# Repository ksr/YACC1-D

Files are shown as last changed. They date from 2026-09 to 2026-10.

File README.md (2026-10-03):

# YACC1-D — the definitive YACC1 tree

**Status (2026-09-28):** the single source of truth for YACC1, on GitHub at `github.com/ksr/YACC1-D`, migrated from
the old `YACCS/` folders on 2026-09-19/20. What is in the machine today: `docs/system/MACHINE.md`; which board
revisions exist and were made: `hardware/FABRICATED.md`; what is open: `BACKLOG.md`.

**Who made it:** YACC1 is my project: I designed and built the hardware and wrote the original microcode, monitor,
Tiny BASIC and emulator. Claude, Anthropic's AI, has been directly involved in the design, coding and documentation
since 2026; the header at the top of every source file says who wrote it. — Ken Rother

**Working on it:** `CLAUDE.md` (the working notes for Claude sessions) has the standing rules, the machine facts that
bite, where things are and how to build and test. On a new Mac: clone, `python3 tools/setup_check.py` (which tools are
missing, and the command for each), `make` (the C tools), then `make check`.

## What YACC1 is

YACC1 ("Yet Another Custom CPU") is a hand-built 8-bit TTL computer: an 8-bit accumulator and TMP register, eight
16-bit registers R0-R7, microcoded, on a 96-pin bus. The cards: backplane, a two-board sequencer (logic + microcode
memory), ALU, two index-register cards, memory (RAM, the 8K ROM, TMP registers), I/O (16550 UART console, switches,
LEDs, TIL311s), a 6845 video card in bring-up, and a bus tester for driving the bus by hand.

Around the hardware, all in this tree:

- **Firmware in the machine:** the microcode (a C generator that writes the sequencer's EEPROM image), the monitor
  ROM with its Intel-hex loader, BIOS vectors and video driver, and a Tiny BASIC.
- **Y1/OS:** a disk operating system on CompactFlash (P8XFS), with a shell, redirection and pipes, and some thirty-five
  `/BIN` commands, most ported from P8X, among them `vi`, `sed`, `awk`, `pack` and `kermit`. It exists twice and is kept
  in step: `os/y1os.asm` (the real one) and `os/y1os.c` (its specification).
- **y1cc**, a C compiler for YACC1: a Python reference, a C twin, and nine passes that run under Y1/OS. Together with
  the on-target assembler `/BIN/ASM` they rebuild themselves byte for byte on the emulator (the self-host).
- **Host tools:** the RC/asm assembler, an instruction-level emulator, a microcode-level emulator that steps the real
  EEPROM image through models of the cards, loaders for the ROM monitor and the sequencer card, Kermit, the CF-card
  writer, and the KiCad board tooling.

Before this tree the work was spread over nine overlapping copies under `YACCS/` (Eagle variants, four git clones with
different histories, backups). YACC1-D keeps the *current* version of every board, program, tool, test and document in
one place, with everything superseded kept but frozen. `MIGRATION.md` and `migration/` record where every file came
from.

## The tree

```
YACC1-D/
├── README.md  CLAUDE.md  BACKLOG.md  MIGRATION.md
├── Makefile                  make (the C tools), make check (everything, ~11 min), os-test, cc-test, native-test, ...
├── docs/
│   ├── system/               MACHINE.md (what is built), architecture, memory map, microcode, OS plan
│   ├── isa/                  a timing diagram per instruction, the microcode review
│   ├── cards/                theory of operation, one per card
│   ├── programming/          assembler, monitor, OS, C compiler, emulators, memory map, I/O ports
│   ├── procedures/           bring-up, CF card, testing, Kermit
│   ├── bom/                  bills of material, one per card
│   ├── history/              dated design notes kept verbatim (2016-2021), presentations
│   ├── datasheets/           third-party PDFs the designs use
│   └── references/           external papers and books
├── hardware/
│   ├── bus/                  backplane, bus template, bus jumpers, blank card
│   ├── cards/<card>/         one folder per card (below)
│   ├── libraries/            eagle/: the Eagle .lbr/.dru files the designs use
│   ├── mechanical/           card divider clips, switch template, spacers
│   ├── FABRICATED.md         every revision of every board: built, in the machine, or design only
│   ├── SCHEMATICS.md BOARDS.md   generated indexes of the schematic and board PDFs
│   ├── KICAD.md              the Eagle -> KiCad conversion and its netlist proof
│   └── DESIGN-REVIEW*.md     the 2026-09-21 review of the datapath, control and I/O
├── firmware/                 code that runs INSIDE the machine
│   ├── microcode/            ucode-generator2 (C) -> test.hex, the sequencer EEPROM image
│   ├── monitor/  basic/      monitor.asm, basic.asm (+ candidates never burned)
│   ├── rom/                  shipped/ (the image to burn and what is burned), builds/, captured chips
│   └── abi/                  BIOS vectors, variable and port map (still to be written)
├── os/                       Y1/OS: y1os.asm + y1os.c, commands/ (C), commands-asm/ (asm.asm), lib_*.c,
│                             man/, docs/, Makefile -> os/disk.img
├── software/                 host-side toolchain (runs on the Mac)
│   ├── assembler/            RC/asm + yacc1.def
│   ├── emulator/             instruction-level emulator (the ISA reference)
│   ├── ucemu/                microcode-level emulator (test.hex through models of the cards, CF, video)
│   ├── compiler/             y1cc.py, c/ (y1cc.c and the passes cc1..cc9), lib/
│   ├── disassembler/         disasm2
│   └── ubasic-c/             the C uBASIC the assembly BASIC was ported from
├── embedded/                 Arduino sketches for the support cards, built against libraries/ only
│   ├── sequencer-card/       sequencer4 (the microcode loader in the machine), dumpram, deprecated/
│   ├── bus-tester/           bus-driver, bus-monitor, bus-test, led-switch-test
│   ├── clocker/              external single-step clock
│   ├── command-sender/       Processing host for bus-tester scripts (to be replaced by Python)
│   └── libraries/            vendored: YACC_Common_header.h (bus table), Adafruit_MCP23017 1.1.0
├── tools/                    host scripts: setup_check, verify_firmware/embedded, ucode_send, monload, cfcard,
│                             y1kermit, p8xfs, the KiCad/Eagle tooling, the tree audit
├── tests/                    os, compiler, native (self-host), asm, disasm, bench (the machine), monload, kermit,
│                             cfcard, video, sequencer, ucemu, memory, assembler, bus-tester-scripts
├── mk/                       shared make fragments
├── migration/                the 2026-09-19/20 migration's inventory, plan and logs
├── vm/                       manifests of VMs and legacy installers (the images live outside git)
├── media/                    photos of the boards
├── website/                  the project website: MkDocs over these docs (website/README.md), live at yacc1.cottageworker.com
└── archive/                  frozen, never edited: gen1-2015-2018 (the first YACC1), superseded-revisions,
                              eagle-projects, third-party, conflict-losers (older duplicates from the migration)
```

## Card folder layout (`hardware/cards/<card>/`)

```
<card>/
├── README.md        what the card is, current revision, what is built, open issues
├── kicad/<rev>/     KiCad 10 projects, GENERATED from the Eagle files by tools/eagle_to_kicad_all.py with a
│                    schematic-vs-board netlist proof (hardware/KICAD.md) - except where a MASTER marker says the
│                    KiCad project is hand-maintained and IS the design (memory v2.0, CF v1.0, video v1.1);
│                    those have a build.sh (route with Freerouting, DRC, gerbers, renders, BOM)
├── eagle/<rev>/     the Eagle originals, frozen; the active revision at the top, fab/ (what was sent to the board
│                    house), pdf/ (generated), bom/
│   └── deprecated/  every older revision, same shape
└── docs/            card-specific notes
```

| Card | In the machine | Designed, not built |
|---|---|---|
| backplane | V2.0 (8 slots) | |
| sequencer-logic | v2.1 | v2.2 "CPU off" switch (idea, BACKLOG) |
| sequencer-memory | V2.1 + EEPROM adaptor | |
| alu | V3.2 | |
| register (index registers) | 1.1, two cards (R0-R3, R4-R7) | |
| io | V1.1 | |
| memory | v1.3 | **v2.0**: v1.3 + the CompactFlash interface on P8/P9, finished for fabrication |
| video | V1.0, no 6845 fitted yet | **v1.1** (KiCad master), changes still to make before ordering |
| cf | | v1.0, a separate CF card, superseded by memory v2.0 |
| bus-tester | V1.1 (2016; a bench tool) | V3.1 (2020, never ordered) |
| mem-switch, mem-register | bring-up cards (switch ROM at $0000, 16-byte RAM at $0010), fitted when needed | |
| protocard, address-tmp | built (address-tmp retired) | |

Bus items live under `hardware/bus/`: backplane, bus-template V3.2, bus jumpers (built, obsolete, not fitted), blank
card V3.1 (built) and V3.2 (the template for new cards).

## Conventions

- One authoritative copy of anything. Duplicates were the whole problem.
- Lower-case, hyphenated directory names; no spaces (the Eagle tree's spaces broke scripts repeatedly).
- Binary images (ROM, microcode hex) are committed **with** their source and a script that rebuilds them and
  diffs against the committed file; `make check` does it for all of them.
- Every file is explained: `tools/audit_tree.py` must report 0 unexplained after every commit.
- Files that came from YACCS are edited only with a dated entry in `tools/patched_files.txt`.
- Third-party code and libraries are vendored under a folder that says so, with their licence.
- Anything under `archive/` or `deprecated/` is never edited.
- Every `.rtf` note has a generated Markdown twin beside it (`tools/rtf_to_md.py`).
- No git LFS. Very large binaries (the 142 MB presentation, installers, VM images) live outside git, listed in `vm/`.

## How the migration was settled

- Repo: `~/Developer/YACC1-D` on both Macs (out of iCloud Drive, which corrupts `.git`), on GitHub, no LFS.
- History: started fresh (the first commit is the migration); the old `ksr/YACC1-2020` repo is not grafted in.
- `archive/` is committed (about 186 MB), and so are the datasheets.
- Older board revisions that were built stay with their card under `eagle/deprecated/`;
  `archive/superseded-revisions/` holds designs never built and the old tree's snapshots.
- Monitor and BASIC: the 2026 builds in `firmware/rom/shipped` are current; the 2021 `8afde21` build (ON/OFF, break-in)
  is kept as a candidate, never burned.
- Build environment: every C tool has a plain Makefile (2026-09-20); the NetBeans `nbproject/` folders are kept but
  no longer needed.

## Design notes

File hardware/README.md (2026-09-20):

# hardware

Board designs. KiCad is current; Eagle is deprecated but kept per revision.

_Contents migrated 2026-09-19; MIGRATION.md at the repo root says which copy each item came from._

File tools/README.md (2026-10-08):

# tools

Host scripts: busdrv.py (bus-tester client), alias_min.py, ROM capture/compare, inventory.py, the migration and audit tools,
the PDF generators, and the KiCad conversion:

- `eagle_to_kicad_all.py` — converts EVERY Eagle design under hardware/ into `<item>/kicad/<rev>/` KiCad 10 projects and
  writes `hardware/KICAD.md`; per design it runs the three tools in `kicad/` (`eagle_sch_to_kicad.py` schematic converter,
  `finish_board.py` board finisher on KiCad's Eagle board import, `compare_netlists.py` schematic-vs-board proof), then ERC,
  DRC, a schematic PDF and board renders into `reports/`. `kicad/project-template.kicad_pro` carries the OSH Park rules.
- `kicad/sch_overlaps.py` — readability check for any `.kicad_sch` (or a folder of them): text over text, text over a
  symbol body, text crossed by a wire/pin/graphic line, and anything off the drawing frame or on the title block, with
  the worst offenders per sheet (`--summary`, `--detail N`, `--pairs N`, `--json`; `--calibrate SVG` checks its text
  boxes against a `kicad-cli sch export svg` render). `eagle_to_kicad_all.py` puts its counts in each README and in
  `hardware/KICAD.md`.
- `verify_fab_vs_brd.py` — proves an Eagle `.brd` is the design a fab house received: every hole against the Excellon
  drill file, every Top/Bottom track against the copper gerbers, inner-layer planes, part list and pick-and-place,
  optionally byte-compares two gerber sets. Takes a gerber zip or a whole order archive (nested zips are searched).
  First used 2026-09-24 on the memory card (`hardware/cards/memory/eagle/v1.3/README.md`).
- `verify_processing.py` — builds the Processing command sender with the Processing 4 CLI and re-compiles it with warnings on.
- `gen_y1_optab.py` — generates the instruction tables of the native assemblers from `software/assembler/yacc1.def`:
  `os/asm_optab.c` for `/BIN/ASMC` (asm.c, 2026-09-25) and `os/commands-asm/asmtab.inc` for `/BIN/ASM` (asm.asm,
  2026-09-26) (`os/Makefile` runs it, `--check` fails when either is stale: `tests/asm/run.py`). It compiles each `.def` construction line with a copy of RC/asm's `Translate()`.
- `y1term.py` — a terminal for the console that can also type a text file into BASIC (2026-10-08): the plain
  terminal (`python3 tools/y1term.py`, Ctrl-] for the menu: `s` send a file, `n` NEW first, `q` quit), or
  `--send PROG.BAS [--new] [--run] [--stay]` from the command line. Each line is typed at the machine's pace
  (`--delay`, 5 ms a character) and the next one waits for BASIC's `>>`; lines answered with SYNTAX ERROR or UNKNOWN
  COMMAND are reported with their line number in the file. Blank lines and `#` lines are skipped, tabs become spaces,
  lines over 200 characters are refused (BASIC's input line is unchecked). At the monitor's `>` it starts BASIC
  with `I` first. `--log FILE` keeps everything the machine sends. Finds the console FTDI as `monload.py` does.
  Tested by `tests/y1term/run.py` against the microcode emulator through a pty.
- `y1kermit.py` — a small standard Kermit for the Mac side of the console line (2026-09-26): `send FILE...` to
  `/BIN/KERMIT`'s `kermit -r` (or its `-x` server), `receive [DIR]` from `kermit -s`, `get NAME... [DIR]`, `finish` /
  `bye` for the server, `term` (a plain terminal, Ctrl-] quits). The same protocol subset as `/BIN/KERMIT`: short
  packets, window 1, block checks 1-3 (`--check`, 3 by default), control prefixing, repeat counts (`--norpt`),
  8th-bit prefixing only when asked (`--ebq` asks), attribute packets (`--noattr`), text mode (`--text`: LF as CR
  LF). `--port` (default: the one USB serial port that is not the sequencer's FTDI; the port is opened with
  `monload.py`'s `Link`, pyserial), `--baud 38400`, `--maxl` (94), `--time` (the timeout it asks the other side to use,
  10 s), `--timeout` (its own, 20 s), `-q`. Fault injection for the tests: `--corrupt N`, `--drop N`, `--nak N`,
  `--mute N` (the Nth packet of the run damaged, not sent, NAKed, not answered). It prints what it sent and received
  and a summary (packets, retries, NAKs, timeouts, repeats); exit 1 on failure. The fallback when C-Kermit is not at
  hand, and what `tests/kermit/run.py` drives both emulators with; `docs/procedures/KERMIT.md` is the how-to.
- `y1.ksc` — C-Kermit's settings for the same line (`kermit tools/y1.ksc` opens `/dev/cu.usbserial-AB0MVHSQ` at
  38400, no flow control, carrier-watch off, binary, prefixing all, autodownload, and connects;
  `docs/procedures/KERMIT.md` explains each).

_Contents migrated 2026-09-19; MIGRATION.md at the repo root says which copy each item came from._

## Already here (written during the 2026-09 bring-up session; they existed nowhere else)

- `author_headers.py` + `authors.tsv` — the authorship header at the top of every source file (2026-10-02):
  `authors.tsv` = each file's author category (Ken / Ken + Claude's logged changes / Claude / Claude's P8X ports / RC/asm
  with Ken's port / third-party and generated: no header) and why; `--check` (in `make check`) fails on a missing or
  stale header or a source file not in the table, `--apply` writes them, `--classify` adds new files to the table.
- `setup_check.py` — is this Mac set up for YACC1-D? Reports the tools each kind of work needs (core build/tests,
  board design, Arduino sketches, the machine's USB-serial ports, C-Kermit) and how to get what is missing; installs
  nothing (2026-09-27, for the second Mac; see ../CLAUDE.md "Two Macs")
- `busdrv.py` — Python client for the Bus Test Card (19200 baud, `CMD:OPERAND#`); readmem/writemem/dump helpers
- `alias_min.py` — minimal reproduction of the video card block-0/9 write-through fault
- `inventory.py` — hashes every file under YACCS and reports what is unique where (used to build MIGRATION.md)

`../firmware/rom/eprom-captured-2026-09-18.{bin,hex}` is the 8K image read out of the memory card's
28C64 through the bus tester; it is byte-identical to `Software-vs/Assembler/rom` (git ff7d85a).

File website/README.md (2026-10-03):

# website/ — the YACC1 project website

The project website is built from this repository's own documents with [MkDocs](https://www.mkdocs.org/) and the
[Material](https://squidfunk.github.io/mkdocs-material/) theme. The documents stay where they are; the site is
a readable view of them, with navigation and search.

| File | What |
|---|---|
| `home.md` | the visitor home page (the site's index) |
| `stage.py` | copies the documents the site uses into `stage/`, keeping their repository paths so the links between them work, and generates the extra pages |
| `hooks.py` | MkDocs hook: a link to a repository file that is not part of the site becomes a link to that file on GitHub (branch `main`) |
| `mkdocs.yml` | the site: navigation, theme, Markdown extensions |
| `mkdocs-publish.yml` | `mkdocs.yml` + the Google Analytics tag (G-X7P96DTCNE); only the published build carries it |
| `requirements.txt` | the Python packages, pinned |
| `build.sh` | stage + build (installs the packages into `venv/` on the first run, which needs the network) |

    website/build.sh            build into website/site/
    website/build.sh serve      ... and serve it at http://127.0.0.1:8765 (Ctrl-C stops it)
    website/build.sh publish    the build to publish (with Google Analytics)

`venv/`, `stage/` and `site/` are rebuilt each time and not committed. Previews leave the analytics tag out, so
looking at the site locally is not counted as a visit.

**Publishing.** `.github/workflows/website.yml` runs on every push to `main` (or by hand: Actions -> website -> Run
workflow): it builds `website/build.sh publish` on GitHub's machine, so every push proves the site builds. It deploys
to GitHub Pages only when the repository variable `PAGES_DEPLOY` is `true` (Settings -> Secrets and variables ->
Actions -> Variables) and Pages is on (Settings -> Pages -> Source: GitHub Actions); until then nothing is published.
The address will be `https://yacc1.cottageworker.com` (a CNAME record at the domain's DNS host, Gandi, and the custom domain in
Settings -> Pages); `site_url` in `mkdocs-publish.yml` already names it.

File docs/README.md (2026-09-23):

# docs

Start with `system/ARCHITECTURE.md`; `DOC-PLAN.md` says how the 2026-09-23 documents were written and what **To verify:** means in them.

| Folder | Contents |
|---|---|
| `isa/` | GENERATED timing diagram per opcode from the microcode (`make isa`, `tools/ucode_wavedrom.py`): control levels per step + bus behaviour from an assumed LS timing model; index in its README |
| `system/` | **`ARCHITECTURE.md`, `MICROCODE.md`, `BUS.md`** (2026-09-23: the machine, the control store, the backplane), `MACHINE.md` (what is fitted), `OS-PLAN.md`, the bus connector specs (`connector/`), the opcode table PDF (2023-11), index-register timing diagrams (`waveforms/`) |
| `cards/` | one theory-of-operation per card (2026-09-23): purpose, bus signals, IC-by-IC schematic walkthrough, timing and review findings, jumpers, bring-up, history; index in its README |
| `programming/` | the programmer's guides (2026-09-23): ISA reference, assembler, C compiler, monitor/BIOS, Y1/OS, memory map, I/O ports, emulators, tool chain |
| `bom/` | GENERATED bills of material per board and consolidated (`make bom`, `tools/gen_bom.py`) |
| `procedures/` | `BRING-UP.md` (the bench book, 2026-09-23), `TESTING.md` (every test and what it proves), bus tester command reference (PDF), system build notes |
| `history/` | the 2021 repo front page and status, the PCB folder readme, 2017–2020 design notes, verbatim |
| `datasheets/` | third-party datasheets used by the designs (28 files, ~19 MB; committed as decided) |
| `references/` | external papers |
| `../media/` | photos of the built cards and the system |

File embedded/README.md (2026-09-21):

# embedded — Arduino / Processing code for the support cards

| Folder | Runs on | Current | Superseded (`deprecated/`) |
|---|---|---|---|
| `bus-tester/` | Bus Test Card v1.1 (ATmega328 + 4 MCP23017) | `bus-driver` (drive the bus, FTDI 19200 – the sketch `tools/busdrv.py` talks to), `bus-monitor` (listen), `bus-test`, `led-switch-test`; `bus-driver-mcp23x17-wip` = 2026-09-18 start of a port to the Adafruit MCP23X17 2.x API (2 lines) | – |
| `command-sender/` | Mac (Processing) | `command_sender_8` (2020-08-16): GUI that sends test scripts to the bus tester; scripts in `tests/bus-tester-scripts/` | `command_sender_5..7`, `old/command_sender..4` (2016-12 → 2020-07), one 2016 ideas note |
| `sequencer-card/` | Sequencer-Memory card ATmega328 | `sequencer4` (2026-09-21: 400 kHz I2C, block EEPROM reads, verified copy) = the firmware in the card; `deprecated/sequencer3` (2021-08-25 + IO.ino 2024-07-10) = what it ran before; `microcode-loader/simple_microcode_sender_64` (Processing, 115200, reads `firmware/microcode/.../test.hexz`, keeps `cache`); `dumpram`; `test-eeprom` | `sequencer1` (2020-08), `sequencer2` (2020-12), senders 1 and 2 (19200, v1 generator), the Sept-2020 EEPROM test |
| `clocker/` | a spare Arduino | `clocker.ino` – external single-step / slow clock | – |
| `libraries/` | – | VENDORED: `Adafruit_MCP23017_Arduino_Library` 1.1.0 (the 1.x API every sketch here uses), `extEEPROM` 3.4.1 (the deprecated sequencer2 only) and `YACC/YACC_Common_header.h` (the bus signal table the tester sketches include; `-pre3-2.h` = its previous version). Install both in `~/Documents/Arduino/libraries/` | – |

Build check: `tools/verify_embedded.py` compiles every sketch here with arduino-cli (Uno / ATmega328) against ONLY the
vendored `libraries/`; 12 sketches, all compile with zero sketch warnings (`--warnings all`) as of 2026-09-20 except the MCP23X17 work-in-progress, which is expected
(it needs the 2.x Adafruit library). The Processing host in `command-sender/` is checked the same way by
`tools/verify_processing.py` (Processing 4 CLI build + Eclipse-compiler warnings). Manual build: copy `libraries/*` into `~/Documents/Arduino/libraries/` and use the IDE. The sequencer sketches carry their own copy of the signal subset
(`YACC_Common_headera.h`, per generation) beside the .ino.

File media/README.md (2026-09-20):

# media

Photos of the built cards (top / solder side) and of the assembled system, 2020–2021: ALU V3.2, bus V1.0/V1.1, Index
Registers 1.1, IO 1.1, Memory v1.2, Sequencer Logic 2.1, Sequencer Memory 2.1, test board (bus tester) v1.1, `system1`,
`double bus`. Videos of the machine running are on YouTube, not in the tree.

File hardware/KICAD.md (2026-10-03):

# KiCad conversions

Generated 2026-09-23 by `tools/eagle_to_kicad_all.py`: every Eagle design under `hardware/` (active and deprecated revisions) converted to a KiCad 10 project in the matching `kicad/<rev>/` folder. The Eagle files remain the record of what was built; these projects are derived and regenerated from scratch by the tool. **Proof** = the schematic netlist extracted by KiCad compared pad-for-pad with the netlist embedded in the imported Eagle board (`tools/kicad/compare_netlists.py`). Each project's README has the details and the residual ERC/DRC counts.

**Overlaps** = `tools/kicad/sch_overlaps.py` over all sheets: text/text + text/body + text/line collisions, and items off the drawing frame.

| Eagle design | KiCad project | Built | Proof | ERC | DRC | Overlaps | Off frame | Status |
|---|---|---|---|---|---|---|---|---|
| `bus/backplane/eagle/deprecated/v1.1/yacc2buss` | [`backplane-v1.1`](bus/backplane/kicad/deprecated/v1.1/) | yes | MATCH (87/87 nets) | - | 22 + 0 unconnected | 500 | 0 | ok |
| `bus/backplane/eagle/v2.0/yacc2buss` | [`backplane-v2.0`](bus/backplane/kicad/v2.0/) | yes | MATCH (87/87 nets) | - | 123 + 0 unconnected | 575 | 0 | ok |
| `bus/blank-card/eagle/v3.1/Blank V3.1` | [`blank-card-v3.1`](bus/blank-card/kicad/v3.1/) | yes | MATCH (3/3 nets) | 84 | 9 + 0 unconnected | 0 | 0 | ok |
| `bus/blank-card/eagle/v3.2/Blank V3.2` | [`blank-card-v3.2`](bus/blank-card/kicad/v3.2/) | no | MATCH (3/3 nets) | 84 | 9 + 0 unconnected | 0 | 0 | ok |
| `bus/bus-jumper-horizontal/eagle/deprecated/v3.0/Jumper Board V3.0` | [`bus-jumper-horizontal-v3.0`](bus/bus-jumper-horizontal/kicad/deprecated/v3.0/) | yes | MATCH (89/89 nets) | - | 28 + 0 unconnected | 0 | 0 | ok |
| `bus/bus-jumper-horizontal/eagle/v3.2/Jumper Board Horizontal V3.1` | [`bus-jumper-horizontal-v3.2`](bus/bus-jumper-horizontal/kicad/v3.2/) | yes | MATCH (89/89 nets) | - | 29 + 1 unconnected | 0 | 0 | ok |
| `bus/bus-jumper-vertical/eagle/v3.0/Jumper Board V3.0` | [`bus-jumper-vertical-v3.0`](bus/bus-jumper-vertical/kicad/v3.0/) | yes | MATCH (89/89 nets) | - | 10 + 0 unconnected | 0 | 0 | ok |
| `bus/bus-template/eagle/v3.2/Bus Template V3.2` | [`bus-template-v3.2`](bus/bus-template/kicad/v3.2/) | no | n/a (schematic only) | 182 | - | 0 | 0 | ok |
| `cards/address-tmp/eagle/deprecated/v1.0/Address and TMP V1.0` | [`address-tmp-v1.0`](cards/address-tmp/kicad/deprecated/v1.0/) | yes | MATCH (47/47 nets) | 74 | 208 + 0 unconnected | 36 | 0 | ok |
| `cards/alu/eagle/deprecated/v3.0-2layer/alu4` | [`alu-v3.0-2layer`](cards/alu/kicad/deprecated/v3.0-2layer/) | yes | MATCH (158/158 nets) | 203 | 407 + 0 unconnected | 87 | 0 | ok |
| `cards/alu/eagle/deprecated/v3.1/ALU V3.1` | [`alu-v3.1`](cards/alu/kicad/deprecated/v3.1/) | yes | MATCH (159/159 nets) | 203 | 697 + 0 unconnected | 90 | 0 | ok |
| `cards/alu/eagle/deprecated/v3.1-buried-vias/ALU V3.1` | [`alu-v3.1-buried-vias`](cards/alu/kicad/deprecated/v3.1-buried-vias/) | yes | MATCH (159/159 nets) | 203 | 697 + 0 unconnected | 90 | 0 | ok |
| `cards/alu/eagle/deprecated/v3.1-resubmit/ALU V3.1` | [`alu-v3.1-resubmit`](cards/alu/kicad/deprecated/v3.1-resubmit/) | yes | MATCH (159/159 nets) | 203 | 608 + 0 unconnected | 90 | 0 | ok |
| `cards/alu/eagle/v3.2/ALU V3.2` | [`alu-v3.2`](cards/alu/kicad/v3.2/) | yes | MATCH (162/162 nets) | 206 | 606 + 0 unconnected | 84 | 0 | ok |
| `cards/bus-tester/eagle/v1.1/tester` | [`bus-tester-v1.1`](cards/bus-tester/kicad/v1.1/) | yes | MATCH (149/149 nets) | 32 | 250 + 0 unconnected | 78 | 0 | ok |
| `cards/bus-tester/eagle/v3.1/tester` | [`bus-tester-v3.1`](cards/bus-tester/kicad/v3.1/) | no | MATCH (239/239 nets) | 123 | 494 + 0 unconnected | 96 | 0 | ok |
| `cards/io/eagle/deprecated/v1.0/IO V1.0` | [`io-v1.0`](cards/io/kicad/deprecated/v1.0/) | yes | MATCH (101/101 nets) | 130 | 359 + 0 unconnected | 94 | 0 | ok |
| `cards/io/eagle/v1.1/IO V1.1` | [`io-v1.1`](cards/io/kicad/v1.1/) | yes | MATCH (104/104 nets) | 130 | 292 + 0 unconnected | 92 | 0 | ok |
| `cards/mem-register/eagle/v1.0/Mem Register V1.0` | [`mem-register-v1.0`](cards/mem-register/kicad/v1.0/) | yes | MATCH (107/107 nets) | 179 | 299 + 0 unconnected | 171 | 0 | ok |
| `cards/mem-switch/eagle/deprecated/v1.0/Mem Switch V1.0` | [`mem-switch-v1.0`](cards/mem-switch/kicad/deprecated/v1.0/) | yes | MATCH (175/175 nets) | 98 | 209 + 0 unconnected | 20 | 0 | ok |
| `cards/mem-switch/eagle/v1.1/Mem Switch V1.1` | [`mem-switch-v1.1`](cards/mem-switch/kicad/v1.1/) | yes | MATCH (199/199 nets) | 99 | 279 + 0 unconnected | 72 | 0 | ok |
| `cards/memory/eagle/deprecated/v1.0/Memory V1.0` | [`memory-v1.0`](cards/memory/kicad/deprecated/v1.0/) | yes | MATCH (69/69 nets) | 102 | 208 + 0 unconnected | 38 | 0 | ok |
| `cards/memory/eagle/deprecated/v1.1/Memory V1.0` | [`memory-v1.1`](cards/memory/kicad/deprecated/v1.1/) | yes | MATCH (75/75 nets) | 102 | 208 + 0 unconnected | 38 | 0 | ok |
| `cards/memory/eagle/deprecated/v1.2/Memory V1.2` | [`memory-v1.2`](cards/memory/kicad/deprecated/v1.2/) | yes | MATCH (99/99 nets) | 111 | 208 + 0 unconnected | 93 | 0 | ok |
| `cards/memory/eagle/deprecated/v1.3-do-not-use/Memory V1.3` | [`memory-v1.3-do-not-use`](cards/memory/kicad/deprecated/v1.3-do-not-use/) | no | MATCH (115/115 nets) | 103 | 250 + 100 unconnected | 95 | 0 | ok |
| `cards/memory/eagle/v1.3/Memory V1.3` | [`memory-v1.3`](cards/memory/kicad/v1.3/) | yes | MATCH (116/116 nets) | 104 | 254 + 0 unconnected | 98 | 0 | ok |
| `cards/protocard/eagle/v1.0/ProtoCard-Prod-V1.0` | [`protocard-v1.0`](cards/protocard/kicad/v1.0/) | yes | MATCH (87/87 nets) | - | 268 + 0 unconnected | 21 | 0 | ok |
| `cards/register/eagle/deprecated/v1.0/Index Registers - 1.0` | [`register-v1.0`](cards/register/kicad/deprecated/v1.0/) | yes | MATCH (192/192 nets) | 163 | 212 + 0 unconnected | 110 | 0 | ok |
| `cards/register/eagle/deprecated/v1.0-no-address/Index Registers - 1.0` | [`register-v1.0-no-address`](cards/register/kicad/deprecated/v1.0-no-address/) | yes | MATCH (192/192 nets) | 163 | 212 + 0 unconnected | 110 | 0 | ok |
| `cards/register/eagle/v1.1/Index Registers - 1.1` | [`register-v1.1`](cards/register/kicad/v1.1/) | yes | MATCH (223/223 nets) | 169 | 440 + 0 unconnected | 46 | 0 | ok |
| `cards/sequencer-logic/eagle/deprecated/v2.0/Sequencer-Logic-Prod-V2.0` | [`sequencer-logic-v2.0`](cards/sequencer-logic/kicad/deprecated/v2.0/) | yes | MATCH (274/274 nets) | 128 | 720 + 0 unconnected | 78 | 0 | ok |
| `cards/sequencer-logic/eagle/v2.1/Sequencer-Logic-Prod-V2.1l` | [`sequencer-logic-v2.1`](cards/sequencer-logic/kicad/v2.1/) | yes | MATCH (282/282 nets) | 121 | 712 + 0 unconnected | 86 | 0 | ok |
| `cards/sequencer-logic/eagle/v2.1/orig size/Sequencer-Logic-Prod-V2.1` | [`sequencer-logic-v2.1-orig-size-sequencer-logic-prod-v2.1`](cards/sequencer-logic/kicad/v2.1/orig-size/sequencer-logic-prod-v2.1/) | no | MATCH (282/282 nets) | 121 | 772 + 4 unconnected | 86 | 0 | ok |
| `cards/sequencer-logic/eagle/v2.1/orig size/Sequencer-Logic-Prod-V2.1 copy` | [`sequencer-logic-v2.1-orig-size-sequencer-logic-prod-v2.1-copy`](cards/sequencer-logic/kicad/v2.1/orig-size/sequencer-logic-prod-v2.1-copy/) | no | n/a (schematic only) | 358 | - | 88 | 0 | ok |
| `cards/sequencer-memory/accessories/eeprom-adaptor/eeprom adaptor` | [`sequencer-memory-eeprom-adaptor`](cards/sequencer-memory/accessories/eeprom-adaptor/kicad/) | yes | MATCH (5/5 nets) | 3 | 16 + 0 unconnected | 0 | 0 | ok |
| `cards/sequencer-memory/eagle/deprecated/v2.0/Sequencer-Memory-V2.0` | [`sequencer-memory-v2.0`](cards/sequencer-memory/kicad/deprecated/v2.0/) | yes | MATCH (105/105 nets) | 13 | 497 + 0 unconnected | 30 | 0 | ok |
| `cards/sequencer-memory/eagle/v2.1/Sequencer-Memory-V2.1` | [`sequencer-memory-v2.1`](cards/sequencer-memory/kicad/v2.1/) | yes | MATCH (106/106 nets) | 11 | 461 + 0 unconnected | 28 | 0 | ok |
| `cards/video/eagle/v1.0-fusion-export-2026-09-18/Video_1.0` | [`video-v1.0-fusion-export-2026-09-18`](cards/video/kicad/v1.0-fusion-export-2026-09-18/) | yes | MISMATCH (115/117 nets) | 122 | 229 + 0 unconnected | 25 | 0 | ok |

**Label styles in the converted schematics** (reviewed 2026-09-23 and kept): a boxed global label marks a net the card also uses on another sheet (only global labels connect across KiCad sheets); plain text on a wire marks a net that appears on that sheet only, e.g. a bus signal the card does not use, drawn from the connector pin to the bus. Eagle drew both the same way, since its labels connect across sheets by name.

## Hand-maintained masters (not generated; `MASTER` marker file)

- [`cards/cf/kicad/v1.0`](cards/cf/kicad/v1.0/) — see its README (not ordered; its circuit is the CF section of `cards/memory/kicad/v2.0`)
- [`cards/memory/kicad/v2.0`](cards/memory/kicad/v2.0/) — see its README (the built memory v1.3 + the CF interface on P8/P9; schematic proven; whole card re-laid (2026-09-24); **the v2.0 board `memory-v2.0.kicad_pcb` = standoff option E (chosen 2026-09-25): the HX-2118P CF adapter on two 15 mm M3 standoffs (H1/H2, 3.2 mm NPTH) over the CF chips, J2 parallel to X1, a short ribbon; routed 0 unrouted / 69 through vias, DRC 0 copper violations / 0 unconnected, netlist proof MATCH, silkscreen tidied, fab files (gerbers + NPTH/PTH drill zip, renders, placement PDF, BOM with hardware, JLCPCB note, 1:1 print); NOT ORDERED**; records: the standoff options A-E, the top-edge board in `options-top-edge-J2/`, the keep-copper options; C20-C23 removed: 70 parts)
- [`cards/video/kicad/v1.1`](cards/video/kicad/v1.1/) — see its README

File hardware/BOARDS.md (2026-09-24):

# Board PDFs

Generated 2026-09-24 by `tools/brd_to_pdf.py` from every Eagle `.brd` under `hardware/` (active and deprecated), imported with KiCad's Eagle board reader and plotted one page per layer: F.Cu, inner layers (4-layer boards), B.Cu, F.SilkS, B.SilkS, each with the board outline. Bottom pages are NOT mirrored (viewed from the top, as in Eagle). Derived files: re-run after any `.brd` change.

| Board | PDF | Notes |
|---|---|---|
| `bus/backplane/eagle/deprecated/v1.1/yacc2buss.brd` | [`yacc2buss-board.pdf`](bus/backplane/eagle/deprecated/v1.1/pdf/yacc2buss-board.pdf) |  |
| `bus/backplane/eagle/v2.0/yacc2buss.brd` | [`yacc2buss-board.pdf`](bus/backplane/eagle/v2.0/pdf/yacc2buss-board.pdf) |  |
| `bus/blank-card/eagle/v3.1/Blank V3.1.brd` | [`Blank V3.1-board.pdf`](bus/blank-card/eagle/v3.1/pdf/Blank V3.1-board.pdf) |  |
| `bus/blank-card/eagle/v3.2/Blank V3.2.brd` | [`Blank V3.2-board.pdf`](bus/blank-card/eagle/v3.2/pdf/Blank V3.2-board.pdf) |  |
| `bus/bus-jumper-horizontal/eagle/deprecated/v3.0/Jumper Board V3.0.brd` | [`Jumper Board V3.0-board.pdf`](bus/bus-jumper-horizontal/eagle/deprecated/v3.0/pdf/Jumper Board V3.0-board.pdf) |  |
| `bus/bus-jumper-horizontal/eagle/v3.2/Jumper Board Horizontal V3.1.brd` | [`Jumper Board Horizontal V3.1-board.pdf`](bus/bus-jumper-horizontal/eagle/v3.2/pdf/Jumper Board Horizontal V3.1-board.pdf) |  |
| `bus/bus-jumper-vertical/eagle/v3.0/Jumper Board V3.0.brd` | [`Jumper Board V3.0-board.pdf`](bus/bus-jumper-vertical/eagle/v3.0/pdf/Jumper Board V3.0-board.pdf) |  |
| `cards/address-tmp/eagle/deprecated/v1.0/Address and TMP V1.0.brd` | [`Address and TMP V1.0-board.pdf`](cards/address-tmp/eagle/deprecated/v1.0/pdf/Address and TMP V1.0-board.pdf) |  |
| `cards/alu/eagle/deprecated/v3.0-2layer/alu4.brd` | [`alu4-board.pdf`](cards/alu/eagle/deprecated/v3.0-2layer/pdf/alu4-board.pdf) |  |
| `cards/alu/eagle/deprecated/v3.1-buried-vias/ALU V3.1.brd` | [`ALU V3.1-board.pdf`](cards/alu/eagle/deprecated/v3.1-buried-vias/pdf/ALU V3.1-board.pdf) |  |
| `cards/alu/eagle/deprecated/v3.1-resubmit/ALU V3.1.brd` | [`ALU V3.1-board.pdf`](cards/alu/eagle/deprecated/v3.1-resubmit/pdf/ALU V3.1-board.pdf) |  |
| `cards/alu/eagle/deprecated/v3.1/ALU V3.1.brd` | [`ALU V3.1-board.pdf`](cards/alu/eagle/deprecated/v3.1/pdf/ALU V3.1-board.pdf) |  |
| `cards/alu/eagle/v3.2/ALU V3.2.brd` | [`ALU V3.2-board.pdf`](cards/alu/eagle/v3.2/pdf/ALU V3.2-board.pdf) |  |
| `cards/bus-tester/eagle/v1.1/tester.brd` | [`tester-board.pdf`](cards/bus-tester/eagle/v1.1/pdf/tester-board.pdf) |  |
| `cards/bus-tester/eagle/v3.1/tester.brd` | [`tester-board.pdf`](cards/bus-tester/eagle/v3.1/pdf/tester-board.pdf) |  |
| `cards/io/eagle/deprecated/v1.0/IO V1.0.brd` | [`IO V1.0-board.pdf`](cards/io/eagle/deprecated/v1.0/pdf/IO V1.0-board.pdf) |  |
| `cards/io/eagle/v1.1/IO V1.1.brd` | [`IO V1.1-board.pdf`](cards/io/eagle/v1.1/pdf/IO V1.1-board.pdf) |  |
| `cards/mem-register/eagle/v1.0/Mem Register V1.0.brd` | [`Mem Register V1.0-board.pdf`](cards/mem-register/eagle/v1.0/pdf/Mem Register V1.0-board.pdf) |  |
| `cards/mem-switch/eagle/deprecated/v1.0/Mem Switch V1.0.brd` | [`Mem Switch V1.0-board.pdf`](cards/mem-switch/eagle/deprecated/v1.0/pdf/Mem Switch V1.0-board.pdf) |  |
| `cards/mem-switch/eagle/v1.1/Mem Switch V1.1.brd` | [`Mem Switch V1.1-board.pdf`](cards/mem-switch/eagle/v1.1/pdf/Mem Switch V1.1-board.pdf) |  |
| `cards/memory/eagle/deprecated/v1.0/Memory V1.0.brd` | [`Memory V1.0-board.pdf`](cards/memory/eagle/deprecated/v1.0/pdf/Memory V1.0-board.pdf) |  |
| `cards/memory/eagle/deprecated/v1.1/Memory V1.0.brd` | [`Memory V1.0-board.pdf`](cards/memory/eagle/deprecated/v1.1/pdf/Memory V1.0-board.pdf) |  |
| `cards/memory/eagle/deprecated/v1.2/Memory V1.2.brd` | [`Memory V1.2-board.pdf`](cards/memory/eagle/deprecated/v1.2/pdf/Memory V1.2-board.pdf) |  |
| `cards/memory/eagle/deprecated/v1.2/Memory V1.2.brd.old.brd` | [`Memory V1.2.brd.old-board.pdf`](cards/memory/eagle/deprecated/v1.2/pdf/Memory V1.2.brd.old-board.pdf) |  |
| `cards/memory/eagle/deprecated/v1.3-do-not-use/Memory V1.3.brd` | [`Memory V1.3-board.pdf`](cards/memory/eagle/deprecated/v1.3-do-not-use/pdf/Memory V1.3-board.pdf) |  |
| `cards/memory/eagle/v1.3/Memory V1.3.brd` | [`Memory V1.3-board.pdf`](cards/memory/eagle/v1.3/pdf/Memory V1.3-board.pdf) | 4 layers, 53 parts, 1377 track segments |
| `cards/protocard/eagle/v1.0/ProtoCard-Prod-V1.0.brd` | [`ProtoCard-Prod-V1.0-board.pdf`](cards/protocard/eagle/v1.0/pdf/ProtoCard-Prod-V1.0-board.pdf) |  |
| `cards/register/eagle/deprecated/v1.0-no-address/Index Registers - 1.0.brd` | [`Index Registers - 1.0-board.pdf`](cards/register/eagle/deprecated/v1.0-no-address/pdf/Index Registers - 1.0-board.pdf) |  |
| `cards/register/eagle/deprecated/v1.0/Index Registers - 1.0.brd` | [`Index Registers - 1.0-board.pdf`](cards/register/eagle/deprecated/v1.0/pdf/Index Registers - 1.0-board.pdf) |  |
| `cards/register/eagle/v1.1/Index Registers - 1.1.brd` | [`Index Registers - 1.1-board.pdf`](cards/register/eagle/v1.1/pdf/Index Registers - 1.1-board.pdf) |  |
| `cards/sequencer-logic/eagle/deprecated/v2.0/Sequencer-Logic-Prod-V2.0.brd` | [`Sequencer-Logic-Prod-V2.0-board.pdf`](cards/sequencer-logic/eagle/deprecated/v2.0/pdf/Sequencer-Logic-Prod-V2.0-board.pdf) |  |
| `cards/sequencer-logic/eagle/v2.1/Sequencer-Logic-Prod-V2.1l.brd` | [`Sequencer-Logic-Prod-V2.1l-board.pdf`](cards/sequencer-logic/eagle/v2.1/pdf/Sequencer-Logic-Prod-V2.1l-board.pdf) |  |
| `cards/sequencer-logic/eagle/v2.1/orig size/Sequencer-Logic-Prod-V2.1.brd` | [`Sequencer-Logic-Prod-V2.1-board.pdf`](cards/sequencer-logic/eagle/v2.1/orig size/pdf/Sequencer-Logic-Prod-V2.1-board.pdf) |  |
| `cards/sequencer-memory/accessories/eeprom-adaptor/eeprom adaptor.brd` | [`eeprom adaptor-board.pdf`](cards/sequencer-memory/accessories/eeprom-adaptor/pdf/eeprom adaptor-board.pdf) |  |
| `cards/sequencer-memory/eagle/deprecated/v2.0/Sequencer-Memory-V2.0.brd` | [`Sequencer-Memory-V2.0-board.pdf`](cards/sequencer-memory/eagle/deprecated/v2.0/pdf/Sequencer-Memory-V2.0-board.pdf) |  |
| `cards/sequencer-memory/eagle/v2.1/Sequencer-Memory-V2.1.brd` | [`Sequencer-Memory-V2.1-board.pdf`](cards/sequencer-memory/eagle/v2.1/pdf/Sequencer-Memory-V2.1-board.pdf) |  |
| `cards/video/eagle/v1.0-fusion-export-2026-09-18/Video_1.0.brd` | [`Video_1.0-board.pdf`](cards/video/eagle/v1.0-fusion-export-2026-09-18/pdf/Video_1.0-board.pdf) |  |

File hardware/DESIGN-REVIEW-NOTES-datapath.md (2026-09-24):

# Design review, datapath cards (control-path pass) — 2026-09-21

Second pass after `DESIGN-REVIEW.md` (mechanical). Cards: ALU v3.2, Index Register 1.1, Memory v1.3, Mem Switch 1.1,
Mem Register 1.0. Method: every select / enable / strobe / clock / reset net was traced pin-to-pin from
`kicad/<ver>/reports/netlist.net` (pin names and types from the Eagle symbols) with chip types from the Eagle `.brd`,
and checked against the way the sequencer microcode actually drives the bus (`firmware/microcode/ucode-generator2/`),
because several hardware choices only work under a microcode convention. Signal polarity: `-` prefix = active low.
Gate delays quoted are LS-TTL typicals from the datasheets in `docs/datasheets/`.

Severity: HIGH = would stop the card working or damage parts; MED = unreliable / depends on a convention that is not
enforced by hardware; LOW = housekeeping or documentation.

---

## Memory card v1.3 (traced on `hardware/cards/memory/kicad/deprecated/v1.3-do-not-use/`, then filed as `kicad/v1.3`)

> **Note 2026-09-24:** this review traced what was then `kicad/v1.3` (now `kicad/deprecated/v1.3-do-not-use/`), which is an
> **earlier save** of the design, not the card that was fabricated (`hardware/cards/memory/eagle/v1.3/`, KiCad `kicad/v1.3/`;
> filed first as `v1.3-fusion-export-2026-09-24`).
> The one circuit difference: on the built card IC5's enable (pin 19) is IC15 pin 12 = AND(-LO-RAM, -HI-RAM, -ROM-CS),
> not `-VMA`, so where the findings below say "IC5 enable" read "the chip selects, through IC15". The findings
> themselves (M1-M8) are unchanged by that: every pin they name is wired the same on the built card.

### M1 — HIGH (masked by a microcode hack): FORCE-ROM clears on any -VMA cycle that starts with the address bus floating

Trace of the FORCE-ROM flip-flop clock:

- IC12A (74LS74): PRE(4) = `-RESET` (X1.C30), CLR(1) = VCC, D(2) = GND, Q(5) = `FORCE-ROM`, CLK(3) = `N$19`.
- `N$19` = IC10.8 (74ALS00) = NOT(`N$20`); `N$20` = IC10.6 = NAND(`ADDR15` [X1.A18, raw bus line into IC10.4], `N$22`);
  `N$22` = IC10.11 = NOT(`N$25`); `N$25` = IC3.3 (74LS32) = `-VMA` OR `-BUS-EN`.
  So CLK = ADDR15 AND VMA AND BUS-EN, three gate delays (~35 ns) after `-VMA` falls.
- The address is only driven onto the bus while `-VMA` is low: on the register card IC40.3 (74LS32) = `-BUS-EN` OR `-VMA`
  enables IC38 (74LS139, second half, pin 15) -> J3 -> IC38 first half (pin 1) -> `-Rx-ADDRSEL` -> IC41/42 (74LS244)
  output enables. That is ~75 ns typical (LS32 + two LS139 stages + 244 enable) before ADDR15 is driven.
- Between memory cycles nothing drives ADDR0-15 (no pull-ups or pull-downs on the backplane: `bus/backplane` v2.0
  contains only connectors and capacitors) and the memory card's LS inputs on ADDR15 (IC10.4, IC9.17) float high.

Failure scenario: on the first `-VMA` after reset, ADDR15 reads 1 (floating) for the ~40 ns before the register card
drives it low, so `N$19` produces a ~40 ns positive pulse (LS74 needs 25 ns) and clocks D=0 into IC12A: FORCE-ROM is
cleared on the very first fetch regardless of the address, and the CPU fetches from uninitialised low RAM instead of
the ROM. The bus-tester check of 2026-09-18 passed because the tester drives the address statically before it lowers
`-VMA`.

The designer met this: `ucode-generator2/main.c:102` and `:115` (`setSignal("-VMA"); // Hack prevent ROM mapping from
triggering`) assert `-VMA` in **every** microcode line with ADDR-REG-ID defaulting to PC, so the address bus never
floats while the machine runs. The hack works, but it removes the `-VMA` qualification from every chip select on this
card (the whole point of the v1.2 changes: IC7 G2A, IC10 `-LO-RAM`, IC5 enable are now permanently active), keeps IC5
(74LS245) driving BDATA from the bus at all times, and the hazard returns the moment any microcode line drops `-VMA`
or the bus tester drives `-VMA` with the address lines tri-stated.

Bench: scope IC12 pin 3 against pin 5 on the first cycle after reset with the register card fitted and a microcode
image that does not hold `-VMA`; or with the bus tester leave ADDR0-15 as inputs, hold `-BUS-EN` low, pulse `-VMA`
low, and read FORCE-ROM (IC12.5): it drops.

### M2 — MED: the 28C64 EEPROM is write-enabled by every -MEM-WR, including during FORCE-ROM

- IC13 (28C64) `-WE`(27) = `N$4` = IC6.4 = NOT(IC6.8 = NOT(`-MEM-WR`)): `-MEM-WR` re-buffered, no gating, no
  write-protect jumper. `-CE`(20) = `-ROM-CS` = IC6.12 = NOT(IC18.8), IC18 (74ALS30) fed by the ROM row of the U$1
  block jumpers (pull-ups RN7).
- While FORCE-ROM = 1, IC11 (74LS157, select pin 1 = FORCE-ROM, B inputs = VCC) forces BADDR12-15 = 1111, so **every**
  address selects block $F (IC7 Y7 -> jumper -> IC18 -> `-ROM-CS`).

Failure scenario: a write to any address while FORCE-ROM is still set (e.g. boot code initialising a RAM variable
before its first jump above $8000), or any later stray write into $E000-$FFFF, writes the EEPROM. A 28C64 then spends
~10 ms in an internal write cycle during which reads return the toggle/poll bits, so code executing from the ROM
crashes and the image is corrupted. The shipped monitor is safe by construction (`firmware/monitor/monitor.asm:58-61`:
first instruction at $F000 is `BR eprom` to $F003, which clears FORCE-ROM before any store), but nothing in hardware
enforces that.

Bench: with the bus tester, reset, write a byte to $0010 with `-MEM-WR`, then read $F010 through the ROM: it changed
(use a scratch EEPROM). With a meter, `-WE` on IC13.27 follows bus pin B24 one-for-one.

### M3 — MED: TMP registers latch on the leading edge of -TMP-REG-LDn; correct only under a microcode ordering rule

- IC26/IC27 (74LS374) CLK(11) = `N$33` = IC14.2 = NOT(`-TMP-REG-LD0`); IC28/IC29 CLK = `N$47` = IC14.12 =
  NOT(`-TMP-REG-LD1`). A 374 clocks on the rising edge of CLK, i.e. ~10 ns after the **falling** (leading) edge of the
  bus strobe, so whatever is on DATA0-15 at the start of the strobe is captured.
- Every register-card source needs far longer than 10 ns to appear on the bus after its own strobe (LS32 -> two LS139
  -> LS32 -> 244 enable -> CD4077 (~100 ns, see R1) -> LS32 -> 245 enable); a memory read needs ~150 ns.

The microcode compensates by asserting the data source one line before the LD strobe (`memory.c:24-28`,
`accumulator.c:343-349`, `branch.c:624-631`) — the hardware silently depends on that. `branch.c:14-22`
(`moveRegtoTmp`) asserts `-REG-FUNC-RD/-REG-RD-LO/-REG-RD-HI` and `-TMP-REG-LD0` in the same line and would latch
stale data; it currently has no callers, so the fault is latent.

Bench: bus tester: put a value on DATA, assert `-TMP-REG-LD0` low, change DATA while it is still low, release, read
back with `-TMP-REG-RD0`: the first value is returned.

### M4 — MED (configuration): low RAM cannot be removed from the map; conflicts with the bring-up cards and with FORCE-ROM

- `-LO-RAM` = IC10.3 (74ALS00) = NAND(`N$13` = NOT BADDR15 [IC14.4], `N$12` = NOT `-VMA` [IC14.10]). No jumper, no
  block decode: $0000-$7FFF is always RAM when `-VMA` is low.
- The Mem Switch card decodes $0000-$000F and the Mem Register card $0010-$001F (comparators IC4 on each, see below),
  both driving DATA0-7 on `-MEM-RD`.

Failure scenario: if the memory card is on the bus together with either bring-up card (MACHINE.md says they were
re-fitted 2026-09-21), every read of $0000-$001F has two drivers on DATA0-7: the 62256 through IC5 (74LS245, DIR =
`-MEM-RD`, G = `-VMA`) and the bring-up card's 74LS244/374 outputs. After reset it is three, because FORCE-ROM maps
the EEPROM onto $0000 as well. Bench: meter on any DATA0-7 line during a read of $0000 shows an intermediate level
(~1-2 V) if two drivers disagree.

### M5 — LOW: control inputs rely on floating-high when -BUS-EN is high

`-MEM-WR`, `-MEM-RD`, `-VMA`, `-TMP-REG-RD0/1`, `-TMP-REG-LD0/1` come from 74LS374 outputs on the sequencer whose OC
pins are `-BUS-EN` (sequencer IC7/12/14/28 pin 1), so all of them are tri-state until the sequencer-memory card
reports READY (~54 s after power-up) and whenever the bus is handed over. No card and not the backplane has a pull-up
on any of them (checked on all five cards plus io and sequencer). LS inputs float high so nothing is selected, but the
levels are undefined and the 62256/28C64 `-WE` depends on it. Bench: meter on B24 with the sequencer un-READY reads
~1.5-1.9 V, not a logic high.

### M6 — LOW: unused 74LS04 inputs left open

IC14 pins 5 and 9 have no net at all in the PCB (pads unconnected), so the mechanical pass, which looks for single-node
nets, could not see them. IC3 and IC12B unused inputs are tied off correctly.

### M7 — LOW: IC7 (74LS138) G2B needs JP1 fitted

IC7.5 = `N$24` = JP1 pin 2 only; JP1 pin 1 = `-BUS-EN`, pin 3 = GND. With no jumper the pin floats high and the whole
high-32K decode (RAM blocks and ROM) is dead. Note MACHINE.md's "jumper wire from IC7 pin 4, unconnected": pin 4 is
G2A = `-VMA`; if that wire ever replaces the track, pin 4 floats and the same symptom appears.

### M8 — LOW: DATA0-15 pull-down networks RN5/RN6 have no value in the design files

RN5/RN6 (RNX8, pin 1 = GND) are pull-downs on the bus DATA0-15. Their value is empty in both `.sch` and `.brd`. Below
~4.7 k they would exceed the LS IOH budget of every driver on the bus; MACHINE.md's observation that an undecoded read
"returns the last value left on the bus" suggests they are either high-value or not fitted. Confirm with a meter
(resistance from A19 to GND with the card out).

### Checked, no issue (memory card)

- 62256 `-OE` = `N$3` = `-MEM-RD` via two inverters; `-WE` = `-MEM-WR`; never both low; IC5 DIR = `-MEM-RD` so the
  245 receives during writes and drives during reads. Only a ~20-30 ns BDATA overlap at the end of a read (245 turns
  round before the RAM's -OE has released) — normal for LS designs.
- Write strobe ordering: `main.c:236-249` asserts ADDR-ID + `-VMA` + source in one line and `-MEM-WR` in the next, so
  address decode (IC8/9 244s, IC11 157, IC7 138, IC4/IC18 NAND8s) has a full step to settle before `-WE` falls, and the
  source is held one line after `-MEM-WR` rises: no cross-block write from decode glitches.
- Block jumpers: IC7 Y0-Y7 -> U$1 middle row; top row -> IC4 (74ALS30, pull-ups RN8) -> IC6.10 `-HI-RAM`; bottom row ->
  IC18 (pull-ups RN7) -> IC6.12 `-ROM-CS`. Unjumpered blocks are pulled inactive. ROM A12 = BADDR12 so both halves of
  the 8K are reachable when $E and $F are jumpered down.
- FORCE-ROM uses the raw ADDR15 (IC10.4) and not BADDR15, so the 157 feedback loop cannot hold it set.
- Reset polarity: IC12A PRE = `-RESET` (active low) matches the bus.
- Power-on state of FORCE-ROM is defined only by `-RESET`: see S1.

---

## Index Register card 1.1 (`hardware/cards/register/kicad/v1.1/`)

### R1 — MED: CD4077 (4000-series CMOS) driven by LS-TTL outputs, and it sits in every bus turn-around path

- IC34 is a `4077` from the Eagle `40xx` library (CD4077B-class, board value 4077N), VDD = 5 V. Its inputs:
  pin 2 = `-RESET` (sequencer IC36.6, 74LS04), pin 6 and 13 = `-LDSEL` (IC32.12/J2, 74LS139), pin 12 = `-RDSEL`
  (IC32.4/J1, 74LS139), pin 9 = `-HL-SWAP` (sequencer IC28.12, 74LS374). Other inputs are GND. No pull-ups on any of
  them (RN1/RN2 10 k are on ADATA, not here).
- A CD4077B needs VIH >= 3.5 V at 5 V; an LS output guarantees only 2.7 V (typically 3.4 V unloaded). Outputs:
  pin 3 = `RESET` (CLR of all sixteen 74LS192s), pin 4 = `BUS-DIR` (IC35/36/37 74LS245 DIR), pin 11 = `N$42` (XNOR of
  `-RDSEL`,`-LDSEL`: the 245 enable term), pin 10 = `N$41` (swap select). CD4077B propagation is ~100 ns typical,
  150+ ns max at 5 V, so it is the slowest element between a bus strobe and this card's data drivers.

Failure scenario: a register read/load that works on one card or one chip lot and not another, or a card that clears
its registers (RESET output high) when `-RESET` is only pulled to ~2.5-3 V. Bench: meter on IC34 pins 2, 6, 9, 12, 13
when the corresponding line is inactive; anything under 3.5 V is out of spec for the part. Scope pin 11 against pin 12
for the delay.

### R2 — MED: count strobe is a plain OR with the read select, so a change of REG-RD-ID while -REG-UP/-REG-DN is low counts the *deselected* register

- Per register (R0 shown; R1 = IC15, R2 = IC25, R3 = IC47 identical): IC1.3 (74LS32) `N$17` = `-R0-RDSEL` OR `-REG-UP`
  -> IC3.5 (74LS192 UP); IC1.6 `N$18` = `-R0-RDSEL` OR `-REG-DN` -> IC3.4 (DN); carries cascade IC3->IC4->IC5->IC6.
  `-R0-RDSEL` = IC33.4 (74LS139) from REG-RD-ID0-1, gated by `-RDSEL` <- J1 <- IC32 (ID2-3) gated by `N$19` = IC31.3 =
  `-BUS-EN` OR `-REG-FUNC-RD`.
- A 74LS192 counts on the rising edge of UP (DN high). `N$17` rises when **either** input rises. If `-REG-UP` is low
  and the decoder deselects R0 (ID changes, or `-REG-FUNC-RD` released first), R0 counts.

The microcode's `incrementReg()` (`main.c:203-214`) sets ID + `-REG-FUNC-RD` + `-REG-UP` in one line and clears
`-REG-UP` and `-REG-FUNC-RD` together, which yields exactly one edge — but only if `-REG-FUNC-RD` was not already
active with a different ID in the preceding line; the author's own comment at `main.c:202` ("might be an issue if
current setRdId reg is different") is this hazard. Bench: bus tester: `-BUS-EN` low, `-REG-FUNC-RD` low with ID = R1,
`-REG-UP` low, change ID to R0, release: R1 has incremented.

### R3 — LOW: same-card register-to-register moves cannot use -HL-SWAP

With both `-RDSEL` and `-LDSEL` active on one card, `N$42` = 1 disables IC35/36 and (through IC31.11 = `N$42` OR
`-HL-SWAP`) IC37, so the move goes over the internal ADATA bus with no byte-swap path. Cross-card moves swap fine.
Microcode only uses `-HL-SWAP` with memory/TMP transfers today, so this is a constraint, not a fault.

### Checked, no issue (register card)

- Bus direction (the note's open question "should it be based on -RD-SEL"): `BUS-DIR` = XNOR(GND, `-LDSEL`) = 1
  (DATA->ADATA) only when this card is load-selected, 0 (ADATA->DATA) otherwise; the 245s are enabled (`N$1` =
  `N$41` OR `N$42` low) only when exactly one of RD/LD is on this card and no swap is requested. All four cases
  (read here / load elsewhere, load here / read elsewhere, both here, neither) resolve to a single driver. The design
  as drawn is correct.
- Swap path: IC37 (DATA0-7 <-> ADATA8-15) enabled only when `-HL-SWAP` low AND `N$42` low; IC35/36 disabled then
  (`N$41` = HL-SWAP). Mutually exclusive.
- Register load: IC3/IC4 LD = `N$16` = `-R0-LDSEL` OR `-REG-LD-LO`; IC5/IC6 LD = `N$22` = `-R0-LDSEL` OR
  `-REG-LD-HI`. Level-sensitive load; the microcode (`register.c:52-60`) sets `-REG-FUNC-LD` + ID one line before the
  `-REG-LD-LO` pulse and the source one line before that, and the 245 releases (via R1's slow path) after the LD input
  has already risen (LS32 from `-REG-LD-LO`), so data is held through the load window.
- Address drive: IC38 second half (ID2-3, G = `-BUS-EN` OR `-VMA`) -> J3 -> first half (ID0-1) -> one of
  `-R0..R3-ADDRSEL` -> IC41/42, IC17/18, IC27/28, IC49/50 (74LS244). One register per bus, one card per J3 setting.
- Read enables: `N$20` = `-R0-RDSEL` OR `-REG-RD-LO` -> IC7 (low byte -> ADATA0-7); `N$21` with `-REG-RD-HI` -> IC8.
  With only one half read, the other ADATA byte is the RN1/RN2 10 k pull-ups ($FF) and is driven onto DATA by the
  other 245 — a definition, not a conflict.
- 74LS192 cascade CO->UP, BO->DN, stage n to n+1, ripple over four chips; CLR = `RESET` active high matches the
  inverted bus `-RESET`. Unused CO/BO on IC6/12/22/44 are outputs, fine.
- Both card-select headers (J1 RD, J2 LD, J3 ADDR) must be set to the same ID2-3 code on a card; the microcode uses
  the same 4-bit number for all three IDs (`main.c:145-164`).

---

## ALU v3.2 (`hardware/cards/alu/kicad/v3.2/`)

### A1 — LOW/MED: BR-COND floats when JP1 selects -ALU-FUNC as the mux enable

IC26 (74LS251) G(7) = `N$4` = JP1 pin 2; JP1 pin 1 = `-ALU-FUNC`, pin 3 = GND. Y(5) = `N$56` -> IC27.10 (74LS86)
XOR `AC-LD-INV` -> IC27.8 = `BR-COND` (X1.C24). With JP1 on `-ALU-FUNC`, `N$56` is tri-state whenever `-ALU-FUNC`
is high and has no pull-up, so BR-COND is whatever the floating LS input of IC27 reads. Harmless only if the
sequencer's branch flip-flop is set solely while `-ALU-FUNC` is asserted (Sequencer notes: "SET with and of BRTest
and BRCond"). With JP1 on GND the mux always drives. Bench: meter on C24 with `-ALU-FUNC` high and JP1 on pin 1.

### A2 — LOW: `-AC-LD-INV` doubles as the branch-condition inverter

IC27.9 = `AC-LD-INV` (IC1.2 = NOT `-AC-LD-INV`). Any microcode line that asserts `-AC-LD-INV` for an inverted
accumulator load also inverts BR-COND for that line. Only matters if the sequencer samples BR-COND then.

### A3 — LOW: brief bus overlaps on internal buses at strobe edges

- ACI-DATA: IC2 (74LS240, G = `-AC-LD-INV`) and IC3 (74LS244, G = `AC-LD-INV` from IC1.2) are complementary through
  one inverter; both drive for ~10 ns at each transition.
- BDATA on `-AC-RD` release: IC10/11 (74LS245) DIR = `-AC-RD` flips to A->B ~8 ns after release while IC12 (74LS244,
  G = `-AC-RD`) is still turning off (~20 ns), and the 245 stays enabled because `-ALU-IO-EN` = IC7.11 = `-ALU-FUNC`
  OR `-BUS-EN` and `-ALU-FUNC` is not released in the same line (`accumulator.c:350`). Tens of ns, LS-tolerated.

### Checked, no issue (ALU)

- Accumulator IC5 (74LS374) CLK = `AC-LD` = NOT `-AC-LD` (IC1.12): latches on the leading edge; microcode sets the
  function one line earlier (`accumulator.c:14-22`). OC = GND: ACO-DATA always valid.
- Carry flip-flop IC9A: D = `N$7` = IC7.3 = `CO/BO` OR `SHIFT-OUT`; CLK = `N$5` = IC6.8 = AND(`N$3`, `N$9`);
  `N$3` = IC4.3 = NAND(`-ADD/SUB`, `-SHIFT`) (= "function is add, sub or shift"); `N$9` = JP2 pin 2 = `AC-LD` per the
  note "should be ac-ld". The clock is gated by decoder outputs that are stable during the `-AC-LD` pulse (ALU code
  is set a line earlier), so no glitch; logic ops preserve carry as intended. CLR = `-RESET`, polarity correct.
- `CO/BO` = IC1.10 = NOT(IC4.6 = NAND(`N$15` = ADD/SUB, `N$10` = IC27.6 = `N$1` (IC36 C4) XOR `SUB`)): carry for add,
  borrow for subtract, only during add/sub — matches the v3.2 note.
- Carry-in IC35 C0(7) = `N$2` = IC27.3 = (`ALU3` AND `C/SHIFT`) XOR `SUB`: plain SUB gets +1 (two's complement with
  IC33/34 XOR array on BDATA), ADC/SBC (ALU3=1) take the flag with the right sense.
- IC24/IC25 (74LS85) cascade: IC24 pin 2 = GND, pin 3 = VCC, pin 4 = GND — correct LSB-stage seeding; A = BDATA,
  B = ACO; outputs to mux D1-D3.
- IC8 (74LS138) is permanently enabled (G1 = VCC, G2A/B = GND); the eight function 244s (IC13/16/17/20/23/31/37) are
  mutually exclusive by construction and only feed the internal INV-IN bus.
- Shift register IC29/30 (74LS194): S0/S1 = ALU0/1, CLK = `SR-LD` (leading edge of `-SR-LD`); IC9B (`SHIFT-OUT`)
  D = IC32.7 (mux of SRD0/SRD7 by ALU0-1) is clocked on the same edge and samples the pre-shift bit. Fine.
- V1/V2 (M74HC4078): pin 13 is the NOR output (datasheet `744078.pdf`: "all inputs L -> X(13) = H"), so `N$6` / `N$52`
  = "byte is zero"; `N$55` = both zero. Matches ALUZ (4) and ALU16Z (6) in `CodeGen.h`.
- Bus transceivers enabled only with `-ALU-FUNC` low: the microcode pairs `-AC-RD` with `-ALU-FUNC` everywhere it
  drives the accumulator onto the bus (`accumulator.c:343`, `:377`, `:513`; `putBustoRegMem(reg,"-AC-RD")` callers
  are inside blocks that already hold `-ALU-FUNC`). During `-AC-RD`, DATA8-15 carry $FF from RN2 (10 k pull-ups on
  BDATA8-15) through IC11 — a definition, not a conflict.
- `-VMA`, `-HL-SWAP` are connector-only nets on this card (unused), as the note says.

---

## Mem Switch 1.1 (`hardware/cards/mem-switch/kicad/v1.1/`) and Mem Register 1.0 (`hardware/cards/mem-register/kicad/v1.0/`)

### B1 — MED (configuration): both cards, and low RAM, overlap — see M4

Mem Switch decodes $0000-$000F and Mem Register $0010-$001F (SW1 sets ADDR4-7 against IC4 74LS85 with RN1 pull-ups;
IC4 A=B_I(3) = V1 (M74HC4078) pin 13 = NOR(ADDR8-15), so only page 0). Neither can coexist with the memory card's
undisableable low RAM.

### B2 — LOW: Mem Switch design files fit 74LS244, the notes say 74240

`Notes.md` for 1.1 lists "Change to 74240 (inverted output)" and the README repeats it, but the v1.1 schematic/board
show IC5-IC20 = 74LS244N with the switches pulling to GND against RN2-RN17 pull-ups (switch closed = 0). If 74LS240s
were ever fitted, every switch bit reads inverted. Document whichever is true.

### Checked, no issue (bring-up cards)

- Read qualification: IC1 (74ALS27) `N$19` = NOR(`-VMA`, `-BUS-EN`, `-MEM-RD`), `N$82` = NOT `N$19` -> IC2/IC3
  (74LS138) G2A; IC2 G2B = ADDR3, IC3 G2B = NOT ADDR3 (IC1.6); G1 = comparator match. Exactly one of SW0-15 / RD0-15
  low per read; each enables one 74LS244 (switch card) or one 74LS374 OC (register card) onto DATA0-7. DATA8-15 are
  not driven.
- Write (Mem Register): IC7 (74ALS27) `N$2` = NOR(`-VMA`, `-BUS-EN`, `-MEM-WR`), `N$4` = NOT `N$2` -> IC5/IC6 138 G2A;
  WRn -> 374 CLK. The 374 loads on the **rising** edge of WRn, i.e. at the end of the strobe (trailing edge); the
  microcode holds the source one line after `-MEM-WR` rises (`main.c:243-247`) and the address is stable a line before,
  so the decoder cannot produce a second rising edge on another WRn during the write.
- No reset inputs on either card; nothing to mismatch.

---

## System-level items found while tracing (not on the five cards, recorded so they are not lost)

### S1 — MED: no power-on reset anywhere; `-RESET` is a manual RS latch

Sequencer-logic v2.1: `RESET` = IC32.4 (74ALS02) = NOR(`FP-RESET` [switch RESET0 via R7], `RUN`); `RUN` = IC32.1 =
NOR(`RESET`, `FP-EXECUTE`); `-RESET` = IC36.6 (74LS04) = NOT `RESET`. There is no RC or supervisor. At power-up the
latch settles arbitrarily, so until the button is pressed the memory card's FORCE-ROM (IC12A PRE), all sixteen
74LS192 register counters (CLR = RESET), and the ALU carry/shift flip-flops (IC9 CLR) are undefined. Bench: meter on
C30 after a cold power-up, before touching the front panel.

### S2 — LOW: reset polarity is consistent across cards

Bus `-RESET` (active low, totem-pole from IC36.6): memory IC12A PRE (active low), ALU IC9 CLR (active low), register
IC34 XNOR(GND, `-RESET`) -> active-high CLR of the 192s. No mismatch.

### S3 — LOW: control-line idle state is "floating" bus-wide

See M5. Every control line on rows B/C is a 374 output with OC = `-BUS-EN`; no card and not the backplane pulls them.
The memory card is the one that could lose data from it (M2, M5).

---

## Summary

| ID | Card | Sev | One line |
|---|---|---|---|
| M1 | Memory | HIGH (masked) | FORCE-ROM clock = ADDR15 AND VMA races the register card's address drivers; clears on the first cycle whenever the address bus floats. Hidden today by the microcode holding `-VMA` in every line, which also disables all `-VMA` gating of the chip selects. |
| M2 | Memory | MED | 28C64 `-WE` = `-MEM-WR`, unprotected; during FORCE-ROM every address selects the ROM block, so a boot-time store writes the EEPROM. Shipped monitor avoids it (`BR` first). |
| M3 | Memory | MED | TMP registers latch on the leading edge of `-TMP-REG-LDn`; depends on the microcode's source-one-line-early convention; `moveRegtoTmp` breaks it (unused). |
| M4/B1 | Memory + bring-up | MED (config) | Low RAM ($0000-$7FFF) cannot be jumpered out; with a bring-up card fitted (or FORCE-ROM after reset) two or three drivers on DATA0-7 at $0000. |
| R1 | Register | MED | CD4077 CMOS thresholds (VIH 3.5 V) on LS-driven `-RESET`, `-RDSEL`, `-LDSEL`, `-HL-SWAP`; ~100 ns in the 245 enable/direction path. |
| R2 | Register | MED | UP/DN = OR(select, `-REG-UP`): deselecting while `-REG-UP` is low counts the deselected register; safe only under the microcode ordering the author flagged. |
| S1 | Sequencer | MED | No power-on reset; FORCE-ROM, registers, carry undefined until the button. |
| A1 | ALU | LOW/MED | BR-COND floats when JP1 = `-ALU-FUNC` and `-ALU-FUNC` is high. |
| M5/S3 | Memory | LOW | All bus control inputs float (374 OC = `-BUS-EN`) before READY / on handover; no pull-ups anywhere. |
| M6, M7, M8, R3, A2, A3, B2 | various | LOW | Open LS04 inputs; JP1 must be fitted; RN5/RN6 value unknown; no same-card swap; `-AC-LD-INV` also flips BR-COND; ns-scale internal overlaps; 244 vs 240 documentation. |

Checked and clean: memory write-strobe ordering and 62256 -OE/-WE relation, block-jumper decode, FORCE-ROM uses raw
ADDR15; register-card bus direction (the 1.2 open question is answered: correct as drawn), swap path exclusivity, load
timing, address drive, 192 cascade; ALU accumulator/carry/borrow/carry-in logic, comparator cascade seeding, shift
register and shift-out, 4078 output polarity, transceiver enables; bring-up cards' read/write qualification and decode.

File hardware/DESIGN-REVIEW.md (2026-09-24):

# Design review (mechanical pass) — 2026-09-21

Generated by `tools/design_review.py` from each active card's KiCad netlist (pin types come from the Eagle symbols, so a
wrongly typed symbol pin can produce a false hit; every HIGH item was checked by hand before being acted on).
Severity: HIGH = would stop the card working or damage parts; MED = unreliable; LOW = housekeeping.

## bus/backplane/kicad/v2.0

20 parts, 87 nets, 1 ICs, 86 bus-connector nets, rails 5V, GND

- **LOW** decoupling: 0 100 nF-class caps for 1 ICs

## bus/blank-card/kicad/v3.1

3 parts, 87 nets, 0 ICs, 86 bus-connector nets, rails GND, VCC

- no findings

## bus/blank-card/kicad/v3.2

3 parts, 87 nets, 0 ICs, 86 bus-connector nets, rails GND, VCC

- no findings

## bus/bus-jumper-horizontal/kicad/v3.2

7 parts, 89 nets, 0 ICs, 0 bus-connector nets, rails GND

- no findings

## bus/bus-jumper-vertical/kicad/v3.0

7 parts, 89 nets, 0 ICs, 0 bus-connector nets, rails GND

- no findings

## bus/bus-template/kicad/v3.2

3 parts, 87 nets, 0 ICs, 86 bus-connector nets, rails GND, VCC

- no findings

## cards/alu/kicad/v3.2

86 parts, 228 nets, 37 ICs, 86 bus-connector nets, rails GND, VCC

- no findings

## cards/bus-tester/kicad/v1.1

86 parts, 175 nets, 10 ICs, 86 bus-connector nets, rails GND, VCC

- no findings

## cards/bus-tester/kicad/v3.1

110 parts, 265 nets, 21 ICs, 86 bus-connector nets, rails GND, VCC

- no findings

## cards/io/kicad/v1.1

71 parts, 195 nets, 19 ICs, 86 bus-connector nets, rails GND, VCC

- **MED** floating input pins (single-node nets): IC1: 17(XTAL2_17)

## cards/mem-register/kicad/v1.0

90 parts, 166 nets, 23 ICs, 86 bus-connector nets, rails GND, VCC

- no findings

## cards/mem-switch/kicad/v1.1

112 parts, 259 nets, 36 ICs, 86 bus-connector nets, rails GND, VCC

- no findings

## cards/memory/kicad/v1.3

53 parts, 169 nets, 21 ICs, 86 bus-connector nets, rails GND, VCC

- no findings

## cards/protocard/kicad/v1.0

9 parts, 87 nets, 0 ICs, 86 bus-connector nets, rails GND, VCC

- no findings

## cards/register/kicad/v1.1

102 parts, 262 nets, 47 ICs, 86 bus-connector nets, rails GND, VCC

- no findings

## cards/sequencer-logic/kicad/v2.1

104 parts, 325 nets, 38 ICs, 86 bus-connector nets, rails GND, VCC

- no findings

## cards/sequencer-memory/accessories/eeprom-adaptor/kicad

2 parts, 5 nets, 2 ICs, 0 bus-connector nets, rails GND, VCC

- **HIGH** rail VCC has no source on this card (no connector/header pin, no power output); 7 pins on it
- **HIGH** rail GND has no source on this card (no connector/header pin, no power output); 3 pins on it
- **LOW** decoupling: 0 100 nF-class caps for 2 ICs

## cards/sequencer-memory/kicad/v2.1

59 parts, 129 nets, 16 ICs, 0 bus-connector nets, rails GND, VCC

- no findings

## cards/video/kicad/v1.1

47 parts, 202 nets, 16 ICs, 86 bus-connector nets, rails GND, VCC

- **MED** open-collector net N$5 (IC27.8) has no pull-up and no other driver
- **MED** open-collector net N$16 (IC27.10) has no pull-up and no other driver

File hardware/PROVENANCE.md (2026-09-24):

# Provenance of every board version

Generated %s by `tools/gen_provenance.py`. **Source** = the YACCS folder the files were copied from. **Real date** = the oldest modification date of any byte-identical copy anywhere in YACCS: git checkouts (gitversion = 2025-03-06, newgit = 2026-05-21) stamp their own date on every file, so a version whose oldest copy is 2020 was made in 2020 whatever the checkout says. **Copies** = identical copies and the YACCS folders holding them (2020/2024 = the non-git working copies with real dates; YACC1-2020-ORIG = Aug-2020 snapshot, YACC1-2020-OLD = Jan-2021, July 2021 backup, YACC1A/A1/B/BACKUP = 2016-18 gen-1 backups).

| Version folder | Source in YACCS | Design file | Real date (oldest identical copy) | Copies |
|---|---|---|---|---|
| `bus/backplane/eagle/deprecated/v1.1` | `YACC gitversion/YACC1-2020/PCB/Production/BUS-PROD-V1.1` | `yacc2buss.brd` | 2016-06-16 | 13 in YACC1-2020 July 2021 backup, YACC1-2020-ORIG, YACC1-BACKUP, YACC1A, YACC1A1, gitversion, newgit |
|  |  | `yacc2buss.sch` | 2016-06-14 | 20 in 2020, 2024, YACC1-2020 July 2021 backup, YACC1-2020-ORIG, YACC1-2020-backup-pre-git-backup, YACC1-BACKUP, YACC1A, YACC1A1, gitversion, newgit |
| `bus/backplane/eagle/v2.0` | `YACC gitversion/YACC1-2020/PCB/Production/BUS-PROD-V2.0` | `yacc2buss.brd` | 2021-08-03 | 5 in 2020, gitversion, newgit |
|  |  | `yacc2buss.sch` | 2021-07-26 | 5 in 2020, gitversion, newgit |
| `bus/blank-card/eagle/v3.1` | `YACC gitversion/YACC1-2020/PCB/Working - Under Develolpment/Blank-V3.1` | `Blank V3.1.brd` | 2020-08-23 | 5 in 2020, 2024, YACC1-2020 July 2021 backup, gitversion, newgit |
|  |  | `Blank V3.1.sch` | 2020-08-23 | 5 in 2020, 2024, YACC1-2020 July 2021 backup, gitversion, newgit |
| `bus/bus-jumper-horizontal/eagle/deprecated/v3.0` | `YACCS-OLD/YACC1-2020-OLD/PCB/Production/Old & obsolete/Bus Jumper V3.0-horiz` | `Jumper Board V3.0.brd` | 2020-06-16 | 2 in YACC1-2020-OLD, YACC1-2020-ORIG |
|  |  | `Jumper Board V3.0.sch` | 2020-06-16 | 22 in 2020, 2024, YACC1-2020 July 2021 backup, YACC1-2020-OLD, YACC1-2020-ORIG, YACC1-2020-backup-pre-git-backup, gitversion, newgit |
| `bus/bus-jumper-horizontal/eagle/v3.2` | `YACC gitversion/YACC1-2020/PCB/Production/Bus Jumper Horizontal V3.2` | `Jumper Board Horizontal V3.1.brd` | 2020-07-20 | 11 in 2020, 2024, YACC1-2020 July 2021 backup, YACC1-2020-ORIG, YACC1-2020-backup-pre-git-backup, gitversion, newgit |
|  |  | `Jumper Board Horizontal V3.1.sch` | 2020-06-16 | 22 in 2020, 2024, YACC1-2020 July 2021 backup, YACC1-2020-OLD, YACC1-2020-ORIG, YACC1-2020-backup-pre-git-backup, gitversion, newgit |
| `bus/bus-jumper-vertical/eagle/v3.0` | `YACC gitversion/YACC1-2020/PCB/Production/Bus Jumper Vertical V3.0` | `Jumper Board V3.0.brd` | 2020-06-16 | 6 in 2020, 2024, YACC1-2020 July 2021 backup, YACC1-2020-ORIG, gitversion, newgit |
|  |  | `Jumper Board V3.0.sch` | 2020-06-16 | 22 in 2020, 2024, YACC1-2020 July 2021 backup, YACC1-2020-OLD, YACC1-2020-ORIG, YACC1-2020-backup-pre-git-backup, gitversion, newgit |
|  |  | `Jumper Board Vertical V3.1.brd` | 2020-06-18 | 7 in 2020, 2024, YACC1-2020 July 2021 backup, YACC1-2020-ORIG, YACC1-2020-backup-pre-git-backup, gitversion, newgit |
| `bus/bus-template/eagle/v3.2` | `YACC gitversion/YACC1-2020/PCB/Working - Under Develolpment/Bus Template V3.2` | `Bus Template V3.2.sch` | 2020-11-29 | 5 in 2020, 2024, YACC1-2020 July 2021 backup, gitversion, newgit |
| `cards/address-tmp/eagle/deprecated/v1.0` | `YACCS-OLD/YACC1-2020-OLD/PCB/Production/Old & obsolete/Address and TMP-V1.0` | `Address and TMP V1.0.brd` | 2020-06-20 | 9 in 2020, 2024, YACC1-2020 July 2021 backup, YACC1-2020-OLD, YACC1-2020-ORIG, YACC1-2020-backup-pre-git-backup, gitversion, newgit |
|  |  | `Address and TMP V1.0.sch` | 2020-06-20 | 4 in YACC1-2020-OLD, YACC1-2020-ORIG, YACC1-2020-backup-pre-git-backup |
| `cards/alu/eagle/deprecated/v3.0-2layer` | `YACCS-OLD/YACC1-2020-OLD/PCB/Production/Old & obsolete/ALU-V3.0-2 layer` | `alu4.brd` | 2020-06-13 | 3 in YACC1-2020-OLD, YACC1-2020-ORIG, YACC1B |
|  |  | `alu4.sch` | 2020-06-14 | 3 in YACC1-2020-OLD, YACC1-2020-ORIG, YACC1B |
| `cards/alu/eagle/deprecated/v3.1-buried-vias` | `YACCS-OLD/YACC1-2020-OLD/PCB/Production/Old & obsolete/ALU-V3.1-buried-vias` | `ALU V3.1.brd` | 2020-07-07 | 9 in YACC1-2020 July 2021 backup, YACC1-2020-OLD, YACC1-2020-ORIG, YACC1-2020-backup-pre-git-backup, gitversion, newgit |
|  |  | `ALU V3.1.sch` | 2020-07-07 | 11 in YACC1-2020 July 2021 backup, YACC1-2020-OLD, YACC1-2020-ORIG, YACC1-2020-backup-pre-git-backup, gitversion, newgit |
| `cards/alu/eagle/deprecated/v3.1-resubmit` | `YACCS-OLD/YACC1-2020-OLD/PCB/Production/Old & obsolete/ALU-V3.1 resubmit` | `ALU V3.1.brd` | 2020-07-08 | 2 in YACC1-2020-OLD, YACC1-2020-ORIG |
|  |  | `ALU V3.1.sch` | 2020-07-07 | 11 in YACC1-2020 July 2021 backup, YACC1-2020-OLD, YACC1-2020-ORIG, YACC1-2020-backup-pre-git-backup, gitversion, newgit |
| `cards/alu/eagle/deprecated/v3.1` | `YACC gitversion/YACC1-2020/PCB/Working - Under Develolpment/Old and obsolete/ALU-V3.1` | `ALU V3.1.brd` | 2020-07-07 | 9 in YACC1-2020 July 2021 backup, YACC1-2020-OLD, YACC1-2020-ORIG, YACC1-2020-backup-pre-git-backup, gitversion, newgit |
|  |  | `ALU V3.1.sch` | 2020-07-07 | 11 in YACC1-2020 July 2021 backup, YACC1-2020-OLD, YACC1-2020-ORIG, YACC1-2020-backup-pre-git-backup, gitversion, newgit |
| `cards/alu/eagle/v3.2` | `YACC gitversion/YACC1-2020/PCB/Production/ALU-V3.2` | `ALU V3.2.brd` | 2020-11-29 | 8 in 2020, 2024, YACC1-2020 July 2021 backup, gitversion, newgit |
|  |  | `ALU V3.2.sch` | 2020-11-29 | 5 in 2020, YACC1-2020 July 2021 backup, gitversion, newgit |
| `cards/bus-tester/eagle/v1.1` | `YACC gitversion/YACC1-2020/PCB/Production/Bus Tester orig` | `tester.brd` | 2018-03-15 | 6 in 2020, 2024, YACC1-2020 July 2021 backup, YACC1-2020-backup-pre-git-backup, gitversion, newgit |
|  |  | `tester.sch` | 2020-08-15 | 6 in 2020, 2024, YACC1-2020 July 2021 backup, YACC1-2020-backup-pre-git-backup, gitversion, newgit |
| `cards/bus-tester/eagle/v3.1` | `YACC gitversion/YACC1-2020/PCB/Production/Bus Tester V3.1` | `tester.brd` | 2020-07-15 | 11 in 2020, 2024, YACC1-2020 July 2021 backup, YACC1-2020-ORIG, YACC1-2020-backup-pre-git-backup, gitversion, newgit |
|  |  | `tester.sch` | 2020-07-15 | 16 in 2020, 2024, YACC1-2020 July 2021 backup, YACC1-2020-ORIG, YACC1-2020-backup-pre-git-backup, gitversion, newgit |
| `cards/io/eagle/deprecated/v1.0` | `YACCS-OLD/YACC1-2020-OLD/PCB/Production/Old & obsolete/IO-V-1.0` | `IO V1.0.brd` | 2020-07-13 | 2 in YACC1-2020-OLD, YACC1-2020-ORIG |
|  |  | `IO V1.0.sch` | 2020-07-13 | 2 in YACC1-2020-OLD, YACC1-2020-ORIG |
| `cards/io/eagle/v1.1` | `YACC gitversion/YACC1-2020/PCB/Production/IO-V-1.1` | `IO V1.1.brd` | 2020-11-29 | 5 in 2020, 2024, YACC1-2020 July 2021 backup, gitversion, newgit |
|  |  | `IO V1.1.sch` | 2020-11-29 | 5 in 2020, 2024, YACC1-2020 July 2021 backup, gitversion, newgit |
| `cards/mem-register/eagle/v1.0` | `YACC gitversion/YACC1-2020/PCB/Production/Mem Register V1.0` | `Mem Register V1.0.brd` | 2021-07-19 | 5 in 2020, gitversion, newgit |
|  |  | `Mem Register V1.0.sch` | 2021-07-19 | 5 in 2020, gitversion, newgit |
| `cards/mem-switch/eagle/deprecated/v1.0` | `YACC gitversion/YACC1-2020/PCB/Production/Mem Switch V1.0` | `Mem Switch V1.0.brd` | 2021-06-23 | 7 in 2020, 2024, YACC1-2020 July 2021 backup, gitversion, newgit |
|  |  | `Mem Switch V1.0.sch` | 2021-06-23 | 7 in 2020, 2024, YACC1-2020 July 2021 backup, gitversion, newgit |
| `cards/mem-switch/eagle/v1.1` | `YACC gitversion/YACC1-2020/PCB/Production/Mem Switch V1.1` | `Mem Switch V1.1.brd` | 2021-07-19 | 5 in 2020, gitversion, newgit |
|  |  | `Mem Switch V1.1.sch` | 2021-07-19 | 5 in 2020, gitversion, newgit |
| `cards/memory/eagle/deprecated/v1.0` | `YACCS-OLD/YACC1-2020-OLD/PCB/Production/Old & obsolete/Memory v1.0` | `Memory V1.0.brd` | 2020-06-18 | 2 in YACC1-2020-OLD, YACC1-2020-ORIG |
|  |  | `Memory V1.0.sch` | 2020-06-18 | 2 in YACC1-2020-OLD, YACC1-2020-ORIG |
| `cards/memory/eagle/deprecated/v1.1` | `YACCS-OLD/YACC1-2020-OLD/PCB/Production/Old & obsolete/Memory v1.1` | `Memory V1.0.brd` | 2020-06-19 | 9 in 2020, 2024, YACC1-2020 July 2021 backup, YACC1-2020-OLD, YACC1-2020-ORIG, YACC1-2020-backup-pre-git-backup, gitversion, newgit |
|  |  | `Memory V1.0.sch` | 2020-06-19 | 9 in 2020, 2024, YACC1-2020 July 2021 backup, YACC1-2020-OLD, YACC1-2020-ORIG, YACC1-2020-backup-pre-git-backup, gitversion, newgit |
| `cards/memory/eagle/deprecated/v1.2` | `YACC gitversion/YACC1-2020/PCB/Production/Memory v1.2` | `Memory V1.2.brd` | 2020-11-29 | 5 in 2020, 2024, YACC1-2020 July 2021 backup, gitversion, newgit |
|  |  | `Memory V1.2.brd.old.brd` | 2020-09-01 | 5 in 2020, 2024, YACC1-2020 July 2021 backup, gitversion, newgit |
|  |  | `Memory V1.2.sch` | 2020-11-29 | 6 in 2020, 2024, YACC1-2020 July 2021 backup, gitversion, newgit, test |
| `cards/memory/eagle/deprecated/v1.3-do-not-use` | `YACC gitversion/YACC1-2020/PCB/Working - Under Develolpment/Memory v1.3` | `Memory V1.3.brd` | 2021-03-17 | 5 in 2020, 2024, YACC1-2020 July 2021 backup, gitversion, newgit |
|  |  | `Memory V1.3.sch` | 2021-03-17 | 6 in 2020, 2024, YACC1-2020 July 2021 backup, gitversion, newgit, test |
| `cards/protocard/eagle/v1.0` | `YACC gitversion/YACC1-2020/PCB/Production/PROTOCARD-PROD-V1.0` | `ProtoCard-Prod-V1.0.brd` | 2016-07-14 | 11 in 2020, 2024, YACC1-2020 July 2021 backup, YACC1-BACKUP, YACC1A, YACC1A1, gitversion, newgit |
|  |  | `ProtoCard-Prod-V1.0.sch` | 2016-07-14 | 11 in 2020, 2024, YACC1-2020 July 2021 backup, YACC1-BACKUP, YACC1A, YACC1A1, gitversion, newgit |
| `cards/register/eagle/deprecated/v1.0-no-address` | `YACCS-OLD/YACC1-2020-OLD/PCB/Production/Old & obsolete/Index Registers - no address1.0` | `Index Registers - 1.0.brd` | 2020-06-18 | 2 in YACC1-2020-OLD, YACC1-2020-ORIG |
|  |  | `Index Registers - 1.0.sch` | 2020-06-18 | 2 in YACC1-2020-OLD, YACC1-2020-ORIG |
| `cards/register/eagle/deprecated/v1.0` | `YACCS-OLD/YACC1-2020-ORIG/PCB/Production/Index Registers 1.0` | `Index Registers - 1.0.brd` | 2020-06-18 | 2 in YACC1-2020-OLD, YACC1-2020-ORIG |
|  |  | `Index Registers - 1.0.sch` | 2020-06-18 | 2 in YACC1-2020-OLD, YACC1-2020-ORIG |
| `cards/register/eagle/v1.1` | `YACC gitversion/YACC1-2020/PCB/Production/Index Registers 1.1` | `Index Registers - 1.1.brd` | 2020-08-31 | 11 in 2020, 2024, YACC1-2020 July 2021 backup, gitversion, newgit |
|  |  | `Index Registers - 1.1.sch` | 2020-08-31 | 11 in 2020, 2024, YACC1-2020 July 2021 backup, gitversion, newgit |
| `cards/sequencer-logic/eagle/deprecated/v2.0` | `YACCS-OLD/YACC1-2020-OLD/PCB/Production/Old & obsolete/Sequencer-Logic-v2.0` | `Sequencer-Logic-Prod-V2.0.brd` | 2020-07-25 | 2 in YACC1-2020-OLD, YACC1-2020-ORIG |
|  |  | `Sequencer-Logic-Prod-V2.0.sch` | 2020-07-25 | 2 in YACC1-2020-OLD, YACC1-2020-ORIG |
| `cards/sequencer-logic/eagle/v2.1` | `YACC gitversion/YACC1-2020/PCB/Production/Sequencer-Logic-v2.1` | `Sequencer-Logic-Prod-V2.1l.brd` | 2020-12-01 | 8 in 2020, 2024, YACC1-2020 July 2021 backup, gitversion, newgit |
|  |  | `Sequencer-Logic-Prod-V2.1l.sch` | 2020-12-01 | 8 in 2020, 2024, YACC1-2020 July 2021 backup, gitversion, newgit |
| `cards/sequencer-memory/accessories/eeprom-adaptor` | `YACC1-2024/PCB/Working - Under Develolpment/eeprom adaptor` | `eeprom adaptor.brd` | 2020-12-21 | 5 in 2020, 2024, YACC1-2020 July 2021 backup, gitversion, newgit |
|  |  | `eeprom adaptor.sch` | 2020-12-19 | 5 in 2020, 2024, YACC1-2020 July 2021 backup, gitversion, newgit |
| `cards/sequencer-memory/eagle/deprecated/v2.0` | `YACCS-OLD/YACC1-2020-OLD/PCB/Production/Old & obsolete/Sequencer-Memory-V2.0` | `Sequencer-Memory-V2.0.brd` | 2020-07-25 | 4 in YACC1-2020-OLD, YACC1-2020-ORIG, YACC1-2020-backup-pre-git-backup |
|  |  | `Sequencer-Memory-V2.0.sch` | 2020-07-25 | 4 in YACC1-2020-OLD, YACC1-2020-ORIG, YACC1-2020-backup-pre-git-backup |
| `cards/sequencer-memory/eagle/v2.1` | `YACC gitversion/YACC1-2020/PCB/Production/Sequencer-Memory-V2.1` | `Sequencer-Memory-V2.1.brd` | 2020-12-01 | 8 in 2020, 2024, YACC1-2020 July 2021 backup, gitversion, newgit |
|  |  | `Sequencer-Memory-V2.1.sch` | 2020-12-01 | 8 in 2020, 2024, YACC1-2020 July 2021 backup, gitversion, newgit |
| `cards/video/eagle/v1.0-fusion-export-2026-09-18` | `video` | `Video_1.0.brd` | 2026-09-18 | 1 in video |
|  |  | `Video_1.0.sch` | 2026-09-18 | 1 in video |

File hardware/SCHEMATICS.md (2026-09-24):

# Schematic PDFs

Generated %s by `tools/sch_to_pdf.py` from every Eagle `.sch` under `hardware/` (active and deprecated revisions), rendered by KiCad after conversion with `tools/kicad/eagle_sch_to_kicad.py`. Page 1 of each PDF is KiCad's sheet index; the circuit starts on page 2. These are derived files: re-run the script after any change to a `.sch`.

| Schematic | PDF |
|---|---|
| `bus/backplane/eagle/deprecated/v1.1/yacc2buss.sch` | [`yacc2buss-schematic.pdf`](bus/backplane/eagle/deprecated/v1.1/pdf/yacc2buss-schematic.pdf) |
| `bus/backplane/eagle/v2.0/yacc2buss.sch` | [`yacc2buss-schematic.pdf`](bus/backplane/eagle/v2.0/pdf/yacc2buss-schematic.pdf) |
| `bus/blank-card/eagle/v3.1/Blank V3.1.sch` | [`Blank V3.1-schematic.pdf`](bus/blank-card/eagle/v3.1/pdf/Blank V3.1-schematic.pdf) |
| `bus/blank-card/eagle/v3.2/Blank V3.2.sch` | [`Blank V3.2-schematic.pdf`](bus/blank-card/eagle/v3.2/pdf/Blank V3.2-schematic.pdf) |
| `bus/bus-jumper-horizontal/eagle/deprecated/v3.0/Jumper Board V3.0.sch` | [`Jumper Board V3.0-schematic.pdf`](bus/bus-jumper-horizontal/eagle/deprecated/v3.0/pdf/Jumper Board V3.0-schematic.pdf) |
| `bus/bus-jumper-horizontal/eagle/v3.2/Jumper Board Horizontal V3.1.sch` | [`Jumper Board Horizontal V3.1-schematic.pdf`](bus/bus-jumper-horizontal/eagle/v3.2/pdf/Jumper Board Horizontal V3.1-schematic.pdf) |
| `bus/bus-jumper-vertical/eagle/v3.0/Jumper Board V3.0.sch` | [`Jumper Board V3.0-schematic.pdf`](bus/bus-jumper-vertical/eagle/v3.0/pdf/Jumper Board V3.0-schematic.pdf) |
| `bus/bus-template/eagle/v3.2/Bus Template V3.2.sch` | [`Bus Template V3.2-schematic.pdf`](bus/bus-template/eagle/v3.2/pdf/Bus Template V3.2-schematic.pdf) |
| `cards/address-tmp/eagle/deprecated/v1.0/Address and TMP V1.0.sch` | [`Address and TMP V1.0-schematic.pdf`](cards/address-tmp/eagle/deprecated/v1.0/pdf/Address and TMP V1.0-schematic.pdf) |
| `cards/alu/eagle/deprecated/v3.0-2layer/alu4.sch` | [`alu4-schematic.pdf`](cards/alu/eagle/deprecated/v3.0-2layer/pdf/alu4-schematic.pdf) |
| `cards/alu/eagle/deprecated/v3.1-buried-vias/ALU V3.1.sch` | [`ALU V3.1-schematic.pdf`](cards/alu/eagle/deprecated/v3.1-buried-vias/pdf/ALU V3.1-schematic.pdf) |
| `cards/alu/eagle/deprecated/v3.1-resubmit/ALU V3.1.sch` | [`ALU V3.1-schematic.pdf`](cards/alu/eagle/deprecated/v3.1-resubmit/pdf/ALU V3.1-schematic.pdf) |
| `cards/alu/eagle/deprecated/v3.1/ALU V3.1.sch` | [`ALU V3.1-schematic.pdf`](cards/alu/eagle/deprecated/v3.1/pdf/ALU V3.1-schematic.pdf) |
| `cards/alu/eagle/v3.2/ALU V3.2.sch` | [`ALU V3.2-schematic.pdf`](cards/alu/eagle/v3.2/pdf/ALU V3.2-schematic.pdf) |
| `cards/bus-tester/eagle/v1.1/tester.sch` | [`tester-schematic.pdf`](cards/bus-tester/eagle/v1.1/pdf/tester-schematic.pdf) |
| `cards/bus-tester/eagle/v3.1/tester.sch` | [`tester-schematic.pdf`](cards/bus-tester/eagle/v3.1/pdf/tester-schematic.pdf) |
| `cards/io/eagle/deprecated/v1.0/IO V1.0.sch` | [`IO V1.0-schematic.pdf`](cards/io/eagle/deprecated/v1.0/pdf/IO V1.0-schematic.pdf) |
| `cards/io/eagle/v1.1/IO V1.1.sch` | [`IO V1.1-schematic.pdf`](cards/io/eagle/v1.1/pdf/IO V1.1-schematic.pdf) |
| `cards/mem-register/eagle/v1.0/Mem Register V1.0.sch` | [`Mem Register V1.0-schematic.pdf`](cards/mem-register/eagle/v1.0/pdf/Mem Register V1.0-schematic.pdf) |
| `cards/mem-switch/eagle/deprecated/v1.0/Mem Switch V1.0.sch` | [`Mem Switch V1.0-schematic.pdf`](cards/mem-switch/eagle/deprecated/v1.0/pdf/Mem Switch V1.0-schematic.pdf) |
| `cards/mem-switch/eagle/v1.1/Mem Switch V1.1.sch` | [`Mem Switch V1.1-schematic.pdf`](cards/mem-switch/eagle/v1.1/pdf/Mem Switch V1.1-schematic.pdf) |
| `cards/memory/eagle/deprecated/v1.0/Memory V1.0.sch` | [`Memory V1.0-schematic.pdf`](cards/memory/eagle/deprecated/v1.0/pdf/Memory V1.0-schematic.pdf) |
| `cards/memory/eagle/deprecated/v1.1/Memory V1.0.sch` | [`Memory V1.0-schematic.pdf`](cards/memory/eagle/deprecated/v1.1/pdf/Memory V1.0-schematic.pdf) |
| `cards/memory/eagle/deprecated/v1.2/Memory V1.2.sch` | [`Memory V1.2-schematic.pdf`](cards/memory/eagle/deprecated/v1.2/pdf/Memory V1.2-schematic.pdf) |
| `cards/memory/eagle/deprecated/v1.3-do-not-use/Memory V1.3.sch` | [`Memory V1.3-schematic.pdf`](cards/memory/eagle/deprecated/v1.3-do-not-use/pdf/Memory V1.3-schematic.pdf) |
| `cards/memory/eagle/v1.3/Memory V1.3.sch` | [`Memory V1.3-schematic.pdf`](cards/memory/eagle/v1.3/pdf/Memory V1.3-schematic.pdf) |
| `cards/protocard/eagle/v1.0/ProtoCard-Prod-V1.0.sch` | [`ProtoCard-Prod-V1.0-schematic.pdf`](cards/protocard/eagle/v1.0/pdf/ProtoCard-Prod-V1.0-schematic.pdf) |
| `cards/register/eagle/deprecated/v1.0-no-address/Index Registers - 1.0.sch` | [`Index Registers - 1.0-schematic.pdf`](cards/register/eagle/deprecated/v1.0-no-address/pdf/Index Registers - 1.0-schematic.pdf) |
| `cards/register/eagle/deprecated/v1.0/Index Registers - 1.0.sch` | [`Index Registers - 1.0-schematic.pdf`](cards/register/eagle/deprecated/v1.0/pdf/Index Registers - 1.0-schematic.pdf) |
| `cards/register/eagle/v1.1/Index Registers - 1.1.sch` | [`Index Registers - 1.1-schematic.pdf`](cards/register/eagle/v1.1/pdf/Index Registers - 1.1-schematic.pdf) |
| `cards/sequencer-logic/eagle/deprecated/v2.0/Sequencer-Logic-Prod-V2.0.sch` | [`Sequencer-Logic-Prod-V2.0-schematic.pdf`](cards/sequencer-logic/eagle/deprecated/v2.0/pdf/Sequencer-Logic-Prod-V2.0-schematic.pdf) |
| `cards/sequencer-logic/eagle/v2.1/Sequencer-Logic-Prod-V2.1l.sch` | [`Sequencer-Logic-Prod-V2.1l-schematic.pdf`](cards/sequencer-logic/eagle/v2.1/pdf/Sequencer-Logic-Prod-V2.1l-schematic.pdf) |
| `cards/sequencer-logic/eagle/v2.1/orig size/Sequencer-Logic-Prod-V2.1 copy.sch` | [`Sequencer-Logic-Prod-V2.1 copy-schematic.pdf`](cards/sequencer-logic/eagle/v2.1/orig size/pdf/Sequencer-Logic-Prod-V2.1 copy-schematic.pdf) |
| `cards/sequencer-logic/eagle/v2.1/orig size/Sequencer-Logic-Prod-V2.1.sch` | [`Sequencer-Logic-Prod-V2.1-schematic.pdf`](cards/sequencer-logic/eagle/v2.1/orig size/pdf/Sequencer-Logic-Prod-V2.1-schematic.pdf) |
| `cards/sequencer-memory/accessories/eeprom-adaptor/eeprom adaptor.sch` | [`eeprom adaptor-schematic.pdf`](cards/sequencer-memory/accessories/eeprom-adaptor/pdf/eeprom adaptor-schematic.pdf) |
| `cards/sequencer-memory/eagle/deprecated/v2.0/Sequencer-Memory-V2.0.sch` | [`Sequencer-Memory-V2.0-schematic.pdf`](cards/sequencer-memory/eagle/deprecated/v2.0/pdf/Sequencer-Memory-V2.0-schematic.pdf) |
| `cards/sequencer-memory/eagle/v2.1/Sequencer-Memory-V2.1.sch` | [`Sequencer-Memory-V2.1-schematic.pdf`](cards/sequencer-memory/eagle/v2.1/pdf/Sequencer-Memory-V2.1-schematic.pdf) |
| `cards/video/eagle/v1.0-fusion-export-2026-09-18/Video_1.0.sch` | [`Video_1.0-schematic.pdf`](cards/video/eagle/v1.0-fusion-export-2026-09-18/pdf/Video_1.0-schematic.pdf) |

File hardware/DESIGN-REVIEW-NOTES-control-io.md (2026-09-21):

# Design review — control paths and I/O (sequencer logic/memory, IO, bus tester, backplane, video) — 2026-09-21

Second pass after the mechanical one in `DESIGN-REVIEW.md`. Read from the KiCad netlists (`reports/netlist.net`, pin
types from the Eagle symbols), chip values from the Eagle boards, the firmware that drives the ATmegas
(`embedded/bus-tester/bus-driver`, `embedded/sequencer-card/sequencer4`) and the microcode generator
(`firmware/microcode/ucode-generator2`). Gate pin-outs were checked against the symbol pin functions (I0/I1/O for
7400/08/32, O/I/I for 7402; 74175/74/192/244/374 pin functions as printed in the netlist).

Every finding: the trace (ref.pin -> net -> ref.pin, chip types), the failure scenario, severity
(HIGH = stops the card / damages parts, MED = unreliable or latent, LOW = housekeeping), and how to confirm it on
the bench. Already-known items (BACKLOG.md, video README) are not repeated except where a new detail changes them.
Report only; no redesign.

Scripts used (not committed): a netlist dumper (parts + nets with pin function/type), an SV1/SV2 pin-by-pin
comparator, a bus-driver-table-vs-tester-wiring check and a microcode-bit-vs-RAM-wiring check; the results of the
three checks are in the "checked, no issue" lists below.

---

## 1. Sequencer logic v2.1 (`hardware/cards/sequencer-logic/kicad/v2.1`)

### 1.1 HIGH — 17 bus lines are driven by the logic card no matter what -BUS-EN says (extends the BACKLOG item)

The BACKLOG's "CPU off switch" item assumes that de-asserting -BUS-EN silences the card. It silences the nine
pipeline 74LS374s (IC7, IC12, IC14, IC16, IC17, IC19, IC20, IC28) and the two microcode-address 74LS244s
(IC15, IC35), and nothing else. These stay on the bus:

| Bus pin(s) | Driver | Enable / control | Trace |
|---|---|---|---|
| B9–B12 REG-RD-ID0..3, B13–B16 REG-LD-ID0..3 | IC4 74LS244 (both halves) | -ONE-OPERAND-SEL = IC31 74LS04 p4 | IC16 74LS374 p16 (7Q, -2-BYTE-OPERAND-SEL) -> IC31 p3; IC31 p4 -> IC4 p1/p19 and IC18 p19 |
| same 8 lines | IC5 74LS244 | -2-BYTE-OPERAND-SEL directly | IC16 p16 -> IC5 p1/p19 |
| C3–C6 ADDR-REG-ID0..3 | IC18 74LS244 B half (p9/7/5/3) | -ONE-OPERAND-SEL (IC18 p19) | inputs = LADDR-REG-ID0..3 from IC19 74LS374 |
| C3–C6 | IC18 A half, IC11 74LS244 A half | SRC-ADDR (IC17 p5 -> IC18 p1), DEST-ADDR (IC16 p19 -> IC11 p1) | inputs = operand register IC6 74LS374 |
| B18 -REG-LD-LO | IC31 74LS04 p10 (totem pole) | none | IC27 74LS08 p11 -> IC31 p11 |
| B20 -REG-LD-HI | IC31 74LS04 p12 (totem pole) | none | IC24 74LS08 p6 -> IC31 p13 |
| C30 -RESET | IC36 74LS04 p6 (totem pole) | none | front-panel RESET latch (IC32 74ALS02 p4) -> IC36 p5 |
| C27 OUT | IC22 74ALS02 p13 (totem pole) | none | OUT-ON/OUT-OFF SR latch IC22 gates C/D |
| C28 -BUS-EN | IC36 74LS04 p8 | none | known (BACKLOG) |

IC4 and IC5 have complementary enables (IC31 inverts one into the other), so one of them is always on. With
-BUS-EN high, IC16 p16 floats, IC31 p3 reads high, IC31 p4 goes low and IC4 + IC18B drive whatever the floating
LREG-*/LADDR-* nets happen to read onto B9–B16 and C3–C6.

Failure: the bus tester (`bus-driver.ino` `setup()`) makes every signal in its table a push-pull MCP23017 output —
including -RESET, OUT, -REG-LD-LO/HI, REG-RD-ID, REG-LD-ID, ADDR-REG-ID — and puts the address and data buses in
WRITE mode; only BR-COND, -INT and IN are left as inputs. With the logic card fitted there are two totem-pole
drivers on each of these 17 lines. The tester reads back wrong levels and, worse, an LS244/LS374 output high
(short-circuit current 40–225 mA) into an MCP23017 output low (absolute maximum 25 mA per pin) can kill the
expander pin. This is why the tester "cannot load RAM with the logic card fitted" — but the v2.2 fix as written
(OEs of the 374/244s through a switch, OC driver for -BUS-EN) would still leave B9–B20, C3–C6, C27 and C30 driven.

Confirm: logic card fitted, sequencer READY high, tester plugged in. With the CPU held in reset, drive
REG-RD-ID0 (B9), -REG-LD-LO (B18), ADDR-REG-ID0 (C3), OUT (C27) and -RESET (C30) from the tester and read them back;
a meter on the line shows an intermediate level (~0.5–1.5 V) instead of the commanded one.

### 1.2 HIGH (documentation / rebuild) — IC33 and IC34 are drawn and BOM'd as 74LS192 (BCD decade); the microcode addressing needs binary counters

Trace: N$4 (IC38 74LS08 p6) -> IC33 UP p5; IC33 QA p3 -> IC35 74LS244 p2 -> p18 = CNT-CLK (the pipeline
clock, via IC25 74LS32 p13/p11 = BUS-LATCH-CLK); IC33 QB/QC/QD (p2/6/7) -> IC35 -> CADDR0/1/2 (SV1 p14/16/18);
IC33 CO p12 -> IC34 UP p5; IC34 QA/QB/QC -> CADDR3/4/5; IC34 QD p7 -> COUNT-FAULT -> IC26 74LS32 p12. Each
microstep is two counter clocks (QA is the phase bit, QB.. are the step address); 64 steps need a 7-bit binary
count. The generator (`controlLine.c writeCurrentLine`, `main.c loadNextInstruction`) writes lines 0,1,2,… per
opcode and the fetch alone is lines 0–5.

With decade parts the step address sequence would be 0,1,2,3,4, 8,9,10,11,12, 16,… (line 5 of the fetch — the one
that drops -REG-UP and -MEM-RD — never executes, then line 8 runs) and COUNT-FAULT fires after 40 steps, not 64.
The machine executes the switch-ROM program (MACHINE.md 2026-09-21), so binary parts are almost certainly what is
soldered in — but `Sequencer-Logic-Prod-V2.1l.brd` (value 74LS192N), the BOM CSV and both KiCad symbols (74*192)
say decade. The same symbol/BOM entry appears 16 times on the index-register card (`register/eagle/v1.1` BOM: 16 ×
74LS192N for the 16-bit registers, where decade counters would make the PC count in BCD) — outside this review's
scope but the same discrepancy. A rebuild from the BOM would order the wrong part.

Confirm: read the markings on IC33/IC34 (and on the register cards' counters). If they are 193s, correct the
value/BOM; if they really are 192s, the fetch sequence works only by accident of which lines are skipped and
`tests/sequencer` should dump the step address (JP4 p3 / SV1 CADDR pins) while single-stepping.

### 1.3 MED — The pipeline is not reloaded when reset is asserted, only when it is released; during reset (and from power-up until the first reset release) the 374s drive the last/random word onto the bus

Trace of the reset-release pulse: RESET (IC32 74ALS02 p4) -> IC37 74LS04 p1->p2 (N$44) -> IC37 p9->p8 (N$42) ->
IC36 74LS04 p11->p10 (N$46) -> IC32 p9; IC32 p8 = RESET; IC32 p10 = N$32 = NOR(RESET, RESET delayed 3 gates).
N$32 is a ~30–45 ns positive pulse only on the falling edge of RESET; it is ORed with CNT-CLK in IC25 (p12/p13 ->
p11 = BUS-LATCH-CLK). COUNT-RESET (IC26 p3 = RESET OR (UCODE-COUNT-RESET AND N$4)) clears IC33/IC34 during reset,
so CNT-CLK falls to 0 and never rises. Nothing clocks the pipeline while RESET is high; nothing clears it either
(-RESET goes only to IC8/IC9 74LS175 CLR p1). -BUS-EN stays asserted (IC36 p8 follows READY).

Consequence: while the front-panel switch sits in RESET the bus carries whatever the pipeline last held — the step
that was executing when reset was hit, or power-up garbage. BACKLOG.md's description ("in reset the pipeline still
drives ... word instruction 0 step 0") is what happens *after* the switch goes to EXECUTE (N$32 latches address
IR=0/step=0); during reset it is worse than that. Memory-card side: -RESET presets the boot flip-flop (memory IC12
74LS74 PRE p4) so the 28C64 answers every address (FORCE-ROM); memory IC6 74LS04 p9->p8->p3->p4 (N$4) feeds
-MEM-WR straight to the -WE (p27) of IC1, IC2 and the EEPROM IC13; -ROM-CS comes from the address decode with -VMA
(IC7 74LS138 G2A). A stale pipeline word with -MEM-WR and -VMA asserted therefore writes the EEPROM during reset.
The ROM was byte-identical to `rom/shipped` on 2026-09-18, so either it has not happened yet or the fitted 28C64
has data protection.

Confirm: scope B24 (-MEM-WR) and C12 (-VMA) at power-up and with RESET held, several times; run
`tools/verify_firmware.py` against the chip after a batch of power cycles. Related: the N$32 pulse (3 × LS04 tpd)
is right at the LS374's 15 ns minimum clock width — fine with LS parts, marginal if IC36/IC37 are ever replaced
by faster families.

### 1.4 MED — SPARE3 pipeline bit is wired to the sequencer-memory ATmega reset through JP2, and the microcode holds that bit at 0

Trace: RAM IC5 I/O5 (SV1-side name SPARE3) -> memory JP1 p1 -> logic JP1 p1 (USPARE3) -> IC16 74LS374 p7 (3D);
IC16 p6 (3Q, SPARE3) -> JP2 p2; JP2 p1 -> -MEM-CPU-RESET -> logic JP1 p2 -> memory JP1 p2 -> ATmega IC15 p1
/RESET and all five MCP23017 /RESET (p18), R4 10k pull-up. The generator's `initCurrentLine`
(`main.c:94`) calls `clearSignal` on every name; for a name without a '-' prefix that is `bitOff` = 0
(`main.c:76-86`). SPARE3 is never set anywhere, so every microcode line has SPARE3 = 0.

Failure: if JP2 is ever fitted the sequencer-memory card is held in reset (READY low, -BUS-EN high, RAM control
lines floating) and the CPU can never run. Harmless today only because JP2 is open. Confirm: JP2 open.

### 1.5 LOW — -REG-LD-LO / -REG-LD-HI are combinational with unequal paths (latent glitch)

-REG-LD-LO = NOT(LREG-LD-LO AND N$53) [IC27 74LS08 p13/p12 -> p11 -> IC31 p11 -> p10 -> B18];
N$53 = IC30 74LS32 p6 = (REG-LD-ID != 0) OR (branch latch N$71 AND REG-LD-ID == 0), where REG-LD-ID is taken from
the bus (B13–B16) through IC25/IC30 ORs, IC37 p13->p12, IC27 p9/p10; the branch latch N$71 is the gate SR latch
IC26 p8 / IC37 p3->4 / IC30 p3 / IC37 p5->6. Two gates on the LREG-LD-LO path versus seven on the ID path: if a
step raises LREG-LD-LO on the same edge that moves REG-LD-ID from non-zero to 0 with the branch not taken, B18
pulses low for ~40–60 ns before N$53 falls (a runt load strobe to R0 on the register cards' 74LS32 inputs
IC1/IC15/IC25/IC47 p10). The current generator does not do that: `branch.c` writes `setLdId(PC)` one line before
it raises REG-LD-LO/HI, and REG-LD-ID is 0 from `initCurrentLine` anyway. A future microcode that changes the ID
and the strobe together will hit it. Confirm (if the microcode is changed): scope IC31 p10 across the step edge.

### 1.6 LOW — Interrupt jumper JP3 needs two jumpers; edge mode triggers on the release of -INT

IC23A 74LS74: CLK p3 = INT-EDGE (JP3 p2), PRE p4 = IC36 p12 = NOT(INT-LEVEL, JP3 p4), CLR p1 = IC36 p4 =
NOT(INT-START OR RESET), D p2 = VCC. -INT (C13) is JP3 p3, GND on p1 and p5, pull-up selectable by the
-INT-PULLUP header (R5 10k). Mode select = -INT to p2 (edge) or p4 (level); the *other* input must be jumpered to
its GND neighbour, otherwise IC36 p13 floats high (PRE permanently asserted, DO-INT whenever enabled) or the
LS74 clock floats. In edge mode the LS74 clocks on the rising edge, i.e. an interrupt is registered when -INT is
released, not when it is asserted. Confirm: JP3 population; in edge mode pulse -INT low from the tester and watch
IC23 p5 set on the trailing edge.

### 1.7 LOW — Counter clock gated by asynchronous levels

N$4 = IC38 p6 = (UCODE-CLK AND RUN AND NOT(COUNT-FAULT OR DO-HALT)) with UCODE-CLK = (QG1 AND FREE-RUN) OR
(SINGLE-STEP/WAIT AND SINGLE-STEP-CLK) (IC38 p8/p11, IC26 p6). RUN (IC32 p1), the halt flip-flop (IC23B p9) and
the SS/WAIT latch (IC29) change asynchronously to QG1, so CONT, EXECUTE or flipping SS/WAIT while running can
produce a runt pulse on IC33 UP. Front-panel only; the switch latches (IC29/IC32 NOR pairs with R6–R11
pull-downs) are debounced, the HALT/CONT push buttons (R3/R4 pull-ups into IC31) are not, but they only feed a
set-only / clear-only flip-flop, so the bounce is harmless.

### 1.8 LOW — All pipeline outputs float when -BUS-EN is high (no pull-ups anywhere)

With READY low (54 s microcode copy) or the tester holding -BUS-EN high, IC16's -INT-JMP (p12) and -BRANCH-RD
(p2) — the output enables of IC10/IC3 and IC21/IC13 (74LS374 on DATA0–15) — float, as do OPERAND-CLK,
BRANCH-LD-*, INT-LD-*, OUT-ON/OFF, LD-INS-REG, UCODE-COUNT-RESET, CNT-CLK and COUNT-FAULT. LS inputs read a
floating pin as high, which is the inactive level for all of them (COUNT-FAULT high even stops the counter clock),
so it works by convention; noise on -BRANCH-RD/-INT-JMP could put the branch/interrupt registers on the data bus
while the tester drives it. Confirm: with READY low, scope IC16 p2/p12.

### Checked, no issue (sequencer logic)
- SV1/SV2: all 80 pins carry the same signal on both cards (U-prefix on the logic side); JP1 1:1 SPARE3 /
  -MEM-CPU-RESET / SRC-ADDR / DEST-ADDR on both cards.
- Instruction register IC8/IC9 74LS175: CLK = IC24 p3 = LD-INS-REG AND RUN, CLR = -RESET; opcode source is
  IC2 74LS244 (DATA0–7, enable DO-INT low) or IC1 74LS244 (all inputs VCC = $FF, enable -DO-INT) — complementary
  through IC36 p1->p2.
- Microcode address: CADDR6–13 = IC15 74LS244 from IC9/IC8 Q outputs; CADDR0–5 from the step counter (1.2).
- Operand paths: IC6 74LS374 (OPERAND-CLK, OC = GND) -> IC5/IC18A/IC11A; IC4 vs IC5 exactly one enabled.
- Branch latch and conditional PC load logic as the Notes.md V2.1 change list describes; BR-COND (C24) input only.
- OUT SR latch IC22 gates C/D; IN (C26) unconnected on this card; -RUN (C29) unconnected everywhere.
- Halt: IC23B set by (FP-HALT AND UCODE-COUNT-RESET) OR SOFT-HALT (IC24 p11, IC25 p6), cleared by RESET OR CONT
  (IC32 p13); SOFT-HALT and USOFT-HALT are one net (Notes.md item resolved).
- Spare gates: IC37 p11 grounded; IC11B inputs grounded and enabled (harmless).
- Step-clock source jumper SS-SEL (front-panel latch IC29 gates C/D or external JP4 p2); JP4 exposes
  UCODE-COUNT-RESET.

---

## 2. Sequencer memory v2.1 (`hardware/cards/sequencer-memory/kicad/v2.1`)

### 2.1 LOW — RAM control lines float whenever the ATmega is in reset or in its bootloader

-CMEMSEL (IC15 PB2 p16) -> all eight 62256 -CS p20; -CMEMRD (PB1 p15) -> -OE p22; -CMEMWR (PB0 p14) -> -WE p27;
no pull-ups on any of the three. Until `setup()` runs (Arduino bootloader delay after power-up, or any time
-MEM-CPU-RESET is pulled low by LOCAL-CPU-RESET / JP1) the pins are inputs and the RAMs see undefined
-CS/-OE/-WE while the expanders (also held in reset) are inputs. Any corruption is repaired by the copy + verify
that follows, so this is housekeeping; BUS-READY (PD7 p13 -> SV1 p12 -> logic IC36 p9) also floats high in that
window, so -BUS-EN is asserted and the logic card puts its stale pipeline word on the bus (see 1.3). Confirm:
scope IC15 p14 during power-up.

### 2.2 LOW — DTR auto-reset dead-ends; FTDI-VCC jumper

DTR-RESET0 solder jumper: p1 = FTDI DTR (JP3 P$1, N$33), p2 = N$8 which has no other node — nothing reaches
/RESET and there is no series 100 nF. Same on the bus tester (DTR-RESET0 p2 = N$9, single node). Flashing needs
the local reset button. FTDI-VCC0 (both cards) would parallel the FTDI's 5 V with the backplane rail if closed
while the card is on the bus.

### Checked, no issue (sequencer memory)
- Run-mode gating in `sequencer4`: after the verified copy `setAddressInput()`, `setDataInput()`,
  `uCodeRamRead(true)` (-OE low), `uCodeRamSelect(true)` (-CS low), -WE left high, then READYLINE high. In load
  mode -BUS-EN is high (READY low -> IC36 p8) so IC35/IC15 on the logic card are off the CADDR lines while IC10
  drives them. The firmware's own hint ("is -BUS-EN inactive?") covers the tester-asserts--BUS-EN case (BACKLOG).
- Microcode bit map: all 64 `yaccsignaldata2.h` (chip,port,bit) entries land on the RAM I/O pin whose SV1/SV2
  (or JP1) pin reaches the 74LS374 D input of the same-named signal on the logic card; generator byte index
  `(chip-1)*2+port` (`controlLine.c:103`) equals the loader's `writeGPIOAB` low/high byte order.
- I2C: IC10 0x20 (address), IC14 0x21, IC13 0x22, IC11 0x23, IC12 0x24 — matches `mcp[i].begin(i)`; on-board
  IC9 24AA01 at 0x57 (A0–A2 = VCC) is displaced by the adaptor (devices 6 and 7).
- CADDR14: R5 10k pull-up, header CADDR14 to GND; jumper off = upper 16K, on = lower; the ATmega has no pin on it,
  so load and run address the same half.
- EEPROM WP (IC9 p7) on JP2 (GND / VCC); STARTSWITCH R1 pull-up; UCODE mode switch to VCC/GND.
- MCP23017 100k pull-ups left on in run mode (`setDataInput`) — negligible load on the RAM outputs.

---

## 3. IO card v1.1 (`hardware/cards/io/kicad/v1.1`)

### 3.1 Correction to DESIGN-REVIEW.md — XTAL2 floating is correct

Y1 (ECS-2100AX oscillator) p5 OUTPUT -> N$31 -> IC1 XR16C550 XTAL1 p16; XTAL2 p17 (N$61) open, which is the
datasheet connection for an external clock. Not a fault. The Eagle value "ECS-2100AX-200" is the package name,
not a frequency; `firmware/monitor/monitor.asm:74` programs divisor 3 for 38400 baud, which implies a 1.8432 MHz
oscillator (20 MHz would give 416 kbaud). Confirm: read the can; put the frequency in the BOM.

### 3.2 LOW — Strobe polarity is fine, but every strobe passes through an open-collector inverter with a pull-up of unknown value

-IO-RD (B25) -> IC8 74LS06 p1->p2 = IO-RD; -IO-WR (B26) -> p3->p4 = IO-WR; -RESET (C30) -> p5->p6 = RESET ->
IC1 p35 (active-high reset, correct) and -> p9->p8 = -B-RESET -> CLR of IC4/IC9/IC10 74LS273; -IO-DATASEL ->
p11->p10 = IO-SELDATA -> IC1 CS0 p12. Pull-ups are RN2 (value blank in the Eagle board). The UART's IOR/IOW
(p22/p19, active high) are used with -IOR/-IOW (p21/p18) tied to VCC — correct. The latching edges (273 clocks
N$40/N$41/N$75 = NAND of IO-WR with the select bits; LCD E = N$30; 16550 IOW trailing edge) all come from the
fast falling edge of the OC outputs, so the design is sound; the leading edges rise through RN2 and, if RN2 is
10k, take a few hundred ns through the LS10/LS00 inputs (IC6, IC7, IC11), where a slow edge can produce a double
transition on the LCD E line (N$30) = a double write. Confirm: scope IC8 p4 rise time; watch for doubled LCD
characters.

### 3.3 LOW — The port decoder is address-only and the device-select bits have no hardware exclusivity

IC5 74LS138: A/B/C = IO-ADDR0..2, G1/G2A from the IO-ADDR-HL0 jumper (IO-ADDR3 or fixed), G2B = GND; -IO-SEL0..7
go only to the two select headers (DATA-ADDR0, IO-ADDR0) that pick the data port and the control port. Every
consumer ANDs the select with IO-RD/IO-WR (IC6/IC7/IC11), so the lack of -VMA/-BUS-EN qualification (the V1.2
idea in Notes.md) has no functional effect; with the pipeline floating, -IO-RD/-IO-WR read high at IC8 and the
strobes are inactive. The control latch IC10 74LS273 (Q1 SWITCH-LED, Q2 LCD-ENABLE, Q3 LCD-REGISTER, Q4–Q6
UART-A0..2, Q7 UART-CS, Q8 TIL311) lets software set SWITCH-LED and UART-CS together, in which case IC3 74LS244
(enable IC6 p6) and the UART both drive DATA0–7 on a data-port read. Software rule; note it in `firmware/abi/`.

### 3.4 LOW — LCD backlight straight across the rail

X2 HD44780 p15 (A) = VCC, p16 (K) = GND with no series resistor: relies on the module having its own. Confirm on
the module.

### Checked, no issue (IO)
- UART register select vs chip select: CS0 = IO-SELDATA (data port decode), CS1 = UART-CS (control latch bit),
  -CS2 = GND, -AS = GND; A0–A2 from the control latch; every register access is "write control byte, then
  read/write data port" — reachable, no aliasing. RCLK p9 = -BAUDOUT p15 (ICLK). CTS/DSR/CD/RI tied high.
- -INT (C13) = IC8 p12 open collector with RN2 pull-up, from the UART INT (p30) through the INT0 jumper — the
  only -INT source in the machine; the tester keeps -INT as input; the logic card adds an optional 10k.
- Data bus: no buffer at all (Notes.md V1.2 idea); the only drivers are the UART (CS·IOR), IC3 (read of
  switches) and nothing else — LCD R/W = GND so the LCD never drives; 273s and TIL311 latches are loads only.
- 74LS273 latches clock on the trailing edge of IO-WR while the data source is still asserted (generator asserts
  the source one line before the strobe).
- TIL311 HI0/LO0: latch strobe p5 = GND (transparent), blanking p8 = GND (not blanked), as Notes.md V1.1 says.
- OUT (C27) drives only an LED through R1; IN (C26) is driven only by the IN0 switch (hard VCC/GND) through the
  INPUT0 jumper — fine while nothing else drives IN (tester: input; logic/register/video: unconnected).
- Spare gates IC7C, IC11B, IC11C: inputs grounded.

---

## 4. Bus tester v1.1 (`hardware/cards/bus-tester/kicad/v1.1`)

### 4.1 HIGH (the other side of 1.1) — nothing on the card can make the expanders passive; the firmware drives every control line and both buses from setup()

IC1 (0x20) A3–A18 = ADDR0–15, IC2 (0x21) A19–B6 = DATA0–15, IC3 (0x22) B7–B22, IC4 (0x23) B23–C10, IC5 (0x24)
C11–C26, IC6 (0x25) C27–C30 + the on-card LED/switch lines — MCP23017 GPIO pins straight onto the DIN pins, no
buffer, no enable. `bus-driver.ino setup()`: all pins INPUT first, then every table entry `pinMode(OUTPUT)` with
its inactive level, `dataBusDir(BUS_WRITE)`, `addrBusDir(BUS_WRITE)`, then only BR-COND, -INT and IN back to
INPUT. So from power-up the tester drives 32 bus + 52 control lines including -RESET (C30), -BUS-EN (C28), -RUN
(C29), OUT (C27) and the register-card ID/strobe lines that the logic card also drives (1.1). The 2020 V3.1
redesign (latches with enables) was the fix and was never built. Confirm: as 1.1.

### 4.2 LOW — RN1–RN4 pull up all 32 address/data lines on the bus; value not recorded

RN1–RN4 (RN-9, pin 1 = VCC) on A3–A18 and A19–B6. The v3.1 notes say "removing pull-ups ... on Data and Address
lines", so they are known to be there; the Eagle value is blank. If they are 1k each driver on the bus sinks
5 mA per line (fine for LS244/245, tight for anything weaker). Confirm: measure RN1 pin 1–2.

### Checked, no issue (bus tester)
- Signal table vs wiring vs bus: all 52 bus entries in `YACC_Common_header.h` (chip, port, pin) reach the DIN pin
  that carries that signal in the V3.2 pinout (only the IOADDRn/IO-ADDRn spelling differs); the 12 on-card
  entries (OUT-LED, IN-SWITCH, LEDS-LD, SWITCHES-RD, BIT0–7) are local.
- Local reset: ATmega p1, all six expander /RESET p18, CPU-RESET button and R2–R8 10k are one net that does
  not reach C30 — the bus -RESET is just IC6 GPA3.
- Switch/LED port: IC9 74LS244 enable = SWITCHES-RD (IC6 GPA7), outputs BIT0–7 shared with IC6 GPB0–7 and IC8
  74LS374 D inputs; firmware sets SWITCHES-RD high at setup and GPB to input before pulling it low
  (`read_switches`), so the only bus fight would be a firmware bug.
- I2C addresses 0x20–0x25 all distinct; EEPROM IC7 at 0x57; SCL/SDA 2.2k pull-ups.

---

## 5. Backplane v2.0 (`hardware/bus/backplane/kicad/v2.0`)

### Checked, no issue
- 8 × FABC96S; every one of the 86 signal pins is a straight 8-member net (nothing else on any of them): no
  pull-ups, no termination, no series resistors.
- Power: 5V on A2/B2/C2/A31/B31/C31 and GND on A1/B1/C1/A32/B32/C32 of every slot (6 + 6 pins per slot), eight
  electrolytics C1–C8 (one per slot, value blank), R1/PWR0 LED, single wire-pad entry for 5V and GND.

### 5.1 LOW — no pull-ups anywhere on the bus
Consequence for the scenarios above: whenever the logic card's 374/244s are off (READY low for ~54 s at every
boot; tester holding -BUS-EN high) the control lines float. LS inputs read that as high, which is inactive for
all the active-low strobes (that is why the memory and IO cards sit quietly during the microcode load), but the
active-high lines (REG-*-ID, ADDR-REG-ID, IO-ADDR, ALU0–3, BR-COND, OUT, IN) are undefined and the 4077/CMOS
inputs on other cards see mid-rail. Not a fault of the backplane as drawn; a pull-up bank on a future revision is
the usual answer.

---

## 6. Video card v1.1 (`hardware/cards/video/kicad/v1.1`) — beyond the README / fix-6845-register-select.md items
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

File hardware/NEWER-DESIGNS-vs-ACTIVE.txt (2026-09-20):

### ALU: V3.2 (active) vs V3.3
====================================================================================================
A (older/active): /Users/ksr77/Developer/YACC1-D/hardware/cards/alu/eagle/v3.2/ALU V3.2.sch
B (newer):        /Users/ksr77/Developer/YACC1-D/hardware/cards/alu/eagle/v3.3/ALU V3.3.sch
SCHEMATIC parts: A=112 B=112 | added 0, removed 0, device changed 0, value-only changed 0
SCHEMATIC connectivity: nets A=217 B=217 | pin-sets only in A: 0, only in B: 0, renamed nets: 0
BOARD elements: A=86 B=86 | added 0, removed 0, package changed 0, moved 0
BOARD connectivity: pad-sets only in A: 0, only in B: 0 | copper hash A=f57c296b B=f57c296b | wires 2254->2254 vias 321->321
VERDICT: IDENTICAL NETLIST AND PARTS (board identical too)
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

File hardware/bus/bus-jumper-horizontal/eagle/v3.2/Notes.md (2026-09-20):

*Converted from `Notes.rtf` (saved 2025-03-06) by `tools/rtf_to_md.py`; the .rtf is the original.*

Changes since production Horizontal Bus Jumper 3.0

3.2
Increase trace width spacing and add layers

Next version V3.3

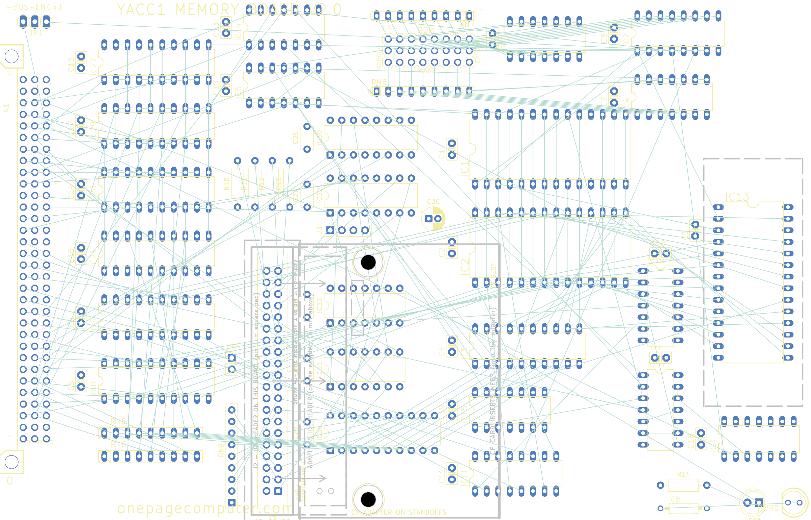
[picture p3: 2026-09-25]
hardware/cards/memory/kicad/v2.0/options-standoff/memory-v2.0-standoff-b-placement.png

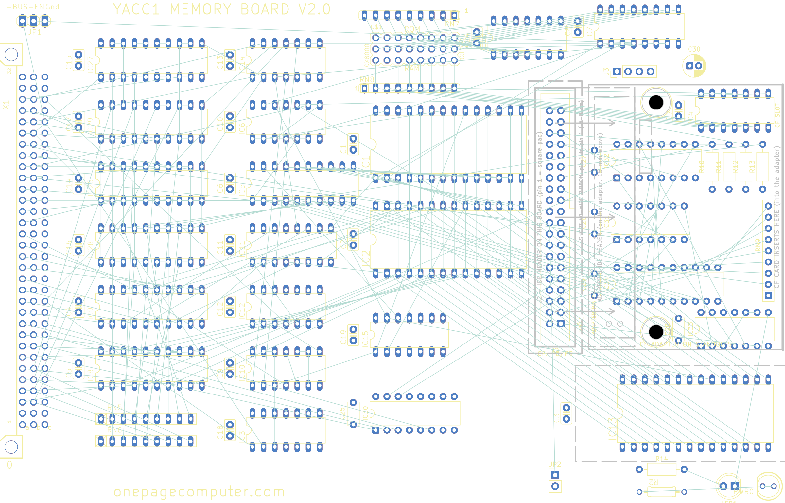
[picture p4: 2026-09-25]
hardware/cards/memory/kicad/v2.0/options-standoff/memory-v2.0-standoff-c-placement.png

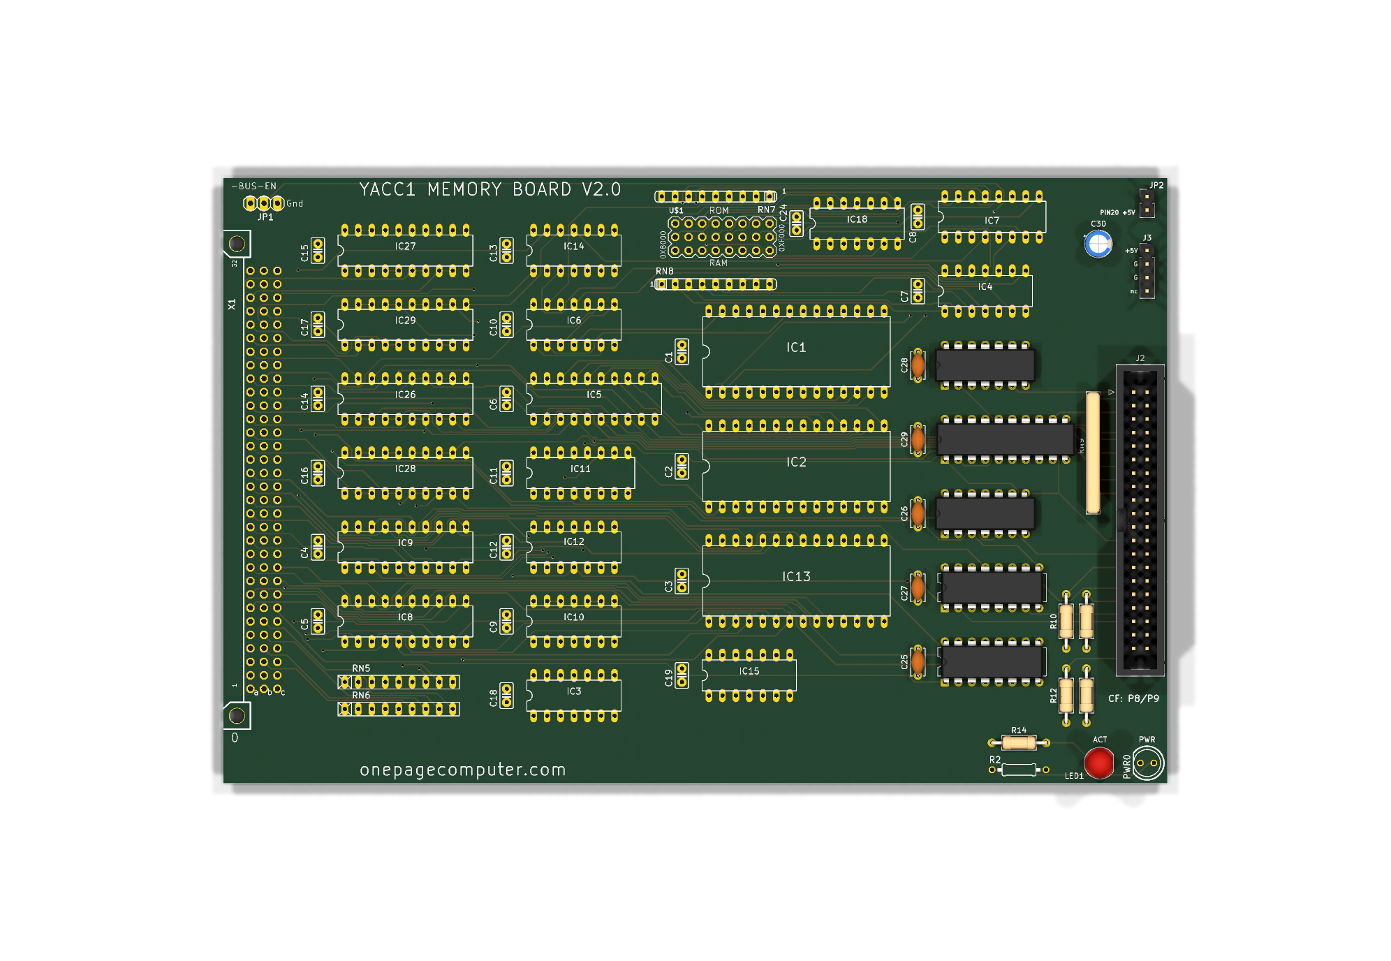
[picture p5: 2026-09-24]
hardware/cards/memory/kicad/v2.0/options-top-edge-J2/memory-v2.0-render-top.png

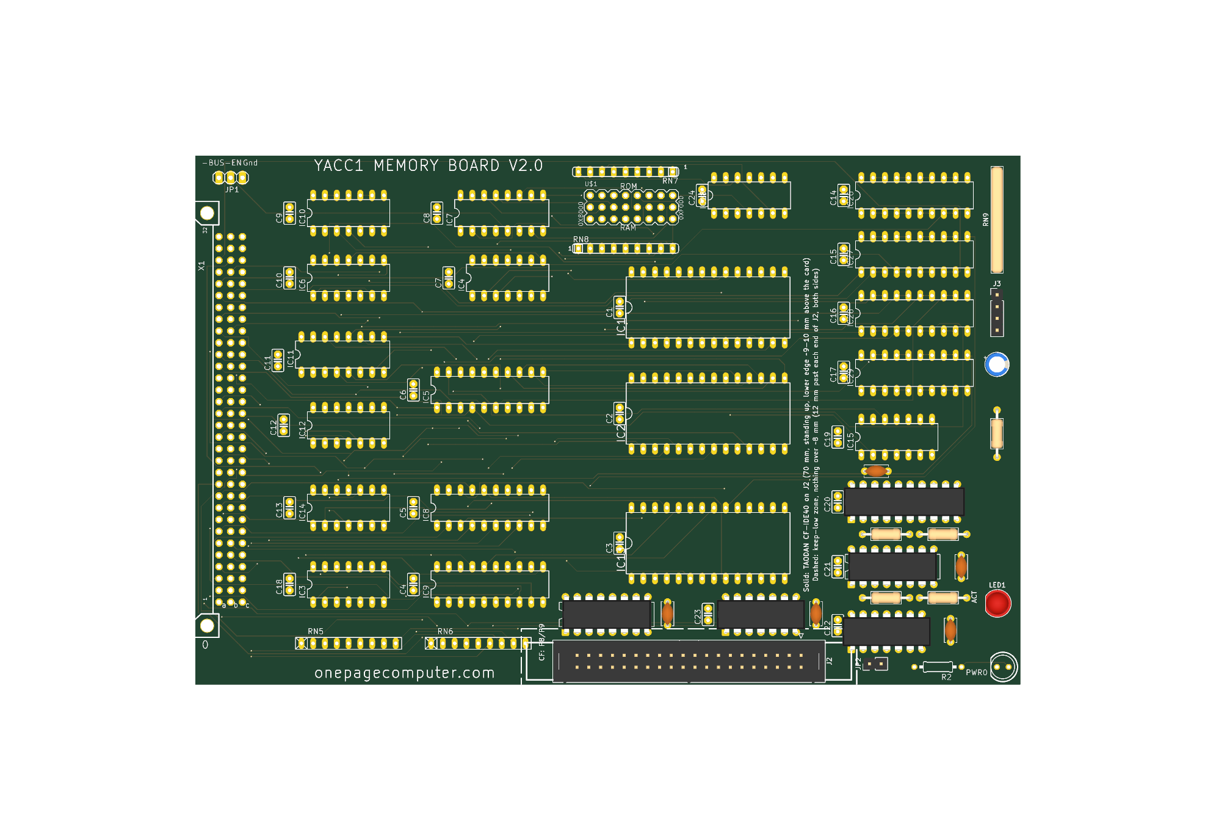
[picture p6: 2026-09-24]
hardware/cards/memory/kicad/v2.0/options-keep-copper/memory-v2.0-option-b-render-top.png

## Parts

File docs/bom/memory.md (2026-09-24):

# BOM: Memory v1.3 (built card, Fusion export)

GENERATED by `tools/gen_bom.py` on 2026-09-24 from `hardware/cards/memory/eagle/v1.3/Memory V1.3.sch` (Eagle 9.7.0) - do not edit; edit the schematic and re-run `make bom`.  
Role: machine. two 62256 + 28C64, FORCE-ROM remap, TMP registers, IC15 buffer enable; eagle/deprecated/v1.3-do-not-use is an earlier save.

53 parts (20 ICs, 29 passives, 3 connectors/headers/jumpers, 1 others); 17 supply/frame symbols skipped. Value = the schematic's value attribute, or the deviceset with the Eagle technology substituted for `*` (a `*` left in a value means the schematic names no technology: the part number was never filled in).

## Parts by designator

| Designator | Value | Device (deviceset/device) | Package | Library | Technology | Class |
|---|---|---|---|---|---|---|
| C1 | C-US | C-US/025-025X050 | C025-025X050 | adafruit |  | passive |
| C2 | C-US | C-US/025-025X050 | C025-025X050 | adafruit |  | passive |
| C3 | C-US | C-US/025-025X050 | C025-025X050 | adafruit |  | passive |
| C4 | C-US | C-US/025-025X050 | C025-025X050 | adafruit |  | passive |
| C5 | C-US | C-US/025-025X050 | C025-025X050 | adafruit |  | passive |
| C6 | C-US | C-US/025-025X050 | C025-025X050 | adafruit |  | passive |
| C7 | C-US | C-US/025-025X050 | C025-025X050 | adafruit |  | passive |
| C8 | C-US | C-US/025-025X050 | C025-025X050 | adafruit |  | passive |
| C9 | C-US | C-US/025-025X050 | C025-025X050 | adafruit |  | passive |
| C10 | C-US | C-US/025-025X050 | C025-025X050 | adafruit |  | passive |
| C11 | C-US | C-US/025-025X050 | C025-025X050 | adafruit |  | passive |
| C12 | C-US | C-US/025-025X050 | C025-025X050 | adafruit |  | passive |
| C13 | C-US | C-US/025-025X050 | C025-025X050 | adafruit |  | passive |
| C14 | C-US | C-US/025-025X050 | C025-025X050 | adafruit |  | passive |
| C15 | C-US | C-US/025-025X050 | C025-025X050 | adafruit |  | passive |
| C16 | C-US | C-US/025-025X050 | C025-025X050 | adafruit |  | passive |
| C17 | C-US | C-US/025-025X050 | C025-025X050 | adafruit |  | passive |
| C18 | C-US | C-US/025-025X050 | C025-025X050 | adafruit |  | passive |
| C19 | C-US | C-US/025-025X050 | C025-025X050 | adafruit |  | passive |
| C20 | C-US | C-US/025-025X050 | C025-025X050 | adafruit |  | passive |
| C21 | C-US | C-US/025-025X050 | C025-025X050 | adafruit |  | passive |
| C22 | C-US | C-US/025-025X050 | C025-025X050 | adafruit |  | passive |
| C23 | C-US | C-US/025-025X050 | C025-025X050 | adafruit |  | passive |
| C24 | C-US | C-US/025-025X050 | C025-025X050 | adafruit |  | passive |
| IC1 | 62256P | 62256P | DIL28-6 | memory-hitachi |  | IC |
| IC2 | 62256P | 62256P | DIL28-6 | memory-hitachi |  | IC |
| IC3 | 74LS32 | 74*32/N | DIL14 | 74xx-us | LS | IC |
| IC4 | 74ALS30 | 74*30/N | DIL14 | 74xx-us | ALS | IC |
| IC5 | 74LS245 | 74*245/N | DIL20 | adafruit | LS | IC |
| IC6 | 74LS04 | 74*04/N | DIL14 | 74xx-us | LS | IC |
| IC7 | 74LS138 | 74*138/N | DIL16 | 74xx-us | LS | IC |
| IC8 | 74LS244 | 74*244/N | DIL20 | 74xx-us | LS | IC |
| IC9 | 74LS244 | 74*244/N | DIL20 | 74xx-us | LS | IC |
| IC10 | 74ALS00 | 74*00/N | DIL14 | 74xx-us | ALS | IC |
| IC11 | 74LS157 | 74*157/N | DIL16 | 74xx-us | LS | IC |
| IC12 | 74LS74 | 74*74/N | DIL14 | 74xx-us | LS | IC |
| IC13 | 28C64C | 28C64C | DIL28-6 | memory-nec |  | IC |
| IC14 | 74LS04 | 74*04/N | DIL14 | 74xx-us | LS | IC |
| IC15 | 74ALS11 | 74*11/N | DIL14 | 74xx-us | ALS | IC |
| IC18 | 74ALS30 | 74*30/N | DIL14 | 74xx-us | ALS | IC |
| IC26 | 74LS374 | 74*374/N | DIL20 | 74xx-us | LS | IC |
| IC27 | 74LS374 | 74*374/N | DIL20 | 74xx-us | LS | IC |
| IC28 | 74LS374 | 74*374/N | DIL20 | 74xx-us | LS | IC |
| IC29 | 74LS374 | 74*374/N | DIL20 | 74xx-us | LS | IC |
| JP1 | PINHD-1X3 | PINHD-1X3 | 1X03 | pinhead |  | connector |
| PWR | LED | LED/5MM | LED5MM | led |  | other |
| R2 | 330 | R/0207/10 | 0207/10 | eagle-ltspice |  | passive |
| RN5 | RNX8 | RNX8 | RN-9 | resistor-net |  | passive |
| RN6 | RNX8 | RNX8 | RN-9 | resistor-net |  | passive |
| RN7 | G08R | G08R | SIL9 | resistor-sil |  | passive |
| RN8 | G08R | G08R | SIL9 | resistor-sil |  | passive |
| U$1 | PIN_3X8 | PIN_3X8 | PIN_3X8 | pinhead_3row |  | connector |
| X1 | FABC96R | FABC96R | FABC96R | con-vg |  | connector |

## Order list (value + package)

| Qty | Value | Package | Designators |
|---|---|---|---|
| 24 | C-US | C025-025X050 | C1, C2, C3, C4, C5, C6, C7, C8, C9, C10, C11, C12, C13, C14, C15, C16, C17, C18, C19, C20, C21, C22, C23, C24 |
| 4 | 74LS374 | DIL20 | IC26, IC27, IC28, IC29 |
| 2 | 62256P | DIL28-6 | IC1, IC2 |
| 2 | 74ALS30 | DIL14 | IC4, IC18 |
| 2 | 74LS04 | DIL14 | IC6, IC14 |
| 2 | 74LS244 | DIL20 | IC8, IC9 |
| 2 | G08R | SIL9 | RN7, RN8 |
| 2 | RNX8 | RN-9 | RN5, RN6 |
| 1 | 28C64C | DIL28-6 | IC13 |
| 1 | 330 | 0207/10 | R2 |
| 1 | 74ALS00 | DIL14 | IC10 |
| 1 | 74ALS11 | DIL14 | IC15 |
| 1 | 74LS138 | DIL16 | IC7 |
| 1 | 74LS157 | DIL16 | IC11 |
| 1 | 74LS245 | DIL20 | IC5 |
| 1 | 74LS32 | DIL14 | IC3 |
| 1 | 74LS74 | DIL14 | IC12 |
| 1 | FABC96R | FABC96R | X1 |
| 1 | LED | LED5MM | PWR |
| 1 | PIN_3X8 | PIN_3X8 | U$1 |
| 1 | PINHD-1X3 | 1X03 | JP1 |

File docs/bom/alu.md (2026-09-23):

# BOM: ALU V3.2

GENERATED by `tools/gen_bom.py` on 2026-09-23 from `hardware/cards/alu/eagle/v3.2/ALU V3.2.sch` (Eagle 9.6.2) - do not edit; edit the schematic and re-run `make bom`.  
Role: machine.

86 parts (39 ICs, 42 passives, 4 connectors/headers/jumpers, 1 others); 26 supply/frame symbols skipped. Value = the schematic's value attribute, or the deviceset with the Eagle technology substituted for `*` (a `*` left in a value means the schematic names no technology: the part number was never filled in).

## Parts by designator

| Designator | Value | Device (deviceset/device) | Package | Library | Technology | Class |
|---|---|---|---|---|---|---|
| C1 | .1uf | C-US/025-024X044 | C025-024X044 | rcl |  | passive |
| C2 | .1uf | C-US/025-024X044 | C025-024X044 | rcl |  | passive |
| C3 | .1uf | C-US/025-024X044 | C025-024X044 | rcl |  | passive |
| C4 | .1uf | C-US/025-024X044 | C025-024X044 | rcl |  | passive |
| C5 | .1uf | C-US/025-024X044 | C025-024X044 | rcl |  | passive |
| C6 | .1uf | C-US/025-024X044 | C025-024X044 | rcl |  | passive |
| C7 | .1uf | C-US/025-024X044 | C025-024X044 | rcl |  | passive |
| C8 | .1uf | C-US/025-024X044 | C025-024X044 | rcl |  | passive |
| C9 | .1uf | C-US/025-024X044 | C025-024X044 | rcl |  | passive |
| C10 | .1uf | C-US/025-024X044 | C025-024X044 | rcl |  | passive |
| C11 | .1uf | C-US/025-024X044 | C025-024X044 | rcl |  | passive |
| C12 | .1uf | C-US/025-024X044 | C025-024X044 | rcl |  | passive |
| C13 | .1uf | C-US/025-024X044 | C025-024X044 | rcl |  | passive |
| C14 | .1uf | C-US/025-024X044 | C025-024X044 | rcl |  | passive |
| C15 | .1uf | C-US/025-024X044 | C025-024X044 | rcl |  | passive |
| C16 | .1uf | C-US/025-024X044 | C025-024X044 | rcl |  | passive |
| C17 | .1uf | C-US/025-024X044 | C025-024X044 | rcl |  | passive |
| C18 | .1uf | C-US/025-024X044 | C025-024X044 | rcl |  | passive |
| C19 | .1uf | C-US/025-024X044 | C025-024X044 | rcl |  | passive |
| C20 | .1uf | C-US/025-024X044 | C025-024X044 | rcl |  | passive |
| C21 | ,1uf | C-US/025-024X044 | C025-024X044 | rcl |  | passive |
| C22 | .1uf | C-US/025-024X044 | C025-024X044 | rcl |  | passive |
| C23 | .1uf | C-US/025-024X044 | C025-024X044 | rcl |  | passive |
| C24 | .1uf | C-US/025-024X044 | C025-024X044 | rcl |  | passive |
| C25 | .1uf | C-US/025-024X044 | C025-024X044 | rcl |  | passive |
| C26 | .1uf | C-US/025-024X044 | C025-024X044 | rcl |  | passive |
| C27 | .1uf | C-US/025-024X044 | C025-024X044 | rcl |  | passive |
| C28 | .1uf | C-US/025-024X044 | C025-024X044 | rcl |  | passive |
| C29 | .1uf | C-US/025-024X044 | C025-024X044 | rcl |  | passive |
| C30 | .1uf | C-US/025-024X044 | C025-024X044 | rcl |  | passive |
| C31 | .1uf | C-US/025-024X044 | C025-024X044 | rcl |  | passive |
| C32 | .1uf | C-US/025-024X044 | C025-024X044 | rcl |  | passive |
| C33 | .1uf | C-US/025-024X044 | C025-024X044 | rcl |  | passive |
| C34 | .1uf | C-US/025-024X044 | C025-024X044 | rcl |  | passive |
| C35 | .1uf | C-US/025-024X044 | C025-024X044 | rcl |  | passive |
| C36 | .1uf | C-US/025-024X044 | C025-024X044 | rcl |  | passive |
| C37 | .1uf | C-US/025-024X044 | C025-024X044 | rcl |  | passive |
| C38 | .1uf | C-US/025-024X044 | C025-024X044 | rcl |  | passive |
| C39 | .1uf | C-US/025-024X044 | C025-024X044 | rcl |  | passive |
| IC1 | 74ALS04 | 74*04/N | DIL14 | 74xx-us | ALS | IC |
| IC2 | 74LS240 | 74*240/N | DIL20 | 74xx-us | LS | IC |
| IC3 | 74LS244 | 74*244/N | DIL20 | 74xx-us | LS | IC |
| IC4 | 74LS00 | 74*00/N | DIL14 | 74xx-us | LS | IC |
| IC5 | 74LS374 | 74*374/N | DIL20 | 74xx-us | LS | IC |
| IC6 | 74ALS08 | 74*08/N | DIL14 | 74xx-us | ALS | IC |
| IC7 | 74LS32 | 74*32/N | DIL14 | 74xx-us | LS | IC |
| IC8 | 74LS138 | 74*138/N | DIL16 | 74xx-us | LS | IC |
| IC9 | 74LS74 | 74*74/N | DIL14 | 74xx-us | LS | IC |
| IC10 | 74LS245 | 74*245/N | DIL20 | 74xx-us | LS | IC |
| IC11 | 74LS245 | 74*245/N | DIL20 | 74xx-us | LS | IC |
| IC12 | 74LS244 | 74*244/N | DIL20 | 74xx-us | LS | IC |
| IC13 | 74LS244 | 74*244/N | DIL20 | 74xx-us | LS | IC |
| IC14 | 74LS86 | 74*86/N | DIL14 | 74xx-us | LS | IC |
| IC15 | 74LS86 | 74*86/N | DIL14 | 74xx-us | LS | IC |
| IC16 | 74LS244 | 74*244/N | DIL20 | 74xx-us | LS | IC |
| IC17 | 74LS244 | 74*244/N | DIL20 | 74xx-us | LS | IC |
| IC18 | 74LS08 | 74*08/N | DIL14 | 74xx-us | LS | IC |
| IC19 | 74LS08 | 74*08/N | DIL14 | 74xx-us | LS | IC |
| IC20 | 74LS244 | 74*244/N | DIL20 | 74xx-us | LS | IC |
| IC21 | 74LS32 | 74*32/N | DIL14 | 74xx-us | LS | IC |
| IC22 | 74LS32 | 74*32/N | DIL14 | 74xx-us | LS | IC |
| IC23 | 74LS244 | 74*244/N | DIL20 | 74xx-us | LS | IC |
| IC24 | 74LS85 | 74*85/N | DIL16 | 74xx-us | LS | IC |
| IC25 | 74LS85 | 74*85/N | DIL16 | 74xx-us | LS | IC |
| IC26 | 74LS251 | 74*251/N | DIL16 | 74xx-us | LS | IC |
| IC27 | 74LS86 | 74*86/N | DIL14 | 74xx-us | LS | IC |
| IC28 | 74LS153 | 74*153/N | DIL16 | 74xx-us | LS | IC |
| IC29 | 74LS194 | 74*194/N | DIL16 | 74xx-us | LS | IC |
| IC30 | 74LS194 | 74*194/N | DIL16 | 74xx-us | LS | IC |
| IC31 | 74LS244 | 74*244/N | DIL20 | 74xx-us | LS | IC |
| IC32 | 74LS153 | 74*153/N | DIL16 | 74xx-us | LS | IC |
| IC33 | 74LS86 | 74*86/N | DIL14 | 74xx-us | LS | IC |
| IC34 | 74LS86 | 74*86/N | DIL14 | 74xx-us | LS | IC |
| IC35 | 74LS283 | 74*283/N | DIL16 | 74xx-us | LS | IC |
| IC36 | 74LS283 | 74*283/N | DIL16 | 74xx-us | LS | IC |
| IC37 | 74LS244 | 74*244/N | DIL20 | 74xx-us | LS | IC |
| JP1 | PINHD-1X3 | PINHD-1X3 | 1X03 | pinhead |  | connector |
| JP2 | PINHD-1X3 | PINHD-1X3 | 1X03 | pinhead |  | connector |
| PWR | LED | LED/5MM | LED5MM | led |  | other |
| R1 | 330 | R/0207/10 | 0207/10 | eagle-ltspice |  | passive |
| RN1 | 10k | RNX8 | RN-9 | resistor-net |  | passive |
| RN2 | 10k | RNX8 | RN-9 | resistor-net |  | passive |
| SV1 | MA05-2 | MA05-2 | MA05-2 | con-lstb |  | connector |
| V1 | 74*4078 | 74*4078/N | DIL14 | 74ttl-din |  | IC |
| V2 | 74*4078 | 74*4078/N | DIL14 | 74ttl-din |  | IC |
| X1 | FABC96R | FABC96R | FABC96R | con-vg |  | connector |

## Order list (value + package)

| Qty | Value | Package | Designators |
|---|---|---|---|
| 38 | .1uf | C025-024X044 | C1, C2, C3, C4, C5, C6, C7, C8, C9, C10, C11, C12, C13, C14, C15, C16, C17, C18, C19, C20, C22, C23, C24, C25, C26, C27, C28, C29, C30, C31, C32, C33, C34, C35, C36, C37, C38, C39 |
| 9 | 74LS244 | DIL20 | IC3, IC12, IC13, IC16, IC17, IC20, IC23, IC31, IC37 |
| 5 | 74LS86 | DIL14 | IC14, IC15, IC27, IC33, IC34 |
| 3 | 74LS32 | DIL14 | IC7, IC21, IC22 |
| 2 | 10k | RN-9 | RN1, RN2 |
| 2 | 74*4078 | DIL14 | V1, V2 |
| 2 | 74LS08 | DIL14 | IC18, IC19 |
| 2 | 74LS153 | DIL16 | IC28, IC32 |
| 2 | 74LS194 | DIL16 | IC29, IC30 |
| 2 | 74LS245 | DIL20 | IC10, IC11 |
| 2 | 74LS283 | DIL16 | IC35, IC36 |
| 2 | 74LS85 | DIL16 | IC24, IC25 |
| 2 | PINHD-1X3 | 1X03 | JP1, JP2 |
| 1 | ,1uf | C025-024X044 | C21 |
| 1 | 330 | 0207/10 | R1 |
| 1 | 74ALS04 | DIL14 | IC1 |
| 1 | 74ALS08 | DIL14 | IC6 |
| 1 | 74LS00 | DIL14 | IC4 |
| 1 | 74LS138 | DIL16 | IC8 |
| 1 | 74LS240 | DIL20 | IC2 |
| 1 | 74LS251 | DIL16 | IC26 |
| 1 | 74LS374 | DIL20 | IC5 |
| 1 | 74LS74 | DIL14 | IC9 |
| 1 | FABC96R | FABC96R | X1 |
| 1 | LED | LED5MM | PWR |
| 1 | MA05-2 | MA05-2 | SV1 |

Values in this schematic that differ only in case, spacing or comma-vs-dot (probably the same part, check the schematic): `,1uf` / `.1uf`.

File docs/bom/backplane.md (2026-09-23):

# BOM: Backplane V2.0

GENERATED by `tools/gen_bom.py` on 2026-09-23 from `hardware/bus/backplane/eagle/v2.0/yacc2buss.sch` (Eagle 9.6.2) - do not edit; edit the schematic and re-run `make bom`.  
Role: machine. 8 slots, Bus Template V3.2 signal names.

20 parts (0 ICs, 9 passives, 10 connectors/headers/jumpers, 1 others); 36 supply/frame symbols skipped. Value = the schematic's value attribute, or the deviceset with the Eagle technology substituted for `*` (a `*` left in a value means the schematic names no technology: the part number was never filled in).

## Parts by designator

| Designator | Value | Device (deviceset/device) | Package | Library | Technology | Class |
|---|---|---|---|---|---|---|
| 5V | WIREPAD | WIREPAD/4,16O1,6 | 4,16O1,6 | wirepad |  | connector |
| C1 | CPOL-US | CPOL-US/E5-6 | E5-6 | rcl |  | passive |
| C2 | CPOL-US | CPOL-US/E5-6 | E5-6 | rcl |  | passive |
| C3 | CPOL-US | CPOL-US/E5-6 | E5-6 | rcl |  | passive |
| C4 | CPOL-US | CPOL-US/E5-6 | E5-6 | rcl |  | passive |
| C5 | CPOL-US | CPOL-US/E5-6 | E5-6 | rcl |  | passive |
| C6 | CPOL-US | CPOL-US/E5-6 | E5-6 | rcl |  | passive |
| C7 | CPOL-US | CPOL-US/E5-6 | E5-6 | rcl |  | passive |
| C8 | CPOL-US | CPOL-US/E5-6 | E5-6 | rcl |  | passive |
| GND | WIREPAD | WIREPAD/4,16O1,6 | 4,16O1,6 | wirepad |  | connector |
| PWR | LED | LED/5MM | LED5MM | led |  | other |
| R1 | 330 | R/0207/10 | 0207/10 | eagle-ltspice |  | passive |
| X1 | FABC96S | FABC96S | FABC96S | con-vg |  | connector |
| X2 | FABC96S | FABC96S | FABC96S | con-vg |  | connector |
| X3 | FABC96S | FABC96S | FABC96S | con-vg |  | connector |
| X4 | FABC96S | FABC96S | FABC96S | con-vg |  | connector |
| X5 | FABC96S | FABC96S | FABC96S | con-vg |  | connector |
| X6 | FABC96S | FABC96S | FABC96S | con-vg |  | connector |
| X7 | FABC96S | FABC96S | FABC96S | con-vg |  | connector |
| X8 | FABC96S | FABC96S | FABC96S | con-vg |  | connector |

## Order list (value + package)

| Qty | Value | Package | Designators |
|---|---|---|---|
| 8 | CPOL-US | E5-6 | C1, C2, C3, C4, C5, C6, C7, C8 |
| 8 | FABC96S | FABC96S | X1, X2, X3, X4, X5, X6, X7, X8 |
| 2 | WIREPAD | 4,16O1,6 | 5V, GND |
| 1 | 330 | 0207/10 | R1 |
| 1 | LED | LED5MM | PWR |

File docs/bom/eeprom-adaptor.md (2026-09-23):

# BOM: Sequencer EEPROM adaptor

GENERATED by `tools/gen_bom.py` on 2026-09-23 from `hardware/cards/sequencer-memory/accessories/eeprom-adaptor/eeprom adaptor.sch` (Eagle 9.6.2) - do not edit; edit the schematic and re-run `make bom`.  
Role: machine. plugs into IC9 of the sequencer-memory card, two 24Cxx.

2 parts (2 ICs, 0 passives, 0 connectors/headers/jumpers, 0 others); 0 supply/frame symbols skipped. Value = the schematic's value attribute, or the deviceset with the Eagle technology substituted for `*` (a `*` left in a value means the schematic names no technology: the part number was never filled in).

## Parts by designator

| Designator | Value | Device (deviceset/device) | Package | Library | Technology | Class |
|---|---|---|---|---|---|---|
| IC1 | AT24C* | AT24C*/P | DIL08 | atmel |  | IC |
| IC2 | AT24C* | AT24C*/P | DIL08 | atmel |  | IC |

## Order list (value + package)

| Qty | Value | Package | Designators |
|---|---|---|---|
| 2 | AT24C* | DIL08 | IC1, IC2 |

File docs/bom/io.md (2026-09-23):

# BOM: I/O V1.1

GENERATED by `tools/gen_bom.py` on 2026-09-23 from `hardware/cards/io/eagle/v1.1/IO V1.1.sch` (Eagle 9.6.2) - do not edit; edit the schematic and re-run `make bom`.  
Role: machine. UART, switch/LED port, TIL311s, LCD.

71 parts (11 ICs, 28 passives, 8 connectors/headers/jumpers, 24 others); 27 supply/frame symbols skipped. Value = the schematic's value attribute, or the deviceset with the Eagle technology substituted for `*` (a `*` left in a value means the schematic names no technology: the part number was never filled in).

## Parts by designator

| Designator | Value | Device (deviceset/device) | Package | Library | Technology | Class |
|---|---|---|---|---|---|---|
| 0 | LED | LED/5MM | LED5MM | adafruit |  | other |
| 1 | LED | LED/5MM | LED5MM | adafruit |  | other |
| 2 | LED | LED/5MM | LED5MM | adafruit |  | other |
| 3 | LED | LED/5MM | LED5MM | adafruit |  | other |
| 4 | LED | LED/5MM | LED5MM | adafruit |  | other |
| 5 | LED | LED/5MM | LED5MM | adafruit |  | other |
| 6 | LED | LED/5MM | LED5MM | adafruit |  | other |
| 7 | LED | LED/5MM | LED5MM | adafruit |  | other |
| C1 | CPOL-US | CPOL-US/E2,5-6E | E2,5-6E | rcl |  | passive |
| C2 | CPOL-US | CPOL-US/E2,5-6E | E2,5-6E | rcl |  | passive |
| C3 | CPOL-US | CPOL-US/E2,5-6E | E2,5-6E | rcl |  | passive |
| C4 | CPOL-US | CPOL-US/E2,5-6E | E2,5-6E | rcl |  | passive |
| C5 | C-US | C-US/025-024X044 | C025-024X044 | adafruit |  | passive |
| C6 | C-US | C-US/025-024X044 | C025-024X044 | adafruit |  | passive |
| C7 | C-US | C-US/025-024X044 | C025-024X044 | adafruit |  | passive |
| C8 | C-US | C-US/025-024X044 | C025-024X044 | adafruit |  | passive |
| C9 | C-US | C-US/025-024X044 | C025-024X044 | adafruit |  | passive |
| C10 | C-US | C-US/025-024X044 | C025-024X044 | adafruit |  | passive |
| C11 | C-US | C-US/025-024X044 | C025-024X044 | adafruit |  | passive |
| C12 | C-US | C-US/025-024X044 | C025-024X044 | adafruit |  | passive |
| C13 | C-US | C-US/025-024X044 | C025-024X044 | adafruit |  | passive |
| C14 | C-US | C-US/025-024X044 | C025-024X044 | adafruit |  | passive |
| C15 | C-US | C-US/025-024X044 | C025-024X044 | adafruit |  | passive |
| C16 | C-US | C-US/025-024X044 | C025-024X044 | adafruit |  | passive |
| C17 | C-US | C-US/025-024X044 | C025-024X044 | adafruit |  | passive |
| DATA-ADDR | PINHD-2X8 | PINHD-2X8 | 2X08 | pinhead |  | connector |
| HI | HTIL311A | HTIL311A | HTIL311A | display-hp |  | other |
| IC1 | XR-16C550P | XR-16C550P | DIL40 | exar |  | IC |
| IC2 | MAX232 | MAX232 | DIL16 | maxim |  | IC |
| IC3 | 74LS244 | 74*244/N | DIL20 | 74xx-us | LS | IC |
| IC4 | 74*273 | 74*273/N | DIL20 | 74xx-us |  | IC |
| IC5 | 74LS138 | 74*138/N | DIL16 | 74xx-us | LS | IC |
| IC6 | 74LS10 | 74*10/N | DIL14 | 74xx-us | LS | IC |
| IC7 | 74LS00 | 74*00/N | DIL14 | 74xx-us | LS | IC |
| IC8 | 74LS06 | 74*06/N | DIL14 | 74xx-us | LS | IC |
| IC9 | 74*273 | 74*273/N | DIL20 | 74xx-us |  | IC |
| IC10 | 74*273 | 74*273/N | DIL20 | 74xx-us |  | IC |
| IC11 | 74LS10 | 74*10/N | DIL14 | 74xx-us | LS | IC |
| IN | M9040P | M9040P | M9040P | switch |  | other |
| INPUT | PINHD-1X2 | PINHD-1X2 | 1X02 | pinhead |  | connector |
| INT | PINHD-1X2 | PINHD-1X2 | 1X02 | pinhead |  | connector |
| IO-ADDR | PINHD-2X8 | PINHD-2X8 | 2X08 | pinhead |  | connector |
| IO-ADDR-HL | PINHD-2X3 | PINHD-2X3 | 2X03 | pinhead |  | connector |
| J1 | DB9 | DB9/FEMALE | DB9 | SparkFun-Connectors |  | connector |
| JP1 | PINHD-2X3 | PINHD-2X3 | 2X03 | Connector |  | connector |
| LO | HTIL311A | HTIL311A | HTIL311A | display-hp |  | other |
| OUT | LED | LED/5MM | LED5MM | adafruit |  | other |
| PWR | LED | LED/5MM | LED5MM | led |  | other |
| R1 | R-US_ | R-US_/0207/10 | 0207/10 | rcl |  | passive |
| R2 | 330 | R/0207/10 | 0207/10 | eagle-ltspice |  | passive |
| R3 | R-US_ | R-US_/0207/10 | 0207/10 | rcl |  | passive |
| R4 | R-US_ | R-US_/0207/10 | 0207/10 | rcl |  | passive |
| R5 | R-US_ | R-US_/0207/10 | 0207/10 | rcl |  | passive |
| R6 | R-US_ | R-US_/0207/10 | 0207/10 | rcl |  | passive |
| R7 | R-US_ | R-US_/0207/10 | 0207/10 | rcl |  | passive |
| R8 | R-US_ | R-US_/0207/10 | 0207/10 | rcl |  | passive |
| R9 | R-US_ | R-US_/0207/10 | 0207/10 | rcl |  | passive |
| R10 | R-US_ | R-US_/0207/10 | 0207/10 | rcl |  | passive |
| RN2 | RNX6 | RNX6 | RN-7 | resistor-net |  | passive |
| S0 | M9040P | M9040P | M9040P | switch |  | other |
| S1 | M9040P | M9040P | M9040P | switch |  | other |
| S2 | M9040P | M9040P | M9040P | switch |  | other |
| S3 | M9040P | M9040P | M9040P | switch |  | other |
| S4 | M9040P | M9040P | M9040P | switch |  | other |
| S5 | M9040P | M9040P | M9040P | switch |  | other |
| S6 | M9040P | M9040P | M9040P | switch |  | other |
| S7 | M9040P | M9040P | M9040P | switch |  | other |
| TM1 | 10k | TRIMPOT/3386 | TRIM-3386 | adafruit |  | other |
| X1 | FABC96R | FABC96R | FABC96R | con-vg |  | connector |
| X2 | HD44780LCD | HD44780LCD/-1602 | LCD1602 | adafruit |  | other |
| Y1 | ECS-2100AX-200 | ECS-2100AX-200 | ECS-2100AX-200 | Crystals_Oscillators |  | other |

## Order list (value + package)

| Qty | Value | Package | Designators |
|---|---|---|---|
| 13 | C-US | C025-024X044 | C5, C6, C7, C8, C9, C10, C11, C12, C13, C14, C15, C16, C17 |
| 10 | LED | LED5MM | 0, 1, 2, 3, 4, 5, 6, 7, OUT, PWR |
| 9 | M9040P | M9040P | IN, S0, S1, S2, S3, S4, S5, S6, S7 |
| 9 | R-US_ | 0207/10 | R1, R3, R4, R5, R6, R7, R8, R9, R10 |
| 4 | CPOL-US | E2,5-6E | C1, C2, C3, C4 |
| 3 | 74*273 | DIL20 | IC4, IC9, IC10 |
| 2 | 74LS10 | DIL14 | IC6, IC11 |
| 2 | HTIL311A | HTIL311A | HI, LO |
| 2 | PINHD-1X2 | 1X02 | INPUT, INT |
| 2 | PINHD-2X3 | 2X03 | IO-ADDR-HL, JP1 |
| 2 | PINHD-2X8 | 2X08 | DATA-ADDR, IO-ADDR |
| 1 | 10k | TRIM-3386 | TM1 |
| 1 | 330 | 0207/10 | R2 |
| 1 | 74LS00 | DIL14 | IC7 |
| 1 | 74LS06 | DIL14 | IC8 |
| 1 | 74LS138 | DIL16 | IC5 |
| 1 | 74LS244 | DIL20 | IC3 |
| 1 | DB9 | DB9 | J1 |
| 1 | ECS-2100AX-200 | ECS-2100AX-200 | Y1 |
| 1 | FABC96R | FABC96R | X1 |
| 1 | HD44780LCD | LCD1602 | X2 |
| 1 | MAX232 | DIL16 | IC2 |
| 1 | RNX6 | RN-7 | RN2 |
| 1 | XR-16C550P | DIL40 | IC1 |

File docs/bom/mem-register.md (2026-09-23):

# BOM: Mem Register V1.0 (bring-up)

GENERATED by `tools/gen_bom.py` on 2026-09-23 from `hardware/cards/mem-register/eagle/v1.0/Mem Register V1.0.sch` (Eagle 9.6.2) - do not edit; edit the schematic and re-run `make bom`.  
Role: bench. 16-byte RAM at $0010.

90 parts (24 ICs, 30 passives, 2 connectors/headers/jumpers, 34 others); 12 supply/frame symbols skipped. Value = the schematic's value attribute, or the deviceset with the Eagle technology substituted for `*` (a `*` left in a value means the schematic names no technology: the part number was never filled in).

## Parts by designator

| Designator | Value | Device (deviceset/device) | Package | Library | Technology | Class |
|---|---|---|---|---|---|---|
| BRD-SEL | PINHD-1X1 | PINHD-1X1 | 1X01 | Connector |  | connector |
| C1 | C-US | C-US/025-025X050 | C025-025X050 | rcl |  | passive |
| C2 | C-US | C-US/025-025X050 | C025-025X050 | rcl |  | passive |
| C3 | C-US | C-US/025-025X050 | C025-025X050 | rcl |  | passive |
| C4 | C-US | C-US/025-025X050 | C025-025X050 | rcl |  | passive |
| C5 | C-US | C-US/025-025X050 | C025-025X050 | rcl |  | passive |
| C6 | C-US | C-US/025-025X050 | C025-025X050 | rcl |  | passive |
| C7 | C-US | C-US/025-025X050 | C025-025X050 | rcl |  | passive |
| C8 | C-US | C-US/025-025X050 | C025-025X050 | rcl |  | passive |
| C9 | C-US | C-US/025-025X050 | C025-025X050 | rcl |  | passive |
| C10 | C-US | C-US/025-025X050 | C025-025X050 | rcl |  | passive |
| C11 | C-US | C-US/025-025X050 | C025-025X050 | rcl |  | passive |
| C12 | C-US | C-US/025-025X050 | C025-025X050 | rcl |  | passive |
| C13 | C-US | C-US/025-025X050 | C025-025X050 | rcl |  | passive |
| C14 | C-US | C-US/025-025X050 | C025-025X050 | rcl |  | passive |
| C15 | C-US | C-US/025-025X050 | C025-025X050 | rcl |  | passive |
| C16 | C-US | C-US/025-025X050 | C025-025X050 | rcl |  | passive |
| C17 | C-US | C-US/025-025X050 | C025-025X050 | rcl |  | passive |
| C18 | C-US | C-US/025-025X050 | C025-025X050 | rcl |  | passive |
| C19 | C-US | C-US/025-025X050 | C025-025X050 | rcl |  | passive |
| C20 | C-US | C-US/025-025X050 | C025-025X050 | rcl |  | passive |
| C21 | C-US | C-US/025-025X050 | C025-025X050 | rcl |  | passive |
| C22 | C-US | C-US/025-025X050 | C025-025X050 | rcl |  | passive |
| C23 | C-US | C-US/025-025X050 | C025-025X050 | rcl |  | passive |
| C24 | C-US | C-US/025-025X050 | C025-025X050 | rcl |  | passive |
| IC1 | 74ALS27 | 74*27/N | DIL14 | 74xx-us | ALS | IC |
| IC2 | 74LS138 | 74*138/N | DIL16 | 74xx-us | LS | IC |
| IC3 | 74LS138 | 74*138/N | DIL16 | 74xx-us | LS | IC |
| IC4 | 74LS85 | 74*85/N | DIL16 | 74xx-us | LS | IC |
| IC5 | 74LS138 | 74*138/N | DIL16 | 74xx-us | LS | IC |
| IC6 | 74LS138 | 74*138/N | DIL16 | 74xx-us | LS | IC |
| IC7 | 74ALS27 | 74*27/N | DIL14 | 74xx-us | ALS | IC |
| IC8 | 74LS374 | 74*374/N | DIL20 | 74xx-us | LS | IC |
| IC9 | 74LS374 | 74*374/N | DIL20 | 74xx-us | LS | IC |
| IC10 | 74LS374 | 74*374/N | DIL20 | 74xx-us | LS | IC |
| IC11 | 74LS374 | 74*374/N | DIL20 | 74xx-us | LS | IC |
| IC12 | 74LS374 | 74*374/N | DIL20 | 74xx-us | LS | IC |
| IC13 | 74LS374 | 74*374/N | DIL20 | 74xx-us | LS | IC |
| IC14 | 74LS374 | 74*374/N | DIL20 | 74xx-us | LS | IC |
| IC15 | 74LS374 | 74*374/N | DIL20 | 74xx-us | LS | IC |
| IC16 | 74LS374 | 74*374/N | DIL20 | 74xx-us | LS | IC |
| IC17 | 74LS374 | 74*374/N | DIL20 | 74xx-us | LS | IC |
| IC18 | 74LS374 | 74*374/N | DIL20 | 74xx-us | LS | IC |
| IC19 | 74LS374 | 74*374/N | DIL20 | 74xx-us | LS | IC |
| IC20 | 74LS374 | 74*374/N | DIL20 | 74xx-us | LS | IC |
| IC21 | 74LS374 | 74*374/N | DIL20 | 74xx-us | LS | IC |
| IC22 | 74LS374 | 74*374/N | DIL20 | 74xx-us | LS | IC |
| IC23 | 74LS374 | 74*374/N | DIL20 | 74xx-us | LS | IC |
| PWR | LED | LED/5MM | LED5MM | led |  | other |
| R1 | 330 | R/0207/10 | 0207/10 | eagle-ltspice |  | passive |
| RD1 | LED | LED/3MM | LED3MM | adafruit |  | other |
| RD2 | LED | LED/3MM | LED3MM | adafruit |  | other |
| RD3 | LED | LED/3MM | LED3MM | adafruit |  | other |
| RD4 | LED | LED/3MM | LED3MM | adafruit |  | other |
| RD5 | LED | LED/3MM | LED3MM | adafruit |  | other |
| RD6 | LED | LED/3MM | LED3MM | adafruit |  | other |
| RD7 | LED | LED/3MM | LED3MM | adafruit |  | other |
| RD8 | LED | LED/3MM | LED3MM | adafruit |  | other |
| RD9 | LED | LED/3MM | LED3MM | adafruit |  | other |
| RD10 | LED | LED/3MM | LED3MM | adafruit |  | other |
| RD11 | LED | LED/3MM | LED3MM | adafruit |  | other |
| RD12 | LED | LED/3MM | LED3MM | adafruit |  | other |
| RD13 | LED | LED/3MM | LED3MM | adafruit |  | other |
| RD14 | LED | LED/3MM | LED3MM | adafruit |  | other |
| RD15 | LED | LED/3MM | LED3MM | adafruit |  | other |
| RD16 | LED | LED/3MM | LED3MM | adafruit |  | other |
| RN1 | G04R | G04R | SIL5 | resistor-sil |  | passive |
| RN2 | G08R | G08R | SIL9 | resistor-sil |  | passive |
| RN3 | G08R | G08R | SIL9 | resistor-sil |  | passive |
| RN4 | G08R | G08R | SIL9 | resistor-sil |  | passive |
| RN5 | G08R | G08R | SIL9 | resistor-sil |  | passive |
| SW1 | SW_DIP-4 | SW_DIP-4 | EDG-04 | special |  | other |
| V1 | 74*4078 | 74*4078/N | DIL14 | 74ttl-din |  | IC |
| WR1 | LED | LED/3MM | LED3MM | adafruit |  | other |
| WR2 | LED | LED/3MM | LED3MM | adafruit |  | other |
| WR3 | LED | LED/3MM | LED3MM | adafruit |  | other |
| WR4 | LED | LED/3MM | LED3MM | adafruit |  | other |
| WR5 | LED | LED/3MM | LED3MM | adafruit |  | other |
| WR6 | LED | LED/3MM | LED3MM | adafruit |  | other |
| WR7 | LED | LED/3MM | LED3MM | adafruit |  | other |
| WR8 | LED | LED/3MM | LED3MM | adafruit |  | other |
| WR9 | LED | LED/3MM | LED3MM | adafruit |  | other |
| WR10 | LED | LED/3MM | LED3MM | adafruit |  | other |
| WR11 | LED | LED/3MM | LED3MM | adafruit |  | other |
| WR12 | LED | LED/3MM | LED3MM | adafruit |  | other |
| WR13 | LED | LED/3MM | LED3MM | adafruit |  | other |
| WR14 | LED | LED/3MM | LED3MM | adafruit |  | other |
| WR15 | LED | LED/3MM | LED3MM | adafruit |  | other |
| WR16 | LED | LED/3MM | LED3MM | adafruit |  | other |
| X1 | FABC96R | FABC96R | FABC96R | con-vg |  | connector |

## Order list (value + package)

| Qty | Value | Package | Designators |
|---|---|---|---|
| 32 | LED | LED3MM | RD1, RD2, RD3, RD4, RD5, RD6, RD7, RD8, RD9, RD10, RD11, RD12, RD13, RD14, RD15, RD16, WR1, WR2, WR3, WR4, WR5, WR6, WR7, WR8, WR9, WR10, WR11, WR12, WR13, WR14, WR15, WR16 |
| 24 | C-US | C025-025X050 | C1, C2, C3, C4, C5, C6, C7, C8, C9, C10, C11, C12, C13, C14, C15, C16, C17, C18, C19, C20, C21, C22, C23, C24 |
| 16 | 74LS374 | DIL20 | IC8, IC9, IC10, IC11, IC12, IC13, IC14, IC15, IC16, IC17, IC18, IC19, IC20, IC21, IC22, IC23 |
| 4 | 74LS138 | DIL16 | IC2, IC3, IC5, IC6 |
| 4 | G08R | SIL9 | RN2, RN3, RN4, RN5 |
| 2 | 74ALS27 | DIL14 | IC1, IC7 |
| 1 | 330 | 0207/10 | R1 |
| 1 | 74*4078 | DIL14 | V1 |
| 1 | 74LS85 | DIL16 | IC4 |
| 1 | FABC96R | FABC96R | X1 |
| 1 | G04R | SIL5 | RN1 |
| 1 | LED | LED5MM | PWR |
| 1 | PINHD-1X1 | 1X01 | BRD-SEL |
| 1 | SW_DIP-4 | EDG-04 | SW1 |

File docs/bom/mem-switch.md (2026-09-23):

# BOM: Mem Switch V1.1 (bring-up)

GENERATED by `tools/gen_bom.py` on 2026-09-23 from `hardware/cards/mem-switch/eagle/v1.1/Mem Switch V1.1.sch` (Eagle 9.6.2) - do not edit; edit the schematic and re-run `make bom`.  
Role: bench. 16-byte switch ROM at $0000.

112 parts (21 ICs, 55 passives, 2 connectors/headers/jumpers, 34 others); 56 supply/frame symbols skipped. Value = the schematic's value attribute, or the deviceset with the Eagle technology substituted for `*` (a `*` left in a value means the schematic names no technology: the part number was never filled in).

## Parts by designator

| Designator | Value | Device (deviceset/device) | Package | Library | Technology | Class |
|---|---|---|---|---|---|---|
| 0000 | SW_DIP-8 | SW_DIP-8 | EDG-08 | special |  | other |
| 0001 | SW_DIP-8 | SW_DIP-8 | EDG-08 | special |  | other |
| 0010 | SW_DIP-8 | SW_DIP-8 | EDG-08 | special |  | other |
| 0011 | SW_DIP-8 | SW_DIP-8 | EDG-08 | special |  | other |
| 0100 | SW_DIP-8 | SW_DIP-8 | EDG-08 | special |  | other |
| 0101 | SW_DIP-8 | SW_DIP-8 | EDG-08 | special |  | other |
| 0110 | SW_DIP-8 | SW_DIP-8 | EDG-08 | special |  | other |
| 0111 | SW_DIP-8 | SW_DIP-8 | EDG-08 | special |  | other |
| 1000 | SW_DIP-8 | SW_DIP-8 | EDG-08 | special |  | other |
| 1001 | SW_DIP-8 | SW_DIP-8 | EDG-08 | special |  | other |
| 1010 | SW_DIP-8 | SW_DIP-8 | EDG-08 | special |  | other |
| 1011 | SW_DIP-8 | SW_DIP-8 | EDG-08 | special |  | other |
| 1100 | SW_DIP-8 | SW_DIP-8 | EDG-08 | special |  | other |
| 1101 | SW_DIP-8 | SW_DIP-8 | EDG-08 | special |  | other |
| 1110 | SW_DIP-8 | SW_DIP-8 | EDG-08 | special |  | other |
| 1111 | SW_DIP-8 | SW_DIP-8 | EDG-08 | special |  | other |
| BRD-SEL | PINHD-1X1 | PINHD-1X1 | 1X01 | Connector |  | connector |
| C1 | C-US | C-US/025-025X050 | C025-025X050 | rcl |  | passive |
| C2 | C-US | C-US/025-025X050 | C025-025X050 | rcl |  | passive |
| C3 | C-US | C-US/025-025X050 | C025-025X050 | rcl |  | passive |
| C4 | C-US | C-US/025-025X050 | C025-025X050 | rcl |  | passive |
| C5 | C-US | C-US/025-025X050 | C025-025X050 | rcl |  | passive |
| C6 | C-US | C-US/025-025X050 | C025-025X050 | rcl |  | passive |
| C7 | C-US | C-US/025-025X050 | C025-025X050 | rcl |  | passive |
| C8 | C-US | C-US/025-025X050 | C025-025X050 | rcl |  | passive |
| C9 | C-US | C-US/025-025X050 | C025-025X050 | rcl |  | passive |
| C10 | C-US | C-US/025-025X050 | C025-025X050 | rcl |  | passive |
| C11 | C-US | C-US/025-025X050 | C025-025X050 | rcl |  | passive |
| C12 | C-US | C-US/025-025X050 | C025-025X050 | rcl |  | passive |
| C13 | C-US | C-US/025-025X050 | C025-025X050 | rcl |  | passive |
| C14 | C-US | C-US/025-025X050 | C025-025X050 | rcl |  | passive |
| C15 | C-US | C-US/025-025X050 | C025-025X050 | rcl |  | passive |
| C16 | C-US | C-US/025-025X050 | C025-025X050 | rcl |  | passive |
| C17 | C-US | C-US/025-025X050 | C025-025X050 | rcl |  | passive |
| C18 | C-US | C-US/025-025X050 | C025-025X050 | rcl |  | passive |
| C19 | C-US | C-US/025-025X050 | C025-025X050 | rcl |  | passive |
| C20 | C-US | C-US/025-025X050 | C025-025X050 | rcl |  | passive |
| C21 | C-US | C-US/025-025X050 | C025-025X050 | rcl |  | passive |
| IC1 | 74ALS27 | 74*27/N | DIL14 | 74xx-us | ALS | IC |
| IC2 | 74LS138 | 74*138/N | DIL16 | 74xx-us | LS | IC |
| IC3 | 74LS138 | 74*138/N | DIL16 | 74xx-us | LS | IC |
| IC4 | 74LS85 | 74*85/N | DIL16 | 74xx-us | LS | IC |
| IC5 | 74LS244 | 74*244/N | DIL20 | 74xx-us | LS | IC |
| IC6 | 74LS244 | 74*244/N | DIL20 | 74xx-us | LS | IC |
| IC7 | 74LS244 | 74*244/N | DIL20 | 74xx-us | LS | IC |
| IC8 | 74LS244 | 74*244/N | DIL20 | 74xx-us | LS | IC |
| IC9 | 74LS244 | 74*244/N | DIL20 | 74xx-us | LS | IC |
| IC10 | 74LS244 | 74*244/N | DIL20 | 74xx-us | LS | IC |
| IC11 | 74LS244 | 74*244/N | DIL20 | 74xx-us | LS | IC |
| IC12 | 74LS244 | 74*244/N | DIL20 | 74xx-us | LS | IC |
| IC13 | 74LS244 | 74*244/N | DIL20 | 74xx-us | LS | IC |
| IC14 | 74LS244 | 74*244/N | DIL20 | 74xx-us | LS | IC |
| IC15 | 74LS244 | 74*244/N | DIL20 | 74xx-us | LS | IC |
| IC16 | 74LS244 | 74*244/N | DIL20 | 74xx-us | LS | IC |
| IC17 | 74LS244 | 74*244/N | DIL20 | 74xx-us | LS | IC |
| IC18 | 74LS244 | 74*244/N | DIL20 | 74xx-us | LS | IC |
| IC19 | 74LS244 | 74*244/N | DIL20 | 74xx-us | LS | IC |
| IC20 | 74LS244 | 74*244/N | DIL20 | 74xx-us | LS | IC |
| PWR | LED | LED/5MM | LED5MM | led |  | other |
| R1 | R-US_ | R-US_/0207/10 | 0207/10 | adafruit |  | passive |
| R2 | R-US_ | R-US_/0207/10 | 0207/10 | adafruit |  | passive |
| R3 | R-US_ | R-US_/0207/10 | 0207/10 | adafruit |  | passive |
| R4 | R-US_ | R-US_/0207/10 | 0207/10 | adafruit |  | passive |
| R5 | R-US_ | R-US_/0207/10 | 0207/10 | adafruit |  | passive |
| R6 | R-US_ | R-US_/0207/10 | 0207/10 | adafruit |  | passive |
| R7 | R-US_ | R-US_/0207/10 | 0207/10 | adafruit |  | passive |
| R8 | R-US_ | R-US_/0207/10 | 0207/10 | adafruit |  | passive |
| R9 | R-US_ | R-US_/0207/10 | 0207/10 | adafruit |  | passive |
| R10 | R-US_ | R-US_/0207/10 | 0207/10 | adafruit |  | passive |
| R11 | R-US_ | R-US_/0207/10 | 0207/10 | adafruit |  | passive |
| R12 | R-US_ | R-US_/0207/10 | 0207/10 | adafruit |  | passive |
| R13 | R-US_ | R-US_/0207/10 | 0207/10 | adafruit |  | passive |
| R14 | R-US_ | R-US_/0207/10 | 0207/10 | adafruit |  | passive |
| R15 | R-US_ | R-US_/0207/10 | 0207/10 | adafruit |  | passive |
| R16 | R-US_ | R-US_/0207/10 | 0207/10 | adafruit |  | passive |
| R17 | 330 | R/0207/10 | 0207/10 | eagle-ltspice |  | passive |
| RD0 | LED | LED/3MM | LED3MM | adafruit |  | other |
| RD1 | LED | LED/3MM | LED3MM | adafruit |  | other |
| RD2 | LED | LED/3MM | LED3MM | adafruit |  | other |
| RD3 | LED | LED/3MM | LED3MM | adafruit |  | other |
| RD4 | LED | LED/3MM | LED3MM | adafruit |  | other |
| RD5 | LED | LED/3MM | LED3MM | adafruit |  | other |
| RD6 | LED | LED/3MM | LED3MM | adafruit |  | other |
| RD7 | LED | LED/3MM | LED3MM | adafruit |  | other |
| RD8 | LED | LED/3MM | LED3MM | adafruit |  | other |
| RD9 | LED | LED/3MM | LED3MM | adafruit |  | other |
| RD10 | LED | LED/3MM | LED3MM | adafruit |  | other |
| RD11 | LED | LED/3MM | LED3MM | adafruit |  | other |
| RD12 | LED | LED/3MM | LED3MM | adafruit |  | other |
| RD13 | LED | LED/3MM | LED3MM | adafruit |  | other |
| RD14 | LED | LED/3MM | LED3MM | adafruit |  | other |
| RD15 | LED | LED/3MM | LED3MM | adafruit |  | other |
| RN1 | G04R | G04R | SIL5 | resistor-sil |  | passive |
| RN2 | G08R | G08R | SIL9 | resistor-sil |  | passive |
| RN3 | G08R | G08R | SIL9 | resistor-sil |  | passive |
| RN4 | G08R | G08R | SIL9 | resistor-sil |  | passive |
| RN5 | G08R | G08R | SIL9 | resistor-sil |  | passive |
| RN6 | G08R | G08R | SIL9 | resistor-sil |  | passive |
| RN7 | G08R | G08R | SIL9 | resistor-sil |  | passive |
| RN8 | G08R | G08R | SIL9 | resistor-sil |  | passive |
| RN9 | G08R | G08R | SIL9 | resistor-sil |  | passive |
| RN10 | G08R | G08R | SIL9 | resistor-sil |  | passive |
| RN11 | G08R | G08R | SIL9 | resistor-sil |  | passive |
| RN12 | G08R | G08R | SIL9 | resistor-sil |  | passive |
| RN13 | G08R | G08R | SIL9 | resistor-sil |  | passive |
| RN14 | G08R | G08R | SIL9 | resistor-sil |  | passive |
| RN15 | G08R | G08R | SIL9 | resistor-sil |  | passive |
| RN16 | G08R | G08R | SIL9 | resistor-sil |  | passive |
| RN17 | G08R | G08R | SIL9 | resistor-sil |  | passive |
| SW1 | SW_DIP-4 | SW_DIP-4 | EDG-04 | special |  | other |
| V1 | 74*4078 | 74*4078/N | DIL14 | 74ttl-din |  | IC |
| X1 | FABC96R | FABC96R | FABC96R | con-vg |  | connector |

## Order list (value + package)

| Qty | Value | Package | Designators |
|---|---|---|---|
| 21 | C-US | C025-025X050 | C1, C2, C3, C4, C5, C6, C7, C8, C9, C10, C11, C12, C13, C14, C15, C16, C17, C18, C19, C20, C21 |
| 16 | 74LS244 | DIL20 | IC5, IC6, IC7, IC8, IC9, IC10, IC11, IC12, IC13, IC14, IC15, IC16, IC17, IC18, IC19, IC20 |
| 16 | G08R | SIL9 | RN2, RN3, RN4, RN5, RN6, RN7, RN8, RN9, RN10, RN11, RN12, RN13, RN14, RN15, RN16, RN17 |
| 16 | LED | LED3MM | RD0, RD1, RD2, RD3, RD4, RD5, RD6, RD7, RD8, RD9, RD10, RD11, RD12, RD13, RD14, RD15 |
| 16 | R-US_ | 0207/10 | R1, R2, R3, R4, R5, R6, R7, R8, R9, R10, R11, R12, R13, R14, R15, R16 |
| 16 | SW_DIP-8 | EDG-08 | 0000, 0001, 0010, 0011, 0100, 0101, 0110, 0111, 1000, 1001, 1010, 1011, 1100, 1101, 1110, 1111 |
| 2 | 74LS138 | DIL16 | IC2, IC3 |
| 1 | 330 | 0207/10 | R17 |
| 1 | 74*4078 | DIL14 | V1 |
| 1 | 74ALS27 | DIL14 | IC1 |
| 1 | 74LS85 | DIL16 | IC4 |
| 1 | FABC96R | FABC96R | X1 |
| 1 | G04R | SIL5 | RN1 |
| 1 | LED | LED5MM | PWR |
| 1 | PINHD-1X1 | 1X01 | BRD-SEL |
| 1 | SW_DIP-4 | EDG-04 | SW1 |

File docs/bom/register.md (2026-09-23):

# BOM: Index Registers 1.1

GENERATED by `tools/gen_bom.py` on 2026-09-23 from `hardware/cards/register/eagle/v1.1/Index Registers - 1.1.sch` (Eagle 9.6.2) - do not edit; edit the schematic and re-run `make bom`.  
Role: machine x2 in the machine. two cards: R0-R3 and R4-R7 (J3 selects the card).

102 parts (47 ICs, 50 passives, 4 connectors/headers/jumpers, 1 others); 16 supply/frame symbols skipped. Value = the schematic's value attribute, or the deviceset with the Eagle technology substituted for `*` (a `*` left in a value means the schematic names no technology: the part number was never filled in).

## Parts by designator

| Designator | Value | Device (deviceset/device) | Package | Library | Technology | Class |
|---|---|---|---|---|---|---|
| C1 | 0.1 | C-US/025-040X050 | C025-040X050 | resistor |  | passive |
| C2 | 0.1 | C-US/025-040X050 | C025-040X050 | resistor |  | passive |
| C3 | 0.1 | C-US/025-040X050 | C025-040X050 | resistor |  | passive |
| C4 | 0.1 | C-US/025-040X050 | C025-040X050 | resistor |  | passive |
| C5 | 0.1 | C-US/025-040X050 | C025-040X050 | resistor |  | passive |
| C6 | 0.1 | C-US/025-040X050 | C025-040X050 | resistor |  | passive |
| C7 | 0.1 | C-US/025-040X050 | C025-040X050 | resistor |  | passive |
| C8 | 0.1 | C-US/025-040X050 | C025-040X050 | resistor |  | passive |
| C9 | 0.1 | C-US/025-040X050 | C025-040X050 | resistor |  | passive |
| C10 | 0.1 | C-US/025-040X050 | C025-040X050 | resistor |  | passive |
| C11 | 0.1 | C-US/025-040X050 | C025-040X050 | resistor |  | passive |
| C12 | 0.1 | C-US/025-040X050 | C025-040X050 | resistor |  | passive |
| C13 | 0.1 | C-US/025-040X050 | C025-040X050 | resistor |  | passive |
| C14 | 0.1 | C-US/025-040X050 | C025-040X050 | resistor |  | passive |
| C15 | 0.1 | C-US/025-040X050 | C025-040X050 | resistor |  | passive |
| C16 | 0.1 | C-US/025-040X050 | C025-040X050 | resistor |  | passive |
| C17 | 0.1 | C-US/025-040X050 | C025-040X050 | resistor |  | passive |
| C18 | 0.1 | C-US/025-040X050 | C025-040X050 | resistor |  | passive |
| C19 | 0.1 | C-US/025-040X050 | C025-040X050 | resistor |  | passive |
| C20 | 0.1 | C-US/025-040X050 | C025-040X050 | resistor |  | passive |
| C21 | 0.1 | C-US/025-040X050 | C025-040X050 | resistor |  | passive |
| C22 | 0.1 | C-US/025-040X050 | C025-040X050 | resistor |  | passive |
| C23 | 0.1 | C-US/025-040X050 | C025-040X050 | resistor |  | passive |
| C24 | 0.1 | C-US/025-040X050 | C025-040X050 | resistor |  | passive |
| C25 | 0.1 | C-US/025-040X050 | C025-040X050 | resistor |  | passive |
| C26 | 0.1 | C-US/025-040X050 | C025-040X050 | resistor |  | passive |
| C27 | 0.1 | C-US/025-040X050 | C025-040X050 | resistor |  | passive |
| C28 | 0.1 | C-US/025-040X050 | C025-040X050 | resistor |  | passive |
| C29 | 0.1 | C-US/025-040X050 | C025-040X050 | resistor |  | passive |
| C30 | 0.1 | C-US/025-040X050 | C025-040X050 | resistor |  | passive |
| C31 | 0.1 | C-US/025-040X050 | C025-040X050 | resistor |  | passive |
| C32 | 0.1 | C-US/025-040X050 | C025-040X050 | resistor |  | passive |
| C33 | 0.1 | C-US/025-040X050 | C025-040X050 | resistor |  | passive |
| C34 | 0.1 | C-US/025-040X050 | C025-040X050 | resistor |  | passive |
| C35 | 0.1 | C-US/025-040X050 | C025-040X050 | resistor |  | passive |
| C36 | 0.1 | C-US/025-040X050 | C025-040X050 | resistor |  | passive |
| C37 | 0.1 | C-US/025-040X050 | C025-040X050 | resistor |  | passive |
| C38 | 0.1 | C-US/025-040X050 | C025-040X050 | resistor |  | passive |
| C39 | 0.1 | C-US/025-040X050 | C025-040X050 | resistor |  | passive |
| C40 | 0.1 | C-US/025-040X050 | C025-040X050 | resistor |  | passive |
| C41 | 0.1 | C-US/025-040X050 | C025-040X050 | resistor |  | passive |
| C42 | 0.1 | C-US/025-040X050 | C025-040X050 | resistor |  | passive |
| C43 | 0.1 | C-US/025-040X050 | C025-040X050 | resistor |  | passive |
| C44 | 0.1 | C-US/025-040X050 | C025-040X050 | resistor |  | passive |
| C45 | 0.1 | C-US/025-040X050 | C025-040X050 | resistor |  | passive |
| C46 | 0.1 | C-US/025-040X050 | C025-040X050 | resistor |  | passive |
| C47 | 0.1 | C-US/025-040X050 | C025-040X050 | resistor |  | passive |
| IC1 | 74LS32 | 74*32/N | DIL14 | 74xx-us | LS | IC |
| IC2 | 74LS32 | 74*32/N | DIL14 | 74xx-us | LS | IC |
| IC3 | 74LS192 | 74*192/N | DIL16 | 74xx-us | LS | IC |
| IC4 | 74LS192 | 74*192/N | DIL16 | 74xx-us | LS | IC |
| IC5 | 74LS192 | 74*192/N | DIL16 | 74xx-us | LS | IC |
| IC6 | 74LS192 | 74*192/N | DIL16 | 74xx-us | LS | IC |
| IC7 | 74LS244 | 74*244/N | DIL20 | 74xx-us | LS | IC |
| IC8 | 74LS244 | 74*244/N | DIL20 | 74xx-us | LS | IC |
| IC9 | 74LS192 | 74*192/N | DIL16 | 74xx-us | LS | IC |
| IC10 | 74LS192 | 74*192/N | DIL16 | 74xx-us | LS | IC |
| IC11 | 74LS192 | 74*192/N | DIL16 | 74xx-us | LS | IC |
| IC12 | 74LS192 | 74*192/N | DIL16 | 74xx-us | LS | IC |
| IC13 | 74LS244 | 74*244/N | DIL20 | 74xx-us | LS | IC |
| IC14 | 74LS244 | 74*244/N | DIL20 | 74xx-us | LS | IC |
| IC15 | 74LS32 | 74*32/N | DIL14 | 74xx-us | LS | IC |
| IC17 | 74LS244 | 74*244/N | DIL20 | 74xx-us | LS | IC |
| IC18 | 74LS244 | 74*244/N | DIL20 | 74xx-us | LS | IC |
| IC19 | 74LS192 | 74*192/N | DIL16 | 74xx-us | LS | IC |
| IC20 | 74LS192 | 74*192/N | DIL16 | 74xx-us | LS | IC |
| IC21 | 74LS192 | 74*192/N | DIL16 | 74xx-us | LS | IC |
| IC22 | 74LS192 | 74*192/N | DIL16 | 74xx-us | LS | IC |
| IC23 | 74LS244 | 74*244/N | DIL20 | 74xx-us | LS | IC |
| IC24 | 74LS244 | 74*244/N | DIL20 | 74xx-us | LS | IC |
| IC25 | 74LS32 | 74*32/N | DIL14 | 74xx-us | LS | IC |
| IC26 | 74LS32 | 74*32/N | DIL14 | 74xx-us | LS | IC |
| IC27 | 74LS244 | 74*244/N | DIL20 | 74xx-us | LS | IC |
| IC28 | 74LS244 | 74*244/N | DIL20 | 74xx-us | LS | IC |
| IC29 | 74LS192 | 74*192/N | DIL16 | 74xx-us | LS | IC |
| IC30 | 74LS192 | 74*192/N | DIL16 | 74xx-us | LS | IC |
| IC31 | 74LS32 | 74*32/N | DIL14 | 74xx-us | LS | IC |
| IC32 | 74LS139 | 74*139/N | DIL16 | 74xx-us | LS | IC |
| IC33 | 74LS139 | 74*139/N | DIL16 | 74xx-us | LS | IC |
| IC34 | 4077 | 4077/N | DIL14 | 40xx |  | IC |
| IC35 | 74LS245 | 74*245/N | DIL20 | 74xx-us | LS | IC |
| IC36 | 74LS245 | 74*245/N | DIL20 | 74xx-us | LS | IC |
| IC37 | 74LS245 | 74*245/N | DIL20 | 74xx-us | LS | IC |
| IC38 | 74LS139 | 74*139/N | DIL16 | 74xx-us | LS | IC |
| IC40 | 74LS32 | 74*32/N | DIL14 | 74xx-us | LS | IC |
| IC41 | 74LS244 | 74*244/N | DIL20 | 74xx-us | LS | IC |
| IC42 | 74LS244 | 74*244/N | DIL20 | 74xx-us | LS | IC |
| IC43 | 74LS192 | 74*192/N | DIL16 | 74xx-us | LS | IC |
| IC44 | 74LS192 | 74*192/N | DIL16 | 74xx-us | LS | IC |
| IC45 | 74LS244 | 74*244/N | DIL20 | 74xx-us | LS | IC |
| IC46 | 74LS244 | 74*244/N | DIL20 | 74xx-us | LS | IC |
| IC47 | 74LS32 | 74*32/N | DIL14 | 74xx-us | LS | IC |
| IC49 | 74LS244 | 74*244/N | DIL20 | 74xx-us | LS | IC |
| IC50 | 74LS244 | 74*244/N | DIL20 | 74xx-us | LS | IC |
| J1 | M04X2 | M04X2 | 2X4 | SparkFun-Connectors |  | connector |
| J2 | M04X2 | M04X2 | 2X4 | SparkFun-Connectors |  | connector |
| J3 | M04X2 | M04X2 | 2X4 | SparkFun-Connectors |  | connector |
| PWR | LED | LED/5MM | LED5MM | led |  | other |
| R1 | 330 | R/0207/10 | 0207/10 | eagle-ltspice |  | passive |
| RN1 | 10k | RNX8 | RN-9 | resistor-net |  | passive |
| RN2 | 10k | RNX8 | RN-9 | resistor-net |  | passive |
| X1 | FABC96R | FABC96R | FABC96R | con-vg |  | connector |

## Order list (value + package)

| Qty | Value | Package | Designators |
|---|---|---|---|
| 47 | 0.1 | C025-040X050 | C1, C2, C3, C4, C5, C6, C7, C8, C9, C10, C11, C12, C13, C14, C15, C16, C17, C18, C19, C20, C21, C22, C23, C24, C25, C26, C27, C28, C29, C30, C31, C32, C33, C34, C35, C36, C37, C38, C39, C40, C41, C42, C43, C44, C45, C46, C47 |
| 16 | 74LS192 | DIL16 | IC3, IC4, IC5, IC6, IC9, IC10, IC11, IC12, IC19, IC20, IC21, IC22, IC29, IC30, IC43, IC44 |
| 16 | 74LS244 | DIL20 | IC7, IC8, IC13, IC14, IC17, IC18, IC23, IC24, IC27, IC28, IC41, IC42, IC45, IC46, IC49, IC50 |
| 8 | 74LS32 | DIL14 | IC1, IC2, IC15, IC25, IC26, IC31, IC40, IC47 |
| 3 | 74LS139 | DIL16 | IC32, IC33, IC38 |
| 3 | 74LS245 | DIL20 | IC35, IC36, IC37 |
| 3 | M04X2 | 2X4 | J1, J2, J3 |
| 2 | 10k | RN-9 | RN1, RN2 |
| 1 | 330 | 0207/10 | R1 |
| 1 | 4077 | DIL14 | IC34 |
| 1 | FABC96R | FABC96R | X1 |
| 1 | LED | LED5MM | PWR |

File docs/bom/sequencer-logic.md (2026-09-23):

# BOM: Sequencer logic v2.1

GENERATED by `tools/gen_bom.py` on 2026-09-23 from `hardware/cards/sequencer-logic/eagle/v2.1/Sequencer-Logic-Prod-V2.1l.sch` (Eagle 9.6.2) - do not edit; edit the schematic and re-run `make bom`.  
Role: machine. the 218 mm 'V2.1l' board.

104 parts (39 ICs, 49 passives, 9 connectors/headers/jumpers, 7 others); 28 supply/frame symbols skipped. Value = the schematic's value attribute, or the deviceset with the Eagle technology substituted for `*` (a `*` left in a value means the schematic names no technology: the part number was never filled in).

## Parts by designator

| Designator | Value | Device (deviceset/device) | Package | Library | Technology | Class |
|---|---|---|---|---|---|---|
| -INT-PULLUP | PINHD-1X2 | PINHD-1X2 | 1X02 | pinhead |  | connector |
| . | OUT | LED/5MM | LED5MM | led |  | other |
| C1 | .1 | CAP/EZ | CAP-PTH-SMALLEZ | SparkFun-Capacitors |  | passive |
| C2 | .1 | CAP/EZ | CAP-PTH-SMALLEZ | SparkFun-Capacitors |  | passive |
| C3 | .1 | CAP/EZ | CAP-PTH-SMALLEZ | SparkFun-Capacitors |  | passive |
| C4 | .1 | CAP/EZ | CAP-PTH-SMALLEZ | SparkFun-Capacitors |  | passive |
| C5 | .1 | CAP/EZ | CAP-PTH-SMALLEZ | SparkFun-Capacitors |  | passive |
| C6 | .1 | CAP/EZ | CAP-PTH-SMALLEZ | SparkFun-Capacitors |  | passive |
| C7 | .1 | CAP/EZ | CAP-PTH-SMALLEZ | SparkFun-Capacitors |  | passive |
| C8 | .1 | CAP/EZ | CAP-PTH-SMALLEZ | SparkFun-Capacitors |  | passive |
| C9 | .1 | CAP/EZ | CAP-PTH-SMALLEZ | SparkFun-Capacitors |  | passive |
| C10 | .1 | CAP/EZ | CAP-PTH-SMALLEZ | SparkFun-Capacitors |  | passive |
| C11 | .1 | CAP/EZ | CAP-PTH-SMALLEZ | SparkFun-Capacitors |  | passive |
| C12 | .1 | CAP/EZ | CAP-PTH-SMALLEZ | SparkFun-Capacitors |  | passive |
| C13 | .1 | CAP/EZ | CAP-PTH-SMALLEZ | SparkFun-Capacitors |  | passive |
| C14 | .1 | CAP/EZ | CAP-PTH-SMALLEZ | SparkFun-Capacitors |  | passive |
| C15 | .1 | CAP/EZ | CAP-PTH-SMALLEZ | SparkFun-Capacitors |  | passive |
| C16 | .1 | CAP/EZ | CAP-PTH-SMALLEZ | SparkFun-Capacitors |  | passive |
| C17 | .1 | CAP/EZ | CAP-PTH-SMALLEZ | SparkFun-Capacitors |  | passive |
| C18 | .1 | CAP/EZ | CAP-PTH-SMALLEZ | SparkFun-Capacitors |  | passive |
| C19 | .1 | CAP/EZ | CAP-PTH-SMALLEZ | SparkFun-Capacitors |  | passive |
| C20 | .1 | CAP/EZ | CAP-PTH-SMALLEZ | SparkFun-Capacitors |  | passive |
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

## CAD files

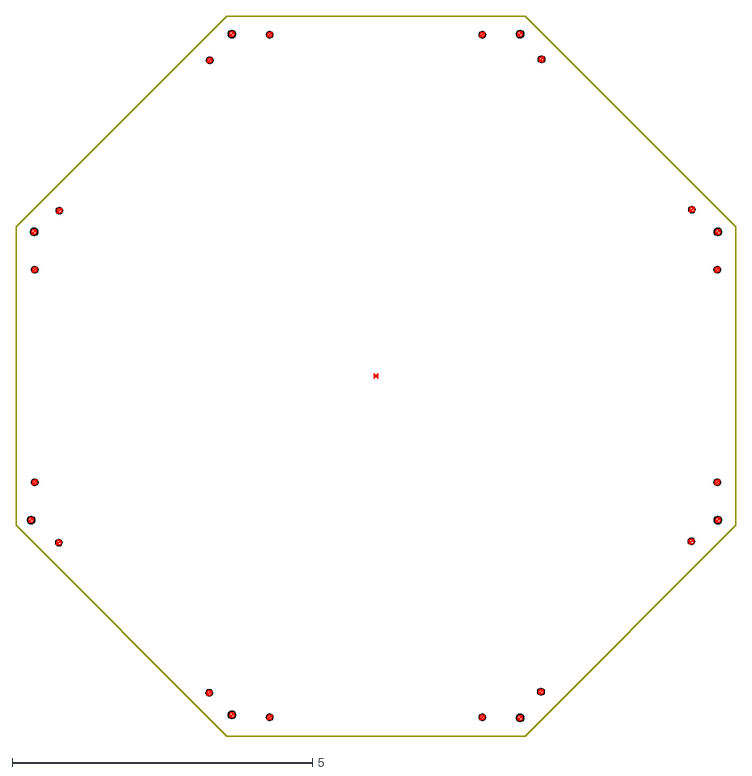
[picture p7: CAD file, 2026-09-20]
hardware/bus/backplane/eagle/v2.0/yacc2buss.dxf
12.0 x 12.0

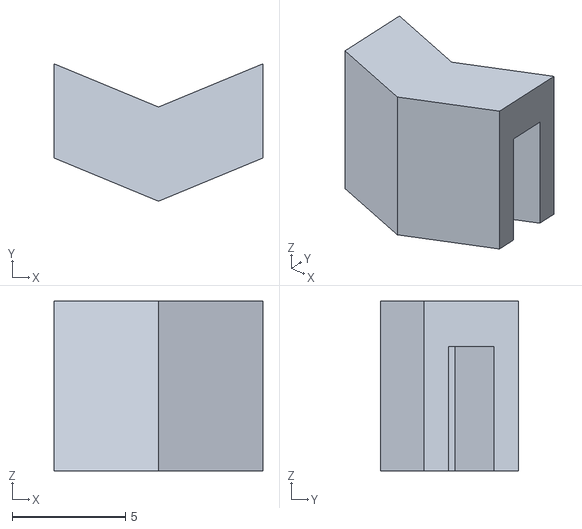
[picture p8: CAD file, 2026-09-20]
hardware/mechanical/clip12.stl
9.24 x 6.08 x 7.50

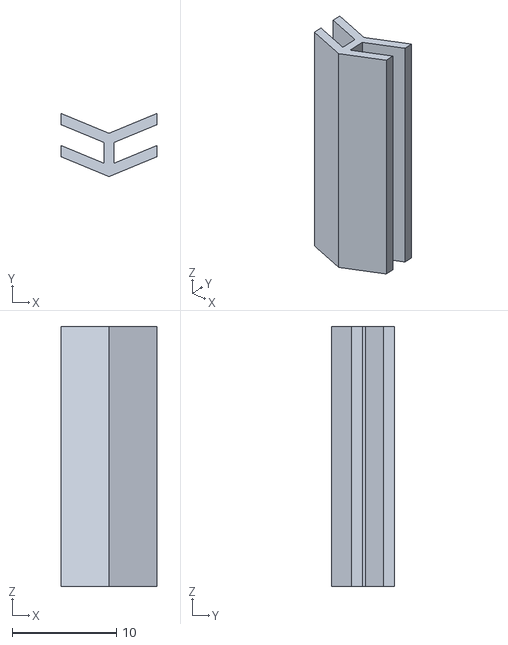
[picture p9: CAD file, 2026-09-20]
hardware/mechanical/divider.stl
9.24 x 6.08 x 25.0

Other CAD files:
hardware/cards/bus-tester/eagle/v1.1/switchtemplate.skp
hardware/cards/bus-tester/eagle/v3.1/switchtemplate.skp
hardware/mechanical/clip.skp
hardware/mechanical/clip12.skp
hardware/mechanical/clip12~.skp

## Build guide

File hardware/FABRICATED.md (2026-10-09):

# Fabricated boards

Generated 2026-10-09 by `tools/gen_fabricated.py` from `tools/fabricated.py` (edit the table, then re-run).
Every revision folder under `hardware/` is listed; the ones with status **in-machine** or **fabricated** also carry a `FABRICATED` marker file.
"presumed" means the only evidence is that the folder sat in `PCB/Production` in the old tree.
Fabrication output (gerber zips, CAM jobs, drill/photoplotter logs, order invoices) lives in `hardware/fab/<card>/<rev>/`; the Eagle folder keeps only the design. Where the tree holds no fab output the board was most likely ordered by uploading the `.brd` straight to OSH Park, so the `.brd` in the design folder IS what was sent.

## In the machine

| Card | Revision | Design | Files sent to fab | Confirmed | Note |
|---|---|---|---|---|---|
| backplane | V2.0 | `bus/backplane/eagle/v2.0` | `bus/backplane/eagle/v2.0/fab/` CAMOutputs/ | 2026-09-20 | PCB/Production, 2021-07-26 (sch) / 2021-08-03 (brd): adds an 8th slot X8 and bulk electrolytics C7/C8 to V1.1. Folder also holds the DXF/SVG/PDF exports. CAMOutputs in fab/ |
| alu | V3.2 | `cards/alu/eagle/v3.2` | `cards/alu/eagle/v3.2/fab/` CAMOutputs/ | 2026-09-20 | PCB/Production, 2020-11-29, the ALU in the machine; CAMOutputs in v3.2/fab. The Working 'ALU-V3.3' folder was this design with the bus label reverted - nothing new, folded 2026-09-20. Notes end with NEXT VERSION 3.3 but no 3.3 design was ever started. The Sept-2021 16-bit ALU (V3.3-16) was deleted from this tree 2026-09-20 (still in YACCS) |
| bus-tester | V1.1 | `cards/bus-tester/eagle/v1.1` | `cards/bus-tester/eagle/v1.1/fab/` gerbers.zip | 2026-09-20 | the 2016 TESTER-PROD-V1.1 board (gerbers identical); Eagle folder was called 'Bus Tester orig' |
| sequencer-memory | adaptor | `cards/sequencer-memory/accessories/eeprom-adaptor` | `cards/sequencer-memory/accessories/eeprom-adaptor/fab/` oshpark-order-invoice-rmD8XYsD.pdf | 2026-09-20 | EEPROM adaptor: plugs into IC9 (24Cxx I2C EEPROM socket) and carries two 24Cxx at I2C addresses 7 and 6 - doubles the microcode storage. Design 2020-12-19/21; OSH Park order rmD8XYsD 2024-06-19, 3 boards (invoice in fab/; the .brd was the upload) |
| io | V1.1 | `cards/io/eagle/v1.1` | `cards/io/eagle/v1.1/fab/` CAMOutputs/ | 2026-09-19 | PCB/Production, 2020-11-29 (the Working copy of 2020-07-31 was the same board with the old Bus V3.1 net names; folded in 2026-09-20, only its Notes.rtf kept: it adds the never-done V1.2 ideas - directional data-bus buffer driven by -IO-RD, IC5 pin 5 to -BUS-EN). CAMOutputs in v1.1/fab |
| memory | v1.3 | `cards/memory/eagle/v1.3` | `cards/memory/eagle/v1.3/fab/` jlcpcb-order-2000765A-Y42.zip | 2026-09-24 | THE BUILT CARD: Fusion 360 export (2026-09-24) of the design JLCPCB made on 2025-06-27 (order 2000765A, 4 layers; order archive in fab/). tools/verify_fab_vs_brd.py: all 695 holes and all 1,263 top/bottom tracks are in the order's gerbers, part list and pick-and-place match. Differs from the earlier save (eagle/deprecated/v1.3-do-not-use) by IC15 74ALS11 (74245 enable = AND of the card's chip selects instead of -VMA) and the routed TMP registers IC26-IC29 + RN5/RN6. Filed as eagle/v1.3-fusion-export-2026-09-24 and renamed to eagle/v1.3 the same day. KiCad conversion in cards/memory/kicad/v1.3 |
| register | 1.1 | `cards/register/eagle/v1.1` | `cards/register/eagle/v1.1/fab/` CAMOutputs/ | 2026-09-20 | PCB/Production, 2020-08-31; CAMOutputs in v1.1/fab. The Working 'Index Registers 1.2' folder held byte-identical copies of the 1.1 files renamed 1.2 plus a notes file asking whether bus direction should follow -RD-SEL; folded in here 2026-09-20 (only the notes were new). No 1.2 design exists |
| sequencer-logic | v2.1 | `cards/sequencer-logic/eagle/v2.1` | `cards/sequencer-logic/eagle/v2.1/fab/` CAMOutputs/ | 2026-09-20 | PCB/Production, 2020-12-01, 218x114 mm ('V2.1l' = the lengthened board); CAMOutputs in fab/. 'orig size/' = the V2.1 circuit on the original 178 mm outline (silk still says V2.0) plus an unrouted 'copy' - intermediates, never ordered. The old-YACC1/ gen-1 files were dropped 2026-09-20 (identical to archive/gen1-2015-2018) |
| sequencer-memory | V2.1 | `cards/sequencer-memory/eagle/v2.1` | `cards/sequencer-memory/eagle/v2.1/fab/` CAMOutputs/ | 2026-09-20 | PCB/Production, 2020-12-01; CAMOutputs in fab/. Carries the microcode EEPROM (IC9; see accessories/eeprom-adaptor) and the ATmega328 loader. old-YACC1/ gen-1 files dropped 2026-09-20 (identical to archive/gen1-2015-2018) |
| video | V1.0 | `cards/video/eagle/v1.0-fusion-export-2026-09-18` | **none in tree** | 2026-09-18 | built from the Fusion 360 design (Fusion is the master; this folder is the 2026-09-18 Eagle export). Installed for bring-up, no CRTC fitted yet. The board file was exported as Blank V3.1.brd (the template it was started from) and is stored here as Video_1.0.brd. Inherits Blank V3.1's stale C3-C6 names (unused) |

## Every revision, by card

### backplane

| Revision | Status | Design | Files sent to fab | Note |
|---|---|---|---|---|
| V2.0 | in-machine (2026-09-20) | `bus/backplane/eagle/v2.0` | `bus/backplane/eagle/v2.0/fab/` CAMOutputs/ | PCB/Production, 2021-07-26 (sch) / 2021-08-03 (brd): adds an 8th slot X8 and bulk electrolytics C7/C8 to V1.1. Folder also holds the DXF/SVG/PDF exports. CAMOutputs in fab/ |
| V1.1 | fabricated | `bus/backplane/eagle/deprecated/v1.1` | `bus/backplane/eagle/deprecated/v1.1/fab/` gerbers.zip | 2016-06-16, the gen-1 backplane (also in archive/gen1-2015-2018); still in PCB/Production in 2021, gerbers in fab/. A 2020 Eagle-9 re-save of it was dropped 2026-09-20 (identical) |

### blank-card

| Revision | Status | Design | Files sent to fab | Note |
|---|---|---|---|---|
| V3.1 | fabricated | `bus/blank-card/eagle/v3.1` | `bus/blank-card/eagle/v3.1/fab/` Blank V3_2025-06-27.zip | 2020-08-23 design = Bus Template V3.1 schematic + card outline/connectors; ordered 2025-06-27 (zip + Fusion CAM in fab/). Base of the video card. CAUTION: carries Bus V3.1 names on C3-C6 (-ADDR-REG-RD0/LD0/RD1/LD1); the machine is Bus V3.2 (ADDR-REG-ID0..3) - make a Blank V3.2 before drawing the next card |
| V3.2 | design-only | `bus/blank-card/eagle/v3.2` | - | DERIVED 2026-09-20 from V3.1 by tools/make_blank_v32.py: the four C3-C6 nets renamed to Bus V3.2 (ADDR-REG-ID0..3), bus label and silk title updated, nothing else. Not fabricated. Use THIS as the template for new cards |

### bus-template

| Revision | Status | Design | Files sent to fab | Note |
|---|---|---|---|---|
| V3.2 | design-only | `bus/bus-template/eagle/v3.2` | - | Eagle template, not a board |

### bus-jumper-horizontal

| Revision | Status | Design | Files sent to fab | Note |
|---|---|---|---|---|
| V3.2 | fabricated (2026-09-20) | `bus/bus-jumper-horizontal/eagle/v3.2` | `bus/bus-jumper-horizontal/eagle/v3.2/fab/` CAMOutputs/ | PCB/Production, 2020-07-20: 231x115 mm, 4-layer, 10 mil traces. NOT FITTED - the jumper boards belong to an older bus arrangement and are obsolete (2026-09-20). Shares its schematic byte-for-byte with the vertical jumper; the .brd.orig here is the unrouted V3.1 intermediate |
| V3.0 | fabricated | `bus/bus-jumper-horizontal/eagle/deprecated/v3.0` | `bus/bus-jumper-horizontal/eagle/deprecated/v3.0/fab/` CAMOutputs/ | PCB/Production until 2021-01 (Old & obsolete), 2020-06-16: 231x70 mm, 2-layer, 6 mil traces - the first horizontal jumper, replaced by the taller 4-layer V3.2 a month later |

### bus-jumper-vertical

| Revision | Status | Design | Files sent to fab | Note |
|---|---|---|---|---|
| V3.0 | fabricated (2026-09-20) | `bus/bus-jumper-vertical/eagle/v3.0` | `bus/bus-jumper-vertical/eagle/v3.0/fab/` CAMOutputs/ | PCB/Production, 2020-06-16: 76x114 mm, 2-layer. NOT FITTED - obsolete with the older bus arrangement (2026-09-20). Jumper Board Vertical V3.1.brd = identical copper, silk text corrected |

### address-tmp

| Revision | Status | Design | Files sent to fab | Note |
|---|---|---|---|---|
| V1.0 | fabricated | `cards/address-tmp/eagle/deprecated/v1.0` | `cards/address-tmp/eagle/deprecated/v1.0/fab/` CAMOutputs/ | 2020-06-20, fabricated (PCB/Production until 2021-01, then retired: 'Old designs do not use'). Two 16-bit address registers + TMP built from eight 74373 latches, driven by the Bus V3.0/V3.1 strobes -ADDR-REG-RD0/LD0/RD1/LD1 on C3-C6; replaced by the Index Registers card + ADDR-REG-ID0..3 (Bus V3.2). CAMOutputs in fab/. A Working copy differing only by a stray 'test text' element was dropped 2026-09-20 |

### alu

| Revision | Status | Design | Files sent to fab | Note |
|---|---|---|---|---|
| V3.2 | in-machine (2026-09-20) | `cards/alu/eagle/v3.2` | `cards/alu/eagle/v3.2/fab/` CAMOutputs/ | PCB/Production, 2020-11-29, the ALU in the machine; CAMOutputs in v3.2/fab. The Working 'ALU-V3.3' folder was this design with the bus label reverted - nothing new, folded 2026-09-20. Notes end with NEXT VERSION 3.3 but no 3.3 design was ever started. The Sept-2021 16-bit ALU (V3.3-16) was deleted from this tree 2026-09-20 (still in YACCS) |
| V3.1 | fabricated | `cards/alu/eagle/deprecated/v3.1` | `cards/alu/eagle/deprecated/v3.1/fab/` gerbers/ | Working/Old and obsolete; Production 2021-01 held resubmit + buried-vias variants |
| V3.1 | fabricated | `cards/alu/eagle/deprecated/v3.1-resubmit` | `cards/alu/eagle/deprecated/v3.1-resubmit/fab/` gerbers/ | PCB/Production until 2021-01 |
| V3.1 | fabricated | `cards/alu/eagle/deprecated/v3.1-buried-vias` | `cards/alu/eagle/deprecated/v3.1-buried-vias/fab/` gerbers/ | PCB/Production until 2021-01 |
| V3.0 | fabricated | `cards/alu/eagle/deprecated/v3.0-2layer` | `cards/alu/eagle/deprecated/v3.0-2layer/fab/` alu4_2020-06-14.zip | PCB/Production until 2021-01 (20 files incl. CAM outputs) |

### bus-tester

| Revision | Status | Design | Files sent to fab | Note |
|---|---|---|---|---|
| V1.1 | in-machine (2026-09-20) | `cards/bus-tester/eagle/v1.1` | `cards/bus-tester/eagle/v1.1/fab/` gerbers.zip | the 2016 TESTER-PROD-V1.1 board (gerbers identical); Eagle folder was called 'Bus Tester orig' |
| V3.1 | design-only | `cards/bus-tester/eagle/v3.1` | - | 2020-07-15 redesign of the 2016 tester (latches IC11-IC15 drive the bus instead of the MCP23017 directly, -BUF-EN / -SOFT-BUS-EN / -SOFT-RESET, bypass caps, no reset switch); 114x178 mm 4-layer, routed, CAM run, NEVER ORDERED (2026-09-20: the board in use is v1.1). Folder v3.11-horizontal-unrouted/ = the next-day reshape to 243x114 mm, routing removed; Notes.rtf is the V3.11 superset |

### sequencer-memory

| Revision | Status | Design | Files sent to fab | Note |
|---|---|---|---|---|
| adaptor | in-machine (2026-09-20) | `cards/sequencer-memory/accessories/eeprom-adaptor` | `cards/sequencer-memory/accessories/eeprom-adaptor/fab/` oshpark-order-invoice-rmD8XYsD.pdf | EEPROM adaptor: plugs into IC9 (24Cxx I2C EEPROM socket) and carries two 24Cxx at I2C addresses 7 and 6 - doubles the microcode storage. Design 2020-12-19/21; OSH Park order rmD8XYsD 2024-06-19, 3 boards (invoice in fab/; the .brd was the upload) |
| V2.1 | in-machine (2026-09-20) | `cards/sequencer-memory/eagle/v2.1` | `cards/sequencer-memory/eagle/v2.1/fab/` CAMOutputs/ | PCB/Production, 2020-12-01; CAMOutputs in fab/. Carries the microcode EEPROM (IC9; see accessories/eeprom-adaptor) and the ATmega328 loader. old-YACC1/ gen-1 files dropped 2026-09-20 (identical to archive/gen1-2015-2018) |
| V2.0 | fabricated | `cards/sequencer-memory/eagle/deprecated/v2.0` | `cards/sequencer-memory/eagle/deprecated/v2.0/fab/` CAMOutputs/ | PCB/Production until 2021-01 |

### io

| Revision | Status | Design | Files sent to fab | Note |
|---|---|---|---|---|
| V1.1 | in-machine (2026-09-19) | `cards/io/eagle/v1.1` | `cards/io/eagle/v1.1/fab/` CAMOutputs/ | PCB/Production, 2020-11-29 (the Working copy of 2020-07-31 was the same board with the old Bus V3.1 net names; folded in 2026-09-20, only its Notes.rtf kept: it adds the never-done V1.2 ideas - directional data-bus buffer driven by -IO-RD, IC5 pin 5 to -BUS-EN). CAMOutputs in v1.1/fab |
| V1.0 | fabricated | `cards/io/eagle/deprecated/v1.0` | `cards/io/eagle/deprecated/v1.0/fab/` CAMOutputs/ | PCB/Production until 2021-01 |

### mem-register

| Revision | Status | Design | Files sent to fab | Note |
|---|---|---|---|---|
| V1.0 | fabricated (2026-09-20) | `cards/mem-register/eagle/v1.0` | `cards/mem-register/eagle/v1.0/fab/` CAMOutputs/ | PCB/Production 2021-07-19, the 16-byte RAM card used for bring-up (at $0010), removed from the bus once the memory card worked (2026-09-20); CAMOutputs in fab/. Drawn on Blank V3.1 (old RD/LD names on C3-C6, unused) |

### mem-switch

| Revision | Status | Design | Files sent to fab | Note |
|---|---|---|---|---|
| V1.1 | fabricated (2026-09-20) | `cards/mem-switch/eagle/v1.1` | `cards/mem-switch/eagle/v1.1/fab/` CAMOutputs/ | PCB/Production 2021-07-19, the switch-programmed ROM card used for bring-up (at $0000), removed from the bus once the memory card worked (2026-09-20); CAMOutputs in fab/. Notes.rtf = what changed from 1.0 (bypass caps, 74240, switch orientation, LEDs, 16-byte block select). Drawn on Blank V3.1 so C3-C6 carry the old RD/LD names (unused) |
| V1.0 | fabricated | `cards/mem-switch/eagle/deprecated/v1.0` | `cards/mem-switch/eagle/deprecated/v1.0/fab/` CAMOutputs/ | PCB/Production 2021-06-23, built ('Version 1.0 works' per the 1.1 notes); superseded a month later by 1.1 (+60 parts: 74244 buffers, BRD-SEL, caps). Its Notes.rtf was the blank template's and was dropped 2026-09-20 |

### memory

| Revision | Status | Design | Files sent to fab | Note |
|---|---|---|---|---|
| v1.3 | in-machine (2026-09-24) | `cards/memory/eagle/v1.3` | `cards/memory/eagle/v1.3/fab/` jlcpcb-order-2000765A-Y42.zip | THE BUILT CARD: Fusion 360 export (2026-09-24) of the design JLCPCB made on 2025-06-27 (order 2000765A, 4 layers; order archive in fab/). tools/verify_fab_vs_brd.py: all 695 holes and all 1,263 top/bottom tracks are in the order's gerbers, part list and pick-and-place match. Differs from the earlier save (eagle/deprecated/v1.3-do-not-use) by IC15 74ALS11 (74245 enable = AND of the card's chip selects instead of -VMA) and the routed TMP registers IC26-IC29 + RN5/RN6. Filed as eagle/v1.3-fusion-export-2026-09-24 and renamed to eagle/v1.3 the same day. KiCad conversion in cards/memory/kicad/v1.3 |
| v2.0 | fabricated (2026-10-09) | `cards/memory/kicad/v2.0` | `cards/memory/kicad/v2.0/` memory-v2.0-gerbers.zip | ORDERED from JLCPCB 2026-10-09, order 2000765A-Y52 (Ken; JLCPCB shows it as Y52-2000765A): memory-v2.0-gerbers.zip, 4 layers, settings as memory-v2.0-jlcpcb-order.txt; not yet received or built. The zip was re-verified against memory-v2.0.kicad_pcb the same day (every layer and both drill files). Known open items carried into the build: the BASIC RUN fault on the machine (BACKLOG; v2.0 shares v1.3's ROM -CE/-OE path), the unexplained jumper wire on the built card's IC7 pin 4, the ribbon plug's pin 20 |
| v1.2 | fabricated | `cards/memory/eagle/deprecated/v1.2` | `cards/memory/eagle/deprecated/v1.2/fab/` CAMOutputs/ | PCB/Production, 2020-11-29 (also built). Memory V1.2.brd.old.brd = an earlier 31-part layout of V1.2 (2020-09-01) |
| v1.1 | fabricated | `cards/memory/eagle/deprecated/v1.1` | `cards/memory/eagle/deprecated/v1.1/fab/` CAMOutputs/ | PCB/Production until 2021-01; files still NAMED V1.0 (2020-06-19) but this is revision 1.1: adds the boot ROM remap (IC11 74157 + IC12 7474 FORCE-ROM) to 1.0 |
| v1.0 | fabricated | `cards/memory/eagle/deprecated/v1.0` | `cards/memory/eagle/deprecated/v1.0/fab/` CAMOutputs/ | PCB/Production until 2021-01 |
| v1.3 | design-only | `cards/memory/eagle/deprecated/v1.3-do-not-use` | - | DO NOT USE - EARLIER SAVE (Notes 2025-03-06, board 2021-03-17) of the v1.3 design, NOT the built card (found 2026-09-24; was eagle/v1.3 until it was renamed and deprecated 2026-09-24): no IC15, IC5 pin 19 on -VMA, TMP registers IC26-IC29 and RN5/RN6 placed off the board, unrouted. Kept for its history (Notes.md/.rtf, ROM ZSelect.circ). fab/Memory V1_2025-06-27.zip is the built card's gerber set (= the order's; its design is eagle/v1.3); fab/CAMOutputs/ are older 2020 CAM runs. The Working folder also held V1.0 files (= revision 1.1) and an earlier save of V1.2 - removed 2026-09-20 |

### protocard

| Revision | Status | Design | Files sent to fab | Note |
|---|---|---|---|---|
| V1.0 | fabricated | `cards/protocard/eagle/v1.0` | `cards/protocard/eagle/v1.0/fab/` gerbers.zip | PCB/Production, gerbers |

### register

| Revision | Status | Design | Files sent to fab | Note |
|---|---|---|---|---|
| 1.1 | in-machine (2026-09-20) | `cards/register/eagle/v1.1` | `cards/register/eagle/v1.1/fab/` CAMOutputs/ | PCB/Production, 2020-08-31; CAMOutputs in v1.1/fab. The Working 'Index Registers 1.2' folder held byte-identical copies of the 1.1 files renamed 1.2 plus a notes file asking whether bus direction should follow -RD-SEL; folded in here 2026-09-20 (only the notes were new). No 1.2 design exists |
| 1.0 | fabricated | `cards/register/eagle/deprecated/v1.0` | `cards/register/eagle/deprecated/v1.0/fab/` CAMOutputs/ | PCB/Production until 2020-08. JLCPCB order 2000765A-Y6 (2020-06-17, 2 layers; Ken's archive filed 2026-09-27 as fab/jlcpcb-order-2000765A-Y6.rar): its 11 gerber/drill files are byte-identical to fab/CAMOutputs/GerberFiles (and to the v1.0-no-address variant's, whose board file is identical) |
| 1.0 | fabricated | `cards/register/eagle/deprecated/v1.0-no-address` | `cards/register/eagle/deprecated/v1.0-no-address/fab/` CAMOutputs/ | PCB/Production until 2021-01 ("no address" variant) |

### sequencer-logic

| Revision | Status | Design | Files sent to fab | Note |
|---|---|---|---|---|
| v2.1 | in-machine (2026-09-20) | `cards/sequencer-logic/eagle/v2.1` | `cards/sequencer-logic/eagle/v2.1/fab/` CAMOutputs/ | PCB/Production, 2020-12-01, 218x114 mm ('V2.1l' = the lengthened board); CAMOutputs in fab/. 'orig size/' = the V2.1 circuit on the original 178 mm outline (silk still says V2.0) plus an unrouted 'copy' - intermediates, never ordered. The old-YACC1/ gen-1 files were dropped 2026-09-20 (identical to archive/gen1-2015-2018) |
| v2.0 | fabricated | `cards/sequencer-logic/eagle/deprecated/v2.0` | `cards/sequencer-logic/eagle/deprecated/v2.0/fab/` CAMOutputs/ | PCB/Production until 2021-01 |

### video

| Revision | Status | Design | Files sent to fab | Note |
|---|---|---|---|---|
| V1.0 | in-machine (2026-09-18) | `cards/video/eagle/v1.0-fusion-export-2026-09-18` | **none in tree** | built from the Fusion 360 design (Fusion is the master; this folder is the 2026-09-18 Eagle export). Installed for bring-up, no CRTC fitted yet. The board file was exported as Blank V3.1.brd (the template it was started from) and is stored here as Video_1.0.brd. Inherits Blank V3.1's stale C3-C6 names (unused) |

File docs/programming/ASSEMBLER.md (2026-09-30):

# The YACC1 cross assembler (RC/asm, YACC1 port)

How to assemble YACC1 programs on the Mac with `software/assembler`, what it accepts, what it produces, and its
traps. Written 2026-09-23 from the YACC1-D tree. Since 2026-09-25 the same dialect assembles on the machine too:
`/BIN/ASM` under Y1/OS, section 10.

Sources: `software/assembler/README.md`, `asm.txt` (Michael H. Riley's RC/asm 2.2 manual, the `.def` format and the
output formats), `asm.c` / `asmcmds.c` (option handling, the `.prg`/`.img` switch, the 2026-09-22 `DS` fix),
`yacc1.def` (the YACC1 instruction table), `Makefile`, `rcasm.rc`, `software/compiler/README.md` and
`software/compiler/y1cc.py` (the quirks the compiler had to work around), `tests/assembler/{ledcount,brur,romcount,
romdiag}/`, `tests/compiler/run.py`, `firmware/monitor/monitor.asm` (the largest source). Encodings quoted below
were checked with a scratch assembly on 2026-09-23.

## 1. What it is

RC/asm is a table-driven assembler: the program `asm` knows nothing about the YACC1; `yacc1.def` tells it, one
pattern per instruction, how a source line maps to bytes. The YACC1 port (2020-08 → 2021-07) changed the C sources
and added the table; `upstream/rcasm-2.2/` is the untouched original. Build it with `make` in `software/assembler`
(also built by the top-level `make`). `make check` there re-assembles the monitor and BASIC and diffs the images
against the committed ones (the burned ROM); this is the tree's proof that the assembler and the table still
reproduce what is in the machine.

## 2. Invocation

```
cd <a folder holding NAME.asm, yacc1.def and rcasm.rc>
../software/assembler/asm NAME -d=yacc1 > NAME.lst
```

- **The source name comes first, without `.asm`, and `-d=yacc1` after it.** The `-d` handler in `readOptions()`
  (`asm.c`) skips the argument that follows it, so `asm -d=yacc1 NAME` loses the file name (`firmware/README.md`,
  `Makefile`). `-d=yacc1` means "read `yacc1.def`"; it is looked for in the current directory and then in the
  compiled-in `DEF_DIR` (`asm.c` `Read_Def_File`).
- **`rcasm.rc`** in the current directory is read before the command line, one option per line (`asm.txt`). The
  tree's copy in `software/assembler/` holds `-l -x -h` (listing, cross-reference, Intel hex). Every test runner
  creates one with just `-h` (`tests/compiler/run.py`, `tests/assembler/romcount/run.py`, `os/Makefile`:
  `echo -h > rcasm.rc`).
- The listing (and the summary `N Lines assembled / N Errors / N Labels / Object Code:N bytes`) goes to **stdout**,
  so redirect it to `NAME.lst`. `tests/compiler/run.py` greps `Object Code:(\d+) bytes` and `^0 Errors` from it.
- Options (`asm.txt`, `asm.c`): `-h` Intel hex output; `-l` listing; `-s` symbols; `-x` cross-reference; `-t` no
  trailer; `-Sl`/`-Sa` sort the label reference by line/alphabetically; `-r` show the matching rule (debugging a
  `.def`); `-v` version; `-Dsym=val` define a preprocessor symbol; `-d name` the definition file.
- The assembler wants all three files in the working directory; the runners copy `yacc1.def` and the source into a
  scratch folder first (`tests/compiler/run.py` `run_one`, `tests/assembler/brur/README.md`).

## 3. Output files

With `-h` the object file is **`NAME.img`, Intel hex** (`asm.c`: `emucode='H'` → `.img`), the format both emulators
load (`emulator -f NAME.img`, `y1ucemu -f NAME.img`), that `tools/img2bin.py` flattens for the ROM programmer and
for `tools/p8xfs.py`, and that the compiler tests use. Example (`tests/assembler/romcount/romcount.img`):

```
:10f00000a0f003190eff0270019161708061a4f0fd
:10f0100007010b0c7001617080611b20005b2ba24b
:09f02000f01d0cb0010ba0f0136f
:00000001ff
```

Each record is `:` + byte count + address + type (`00` data, `01` end) + bytes + checksum; records hold up to 16
bytes and start a new line at every `ORG` and (since 2026-09-22) every `DS`.

Without `-h` the object file is **`NAME.prg`** in RC/asm's own text format (`asm.c`: `emucode='I'` → `.prg`):
`:AAAA b b b ...` lines and a `*AAAA` start-address line (`asm.txt` "Output file"; example
`tests/assembler/ledcount/ledcount.prg`: `:0000 0e 00 70 01 61 b0 01 a0 00 02` / `*0000`). `BACKLOG.md`'s planned
monitor loader reads that format. Nothing in the tree consumes `.obj`.

The **listing** (`-l`) is one line per source line: line number, address, the bytes, the source; then the label
table with `-x`. `firmware/monitor/monitor.lst` is the reference example (`f05b: cmdloop:` etc.).

## 4. Source syntax

- A line is `[label:] mnemonic [operands] [; comment]`. Labels end with `:`; the whole line is upper-cased before
  matching (see quirks), so `cmdloop`, `CMDLOOP` and `CmdLoop` are one label.
- Numbers: decimal (`512`), hex with a trailing `H` (`0EFFH`, `0F000H` — a leading digit is required, so `$F000`-style
  is not accepted and `0F000H` is the form), characters in single quotes (`'A'`). `0x` hex is not in the manual.
- Operands are matched literally against the `.def` patterns: `MVIW R1,0EFFH`, `OUTI P0,SWITCHLED`,
  `MOVRR R0,R7`, `LDIVR R3,5`. Register names are `R0`..`R7` (the class also lists `R8`/`R9`, which silently produce
  wrong opcodes — see the ISA reference), ports `P0`..`P9`,`PA`..`PF`.
- Expressions (`asm.txt`, precedence high to low): `.0`/`.1` (low/high byte), `* /`, `+ -`, `<< >>`, `&`, `| ^`.
  Parentheses group: `(label+4).0`. `HIGH expr` is a `DB` form (`DB HIGH \W` → the high byte). Checked 2026-09-23:
  `LDAI lab+4` → `0E 14` with `lab = 10H`; `LDAI lab*2` → `0E 20`; `DB (1234H).0` → `34`; `DB (1234H).1` → `12`;
  `DB HIGH 1234H` → `12`. `label+4.0` does not work (`software/assembler/README.md`); write `(label+4).0`.
  The monitor writes OR as `!`: `OUTI P0,(UARTA3!UARTCS)` assembles to `70 58` = $18 | $40 (`monitor.lst` line 77).
  `!` is a YACC1-port addition to the tokenizer (`support.c` line 188, comment `ken add | &`), not in `asm.txt`.
- Preprocessor: `#DEFINE symbol value`, `#UNDEF`, `#IFDEF`, `#IFNDEF`, `#ELSE`, `#ENDIF` (`asm.txt`); none of the
  tree's sources use them.

## 5. Directives (all defined in `yacc1.def`, not in the assembler)

| Directive | Effect | `.def` line |
|---|---|---|
| `ORG addr` | set the assembly address; flushes the hex record | `ORG \W` → `\O1` |
| `END addr` | set the start address (the `*AAAA` line of a `.prg`; ignored by the hex loaders) | `END \W` → `\S1` |
| `EQU value` / `.EQU` / `equ` | define the label on this line as a constant (a register name or a word) | `EQU \{regs}`, `EQU \W` → `\E1` |
| `DB byte[,byte...]` / `DB "text"` | emit bytes | `DB \L` → `\1` |
| `DB HIGH word` | emit the high byte of a word | `DB HIGH \W` → `hi(1)` |
| `DW word[,word...]` | emit words, **high byte first** | `DW \W` → `hi(1) lo(1)`; `DW \M` |
| `DS n` | reserve n bytes (nothing emitted; the next record starts after them); n may use backward labels (quirk 11) | `DS \W` → `\B1` |
| `PUBLIC`, `EXTERN`, `LIB PROC`, `LIB ENDP` | RC/asm library markers; unused in the tree | `\P \X \R \Q` |

`ORG` takes the address in the assembler's expression syntax; the compiler emits it as decimal (`ORG 12288`).
`END` is optional in practice (`ledcount.asm` has none).

## 6. Quirks (verified, with the evidence)

1. **Every source line is upper-cased before matching**, so labels are case-insensitive and
   `DB "text"` emits upper-case text (`DB "Ab"` → `41 42`, checked). Emit strings as numeric bytes when case matters:
   the compiler writes `DB 115,117,109,...` (`y1cc.py`). The monitor's banner is written `"YACC 2020: hello world  "`
   in `monitor.asm` but the listing shows the bytes `4f 52 4c 44` (`ORLD`, `monitor.lst` around line 1160): the
   machine prints `YACC 2020: HELLO WORLD`.
2. **Labels are at most 29 characters** (`header.h`: `char labels[MAX_LABELS][30]`, "KEN CHANGED FROM 16 TO 30";
   `y1cc.py` `LABEL_MAX = 29`; the compiler mangles long C names). A longer label used to overwrite memory; since
   2026-09-24 it stops the assembly with `ERR - Label longer than 29 characters`. The label table holds **8,191**
   labels (`MAX_LABELS` 8192, was 1,000 with no check: 3,817 crashed it); a full table is the error `Too many labels`.
   Also fixed 2026-09-24: a space or tab inside an operand (`DW A, B`) made the assembler loop forever.
3. **A leading `-` on a number is silently dropped**: `LDAI -1` assembles to `0E 01` (checked). There are no negative
   numbers; write two's complement by hand (`0FFH`).
4. **A `\B` operand over 255 is an error** ("out of range"); `\W` operands over 65535 likewise. The compiler rejects
   integer literals over 65535 at its own level.
5. **`DS` used to corrupt the following bytes' addresses**: bytes after a `DS` were appended to the Intel-hex record
   that began before it and so loaded at the wrong address. Fixed 2026-09-22 in `asmcmds.c` (`write_line()` after
   `\B`, "flush the pending hex record so bytes after a DS start a new record"); `tools/patched_files.txt` records it.
   The firmware never uses `DS`, so the burned images are unchanged (`make check` proves it).
6. (Fixed 2026-09-23 in `yacc1.def`, commit 69db58d.) `IADDR` with an odd operand assembled to opcode $FF because its
   pattern was `FE|1 hi(1) lo(1)` (`|1` ORs the operand into the opcode byte): `IADDR 1235H` gave `FF 12 35`. The line
   is `FE  hi(1) lo(1)` now: `IADDR 1235H` → `FE 12 35` (checked 2026-09-25).
7. Two labels differing only in case collide (quirk 1); the compiler uniquifies its labels for that reason.
8. The `-d` option consumes the following argument (section 2).
9. Missing `yacc1.def` or a missing source name used to crash; since 2026-09-20 they print a message (`asm.c`).
10. There is no `.0`/`.1` on a bare `label+4` (write `(label+4).0`); the compiler always parenthesises.
11. **Pass 1 used to read every label as 1** (`support.c` `find_label`), so an `ORG`, `DS` or `EQU` whose operand
    named a label placed what followed at the wrong address (`DS 256-(y).0` reserved 255 bytes). Since 2026-09-24 a
    label already defined earlier in the source (a backward reference) has its value in pass 1 too, and `EQU` sets
    its value in pass 1 (`asmcmds.c`); a forward reference is still 1 in pass 1, so keep label expressions in
    `ORG`/`DS`/`EQU` backward. y1cc `--xisa` aligns its variable page with `zpad: DS (256-(zpad).0)&255` (the label
    on the same line counts as defined). Every firmware image, bench image and test program assembles to the same
    bytes as before (`tools/verify_firmware.py`, `tests/bench`, `tests/os`, `tests/compiler/passes.py`).
12. **A line of 100 characters or more aborts the assembler** (found 2026-09-25): `trim()` and `parse()` copy the text
    after the leading blanks / after the label, up to the comment, into `char tmp[100]`, and macOS's fortified
    `strcpy` stops the program (exit status 133, no output). y1cc's instructions are far shorter (its longest lines,
    109 characters, are comments, cut before the copy); the native assembler (section 10) takes 254.
    BACKLOG has the fix.

## 7. The four worked examples in `tests/assembler/`

Each folder has a README with the byte listing and what a failure means; here is what each program teaches.

**`ledcount/`** — the 16-byte switch-ROM program (10 bytes at $0000) for the Mem Switch bring-up card:

```
SWITCHLED:  EQU 001H
        ORG 0000H
        LDAI 0                  ; count = 0
loop:   OUTI P0,SWITCHLED       ; select the LED board
        OUTA P1                 ; LEDs = count
        ADDI 1                  ; count += 1
        BR loop                 ; forever
```

Bytes `0E 00 70 01 61 B0 01 A0 00 02`. It shows the I/O card's two-step port idiom (`OUTI P0,select / OUTA P1`),
an immediate ALU op and an absolute branch, and it uses only PC-relative fetches (no stack, no R2), which is why it
ran on 2026-09-21 before any of the register/stack findings mattered (`docs/system/MACHINE.md`). Its output is the
`.prg` text format (no `-h`).

**`brur/`** — the test of `BRUR Rn` ($AD, added 2026-09-22): a direct `BRUR R5`, a jump through an address fetched
from a `DW` table (`LDAVR R6 / MVARH R5 / INCR R6 / LDAVR R6 / MVARL R5 / BRUR R5`: the two bytes of a big-endian word
into a register by hand), and a four-way dispatch indexed by a counter (`MVRLA R7 / MVAT / MVRLA R6 / ADDT / MVARL R6`,
the table kept inside one page so only the low byte is added). Expected console output `ABC0123`, then `HALT`. The
program starts at $3000 and carries the same boot stub the compiler's `--boot` emits at $F000 (`BR 0F003H / MVIW
R1,0EFFH / JSR main / HALT`): the first branch presents an A15-high address to end FORCE-ROM. Run:
`emulator -x -f brur.img`; `tests/ucemu/run.py` runs it on the microcode emulator too.

**`romcount/`** — a 41-byte program burned in place of the monitor to prove the EPROM tool chain: mirror the
switches to the LED board and the TIL311 displays while the input line is low, then count up from the switch value
with a `DECR R3 / MVRHA R3 / BRNZ` delay loop and `MVAT`/`MVTA` keeping the count in TMP. It uses only R1, R3 and TMP
after the first build (R6/R7) exposed the missing second register card on the bench. Build chain: `asm romcount
-d=yacc1` → `romcount.img` → `python3 tools/img2bin.py romcount.img romcount.bin --base 0xE000 --end 0x10000 --fill
0xFF --size 8192` (offset $1000 in the 8K image = $F000). `run.py` re-assembles, compares both files with the
committed ones and runs the image on `y1ucemu -s 0x25 -i 0/1 -L`. It ran overnight on the machine 2026-09-22/23.

**`romdiag/`** — the instruction check paced by the input switch: twelve stages, each waiting for the line to
change (`BRINH wlo1` / `BRINL whi2`), each showing a byte on the LEDs through a `show` subroutine (`JSR`/`RET`, so
stage 1 also proves the stack): `LDAI`, `MVRHA`, `MVRLA`, `DECR`, `BRNZ` both ways, `ADDI`, `MVAT`/`MVTA`, a probe of
R7 (stage 9: `FF` means register card 1 is absent), the delay loop, then a free-running count. Expected LED sequence
`25 ON AA 20 11 03 01 02 FF 33 20 55 00 01 02`. `run.py` runs it on ucemu with `-I 100000` flipping the line and
`-R 2`/`-R 1` for both card configurations.

## 8. The `.def` file, so a new instruction can be added

`yacc1.def` (format from `asm.txt`, "Definition files"):

1. Line 1 is a comment (`yacc1 -> Native`).
2. `CLASS regs` / `CLASS ports` define operand classes: `text=value` pairs. `\{regs}` in a pattern matches one of them
   and yields its value.
3. `*` starts the translations. Each instruction is **two lines**: the pattern (`MNEMONIC<tab>operand pattern`) and the
   construction line.
4. Pattern wildcards: `\B` a byte (0–255), `\W` a word, `\N` a nibble, `\{class}` a class member, `\L` the rest of the
   line as a byte list (for `DB`), `\M` as a word list (`DW`), `\D` a displacement (unused here). The k-th wildcard
   becomes replacement variable k.
5. Construction: hex digits build a byte in an accumulator; a blank outputs it and starts the next byte. `\n` inserts
   variable n; `hi(n)`/`lo(n)` its high/low byte; `|n` ORs variable n into the current byte without shifting, `|n<v`
   after shifting it left v bits, `|n>v` right; `&nn` ANDs the byte with hex nn; `%` swaps nibbles. Directive
   builders: `\On` ORG, `\En` EQU, `\Sn` END, `\Bn` DS, `\P \Q \R \X` library marks.

Reading the tree's entries with that key:

| Entry | Meaning |
|---|---|
| `LDAI \B` / `0E \1` | opcode $0E, then the byte |
| `BR \W` / `A0 hi(1) lo(1)` | $A0, high byte, low byte — every address operand is big-endian |
| `MVIB \{regs},\B` / `10\|1 \2` | $10 OR the register number in the opcode, then the byte |
| `MVIW \{regs},\W` / `18\|1  hi(2) lo(2)` | $18 OR reg, then the word |
| `MOVRR \{regs},\{regs}` / `0F \|2<4\|1` | $0F, then (second reg << 4) OR first reg: **source first, destination second** |
| `POPR \{regs}` / `08 \1<4&f0` | $08, then reg << 4 |
| `PUSHR`/`JSRUR`/`BRUR \{regs}` / `07 \1`, `06 \1`, `AD \1` | opcode, then the register number in the low nibble |
| `BRVR \{regs}` / `D8\|1` | one byte, register in the opcode |
| `OUTI \{ports},\B` / `70\|1 \2` | $70 OR port, then the byte |
| `IADDR \W` / `FE  hi(1) lo(1)` | $FE, then the word (it was `FE\|1`, quirk 6) |

To add an instruction: give it a number in `software/opcodes.h` (the generator, both emulators and the disassembler
include it), microcode in the generator (`firmware/microcode/README.md`: `make regen`, then load the EEPROM), a case
in `software/emulator/main.c`, and two lines here. `make -C os` then regenerates the native assemblers' tables and
the disassembler's (`/BIN/DISASM`, `os/dis_optab.c` by `tools/gen_y1_distab.py`, 2026-09-29), which also checks the
new opcode against `software/opcodes.h`; `disasm` prints it in this dialect, so `disasm -s` output assembles back. `BRUR` on 2026-09-22 is the worked example of exactly that
(`tools/patched_files.txt`: `opcodes.h`, `branch.c`, `yacc1.def`, `main.c`, `test.hex`); `tests/assembler/brur`
is its test. Keep the mnemonic order in the file irrelevant (patterns are matched, not searched in order) but avoid
a pattern that is a prefix of another with the same operand shape.

## 9. Putting the output to use

- Run on the interpreter: `software/emulator/emulator -x -f NAME.img` (with a `--boot`-style stub at $F000 and a
  `HALT`), or `emulator -m -f NAME.img` and `G3000` at the monitor prompt for a program assembled at $3000 that ends
  with `RET`.
- Run on the microcode emulator: `software/ucemu/y1ucemu -x -m -f NAME.img` (the ROM is needed for the console path).
- Burn: `tools/img2bin.py` with `--base 0xE000 --end 0x10000 --fill 0xFF --size 8192` for a whole 28C64 image
  (`tests/assembler/romcount/README.md`); see [TOOLCHAIN.md](TOOLCHAIN.md).
- Put on a CF image for Y1/OS: `img2bin.py NAME.img NAME.bin --base 0x5000`, then `p8xfs.py put disk.img NAME.bin
  --name /BIN/NAME --load 0x5000 --exec 0x5000` (`os/Makefile`).
- Loading RAM on the real machine has no path yet: the monitor has no hex loader (`BACKLOG.md`: `tools/monload.py`
  through the `E` command is planned), so today a program reaches the machine only in the ROM socket or, once the
  card exists, from the CF card.

## 10. The native assembler, /BIN/ASM (2026-09-25; in YACC1 assembly since 2026-09-26)

The same dialect on the machine, in two versions that behave identically (`man asm`, `man asmc`, `os/README.md`
"asm"), written after RC/asm's own code (not the P8X assembler, whose syntax is another) so that they make the same
bytes of the same source, quirks and all:

| | `/BIN/ASM` | `/BIN/ASMC` |
|---|---|---|
| source | `os/commands-asm/asm.asm`, hand-written YACC1 assembly (2026-09-26) | `os/commands/asm.c`, compiled by y1cc (2026-09-25) |
| role | the assembler everything uses (`cc`'s users, `tests/native`, the self-host) | **the specification**: asm.asm was written from it routine by routine; any change of behaviour goes into both |
| instruction table | `os/commands-asm/asmtab.inc` (INCLUDEd) | `os/asm_optab.c` (#included) |
| size | 9,239 bytes of program file | 13,186 bytes + 19,569 of data |
| symbol table | **20,292 bytes** (about 1,660 of y1cc's labels) | 17,088 bytes (about 1,400) |
| speed (instructions, cat's 1,504 lines) | 2.75M: 1 min 29 s at 1 MHz | 12.8M: 6 min 55 s |
| needs | the 2026-09-24 microcode (ADDIW, SHL16; so does the native compiler) | any microcode (compiled without `--xisa`, as every /BIN command) |

```
asm HELLO.ASM              HELLO: a program file (first to last address, gaps zero; load, exec = END or load)
asm -h HELLO.ASM           HELLO.IMG: Intel hex, the text of `asm HELLO -d=yacc1` with -h on the Mac
asm -h MONITOR.ASM M.IMG   an output name; a source name without '.' gets .ASM
```

- **The table** is `os/asm_optab.c` (asm.c) and `os/commands-asm/asmtab.inc` (asm.asm), both generated from
  `yacc1.def` by one run of `tools/gen_y1_optab.py` (the `os/Makefile` rules regenerate them; `tests/asm/run.py`
  fails if either is stale). The assembly table is laid out for its reader: 64 mnemonic chains under the hash
  `h = rotl8(h) + c` from a seed the generator picks (at most 3 records a chain), each name followed by a 127, and
  a register or port class as a direct table by the name's second character. The generator reads the file as `Read_Def_File` does
  and compiles each construction line with a copy of `Translate()` into a few operations (a run of hex digits is one
  constant), checked against a model of `Translate()` on random arguments; the patterns keep their order, grouped by
  mnemonic in 64 hash chains. A construction it cannot express (`\N`, `\D`, `%`, `|n>s`, `OPTION 16BIT`) stops the
  generator rather than producing a different assembler. To add an instruction, section 8 is all there is to do,
  then `make -C os`.
- **What is copied**: the line read 254 bytes at a time (`fgets(buffer, 255)`); `makeupper` (upper case outside
  single quotes); `parse` (the comment at the first `;` outside quotes, the label before the first `:` outside
  quotes, with RC/asm's rule that a second kind of quote inside a quote takes over); `WildMatch`/`Class_Match`
  (first word literal, whitespace, `\B`/`\W` up to a `,` or space outside quotes with the `abs((int)v)` range test,
  a class name as a prefix, `\L`/`\M` the rest); `get_num` with `buildTokens`/`process_tokens` in 32 bits, token
  records shifted exactly as RC/asm shifts them - including the tokens that slide in from beyond a parenthesis'
  range and the stale ones past the count, the dropped leading minus, `.1` as C's `/ 256`, `12H3` as hex 123;
  pass 1 reading a forward reference as 1 and EQU setting its value in pass 1; the Intel-hex records (16 bytes, a
  new record at ORG and DS); INCLUDE's file name taken from the raw line (two levels here).
- **Not supported** (an error in /BIN/ASM, accepted by RC/asm; nothing in the tree uses them): MACRO/ENDM, PUBLIC,
  EXTERN, LIB PROC/ENDP; `/` on values beyond 16 bits; an EQU value outside -65535..65535 (labels are 16 bits + a
  sign); code or a label past $FFFF (RC/asm counts on into 17 bits); INCLUDE more than two deep (four OS handles:
  the source, two includes, the output). RC/asm's `.prg` output and its listing, cross-reference and symbol options
  are not there: the summary line gives the size, the label count and the addresses.
- **Other differences**: errors are counted once per line (RC/asm can print the same undefined label for every
  pattern it tries) and name the line in its own file; after an error the output file is deleted (RC/asm writes
  it anyway); a missing INCLUDE file is an error (RC/asm prints a message and goes on); lines of 100-254 characters
  work (quirk 12).
- **Limits**: the symbol table is 20,292 bytes in `/BIN/ASM` (17,088 in `/BIN/ASMC`: 16,640 until 2026-09-25,
  when cc8's buffered I/O outgrew it), 5 + the name's length a label (y1cc's labels average 7 characters: about
  1,660 labels, 1,400 in ASMC; the biggest compiler pass, cc8, has 1,383 in 16,925 bytes, 83% of ASM's table);
  29 characters a label, 254 a line, 45 tokens an expression, 32 characters a token; source files up to 16M
  (Y1/OS's positions are 24 bits since 2026-09-25); the program file needs the code to go up in address (else
  `-h`). A source that fills ASMC's table can fill ASM's too a little later, with its own error on its own line:
  y1cc.c itself compiled (4,186 labels) is refused by both (`tests/asm`). The output takes Y1/OS's one write
  handle, so neither works inside a `>` or a pipe ("cannot create").
- **asm.asm** (`os/commands-asm/asm.asm`, 2026-09-26; its header has the conventions): every routine names the asm.c
  function it implements. What makes it fast: the source is read a sector at a time with READ straight into its
  buffer and each line scanned where it lies, 8 instructions a byte, with a translation table that upper-cases and
  maps the characters `parse()` must see to 0, and two 0 sentinels (the end of the data read, the line's 254th
  byte), so the loop tests nothing else; a line that runs past the data is moved into the page before the buffer,
  so the raw line (for the error messages and INCLUDE's name) is always the bytes in the buffer; a comment is
  scanned only for its line feed; leading blanks are skipped (put into `ln` only when the line has a label).
  Tokens are cut in place in `ln` (a token with a blank inside - RC/asm skips blanks inside a token - sends the
  expression to asm.c's copying tokenizer, which writes the same records from the start); the records are
  asm.c's, 8 bytes apart, shifted exactly as there, stale ones included; `(label).0` and `(label).1`, y1cc's
  `--xisa` page offsets, are computed at once when the five records are the usual ones, with the same records left
  behind (the general algorithm runs when the stale record after them is an operator: `tests/asm/src/err_stale.asm`).
  Labels: 256 chains of `len|flags next value name` records, the name stored backwards so the compare starts where
  y1cc's labels differ. An INCLUDE keeps the outer file's position and SEEKs back to it. It uses ADDIW and SHL16
  (the 2026-09-24 microcode), never R2, and the shell's stack (~20 bytes deep); the page-aligned tables and
  buffers are at $C400-$CFFF, its variables after the code, the symbol table between.
- **Speed** (instructions on the instruction-level emulator, program file; the monitor to hex; each figure includes
  the OS's and the ROM's work for the file I/O, 15-25%; at 1 MHz with 32.4 clocks an instruction):

  | source | lines | bytes | `/BIN/ASMC` | `/BIN/ASM` | faster | an instruction a byte | at 1 MHz |
  |---|---|---|---|---|---|---|---|
  | hello (y1cc) | 82 | 1,652 | 0.88M | 0.20M | 4.3x | 124 | 28 s -> 6 s |
  | cat (y1cc) | 1,504 | 27,706 | 12.8M | 2.75M | 4.7x | 99 | 6 min 55 s -> 1 min 29 s |
  | the ROM monitor (-h) | 1,972 | 46,179 | 17.3M | 3.96M | 4.4x | 86 | 9 min 20 s -> 2 min 08 s |
  | cc4 (y1cc `--xisa`) | 3,404 | 65,973 | 37.8M | 7.18M | 5.3x | 109 | 20 min 25 s -> 3 min 52 s |
  | cc8 (y1cc `--xisa`, the biggest pass) | 11,897 | 235,482 | 129.7M | 26.4M | 4.9x | 112 | 1 h 10 min -> 14 min 15 s |

  The microcode emulator (cat, each in a session of its own less an empty one): ASM 2.85M instructions and 83.9M
  clocks (29.4 an instruction: hand-written code has fewer of the long instructions), ASMC 12.9M and 435.5M
  (33.7): 5.2x in real time, no bus fights. A native compile (`tests/native/run.py`'s 27 programs): assembling
  217M -> 46.5M instructions, compile and assemble 687M -> 517M (6 h 11 min -> 4 h 39 min at 1 MHz). The self-host
  (`tests/native/selfhost.py`, one stage): assembling 764M -> 153M, the eleven C programs 21 h 17 min -> 15 h 47 min,
  15 h 52 min with asm.asm's own assembly (software/compiler/README.md). Where ASM's time goes now
  (`tests/native/profile.py`): reading lines 20%, the ROM's sector reads 12%, the mnemonic 12%, tokens 15%,
  matching 10%, labels 9%, the operations 8%, output 5%.
- **Tests**: `tests/asm/run.py` (in `make check`, `make asm-test`) builds `asm.c` for the Mac with the YACC1's
  integer types against an emulation of the Y1/OS syscalls (`tests/asm/host_asm.c`, `host_sys.c`) and compares it
  with RC/asm on every source in the tree; then it runs `/BIN/ASM` (asm.asm) under Y1/OS on the instruction-level
  emulator on the same 336 sources, with -h and to a program file (disks of 72 sources, the sessions in parallel,
  20 seconds), and its messages, summary and files must be what asm.c gives for the same command line: 334
  identical, 2 refused by both where ASMC's table is full (`--uc`: 27 of them on the microcode emulator too, 2
  minutes) - each y1cc compile of `tests/compiler/corpus.py` plain and `--xisa` (262,
  the nine compiler passes and `asm.c` itself among them), the monitor and BASIC with their candidates, monnew,
  `tests/assembler`, `isa.asm`, `y1os.asm` with its INCLUDE, and `tests/asm/src` (`quirks.asm`: the corners above;
  six sources both must refuse): 283 identical in hex and as program files, 1 identical in hex (`yacc1test.asm`
  goes back in address: its program file is refused, as it must be), 13 refused by both. `--target`
  (`tests/asm/target.py`) runs `asm` under Y1/OS on both emulators: y1cc programs assembled and run, the monitor
  assembled to `firmware/monitor/monitor.img`, `isa.asm`, the quirks with INCLUDE, compiler pass cc4, an error;
  every file written compared with RC/asm's output.

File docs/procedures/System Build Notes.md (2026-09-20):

*Converted from `System Build Notes.rtf` (saved 2025-03-06) by `tools/rtf_to_md.py`; the .rtf is the original.*

Build Order for boards

All board are in the Production directory, except the Bus-Test Card which is in the Unsure directory

1) Bus Test Card
2) Bus Card
3) Memory Card
4) Optional Prototype card
5) Index Register Card 1 of 2
6) ALU Card
7) Index Register Card 2 of 2
8) Sequencer Memory Card
9) Sequencer Logic Card 

Add build instructions for all boards

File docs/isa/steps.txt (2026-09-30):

START        step  0: -MEM-RD, -VMA, OUT-OFF, ADDR-REG-ID=0, REG-RD-ID=0, REG-LD-ID=0, ALU=0
START        step  1: -MEM-RD, -VMA, OUT-OFF, LD-INS-REG, ADDR-REG-ID=0, REG-RD-ID=0, REG-LD-ID=0, ALU=0
START        step  2: -REG-FUNC-RD, -REG-UP, -VMA, OUT-OFF, ADDR-REG-ID=0, REG-RD-ID=0, REG-LD-ID=0, ALU=0
START        step  3: -VMA, OUT-OFF, UCODE-COUNT-RESET, ADDR-REG-ID=0, REG-RD-ID=0, REG-LD-ID=0, ALU=0
ON           step  0: -MEM-RD, -VMA, ADDR-REG-ID=0, REG-RD-ID=0, REG-LD-ID=0, ALU=0
ON           step  1: -MEM-RD, -VMA, LD-INS-REG, ADDR-REG-ID=0, REG-RD-ID=0, REG-LD-ID=0, ALU=0
ON           step  2: -REG-FUNC-RD, -REG-UP, -VMA, ADDR-REG-ID=0, REG-RD-ID=0, REG-LD-ID=0, ALU=0
ON           step  3: -VMA, OUT-ON, ADDR-REG-ID=0, REG-RD-ID=0, REG-LD-ID=0, ALU=0
ON           step  4: -VMA, OUT-ON, UCODE-COUNT-RESET, ADDR-REG-ID=0, REG-RD-ID=0, REG-LD-ID=0, ALU=0
OFF          step  0: -MEM-RD, -VMA, ADDR-REG-ID=0, REG-RD-ID=0, REG-LD-ID=0, ALU=0
OFF          step  1: -MEM-RD, -VMA, LD-INS-REG, ADDR-REG-ID=0, REG-RD-ID=0, REG-LD-ID=0, ALU=0
OFF          step  2: -REG-FUNC-RD, -REG-UP, -VMA, ADDR-REG-ID=0, REG-RD-ID=0, REG-LD-ID=0, ALU=0
OFF          step  3: -VMA, OUT-OFF, ADDR-REG-ID=0, REG-RD-ID=0, REG-LD-ID=0, ALU=0
OFF          step  4: -VMA, OUT-OFF, UCODE-COUNT-RESET, ADDR-REG-ID=0, REG-RD-ID=0, REG-LD-ID=0, ALU=0
HALT         step  0: -MEM-RD, -VMA, ADDR-REG-ID=0, REG-RD-ID=0, REG-LD-ID=0, ALU=0
HALT         step  1: -MEM-RD, -VMA, LD-INS-REG, ADDR-REG-ID=0, REG-RD-ID=0, REG-LD-ID=0, ALU=0
HALT         step  2: -REG-FUNC-RD, -REG-UP, -VMA, ADDR-REG-ID=0, REG-RD-ID=0, REG-LD-ID=0, ALU=0
HALT         step  3: -VMA, SOFT-HALT, ADDR-REG-ID=0, REG-RD-ID=0, REG-LD-ID=0, ALU=0
HALT         step  4: -VMA, SOFT-HALT, UCODE-COUNT-RESET, ADDR-REG-ID=0, REG-RD-ID=0, REG-LD-ID=0, ALU=0
JSR          step  0: -MEM-RD, -VMA, ADDR-REG-ID=0, REG-RD-ID=0, REG-LD-ID=0, ALU=0
JSR          step  1: -MEM-RD, -VMA, LD-INS-REG, ADDR-REG-ID=0, REG-RD-ID=0, REG-LD-ID=0, ALU=0
JSR          step  2: -REG-FUNC-RD, -REG-UP, -VMA, ADDR-REG-ID=0, REG-RD-ID=0, REG-LD-ID=0, ALU=0
JSR          step  3: -MEM-RD, -VMA, ADDR-REG-ID=0, REG-RD-ID=0, REG-LD-ID=0, ALU=0
JSR          step  4: -MEM-RD, -VMA, BRANCH-LD-HI, ADDR-REG-ID=0, REG-RD-ID=0, REG-LD-ID=0, ALU=0
JSR          step  5: -REG-FUNC-RD, -REG-UP, -VMA, ADDR-REG-ID=0, REG-RD-ID=0, REG-LD-ID=0, ALU=0
JSR          step  6: -MEM-RD, -VMA, ADDR-REG-ID=0, REG-RD-ID=0, REG-LD-ID=0, ALU=0
JSR          step  7: -MEM-RD, -VMA, BRANCH-LD-LO, ADDR-REG-ID=0, REG-RD-ID=0, REG-LD-ID=0, ALU=0
JSR          step  8: -REG-FUNC-RD, -REG-UP, -VMA, ADDR-REG-ID=0, REG-RD-ID=0, REG-LD-ID=0, ALU=0
JSR          step  9: -REG-FUNC-RD, -REG-RD-HI, -VMA, -HL-SWAP, ADDR-REG-ID=1, REG-RD-ID=0, REG-LD-ID=0, ALU=0
JSR          step 10: -REG-FUNC-RD, -REG-RD-HI, -MEM-WR, -VMA, -HL-SWAP, ADDR-REG-ID=1, REG-RD-ID=0, REG-LD-ID=0, ALU=0
JSR          step 11: -REG-FUNC-RD, -REG-RD-HI, -VMA, -HL-SWAP, ADDR-REG-ID=1, REG-RD-ID=0, REG-LD-ID=0, ALU=0
JSR          step 12: -REG-FUNC-RD, -VMA, -HL-SWAP, ADDR-REG-ID=1, REG-RD-ID=0, REG-LD-ID=0, ALU=0
JSR          step 13: -REG-FUNC-RD, -VMA, -HL-SWAP, ADDR-REG-ID=1, REG-RD-ID=1, REG-LD-ID=0, ALU=0
JSR          step 14: -REG-FUNC-RD, -REG-DN, -VMA, -HL-SWAP, ADDR-REG-ID=1, REG-RD-ID=1, REG-LD-ID=0, ALU=0
JSR          step 15: -VMA, -HL-SWAP, ADDR-REG-ID=1, REG-RD-ID=1, REG-LD-ID=0, ALU=0
JSR          step 16: -REG-FUNC-RD, -REG-RD-LO, -VMA, ADDR-REG-ID=1, REG-RD-ID=0, REG-LD-ID=0, ALU=0
JSR          step 17: -REG-FUNC-RD, -REG-RD-LO, -MEM-WR, -VMA, ADDR-REG-ID=1, REG-RD-ID=0, REG-LD-ID=0, ALU=0
JSR          step 18: -REG-FUNC-RD, -REG-RD-LO, -VMA, ADDR-REG-ID=1, REG-RD-ID=0, REG-LD-ID=0, ALU=0
JSR          step 19: -REG-FUNC-RD, -VMA, ADDR-REG-ID=1, REG-RD-ID=0, REG-LD-ID=0, ALU=0
JSR          step 20: -REG-FUNC-RD, -VMA, ADDR-REG-ID=1, REG-RD-ID=1, REG-LD-ID=0, ALU=0
JSR          step 21: -REG-FUNC-RD, -REG-DN, -VMA, ADDR-REG-ID=1, REG-RD-ID=1, REG-LD-ID=0, ALU=0
JSR          step 22: -VMA, ADDR-REG-ID=1, REG-RD-ID=1, REG-LD-ID=0, ALU=0
JSR          step 23: -REG-FUNC-LD, -VMA, -ALU-FUNC, BR-TEST, -BRANCH-RD, ADDR-REG-ID=1, REG-RD-ID=1, REG-LD-ID=0, ALU=0
JSR          step 24: -REG-FUNC-LD, -VMA, -ALU-FUNC, -BRANCH-RD, ADDR-REG-ID=1, REG-RD-ID=1, REG-LD-ID=0, ALU=0
JSR          step 25: -REG-FUNC-LD, REG-LD-LO, REG-LD-HI, -VMA, -ALU-FUNC, -BRANCH-RD, ADDR-REG-ID=1, REG-RD-ID=1, REG-LD-ID=0, ALU=0
JSR          step 26: -REG-FUNC-LD, -VMA, -ALU-FUNC, -BRANCH-RD, ADDR-REG-ID=1, REG-RD-ID=1, REG-LD-ID=0, ALU=0
JSR          step 27: -REG-FUNC-LD, -VMA, -ALU-FUNC, UCODE-COUNT-RESET, -BRANCH-RD, ADDR-REG-ID=1, REG-RD-ID=1, REG-LD-ID=0, ALU=0
RET          step  0: -MEM-RD, -VMA, ADDR-REG-ID=0, REG-RD-ID=0, REG-LD-ID=0, ALU=0
RET          step  1: -MEM-RD, -VMA, LD-INS-REG, ADDR-REG-ID=0, REG-RD-ID=0, REG-LD-ID=0, ALU=0
RET          step  2: -REG-FUNC-RD, -REG-UP, -VMA, ADDR-REG-ID=0, REG-RD-ID=0, REG-LD-ID=0, ALU=0
RET          step  3: -VMA, ADDR-REG-ID=0, REG-RD-ID=0, REG-LD-ID=0, ALU=0
RET          step  4: -REG-FUNC-RD, -REG-UP, -VMA, ADDR-REG-ID=0, REG-RD-ID=1, REG-LD-ID=0, ALU=0
RET          step  5: -MEM-RD, -VMA, ADDR-REG-ID=1, REG-RD-ID=1, REG-LD-ID=0, ALU=0
RET          step  6: -MEM-RD, -VMA, BRANCH-LD-LO, ADDR-REG-ID=1, REG-RD-ID=1, REG-LD-ID=0, ALU=0
RET          step  7: -MEM-RD, -VMA, ADDR-REG-ID=1, REG-RD-ID=1, REG-LD-ID=0, ALU=0
RET          step  8: -REG-FUNC-RD, -REG-UP, -VMA, ADDR-REG-ID=1, REG-RD-ID=1, REG-LD-ID=0, ALU=0
RET          step  9: -MEM-RD, -VMA, ADDR-REG-ID=1, REG-RD-ID=1, REG-LD-ID=0, ALU=0
RET          step 10: -MEM-RD, -VMA, BRANCH-LD-HI, ADDR-REG-ID=1, REG-RD-ID=1, REG-LD-ID=0, ALU=0
RET          step 11: -MEM-RD, -VMA, ADDR-REG-ID=1, REG-RD-ID=1, REG-LD-ID=0, ALU=0
RET          step 12: -VMA, ADDR-REG-ID=1, REG-RD-ID=1, REG-LD-ID=0, ALU=0
RET          step 13: -REG-FUNC-LD, -VMA, -ALU-FUNC, BR-TEST, -BRANCH-RD, ADDR-REG-ID=1, REG-RD-ID=1, REG-LD-ID=0, ALU=0
RET          step 14: -REG-FUNC-LD, REG-LD-LO, REG-LD-HI, -VMA, -ALU-FUNC, BR-TEST, -BRANCH-RD, ADDR-REG-ID=1, REG-RD-ID=1, REG-LD-ID=0, ALU=0
RET          step 15: -REG-FUNC-LD, -VMA, -ALU-FUNC, -BRANCH-RD, ADDR-REG-ID=1, REG-RD-ID=1, REG-LD-ID=0, ALU=0
RET          step 16: -REG-FUNC-LD, -VMA, -ALU-FUNC, UCODE-COUNT-RESET, -BRANCH-RD, ADDR-REG-ID=1, REG-RD-ID=1, REG-LD-ID=0, ALU=0
JSRUR        step  0: -MEM-RD, -VMA, ADDR-REG-ID=0, REG-RD-ID=0, REG-LD-ID=0, ALU=0
JSRUR        step  1: -MEM-RD, -VMA, LD-INS-REG, ADDR-REG-ID=0, REG-RD-ID=0, REG-LD-ID=0, ALU=0
JSRUR        step  2: -REG-FUNC-RD, -REG-UP, -VMA, ADDR-REG-ID=0, REG-RD-ID=0, REG-LD-ID=0, ALU=0
JSRUR        step  3: -MEM-RD, -VMA, ADDR-REG-ID=0, REG-RD-ID=0, REG-LD-ID=0, ALU=0
JSRUR        step  4: -MEM-RD, -VMA, OPERAND-CLK, ADDR-REG-ID=0, REG-RD-ID=0, REG-LD-ID=0, ALU=0
JSRUR        step  5: -REG-FUNC-RD, -MEM-RD, -VMA, ADDR-REG-ID=0, REG-RD-ID=0, REG-LD-ID=0, ALU=0
JSRUR        step  6: -REG-FUNC-RD, -REG-UP, -VMA, ADDR-REG-ID=0, REG-RD-ID=0, REG-LD-ID=0, ALU=0
JSRUR        step  7: -REG-FUNC-RD, -REG-RD-HI, -VMA, -HL-SWAP, -2-BYTE-OPERAND-SEL, ADDR-REG-ID=0, REG-RD-ID=0, REG-LD-ID=0, ALU=0
JSRUR        step  8: -REG-FUNC-RD, -REG-RD-HI, -VMA, -HL-SWAP, BRANCH-LD-HI, -2-BYTE-OPERAND-SEL, ADDR-REG-ID=0, REG-RD-ID=0, REG-LD-ID=0, ALU=0
JSRUR        step  9: -REG-FUNC-RD, -REG-RD-HI, -VMA, -HL-SWAP, -2-BYTE-OPERAND-SEL, ADDR-REG-ID=0, REG-RD-ID=0, REG-LD-ID=0, ALU=0
JSRUR        step 10: -REG-FUNC-RD, -REG-RD-LO, -VMA, -2-BYTE-OPERAND-SEL, ADDR-REG-ID=0, REG-RD-ID=0, REG-LD-ID=0, ALU=0
JSRUR        step 11: -REG-FUNC-RD, -REG-RD-LO, -VMA, BRANCH-LD-LO, -2-BYTE-OPERAND-SEL, ADDR-REG-ID=0, REG-RD-ID=0, REG-LD-ID=0, ALU=0
JSRUR        step 12: -REG-FUNC-RD, -REG-RD-LO, -VMA, -2-BYTE-OPERAND-SEL, ADDR-REG-ID=0, REG-RD-ID=0, REG-LD-ID=0, ALU=0
JSRUR        step 13: -REG-FUNC-RD, -VMA, ADDR-REG-ID=0, REG-RD-ID=0, REG-LD-ID=0, ALU=0
JSRUR        step 14: -REG-FUNC-RD, -REG-RD-HI, -VMA, -HL-SWAP, ADDR-REG-ID=1, REG-RD-ID=0, REG-LD-ID=0, ALU=0
JSRUR        step 15: -REG-FUNC-RD, -REG-RD-HI, -MEM-WR, -VMA, -HL-SWAP, ADDR-REG-ID=1, REG-RD-ID=0, REG-LD-ID=0, ALU=0
JSRUR        step 16: -REG-FUNC-RD, -REG-RD-HI, -VMA, -HL-SWAP, ADDR-REG-ID=1, REG-RD-ID=0, REG-LD-ID=0, ALU=0
JSRUR        step 17: -REG-FUNC-RD, -VMA, -HL-SWAP, ADDR-REG-ID=1, REG-RD-ID=1, REG-LD-ID=0, ALU=0
JSRUR        step 18: -REG-FUNC-RD, -REG-DN, -VMA, -HL-SWAP, ADDR-REG-ID=1, REG-RD-ID=1, REG-LD-ID=0, ALU=0
JSRUR        step 19: -REG-FUNC-RD, -VMA, -HL-SWAP, ADDR-REG-ID=1, REG-RD-ID=1, REG-LD-ID=0, ALU=0
JSRUR        step 20: -REG-FUNC-RD, -REG-RD-LO, -VMA, ADDR-REG-ID=1, REG-RD-ID=0, REG-LD-ID=0, ALU=0
JSRUR        step 21: -REG-FUNC-RD, -REG-RD-LO, -MEM-WR, -VMA, ADDR-REG-ID=1, REG-RD-ID=0, REG-LD-ID=0, ALU=0
JSRUR        step 22: -REG-FUNC-RD, -REG-RD-LO, -VMA, ADDR-REG-ID=1, REG-RD-ID=0, REG-LD-ID=0, ALU=0
JSRUR        step 23: -REG-FUNC-RD, -VMA, ADDR-REG-ID=1, REG-RD-ID=1, REG-LD-ID=0, ALU=0
JSRUR        step 24: -REG-FUNC-RD, -REG-DN, -VMA, ADDR-REG-ID=1, REG-RD-ID=1, REG-LD-ID=0, ALU=0
JSRUR        step 25: -VMA, ADDR-REG-ID=1, REG-RD-ID=1, REG-LD-ID=0, ALU=0
JSRUR        step 26: -REG-FUNC-LD, -VMA, -ALU-FUNC, BR-TEST, -BRANCH-RD, ADDR-REG-ID=1, REG-RD-ID=1, REG-LD-ID=0, ALU=0
JSRUR        step 27: -REG-FUNC-LD, REG-LD-LO, REG-LD-HI, -VMA, -ALU-FUNC, -BRANCH-RD, ADDR-REG-ID=1, REG-RD-ID=1, REG-LD-ID=0, ALU=0
JSRUR        step 28: -REG-FUNC-LD, -VMA, -ALU-FUNC, -BRANCH-RD, ADDR-REG-ID=1, REG-RD-ID=1, REG-LD-ID=0, ALU=0
JSRUR        step 29: -REG-FUNC-LD, -VMA, -ALU-FUNC, UCODE-COUNT-RESET, -BRANCH-RD, ADDR-REG-ID=1, REG-RD-ID=1, REG-LD-ID=0, ALU=0
PUSHR        step  0: -MEM-RD, -VMA, ADDR-REG-ID=0, REG-RD-ID=0, REG-LD-ID=0, ALU=0
PUSHR        step  1: -MEM-RD, -VMA, LD-INS-REG, ADDR-REG-ID=0, REG-RD-ID=0, REG-LD-ID=0, ALU=0
PUSHR        step  2: -REG-FUNC-RD, -REG-UP, -VMA, ADDR-REG-ID=0, REG-RD-ID=0, REG-LD-ID=0, ALU=0
PUSHR        step  3: -MEM-RD, -VMA, ADDR-REG-ID=0, REG-RD-ID=0, REG-LD-ID=0, ALU=0
PUSHR        step  4: -MEM-RD, -VMA, OPERAND-CLK, ADDR-REG-ID=0, REG-RD-ID=0, REG-LD-ID=0, ALU=0
PUSHR        step  5: -MEM-RD, -VMA, ADDR-REG-ID=0, REG-RD-ID=0, REG-LD-ID=0, ALU=0
PUSHR        step  6: -REG-FUNC-RD, -REG-UP, -VMA, ADDR-REG-ID=0, REG-RD-ID=0, REG-LD-ID=0, ALU=0
PUSHR        step  7: -VMA, ADDR-REG-ID=0, REG-RD-ID=0, REG-LD-ID=0, ALU=0
PUSHR        step  8: -REG-FUNC-RD, -REG-RD-HI, -VMA, -HL-SWAP, -2-BYTE-OPERAND-SEL, ADDR-REG-ID=0, REG-RD-ID=0, REG-LD-ID=0, ALU=0
PUSHR        step  9: -REG-FUNC-RD, -REG-RD-HI, -TMP-REG-LD1, -VMA, -HL-SWAP, -2-BYTE-OPERAND-SEL, ADDR-REG-ID=0, REG-RD-ID=0, REG-LD-ID=0, ALU=0
PUSHR        step 10: -REG-FUNC-RD, -REG-RD-HI, -VMA, -HL-SWAP, -2-BYTE-OPERAND-SEL, ADDR-REG-ID=0, REG-RD-ID=0, REG-LD-ID=0, ALU=0
PUSHR        step 11: -TMP-REG-RD1, -VMA, ADDR-REG-ID=1, REG-RD-ID=0, REG-LD-ID=0, ALU=0
PUSHR        step 12: -MEM-WR, -TMP-REG-RD1, -VMA, ADDR-REG-ID=1, REG-RD-ID=0, REG-LD-ID=0, ALU=0
PUSHR        step 13: -TMP-REG-RD1, -VMA, ADDR-REG-ID=1, REG-RD-ID=0, REG-LD-ID=0, ALU=0
PUSHR        step 14: -REG-FUNC-RD, -VMA, ADDR-REG-ID=1, REG-RD-ID=1, REG-LD-ID=0, ALU=0
PUSHR        step 15: -REG-FUNC-RD, -REG-DN, -VMA, ADDR-REG-ID=1, REG-RD-ID=1, REG-LD-ID=0, ALU=0
PUSHR        step 16: -VMA, ADDR-REG-ID=1, REG-RD-ID=1, REG-LD-ID=0, ALU=0
PUSHR        step 17: -REG-FUNC-RD, -REG-RD-LO, -VMA, -2-BYTE-OPERAND-SEL, ADDR-REG-ID=1, REG-RD-ID=1, REG-LD-ID=0, ALU=0
PUSHR        step 18: -REG-FUNC-RD, -REG-RD-LO, -TMP-REG-LD1, -VMA, -2-BYTE-OPERAND-SEL, ADDR-REG-ID=1, REG-RD-ID=1, REG-LD-ID=0, ALU=0
PUSHR        step 19: -REG-FUNC-RD, -REG-RD-LO, -VMA, -2-BYTE-OPERAND-SEL, ADDR-REG-ID=1, REG-RD-ID=1, REG-LD-ID=0, ALU=0
PUSHR        step 20: -TMP-REG-RD1, -VMA, ADDR-REG-ID=1, REG-RD-ID=1, REG-LD-ID=0, ALU=0
PUSHR        step 21: -MEM-WR, -TMP-REG-RD1, -VMA, ADDR-REG-ID=1, REG-RD-ID=1, REG-LD-ID=0, ALU=0
PUSHR        step 22: -TMP-REG-RD1, -VMA, ADDR-REG-ID=1, REG-RD-ID=1, REG-LD-ID=0, ALU=0
PUSHR        step 23: -REG-FUNC-RD, -VMA, ADDR-REG-ID=1, REG-RD-ID=1, REG-LD-ID=0, ALU=0
PUSHR        step 24: -REG-FUNC-RD, -REG-DN, -VMA, ADDR-REG-ID=1, REG-RD-ID=1, REG-LD-ID=0, ALU=0
PUSHR        step 25: -VMA, UCODE-COUNT-RESET, ADDR-REG-ID=1, REG-RD-ID=1, REG-LD-ID=0, ALU=0
POPR         step  0: -MEM-RD, -VMA, ADDR-REG-ID=0, REG-RD-ID=0, REG-LD-ID=0, ALU=0
POPR         step  1: -MEM-RD, -VMA, LD-INS-REG, ADDR-REG-ID=0, REG-RD-ID=0, REG-LD-ID=0, ALU=0
POPR         step  2: -REG-FUNC-RD, -REG-UP, -VMA, ADDR-REG-ID=0, REG-RD-ID=0, REG-LD-ID=0, ALU=0
POPR         step  3: -MEM-RD, -VMA, ADDR-REG-ID=0, REG-RD-ID=0, REG-LD-ID=0, ALU=0
POPR         step  4: -MEM-RD, -VMA, OPERAND-CLK, ADDR-REG-ID=0, REG-RD-ID=0, REG-LD-ID=0, ALU=0
POPR         step  5: -MEM-RD, -VMA, ADDR-REG-ID=0, REG-RD-ID=0, REG-LD-ID=0, ALU=0
POPR         step  6: -REG-FUNC-RD, -REG-UP, -VMA, ADDR-REG-ID=0, REG-RD-ID=0, REG-LD-ID=0, ALU=0
POPR         step  7: -VMA, ADDR-REG-ID=0, REG-RD-ID=0, REG-LD-ID=0, ALU=0
POPR         step  8: -REG-FUNC-RD, -REG-UP, -VMA, ADDR-REG-ID=0, REG-RD-ID=1, REG-LD-ID=0, ALU=0
POPR         step  9: -MEM-RD, -VMA, ADDR-REG-ID=1, REG-RD-ID=1, REG-LD-ID=0, ALU=0
POPR         step 10: -MEM-RD, -VMA, -2-BYTE-OPERAND-SEL, ADDR-REG-ID=1, REG-RD-ID=1, REG-LD-ID=0, ALU=0
POPR         step 11: -REG-FUNC-LD, -MEM-RD, -VMA, -2-BYTE-OPERAND-SEL, ADDR-REG-ID=1, REG-RD-ID=1, REG-LD-ID=0, ALU=0
POPR         step 12: -REG-FUNC-LD, REG-LD-LO, -MEM-RD, -VMA, -2-BYTE-OPERAND-SEL, ADDR-REG-ID=1, REG-RD-ID=1, REG-LD-ID=0, ALU=0
POPR         step 13: -REG-FUNC-LD, -MEM-RD, -VMA, -2-BYTE-OPERAND-SEL, ADDR-REG-ID=1, REG-RD-ID=1, REG-LD-ID=0, ALU=0
POPR         step 14: -MEM-RD, -VMA, -2-BYTE-OPERAND-SEL, ADDR-REG-ID=1, REG-RD-ID=1, REG-LD-ID=0, ALU=0
POPR         step 15: -MEM-RD, -VMA, ADDR-REG-ID=1, REG-RD-ID=1, REG-LD-ID=0, ALU=0
POPR         step 16: -REG-FUNC-RD, -REG-UP, -VMA, ADDR-REG-ID=1, REG-RD-ID=1, REG-LD-ID=0, ALU=0
POPR         step 17: -MEM-RD, -VMA, ADDR-REG-ID=1, REG-RD-ID=1, REG-LD-ID=0, ALU=0
POPR         step 18: -MEM-RD, -VMA, -2-BYTE-OPERAND-SEL, ADDR-REG-ID=1, REG-RD-ID=1, REG-LD-ID=0, ALU=0
POPR         step 19: -REG-FUNC-LD, -MEM-RD, -VMA, -HL-SWAP, -2-BYTE-OPERAND-SEL, ADDR-REG-ID=1, REG-RD-ID=1, REG-LD-ID=0, ALU=0
POPR         step 20: -REG-FUNC-LD, REG-LD-HI, -MEM-RD, -VMA, -HL-SWAP, -2-BYTE-OPERAND-SEL, ADDR-REG-ID=1, REG-RD-ID=1, REG-LD-ID=0, ALU=0
POPR         step 21: -REG-FUNC-LD, -MEM-RD, -VMA, -HL-SWAP, -2-BYTE-OPERAND-SEL, ADDR-REG-ID=1, REG-RD-ID=1, REG-LD-ID=0, ALU=0
POPR         step 22: -MEM-RD, -VMA, -HL-SWAP, -2-BYTE-OPERAND-SEL, ADDR-REG-ID=1, REG-RD-ID=1, REG-LD-ID=0, ALU=0
POPR         step 23: -MEM-RD, -VMA, -HL-SWAP, UCODE-COUNT-RESET, -2-BYTE-OPERAND-SEL, ADDR-REG-ID=1, REG-RD-ID=1, REG-LD-ID=0, ALU=0
PUSH         step  0: -MEM-RD, -VMA, ADDR-REG-ID=0, REG-RD-ID=0, REG-LD-ID=0, ALU=0
PUSH         step  1: -MEM-RD, -VMA, LD-INS-REG, ADDR-REG-ID=0, REG-RD-ID=0, REG-LD-ID=0, ALU=0
PUSH         step  2: -REG-FUNC-RD, -REG-UP, -VMA, ADDR-REG-ID=0, REG-RD-ID=0, REG-LD-ID=0, ALU=0
PUSH         step  3: -VMA, -ALU-FUNC, ADDR-REG-ID=0, REG-RD-ID=0, REG-LD-ID=0, ALU=0
PUSH         step  4: -VMA, -ALU-FUNC, -AC-RD, ADDR-REG-ID=1, REG-RD-ID=0, REG-LD-ID=0, ALU=0
PUSH         step  5: -MEM-WR, -VMA, -ALU-FUNC, -AC-RD, ADDR-REG-ID=1, REG-RD-ID=0, REG-LD-ID=0, ALU=0
PUSH         step  6: -VMA, -ALU-FUNC, -AC-RD, ADDR-REG-ID=1, REG-RD-ID=0, REG-LD-ID=0, ALU=0
PUSH         step  7: -VMA, -ALU-FUNC, ADDR-REG-ID=1, REG-RD-ID=0, REG-LD-ID=0, ALU=0
PUSH         step  8: -REG-FUNC-RD, -VMA, -ALU-FUNC, ADDR-REG-ID=1, REG-RD-ID=1, REG-LD-ID=0, ALU=0
PUSH         step  9: -REG-FUNC-RD, -REG-DN, -VMA, -ALU-FUNC, ADDR-REG-ID=1, REG-RD-ID=1, REG-LD-ID=0, ALU=0
PUSH         step 10: -VMA, -ALU-FUNC, ADDR-REG-ID=1, REG-RD-ID=1, REG-LD-ID=0, ALU=0
PUSH         step 11: -VMA, -ALU-FUNC, UCODE-COUNT-RESET, ADDR-REG-ID=1, REG-RD-ID=1, REG-LD-ID=0, ALU=0
POP          step  0: -MEM-RD, -VMA, ADDR-REG-ID=0, REG-RD-ID=0, REG-LD-ID=0, ALU=0
POP          step  1: -MEM-RD, -VMA, LD-INS-REG, ADDR-REG-ID=0, REG-RD-ID=0, REG-LD-ID=0, ALU=0
POP          step  2: -REG-FUNC-RD, -REG-UP, -VMA, ADDR-REG-ID=0, REG-RD-ID=0, REG-LD-ID=0, ALU=0
POP          step  3: -VMA, ADDR-REG-ID=0, REG-RD-ID=0, REG-LD-ID=0, ALU=0
POP          step  4: -REG-FUNC-RD, -REG-UP, -VMA, ADDR-REG-ID=0, REG-RD-ID=1, REG-LD-ID=0, ALU=0
POP          step  5: -MEM-RD, -VMA, ADDR-REG-ID=1, REG-RD-ID=1, REG-LD-ID=0, ALU=0
POP          step  6: -MEM-RD, -VMA, -ALU-FUNC, ADDR-REG-ID=1, REG-RD-ID=1, REG-LD-ID=0, ALU=0
POP          step  7: -MEM-RD, -VMA, -ALU-FUNC, -AC-LD, ADDR-REG-ID=1, REG-RD-ID=1, REG-LD-ID=0, ALU=0
POP          step  8: -MEM-RD, -VMA, -ALU-FUNC, ADDR-REG-ID=1, REG-RD-ID=1, REG-LD-ID=0, ALU=0
POP          step  9: -MEM-RD, -VMA, -ALU-FUNC, UCODE-COUNT-RESET, ADDR-REG-ID=1, REG-RD-ID=1, REG-LD-ID=0, ALU=0
MVAT         step  0: -MEM-RD, -VMA, ADDR-REG-ID=0, REG-RD-ID=0, REG-LD-ID=0, ALU=0
MVAT         step  1: -MEM-RD, -VMA, LD-INS-REG, ADDR-REG-ID=0, REG-RD-ID=0, REG-LD-ID=0, ALU=0
MVAT         step  2: -REG-FUNC-RD, -REG-UP, -VMA, ADDR-REG-ID=0, REG-RD-ID=0, REG-LD-ID=0, ALU=0
MVAT         step  3: -VMA, -ALU-FUNC, -AC-RD, ADDR-REG-ID=0, REG-RD-ID=0, REG-LD-ID=0, ALU=0
MVAT         step  4: -TMP-REG-LD0, -VMA, -ALU-FUNC, -AC-RD, ADDR-REG-ID=0, REG-RD-ID=0, REG-LD-ID=0, ALU=0
MVAT         step  5: -VMA, -ALU-FUNC, -AC-RD, ADDR-REG-ID=0, REG-RD-ID=0, REG-LD-ID=0, ALU=0
MVAT         step  6: -VMA, -ALU-FUNC, -AC-RD, UCODE-COUNT-RESET, ADDR-REG-ID=0, REG-RD-ID=0, REG-LD-ID=0, ALU=0
MVTA         step  0: -MEM-RD, -VMA, ADDR-REG-ID=0, REG-RD-ID=0, REG-LD-ID=0, ALU=0
MVTA         step  1: -MEM-RD, -VMA, LD-INS-REG, ADDR-REG-ID=0, REG-RD-ID=0, REG-LD-ID=0, ALU=0
MVTA         step  2: -REG-FUNC-RD, -REG-UP, -VMA, ADDR-REG-ID=0, REG-RD-ID=0, REG-LD-ID=0, ALU=0
MVTA         step  3: -TMP-REG-RD0, -VMA, ADDR-REG-ID=0, REG-RD-ID=0, REG-LD-ID=0, ALU=0
MVTA         step  4: -TMP-REG-RD0, -VMA, -ALU-FUNC, ADDR-REG-ID=0, REG-RD-ID=0, REG-LD-ID=0, ALU=0
MVTA         step  5: -TMP-REG-RD0, -VMA, -ALU-FUNC, -AC-LD, ADDR-REG-ID=0, REG-RD-ID=0, REG-LD-ID=0, ALU=0
MVTA         step  6: -TMP-REG-RD0, -VMA, -ALU-FUNC, ADDR-REG-ID=0, REG-RD-ID=0, REG-LD-ID=0, ALU=0
MVTA         step  7: -TMP-REG-RD0, -VMA, -ALU-FUNC, UCODE-COUNT-RESET, ADDR-REG-ID=0, REG-RD-ID=0, REG-LD-ID=0, ALU=0
LDTI         step  0: -MEM-RD, -VMA, ADDR-REG-ID=0, REG-RD-ID=0, REG-LD-ID=0, ALU=0
LDTI         step  1: -MEM-RD, -VMA, LD-INS-REG, ADDR-REG-ID=0, REG-RD-ID=0, REG-LD-ID=0, ALU=0
LDTI         step  2: -REG-FUNC-RD, -REG-UP, -VMA, ADDR-REG-ID=0, REG-RD-ID=0, REG-LD-ID=0, ALU=0
LDTI         step  3: -MEM-RD, -VMA, ADDR-REG-ID=0, REG-RD-ID=0, REG-LD-ID=0, ALU=0
LDTI         step  4: -MEM-RD, -TMP-REG-LD0, -VMA, ADDR-REG-ID=0, REG-RD-ID=0, REG-LD-ID=0, ALU=0
LDTI         step  5: -MEM-RD, -VMA, ADDR-REG-ID=0, REG-RD-ID=0, REG-LD-ID=0, ALU=0
LDTI         step  6: -REG-FUNC-RD, -REG-UP, -VMA, ADDR-REG-ID=0, REG-RD-ID=0, REG-LD-ID=0, ALU=0
LDTI         step  7: -MEM-RD, -VMA, ADDR-REG-ID=0, REG-RD-ID=0, REG-LD-ID=0, ALU=0
LDTI         step  8: -MEM-RD, -VMA, UCODE-COUNT-RESET, ADDR-REG-ID=0, REG-RD-ID=0, REG-LD-ID=0, ALU=0
LDAI         step  0: -MEM-RD, -VMA, ADDR-REG-ID=0, REG-RD-ID=0, REG-LD-ID=0, ALU=0
LDAI         step  1: -MEM-RD, -VMA, LD-INS-REG, ADDR-REG-ID=0, REG-RD-ID=0, REG-LD-ID=0, ALU=0
LDAI         step  2: -REG-FUNC-RD, -REG-UP, -VMA, ADDR-REG-ID=0, REG-RD-ID=0, REG-LD-ID=0, ALU=0
LDAI         step  3: -MEM-RD, -VMA, ADDR-REG-ID=0, REG-RD-ID=0, REG-LD-ID=0, ALU=0
LDAI         step  4: -MEM-RD, -VMA, -ALU-FUNC, ADDR-REG-ID=0, REG-RD-ID=0, REG-LD-ID=0, ALU=0
LDAI         step  5: -MEM-RD, -VMA, -ALU-FUNC, -AC-LD, ADDR-REG-ID=0, REG-RD-ID=0, REG-LD-ID=0, ALU=0
LDAI         step  6: -MEM-RD, -VMA, -ALU-FUNC, ADDR-REG-ID=0, REG-RD-ID=0, REG-LD-ID=0, ALU=0
LDAI         step  7: -REG-FUNC-RD, -REG-UP, -VMA, -ALU-FUNC, ADDR-REG-ID=0, REG-RD-ID=0, REG-LD-ID=0, ALU=0
LDAI         step  8: -MEM-RD, -VMA, -ALU-FUNC, ADDR-REG-ID=0, REG-RD-ID=0, REG-LD-ID=0, ALU=0
LDAI         step  9: -MEM-RD, -VMA, -ALU-FUNC, UCODE-COUNT-RESET, ADDR-REG-ID=0, REG-RD-ID=0, REG-LD-ID=0, ALU=0
MOVRR        step  0: -MEM-RD, -VMA, ADDR-REG-ID=0, REG-RD-ID=0, REG-LD-ID=0, ALU=0
MOVRR        step  1: -MEM-RD, -VMA, LD-INS-REG, ADDR-REG-ID=0, REG-RD-ID=0, REG-LD-ID=0, ALU=0
MOVRR        step  2: -REG-FUNC-RD, -REG-UP, -VMA, ADDR-REG-ID=0, REG-RD-ID=0, REG-LD-ID=0, ALU=0
MOVRR        step  3: -MEM-RD, -VMA, ADDR-REG-ID=0, REG-RD-ID=0, REG-LD-ID=0, ALU=0
MOVRR        step  4: -MEM-RD, -VMA, OPERAND-CLK, ADDR-REG-ID=0, REG-RD-ID=0, REG-LD-ID=0, ALU=0
MOVRR        step  5: -MEM-RD, -VMA, ADDR-REG-ID=0, REG-RD-ID=0, REG-LD-ID=0, ALU=0
MOVRR        step  6: -REG-FUNC-RD, -REG-UP, -VMA, ADDR-REG-ID=0, REG-RD-ID=0, REG-LD-ID=0, ALU=0
MOVRR        step  7: -VMA, ADDR-REG-ID=0, REG-RD-ID=0, REG-LD-ID=0, ALU=0
MOVRR        step  8: -REG-FUNC-RD, -REG-FUNC-LD, -VMA, -2-BYTE-OPERAND-SEL, ADDR-REG-ID=0, REG-RD-ID=0, REG-LD-ID=0, ALU=0
MOVRR        step  9: -REG-FUNC-RD, -REG-FUNC-LD, -REG-RD-LO, -REG-RD-HI, -VMA, -2-BYTE-OPERAND-SEL, ADDR-REG-ID=0, REG-RD-ID=0, REG-LD-ID=0, ALU=0
MOVRR        step 10: -REG-FUNC-RD, -REG-FUNC-LD, -REG-RD-LO, REG-LD-LO, -REG-RD-HI, REG-LD-HI, -VMA, -2-BYTE-OPERAND-SEL, ADDR-REG-ID=0, REG-RD-ID=0, REG-LD-ID=0, ALU=0
MOVRR        step 11: -REG-FUNC-RD, -REG-FUNC-LD, -REG-RD-LO, -REG-RD-HI, -VMA, -2-BYTE-OPERAND-SEL, ADDR-REG-ID=0, REG-RD-ID=0, REG-LD-ID=0, ALU=0
MOVRR        step 12: -REG-FUNC-RD, -REG-FUNC-LD, -VMA, -2-BYTE-OPERAND-SEL, ADDR-REG-ID=0, REG-RD-ID=0, REG-LD-ID=0, ALU=0
MOVRR        step 13: -REG-FUNC-RD, -REG-FUNC-LD, -VMA, UCODE-COUNT-RESET, -2-BYTE-OPERAND-SEL, ADDR-REG-ID=0, REG-RD-ID=0, REG-LD-ID=0, ALU=0
MVIB         step  0: -MEM-RD, -VMA, ADDR-REG-ID=0, REG-RD-ID=0, REG-LD-ID=0, ALU=0
MVIB         step  1: -MEM-RD, -VMA, LD-INS-REG, ADDR-REG-ID=0, REG-RD-ID=0, REG-LD-ID=0, ALU=0
MVIB         step  2: -REG-FUNC-RD, -REG-UP, -VMA, ADDR-REG-ID=0, REG-RD-ID=0, REG-LD-ID=0, ALU=0
MVIB         step  3: -MEM-RD, -VMA, ADDR-REG-ID=0, REG-RD-ID=0, REG-LD-ID=0, ALU=0
MVIB         step  4: -REG-FUNC-LD, -MEM-RD, -VMA, ADDR-REG-ID=0, REG-RD-ID=0, REG-LD-ID=0, ALU=0
MVIB         step  5: -REG-FUNC-LD, REG-LD-LO, -MEM-RD, -VMA, ADDR-REG-ID=0, REG-RD-ID=0, REG-LD-ID=0, ALU=0
MVIB         step  6: -REG-FUNC-LD, -MEM-RD, -VMA, ADDR-REG-ID=0, REG-RD-ID=0, REG-LD-ID=0, ALU=0
MVIB         step  7: -REG-FUNC-RD, -REG-UP, -VMA, ADDR-REG-ID=0, REG-RD-ID=0, REG-LD-ID=0, ALU=0
MVIB         step  8: -MEM-RD, -VMA, ADDR-REG-ID=0, REG-RD-ID=0, REG-LD-ID=0, ALU=0
MVIB         step  9: -MEM-RD, -VMA, UCODE-COUNT-RESET, ADDR-REG-ID=0, REG-RD-ID=0, REG-LD-ID=0, ALU=0
MVIB R1      step  0: -MEM-RD, -VMA, ADDR-REG-ID=0, REG-RD-ID=0, REG-LD-ID=0, ALU=0
MVIB R1      step  1: -MEM-RD, -VMA, LD-INS-REG, ADDR-REG-ID=0, REG-RD-ID=0, REG-LD-ID=0, ALU=0
MVIB R1      step  2: -REG-FUNC-RD, -REG-UP, -VMA, ADDR-REG-ID=0, REG-RD-ID=0, REG-LD-ID=0, ALU=0
MVIB R1      step  3: -MEM-RD, -VMA, ADDR-REG-ID=0, REG-RD-ID=0, REG-LD-ID=0, ALU=0
MVIB R1      step  4: -REG-FUNC-LD, -MEM-RD, -VMA, ADDR-REG-ID=0, REG-RD-ID=0, REG-LD-ID=1, ALU=0
MVIB R1      step  5: -REG-FUNC-LD, REG-LD-LO, -MEM-RD, -VMA, ADDR-REG-ID=0, REG-RD-ID=0, REG-LD-ID=1, ALU=0
MVIB R1      step  6: -REG-FUNC-LD, -MEM-RD, -VMA, ADDR-REG-ID=0, REG-RD-ID=0, REG-LD-ID=1, ALU=0
MVIB R1      step  7: -REG-FUNC-RD, -REG-UP, -VMA, ADDR-REG-ID=0, REG-RD-ID=0, REG-LD-ID=1, ALU=0
MVIB R1      step  8: -MEM-RD, -VMA, ADDR-REG-ID=0, REG-RD-ID=0, REG-LD-ID=1, ALU=0
MVIB R1      step  9: -MEM-RD, -VMA, UCODE-COUNT-RESET, ADDR-REG-ID=0, REG-RD-ID=0, REG-LD-ID=1, ALU=0
MVIB R2      step  0: -MEM-RD, -VMA, ADDR-REG-ID=0, REG-RD-ID=0, REG-LD-ID=0, ALU=0
MVIB R2      step  1: -MEM-RD, -VMA, LD-INS-REG, ADDR-REG-ID=0, REG-RD-ID=0, REG-LD-ID=0, ALU=0
MVIB R2      step  2: -REG-FUNC-RD, -REG-UP, -VMA, ADDR-REG-ID=0, REG-RD-ID=0, REG-LD-ID=0, ALU=0
MVIB R2      step  3: -MEM-RD, -VMA, ADDR-REG-ID=0, REG-RD-ID=0, REG-LD-ID=0, ALU=0
MVIB R2      step  4: -REG-FUNC-LD, -MEM-RD, -VMA, ADDR-REG-ID=0, REG-RD-ID=0, REG-LD-ID=2, ALU=0
MVIB R2      step  5: -REG-FUNC-LD, REG-LD-LO, -MEM-RD, -VMA, ADDR-REG-ID=0, REG-RD-ID=0, REG-LD-ID=2, ALU=0
MVIB R2      step  6: -REG-FUNC-LD, -MEM-RD, -VMA, ADDR-REG-ID=0, REG-RD-ID=0, REG-LD-ID=2, ALU=0
MVIB R2      step  7: -REG-FUNC-RD, -REG-UP, -VMA, ADDR-REG-ID=0, REG-RD-ID=0, REG-LD-ID=2, ALU=0
MVIB R2      step  8: -MEM-RD, -VMA, ADDR-REG-ID=0, REG-RD-ID=0, REG-LD-ID=2, ALU=0
MVIB R2      step  9: -MEM-RD, -VMA, UCODE-COUNT-RESET, ADDR-REG-ID=0, REG-RD-ID=0, REG-LD-ID=2, ALU=0
MVIB R3      step  0: -MEM-RD, -VMA, ADDR-REG-ID=0, REG-RD-ID=0, REG-LD-ID=0, ALU=0
MVIB R3      step  1: -MEM-RD, -VMA, LD-INS-REG, ADDR-REG-ID=0, REG-RD-ID=0, REG-LD-ID=0, ALU=0
MVIB R3      step  2: -REG-FUNC-RD, -REG-UP, -VMA, ADDR-REG-ID=0, REG-RD-ID=0, REG-LD-ID=0, ALU=0
MVIB R3      step  3: -MEM-RD, -VMA, ADDR-REG-ID=0, REG-RD-ID=0, REG-LD-ID=0, ALU=0
MVIB R3      step  4: -REG-FUNC-LD, -MEM-RD, -VMA, ADDR-REG-ID=0, REG-RD-ID=0, REG-LD-ID=3, ALU=0
MVIB R3      step  5: -REG-FUNC-LD, REG-LD-LO, -MEM-RD, -VMA, ADDR-REG-ID=0, REG-RD-ID=0, REG-LD-ID=3, ALU=0
MVIB R3      step  6: -REG-FUNC-LD, -MEM-RD, -VMA, ADDR-REG-ID=0, REG-RD-ID=0, REG-LD-ID=3, ALU=0
MVIB R3      step  7: -REG-FUNC-RD, -REG-UP, -VMA, ADDR-REG-ID=0, REG-RD-ID=0, REG-LD-ID=3, ALU=0
MVIB R3      step  8: -MEM-RD, -VMA, ADDR-REG-ID=0, REG-RD-ID=0, REG-LD-ID=3, ALU=0
MVIB R3      step  9: -MEM-RD, -VMA, UCODE-COUNT-RESET, ADDR-REG-ID=0, REG-RD-ID=0, REG-LD-ID=3, ALU=0
MVIB R4      step  0: -MEM-RD, -VMA, ADDR-REG-ID=0, REG-RD-ID=0, REG-LD-ID=0, ALU=0
MVIB R4      step  1: -MEM-RD, -VMA, LD-INS-REG, ADDR-REG-ID=0, REG-RD-ID=0, REG-LD-ID=0, ALU=0
MVIB R4      step  2: -REG-FUNC-RD, -REG-UP, -VMA, ADDR-REG-ID=0, REG-RD-ID=0, REG-LD-ID=0, ALU=0
MVIB R4      step  3: -MEM-RD, -VMA, ADDR-REG-ID=0, REG-RD-ID=0, REG-LD-ID=0, ALU=0
MVIB R4      step  4: -REG-FUNC-LD, -MEM-RD, -VMA, ADDR-REG-ID=0, REG-RD-ID=0, REG-LD-ID=4, ALU=0
MVIB R4      step  5: -REG-FUNC-LD, REG-LD-LO, -MEM-RD, -VMA, ADDR-REG-ID=0, REG-RD-ID=0, REG-LD-ID=4, ALU=0
MVIB R4      step  6: -REG-FUNC-LD, -MEM-RD, -VMA, ADDR-REG-ID=0, REG-RD-ID=0, REG-LD-ID=4, ALU=0
MVIB R4      step  7: -REG-FUNC-RD, -REG-UP, -VMA, ADDR-REG-ID=0, REG-RD-ID=0, REG-LD-ID=4, ALU=0
MVIB R4      step  8: -MEM-RD, -VMA, ADDR-REG-ID=0, REG-RD-ID=0, REG-LD-ID=4, ALU=0
MVIB R4      step  9: -MEM-RD, -VMA, UCODE-COUNT-RESET, ADDR-REG-ID=0, REG-RD-ID=0, REG-LD-ID=4, ALU=0
MVIB R5      step  0: -MEM-RD, -VMA, ADDR-REG-ID=0, REG-RD-ID=0, REG-LD-ID=0, ALU=0
MVIB R5      step  1: -MEM-RD, -VMA, LD-INS-REG, ADDR-REG-ID=0, REG-RD-ID=0, REG-LD-ID=0, ALU=0
MVIB R5      step  2: -REG-FUNC-RD, -REG-UP, -VMA, ADDR-REG-ID=0, REG-RD-ID=0, REG-LD-ID=0, ALU=0
MVIB R5      step  3: -MEM-RD, -VMA, ADDR-REG-ID=0, REG-RD-ID=0, REG-LD-ID=0, ALU=0
MVIB R5      step  4: -REG-FUNC-LD, -MEM-RD, -VMA, ADDR-REG-ID=0, REG-RD-ID=0, REG-LD-ID=5, ALU=0
MVIB R5      step  5: -REG-FUNC-LD, REG-LD-LO, -MEM-RD, -VMA, ADDR-REG-ID=0, REG-RD-ID=0, REG-LD-ID=5, ALU=0
MVIB R5      step  6: -REG-FUNC-LD, -MEM-RD, -VMA, ADDR-REG-ID=0, REG-RD-ID=0, REG-LD-ID=5, ALU=0
MVIB R5      step  7: -REG-FUNC-RD, -REG-UP, -VMA, ADDR-REG-ID=0, REG-RD-ID=0, REG-LD-ID=5, ALU=0
MVIB R5      step  8: -MEM-RD, -VMA, ADDR-REG-ID=0, REG-RD-ID=0, REG-LD-ID=5, ALU=0
MVIB R5      step  9: -MEM-RD, -VMA, UCODE-COUNT-RESET, ADDR-REG-ID=0, REG-RD-ID=0, REG-LD-ID=5, ALU=0
MVIB R6      step  0: -MEM-RD, -VMA, ADDR-REG-ID=0, REG-RD-ID=0, REG-LD-ID=0, ALU=0
MVIB R6      step  1: -MEM-RD, -VMA, LD-INS-REG, ADDR-REG-ID=0, REG-RD-ID=0, REG-LD-ID=0, ALU=0
MVIB R6      step  2: -REG-FUNC-RD, -REG-UP, -VMA, ADDR-REG-ID=0, REG-RD-ID=0, REG-LD-ID=0, ALU=0
MVIB R6      step  3: -MEM-RD, -VMA, ADDR-REG-ID=0, REG-RD-ID=0, REG-LD-ID=0, ALU=0
MVIB R6      step  4: -REG-FUNC-LD, -MEM-RD, -VMA, ADDR-REG-ID=0, REG-RD-ID=0, REG-LD-ID=6, ALU=0
MVIB R6      step  5: -REG-FUNC-LD, REG-LD-LO, -MEM-RD, -VMA, ADDR-REG-ID=0, REG-RD-ID=0, REG-LD-ID=6, ALU=0
MVIB R6      step  6: -REG-FUNC-LD, -MEM-RD, -VMA, ADDR-REG-ID=0, REG-RD-ID=0, REG-LD-ID=6, ALU=0
MVIB R6      step  7: -REG-FUNC-RD, -REG-UP, -VMA, ADDR-REG-ID=0, REG-RD-ID=0, REG-LD-ID=6, ALU=0
MVIB R6      step  8: -MEM-RD, -VMA, ADDR-REG-ID=0, REG-RD-ID=0, REG-LD-ID=6, ALU=0
MVIB R6      step  9: -MEM-RD, -VMA, UCODE-COUNT-RESET, ADDR-REG-ID=0, REG-RD-ID=0, REG-LD-ID=6, ALU=0
MVIB R7      step  0: -MEM-RD, -VMA, ADDR-REG-ID=0, REG-RD-ID=0, REG-LD-ID=0, ALU=0
MVIB R7      step  1: -MEM-RD, -VMA, LD-INS-REG, ADDR-REG-ID=0, REG-RD-ID=0, REG-LD-ID=0, ALU=0
MVIB R7      step  2: -REG-FUNC-RD, -REG-UP, -VMA, ADDR-REG-ID=0, REG-RD-ID=0, REG-LD-ID=0, ALU=0
MVIB R7      step  3: -MEM-RD, -VMA, ADDR-REG-ID=0, REG-RD-ID=0, REG-LD-ID=0, ALU=0
MVIB R7      step  4: -REG-FUNC-LD, -MEM-RD, -VMA, ADDR-REG-ID=0, REG-RD-ID=0, REG-LD-ID=7, ALU=0
MVIB R7      step  5: -REG-FUNC-LD, REG-LD-LO, -MEM-RD, -VMA, ADDR-REG-ID=0, REG-RD-ID=0, REG-LD-ID=7, ALU=0
MVIB R7      step  6: -REG-FUNC-LD, -MEM-RD, -VMA, ADDR-REG-ID=0, REG-RD-ID=0, REG-LD-ID=7, ALU=0
MVIB R7      step  7: -REG-FUNC-RD, -REG-UP, -VMA, ADDR-REG-ID=0, REG-RD-ID=0, REG-LD-ID=7, ALU=0
MVIB R7      step  8: -MEM-RD, -VMA, ADDR-REG-ID=0, REG-RD-ID=0, REG-LD-ID=7, ALU=0
MVIB R7      step  9: -MEM-RD, -VMA, UCODE-COUNT-RESET, ADDR-REG-ID=0, REG-RD-ID=0, REG-LD-ID=7, ALU=0
MVIW         step  0: -MEM-RD, -VMA, ADDR-REG-ID=0, REG-RD-ID=0, REG-LD-ID=0, ALU=0
MVIW         step  1: -MEM-RD, -VMA, LD-INS-REG, ADDR-REG-ID=0, REG-RD-ID=0, REG-LD-ID=0, ALU=0
MVIW         step  2: -REG-FUNC-RD, -REG-UP, -VMA, ADDR-REG-ID=0, REG-RD-ID=0, REG-LD-ID=0, ALU=0
MVIW         step  3: -MEM-RD, -VMA, ADDR-REG-ID=0, REG-RD-ID=0, REG-LD-ID=0, ALU=0
MVIW         step  4: -REG-FUNC-LD, -MEM-RD, -VMA, -HL-SWAP, ADDR-REG-ID=0, REG-RD-ID=0, REG-LD-ID=0, ALU=0
MVIW         step  5: -REG-FUNC-LD, REG-LD-HI, -MEM-RD, -VMA, -HL-SWAP, ADDR-REG-ID=0, REG-RD-ID=0, REG-LD-ID=0, ALU=0
MVIW         step  6: -REG-FUNC-LD, -MEM-RD, -VMA, -HL-SWAP, ADDR-REG-ID=0, REG-RD-ID=0, REG-LD-ID=0, ALU=0
MVIW         step  7: -REG-FUNC-RD, -REG-UP, -VMA, ADDR-REG-ID=0, REG-RD-ID=0, REG-LD-ID=0, ALU=0
MVIW         step  8: -MEM-RD, -VMA, ADDR-REG-ID=0, REG-RD-ID=0, REG-LD-ID=0, ALU=0
MVIW         step  9: -REG-FUNC-LD, -MEM-RD, -VMA, ADDR-REG-ID=0, REG-RD-ID=0, REG-LD-ID=0, ALU=0
MVIW         step 10: -REG-FUNC-LD, REG-LD-LO, -MEM-RD, -VMA, ADDR-REG-ID=0, REG-RD-ID=0, REG-LD-ID=0, ALU=0
MVIW         step 11: -REG-FUNC-LD, -MEM-RD, -VMA, ADDR-REG-ID=0, REG-RD-ID=0, REG-LD-ID=0, ALU=0
MVIW         step 12: -REG-FUNC-RD, -REG-UP, -VMA, ADDR-REG-ID=0, REG-RD-ID=0, REG-LD-ID=0, ALU=0
MVIW         step 13: -MEM-RD, -VMA, ADDR-REG-ID=0, REG-RD-ID=0, REG-LD-ID=0, ALU=0
MVIW         step 14: -MEM-RD, -VMA, UCODE-COUNT-RESET, ADDR-REG-ID=0, REG-RD-ID=0, REG-LD-ID=0, ALU=0
MVIW R1      step  0: -MEM-RD, -VMA, ADDR-REG-ID=0, REG-RD-ID=0, REG-LD-ID=0, ALU=0
MVIW R1      step  1: -MEM-RD, -VMA, LD-INS-REG, ADDR-REG-ID=0, REG-RD-ID=0, REG-LD-ID=0, ALU=0
MVIW R1      step  2: -REG-FUNC-RD, -REG-UP, -VMA, ADDR-REG-ID=0, REG-RD-ID=0, REG-LD-ID=0, ALU=0
MVIW R1      step  3: -MEM-RD, -VMA, ADDR-REG-ID=0, REG-RD-ID=0, REG-LD-ID=0, ALU=0
MVIW R1      step  4: -REG-FUNC-LD, -MEM-RD, -VMA, -HL-SWAP, ADDR-REG-ID=0, REG-RD-ID=0, REG-LD-ID=1, ALU=0
MVIW R1      step  5: -REG-FUNC-LD, REG-LD-HI, -MEM-RD, -VMA, -HL-SWAP, ADDR-REG-ID=0, REG-RD-ID=0, REG-LD-ID=1, ALU=0
MVIW R1      step  6: -REG-FUNC-LD, -MEM-RD, -VMA, -HL-SWAP, ADDR-REG-ID=0, REG-RD-ID=0, REG-LD-ID=1, ALU=0
MVIW R1      step  7: -REG-FUNC-RD, -REG-UP, -VMA, ADDR-REG-ID=0, REG-RD-ID=0, REG-LD-ID=1, ALU=0
MVIW R1      step  8: -MEM-RD, -VMA, ADDR-REG-ID=0, REG-RD-ID=0, REG-LD-ID=1, ALU=0
MVIW R1      step  9: -REG-FUNC-LD, -MEM-RD, -VMA, ADDR-REG-ID=0, REG-RD-ID=0, REG-LD-ID=1, ALU=0
MVIW R1      step 10: -REG-FUNC-LD, REG-LD-LO, -MEM-RD, -VMA, ADDR-REG-ID=0, REG-RD-ID=0, REG-LD-ID=1, ALU=0
MVIW R1      step 11: -REG-FUNC-LD, -MEM-RD, -VMA, ADDR-REG-ID=0, REG-RD-ID=0, REG-LD-ID=1, ALU=0
MVIW R1      step 12: -REG-FUNC-RD, -REG-UP, -VMA, ADDR-REG-ID=0, REG-RD-ID=0, REG-LD-ID=1, ALU=0
MVIW R1      step 13: -MEM-RD, -VMA, ADDR-REG-ID=0, REG-RD-ID=0, REG-LD-ID=1, ALU=0
MVIW R1      step 14: -MEM-RD, -VMA, UCODE-COUNT-RESET, ADDR-REG-ID=0, REG-RD-ID=0, REG-LD-ID=1, ALU=0
MVIW R2      step  0: -MEM-RD, -VMA, ADDR-REG-ID=0, REG-RD-ID=0, REG-LD-ID=0, ALU=0
MVIW R2      step  1: -MEM-RD, -VMA, LD-INS-REG, ADDR-REG-ID=0, REG-RD-ID=0, REG-LD-ID=0, ALU=0
MVIW R2      step  2: -REG-FUNC-RD, -REG-UP, -VMA, ADDR-REG-ID=0, REG-RD-ID=0, REG-LD-ID=0, ALU=0
MVIW R2      step  3: -MEM-RD, -VMA, ADDR-REG-ID=0, REG-RD-ID=0, REG-LD-ID=0, ALU=0
MVIW R2      step  4: -REG-FUNC-LD, -MEM-RD, -VMA, -HL-SWAP, ADDR-REG-ID=0, REG-RD-ID=0, REG-LD-ID=2, ALU=0
MVIW R2      step  5: -REG-FUNC-LD, REG-LD-HI, -MEM-RD, -VMA, -HL-SWAP, ADDR-REG-ID=0, REG-RD-ID=0, REG-LD-ID=2, ALU=0
MVIW R2      step  6: -REG-FUNC-LD, -MEM-RD, -VMA, -HL-SWAP, ADDR-REG-ID=0, REG-RD-ID=0, REG-LD-ID=2, ALU=0
MVIW R2      step  7: -REG-FUNC-RD, -REG-UP, -VMA, ADDR-REG-ID=0, REG-RD-ID=0, REG-LD-ID=2, ALU=0
MVIW R2      step  8: -MEM-RD, -VMA, ADDR-REG-ID=0, REG-RD-ID=0, REG-LD-ID=2, ALU=0
MVIW R2      step  9: -REG-FUNC-LD, -MEM-RD, -VMA, ADDR-REG-ID=0, REG-RD-ID=0, REG-LD-ID=2, ALU=0
MVIW R2      step 10: -REG-FUNC-LD, REG-LD-LO, -MEM-RD, -VMA, ADDR-REG-ID=0, REG-RD-ID=0, REG-LD-ID=2, ALU=0
MVIW R2      step 11: -REG-FUNC-LD, -MEM-RD, -VMA, ADDR-REG-ID=0, REG-RD-ID=0, REG-LD-ID=2, ALU=0
MVIW R2      step 12: -REG-FUNC-RD, -REG-UP, -VMA, ADDR-REG-ID=0, REG-RD-ID=0, REG-LD-ID=2, ALU=0
MVIW R2      step 13: -MEM-RD, -VMA, ADDR-REG-ID=0, REG-RD-ID=0, REG-LD-ID=2, ALU=0
MVIW R2      step 14: -MEM-RD, -VMA, UCODE-COUNT-RESET, ADDR-REG-ID=0, REG-RD-ID=0, REG-LD-ID=2, ALU=0
MVIW R3      step  0: -MEM-RD, -VMA, ADDR-REG-ID=0, REG-RD-ID=0, REG-LD-ID=0, ALU=0
MVIW R3      step  1: -MEM-RD, -VMA, LD-INS-REG, ADDR-REG-ID=0, REG-RD-ID=0, REG-LD-ID=0, ALU=0
MVIW R3      step  2: -REG-FUNC-RD, -REG-UP, -VMA, ADDR-REG-ID=0, REG-RD-ID=0, REG-LD-ID=0, ALU=0
MVIW R3      step  3: -MEM-RD, -VMA, ADDR-REG-ID=0, REG-RD-ID=0, REG-LD-ID=0, ALU=0
MVIW R3      step  4: -REG-FUNC-LD, -MEM-RD, -VMA, -HL-SWAP, ADDR-REG-ID=0, REG-RD-ID=0, REG-LD-ID=3, ALU=0
MVIW R3      step  5: -REG-FUNC-LD, REG-LD-HI, -MEM-RD, -VMA, -HL-SWAP, ADDR-REG-ID=0, REG-RD-ID=0, REG-LD-ID=3, ALU=0
MVIW R3      step  6: -REG-FUNC-LD, -MEM-RD, -VMA, -HL-SWAP, ADDR-REG-ID=0, REG-RD-ID=0, REG-LD-ID=3, ALU=0
MVIW R3      step  7: -REG-FUNC-RD, -REG-UP, -VMA, ADDR-REG-ID=0, REG-RD-ID=0, REG-LD-ID=3, ALU=0
MVIW R3      step  8: -MEM-RD, -VMA, ADDR-REG-ID=0, REG-RD-ID=0, REG-LD-ID=3, ALU=0
MVIW R3      step  9: -REG-FUNC-LD, -MEM-RD, -VMA, ADDR-REG-ID=0, REG-RD-ID=0, REG-LD-ID=3, ALU=0
MVIW R3      step 10: -REG-FUNC-LD, REG-LD-LO, -MEM-RD, -VMA, ADDR-REG-ID=0, REG-RD-ID=0, REG-LD-ID=3, ALU=0
MVIW R3      step 11: -REG-FUNC-LD, -MEM-RD, -VMA, ADDR-REG-ID=0, REG-RD-ID=0, REG-LD-ID=3, ALU=0
MVIW R3      step 12: -REG-FUNC-RD, -REG-UP, -VMA, ADDR-REG-ID=0, REG-RD-ID=0, REG-LD-ID=3, ALU=0
MVIW R3      step 13: -MEM-RD, -VMA, ADDR-REG-ID=0, REG-RD-ID=0, REG-LD-ID=3, ALU=0
MVIW R3      step 14: -MEM-RD, -VMA, UCODE-COUNT-RESET, ADDR-REG-ID=0, REG-RD-ID=0, REG-LD-ID=3, ALU=0
MVIW R4      step  0: -MEM-RD, -VMA, ADDR-REG-ID=0, REG-RD-ID=0, REG-LD-ID=0, ALU=0
MVIW R4      step  1: -MEM-RD, -VMA, LD-INS-REG, ADDR-REG-ID=0, REG-RD-ID=0, REG-LD-ID=0, ALU=0
MVIW R4      step  2: -REG-FUNC-RD, -REG-UP, -VMA, ADDR-REG-ID=0, REG-RD-ID=0, REG-LD-ID=0, ALU=0
MVIW R4      step  3: -MEM-RD, -VMA, ADDR-REG-ID=0, REG-RD-ID=0, REG-LD-ID=0, ALU=0
MVIW R4      step  4: -REG-FUNC-LD, -MEM-RD, -VMA, -HL-SWAP, ADDR-REG-ID=0, REG-RD-ID=0, REG-LD-ID=4, ALU=0
MVIW R4      step  5: -REG-FUNC-LD, REG-LD-HI, -MEM-RD, -VMA, -HL-SWAP, ADDR-REG-ID=0, REG-RD-ID=0, REG-LD-ID=4, ALU=0
MVIW R4      step  6: -REG-FUNC-LD, -MEM-RD, -VMA, -HL-SWAP, ADDR-REG-ID=0, REG-RD-ID=0, REG-LD-ID=4, ALU=0
MVIW R4      step  7: -REG-FUNC-RD, -REG-UP, -VMA, ADDR-REG-ID=0, REG-RD-ID=0, REG-LD-ID=4, ALU=0
MVIW R4      step  8: -MEM-RD, -VMA, ADDR-REG-ID=0, REG-RD-ID=0, REG-LD-ID=4, ALU=0
MVIW R4      step  9: -REG-FUNC-LD, -MEM-RD, -VMA, ADDR-REG-ID=0, REG-RD-ID=0, REG-LD-ID=4, ALU=0
MVIW R4      step 10: -REG-FUNC-LD, REG-LD-LO, -MEM-RD, -VMA, ADDR-REG-ID=0, REG-RD-ID=0, REG-LD-ID=4, ALU=0
MVIW R4      step 11: -REG-FUNC-LD, -MEM-RD, -VMA, ADDR-REG-ID=0, REG-RD-ID=0, REG-LD-ID=4, ALU=0
MVIW R4      step 12: -REG-FUNC-RD, -REG-UP, -VMA, ADDR-REG-ID=0, REG-RD-ID=0, REG-LD-ID=4, ALU=0
MVIW R4      step 13: -MEM-RD, -VMA, ADDR-REG-ID=0, REG-RD-ID=0, REG-LD-ID=4, ALU=0
MVIW R4      step 14: -MEM-RD, -VMA, UCODE-COUNT-RESET, ADDR-REG-ID=0, REG-RD-ID=0, REG-LD-ID=4, ALU=0
MVIW R5      step  0: -MEM-RD, -VMA, ADDR-REG-ID=0, REG-RD-ID=0, REG-LD-ID=0, ALU=0
MVIW R5      step  1: -MEM-RD, -VMA, LD-INS-REG, ADDR-REG-ID=0, REG-RD-ID=0, REG-LD-ID=0, ALU=0
MVIW R5      step  2: -REG-FUNC-RD, -REG-UP, -VMA, ADDR-REG-ID=0, REG-RD-ID=0, REG-LD-ID=0, ALU=0
MVIW R5      step  3: -MEM-RD, -VMA, ADDR-REG-ID=0, REG-RD-ID=0, REG-LD-ID=0, ALU=0
MVIW R5      step  4: -REG-FUNC-LD, -MEM-RD, -VMA, -HL-SWAP, ADDR-REG-ID=0, REG-RD-ID=0, REG-LD-ID=5, ALU=0
MVIW R5      step  5: -REG-FUNC-LD, REG-LD-HI, -MEM-RD, -VMA, -HL-SWAP, ADDR-REG-ID=0, REG-RD-ID=0, REG-LD-ID=5, ALU=0
MVIW R5      step  6: -REG-FUNC-LD, -MEM-RD, -VMA, -HL-SWAP, ADDR-REG-ID=0, REG-RD-ID=0, REG-LD-ID=5, ALU=0
MVIW R5      step  7: -REG-FUNC-RD, -REG-UP, -VMA, ADDR-REG-ID=0, REG-RD-ID=0, REG-LD-ID=5, ALU=0
MVIW R5      step  8: -MEM-RD, -VMA, ADDR-REG-ID=0, REG-RD-ID=0, REG-LD-ID=5, ALU=0
MVIW R5      step  9: -REG-FUNC-LD, -MEM-RD, -VMA, ADDR-REG-ID=0, REG-RD-ID=0, REG-LD-ID=5, ALU=0
MVIW R5      step 10: -REG-FUNC-LD, REG-LD-LO, -MEM-RD, -VMA, ADDR-REG-ID=0, REG-RD-ID=0, REG-LD-ID=5, ALU=0
MVIW R5      step 11: -REG-FUNC-LD, -MEM-RD, -VMA, ADDR-REG-ID=0, REG-RD-ID=0, REG-LD-ID=5, ALU=0
MVIW R5      step 12: -REG-FUNC-RD, -REG-UP, -VMA, ADDR-REG-ID=0, REG-RD-ID=0, REG-LD-ID=5, ALU=0
MVIW R5      step 13: -MEM-RD, -VMA, ADDR-REG-ID=0, REG-RD-ID=0, REG-LD-ID=5, ALU=0
MVIW R5      step 14: -MEM-RD, -VMA, UCODE-COUNT-RESET, ADDR-REG-ID=0, REG-RD-ID=0, REG-LD-ID=5, ALU=0
MVIW R6      step  0: -MEM-RD, -VMA, ADDR-REG-ID=0, REG-RD-ID=0, REG-LD-ID=0, ALU=0
MVIW R6      step  1: -MEM-RD, -VMA, LD-INS-REG, ADDR-REG-ID=0, REG-RD-ID=0, REG-LD-ID=0, ALU=0
MVIW R6      step  2: -REG-FUNC-RD, -REG-UP, -VMA, ADDR-REG-ID=0, REG-RD-ID=0, REG-LD-ID=0, ALU=0
MVIW R6      step  3: -MEM-RD, -VMA, ADDR-REG-ID=0, REG-RD-ID=0, REG-LD-ID=0, ALU=0
MVIW R6      step  4: -REG-FUNC-LD, -MEM-RD, -VMA, -HL-SWAP, ADDR-REG-ID=0, REG-RD-ID=0, REG-LD-ID=6, ALU=0
MVIW R6      step  5: -REG-FUNC-LD, REG-LD-HI, -MEM-RD, -VMA, -HL-SWAP, ADDR-REG-ID=0, REG-RD-ID=0, REG-LD-ID=6, ALU=0
MVIW R6      step  6: -REG-FUNC-LD, -MEM-RD, -VMA, -HL-SWAP, ADDR-REG-ID=0, REG-RD-ID=0, REG-LD-ID=6, ALU=0
MVIW R6      step  7: -REG-FUNC-RD, -REG-UP, -VMA, ADDR-REG-ID=0, REG-RD-ID=0, REG-LD-ID=6, ALU=0
MVIW R6      step  8: -MEM-RD, -VMA, ADDR-REG-ID=0, REG-RD-ID=0, REG-LD-ID=6, ALU=0
MVIW R6      step  9: -REG-FUNC-LD, -MEM-RD, -VMA, ADDR-REG-ID=0, REG-RD-ID=0, REG-LD-ID=6, ALU=0
MVIW R6      step 10: -REG-FUNC-LD, REG-LD-LO, -MEM-RD, -VMA, ADDR-REG-ID=0, REG-RD-ID=0, REG-LD-ID=6, ALU=0
MVIW R6      step 11: -REG-FUNC-LD, -MEM-RD, -VMA, ADDR-REG-ID=0, REG-RD-ID=0, REG-LD-ID=6, ALU=0
MVIW R6      step 12: -REG-FUNC-RD, -REG-UP, -VMA, ADDR-REG-ID=0, REG-RD-ID=0, REG-LD-ID=6, ALU=0
MVIW R6      step 13: -MEM-RD, -VMA, ADDR-REG-ID=0, REG-RD-ID=0, REG-LD-ID=6, ALU=0
MVIW R6      step 14: -MEM-RD, -VMA, UCODE-COUNT-RESET, ADDR-REG-ID=0, REG-RD-ID=0, REG-LD-ID=6, ALU=0
MVIW R7      step  0: -MEM-RD, -VMA, ADDR-REG-ID=0, REG-RD-ID=0, REG-LD-ID=0, ALU=0
MVIW R7      step  1: -MEM-RD, -VMA, LD-INS-REG, ADDR-REG-ID=0, REG-RD-ID=0, REG-LD-ID=0, ALU=0
MVIW R7      step  2: -REG-FUNC-RD, -REG-UP, -VMA, ADDR-REG-ID=0, REG-RD-ID=0, REG-LD-ID=0, ALU=0
MVIW R7      step  3: -MEM-RD, -VMA, ADDR-REG-ID=0, REG-RD-ID=0, REG-LD-ID=0, ALU=0
MVIW R7      step  4: -REG-FUNC-LD, -MEM-RD, -VMA, -HL-SWAP, ADDR-REG-ID=0, REG-RD-ID=0, REG-LD-ID=7, ALU=0
MVIW R7      step  5: -REG-FUNC-LD, REG-LD-HI, -MEM-RD, -VMA, -HL-SWAP, ADDR-REG-ID=0, REG-RD-ID=0, REG-LD-ID=7, ALU=0
MVIW R7      step  6: -REG-FUNC-LD, -MEM-RD, -VMA, -HL-SWAP, ADDR-REG-ID=0, REG-RD-ID=0, REG-LD-ID=7, ALU=0
MVIW R7      step  7: -REG-FUNC-RD, -REG-UP, -VMA, ADDR-REG-ID=0, REG-RD-ID=0, REG-LD-ID=7, ALU=0
MVIW R7      step  8: -MEM-RD, -VMA, ADDR-REG-ID=0, REG-RD-ID=0, REG-LD-ID=7, ALU=0
MVIW R7      step  9: -REG-FUNC-LD, -MEM-RD, -VMA, ADDR-REG-ID=0, REG-RD-ID=0, REG-LD-ID=7, ALU=0
MVIW R7      step 10: -REG-FUNC-LD, REG-LD-LO, -MEM-RD, -VMA, ADDR-REG-ID=0, REG-RD-ID=0, REG-LD-ID=7, ALU=0
MVIW R7      step 11: -REG-FUNC-LD, -MEM-RD, -VMA, ADDR-REG-ID=0, REG-RD-ID=0, REG-LD-ID=7, ALU=0
MVIW R7      step 12: -REG-FUNC-RD, -REG-UP, -VMA, ADDR-REG-ID=0, REG-RD-ID=0, REG-LD-ID=7, ALU=0
MVIW R7      step 13: -MEM-RD, -VMA, ADDR-REG-ID=0, REG-RD-ID=0, REG-LD-ID=7, ALU=0
MVIW R7      step 14: -MEM-RD, -VMA, UCODE-COUNT-RESET, ADDR-REG-ID=0, REG-RD-ID=0, REG-LD-ID=7, ALU=0
MVRLA        step  0: -MEM-RD, -VMA, ADDR-REG-ID=0, REG-RD-ID=0, REG-LD-ID=0, ALU=0
MVRLA        step  1: -MEM-RD, -VMA, LD-INS-REG, ADDR-REG-ID=0, REG-RD-ID=0, REG-LD-ID=0, ALU=0
MVRLA        step  2: -REG-FUNC-RD, -REG-UP, -VMA, ADDR-REG-ID=0, REG-RD-ID=0, REG-LD-ID=0, ALU=0
MVRLA        step  3: -REG-FUNC-RD, -REG-RD-LO, -VMA, -ALU-FUNC, ADDR-REG-ID=0, REG-RD-ID=0, REG-LD-ID=0, ALU=0
MVRLA        step  4: -REG-FUNC-RD, -REG-RD-LO, -VMA, -ALU-FUNC, -AC-LD, ADDR-REG-ID=0, REG-RD-ID=0, REG-LD-ID=0, ALU=0
MVRLA        step  5: -REG-FUNC-RD, -REG-RD-LO, -VMA, -ALU-FUNC, ADDR-REG-ID=0, REG-RD-ID=0, REG-LD-ID=0, ALU=0
MVRLA        step  6: -REG-FUNC-RD, -REG-RD-LO, -VMA, -ALU-FUNC, UCODE-COUNT-RESET, ADDR-REG-ID=0, REG-RD-ID=0, REG-LD-ID=0, ALU=0
MVRLA R1     step  0: -MEM-RD, -VMA, ADDR-REG-ID=0, REG-RD-ID=0, REG-LD-ID=0, ALU=0
MVRLA R1     step  1: -MEM-RD, -VMA, LD-INS-REG, ADDR-REG-ID=0, REG-RD-ID=0, REG-LD-ID=0, ALU=0
MVRLA R1     step  2: -REG-FUNC-RD, -REG-UP, -VMA, ADDR-REG-ID=0, REG-RD-ID=0, REG-LD-ID=0, ALU=0
MVRLA R1     step  3: -VMA, ADDR-REG-ID=0, REG-RD-ID=0, REG-LD-ID=0, ALU=0
MVRLA R1     step  4: -REG-FUNC-RD, -REG-RD-LO, -VMA, -ALU-FUNC, ADDR-REG-ID=0, REG-RD-ID=1, REG-LD-ID=0, ALU=0
MVRLA R1     step  5: -REG-FUNC-RD, -REG-RD-LO, -VMA, -ALU-FUNC, -AC-LD, ADDR-REG-ID=0, REG-RD-ID=1, REG-LD-ID=0, ALU=0
MVRLA R1     step  6: -REG-FUNC-RD, -REG-RD-LO, -VMA, -ALU-FUNC, ADDR-REG-ID=0, REG-RD-ID=1, REG-LD-ID=0, ALU=0
MVRLA R1     step  7: -REG-FUNC-RD, -REG-RD-LO, -VMA, -ALU-FUNC, UCODE-COUNT-RESET, ADDR-REG-ID=0, REG-RD-ID=1, REG-LD-ID=0, ALU=0
MVRLA R2     step  0: -MEM-RD, -VMA, ADDR-REG-ID=0, REG-RD-ID=0, REG-LD-ID=0, ALU=0
MVRLA R2     step  1: -MEM-RD, -VMA, LD-INS-REG, ADDR-REG-ID=0, REG-RD-ID=0, REG-LD-ID=0, ALU=0
MVRLA R2     step  2: -REG-FUNC-RD, -REG-UP, -VMA, ADDR-REG-ID=0, REG-RD-ID=0, REG-LD-ID=0, ALU=0
MVRLA R2     step  3: -VMA, ADDR-REG-ID=0, REG-RD-ID=0, REG-LD-ID=0, ALU=0
MVRLA R2     step  4: -REG-FUNC-RD, -REG-RD-LO, -VMA, -ALU-FUNC, ADDR-REG-ID=0, REG-RD-ID=2, REG-LD-ID=0, ALU=0
MVRLA R2     step  5: -REG-FUNC-RD, -REG-RD-LO, -VMA, -ALU-FUNC, -AC-LD, ADDR-REG-ID=0, REG-RD-ID=2, REG-LD-ID=0, ALU=0
MVRLA R2     step  6: -REG-FUNC-RD, -REG-RD-LO, -VMA, -ALU-FUNC, ADDR-REG-ID=0, REG-RD-ID=2, REG-LD-ID=0, ALU=0
MVRLA R2     step  7: -REG-FUNC-RD, -REG-RD-LO, -VMA, -ALU-FUNC, UCODE-COUNT-RESET, ADDR-REG-ID=0, REG-RD-ID=2, REG-LD-ID=0, ALU=0
MVRLA R3     step  0: -MEM-RD, -VMA, ADDR-REG-ID=0, REG-RD-ID=0, REG-LD-ID=0, ALU=0
MVRLA R3     step  1: -MEM-RD, -VMA, LD-INS-REG, ADDR-REG-ID=0, REG-RD-ID=0, REG-LD-ID=0, ALU=0
MVRLA R3     step  2: -REG-FUNC-RD, -REG-UP, -VMA, ADDR-REG-ID=0, REG-RD-ID=0, REG-LD-ID=0, ALU=0
MVRLA R3     step  3: -VMA, ADDR-REG-ID=0, REG-RD-ID=0, REG-LD-ID=0, ALU=0
MVRLA R3     step  4: -REG-FUNC-RD, -REG-RD-LO, -VMA, -ALU-FUNC, ADDR-REG-ID=0, REG-RD-ID=3, REG-LD-ID=0, ALU=0
MVRLA R3     step  5: -REG-FUNC-RD, -REG-RD-LO, -VMA, -ALU-FUNC, -AC-LD, ADDR-REG-ID=0, REG-RD-ID=3, REG-LD-ID=0, ALU=0
MVRLA R3     step  6: -REG-FUNC-RD, -REG-RD-LO, -VMA, -ALU-FUNC, ADDR-REG-ID=0, REG-RD-ID=3, REG-LD-ID=0, ALU=0
MVRLA R3     step  7: -REG-FUNC-RD, -REG-RD-LO, -VMA, -ALU-FUNC, UCODE-COUNT-RESET, ADDR-REG-ID=0, REG-RD-ID=3, REG-LD-ID=0, ALU=0
MVRLA R4     step  0: -MEM-RD, -VMA, ADDR-REG-ID=0, REG-RD-ID=0, REG-LD-ID=0, ALU=0
MVRLA R4     step  1: -MEM-RD, -VMA, LD-INS-REG, ADDR-REG-ID=0, REG-RD-ID=0, REG-LD-ID=0, ALU=0
MVRLA R4     step  2: -REG-FUNC-RD, -REG-UP, -VMA, ADDR-REG-ID=0, REG-RD-ID=0, REG-LD-ID=0, ALU=0
MVRLA R4     step  3: -VMA, ADDR-REG-ID=0, REG-RD-ID=0, REG-LD-ID=0, ALU=0
MVRLA R4     step  4: -REG-FUNC-RD, -REG-RD-LO, -VMA, -ALU-FUNC, ADDR-REG-ID=0, REG-RD-ID=4, REG-LD-ID=0, ALU=0
MVRLA R4     step  5: -REG-FUNC-RD, -REG-RD-LO, -VMA, -ALU-FUNC, -AC-LD, ADDR-REG-ID=0, REG-RD-ID=4, REG-LD-ID=0, ALU=0
MVRLA R4     step  6: -REG-FUNC-RD, -REG-RD-LO, -VMA, -ALU-FUNC, ADDR-REG-ID=0, REG-RD-ID=4, REG-LD-ID=0, ALU=0
MVRLA R4     step  7: -REG-FUNC-RD, -REG-RD-LO, -VMA, -ALU-FUNC, UCODE-COUNT-RESET, ADDR-REG-ID=0, REG-RD-ID=4, REG-LD-ID=0, ALU=0
MVRLA R5     step  0: -MEM-RD, -VMA, ADDR-REG-ID=0, REG-RD-ID=0, REG-LD-ID=0, ALU=0
MVRLA R5     step  1: -MEM-RD, -VMA, LD-INS-REG, ADDR-REG-ID=0, REG-RD-ID=0, REG-LD-ID=0, ALU=0
MVRLA R5     step  2: -REG-FUNC-RD, -REG-UP, -VMA, ADDR-REG-ID=0, REG-RD-ID=0, REG-LD-ID=0, ALU=0
MVRLA R5     step  3: -VMA, ADDR-REG-ID=0, REG-RD-ID=0, REG-LD-ID=0, ALU=0
MVRLA R5     step  4: -REG-FUNC-RD, -REG-RD-LO, -VMA, -ALU-FUNC, ADDR-REG-ID=0, REG-RD-ID=5, REG-LD-ID=0, ALU=0
MVRLA R5     step  5: -REG-FUNC-RD, -REG-RD-LO, -VMA, -ALU-FUNC, -AC-LD, ADDR-REG-ID=0, REG-RD-ID=5, REG-LD-ID=0, ALU=0
MVRLA R5     step  6: -REG-FUNC-RD, -REG-RD-LO, -VMA, -ALU-FUNC, ADDR-REG-ID=0, REG-RD-ID=5, REG-LD-ID=0, ALU=0
MVRLA R5     step  7: -REG-FUNC-RD, -REG-RD-LO, -VMA, -ALU-FUNC, UCODE-COUNT-RESET, ADDR-REG-ID=0, REG-RD-ID=5, REG-LD-ID=0, ALU=0
MVRLA R6     step  0: -MEM-RD, -VMA, ADDR-REG-ID=0, REG-RD-ID=0, REG-LD-ID=0, ALU=0
MVRLA R6     step  1: -MEM-RD, -VMA, LD-INS-REG, ADDR-REG-ID=0, REG-RD-ID=0, REG-LD-ID=0, ALU=0
MVRLA R6     step  2: -REG-FUNC-RD, -REG-UP, -VMA, ADDR-REG-ID=0, REG-RD-ID=0, REG-LD-ID=0, ALU=0
MVRLA R6     step  3: -VMA, ADDR-REG-ID=0, REG-RD-ID=0, REG-LD-ID=0, ALU=0
MVRLA R6     step  4: -REG-FUNC-RD, -REG-RD-LO, -VMA, -ALU-FUNC, ADDR-REG-ID=0, REG-RD-ID=6, REG-LD-ID=0, ALU=0
MVRLA R6     step  5: -REG-FUNC-RD, -REG-RD-LO, -VMA, -ALU-FUNC, -AC-LD, ADDR-REG-ID=0, REG-RD-ID=6, REG-LD-ID=0, ALU=0
MVRLA R6     step  6: -REG-FUNC-RD, -REG-RD-LO, -VMA, -ALU-FUNC, ADDR-REG-ID=0, REG-RD-ID=6, REG-LD-ID=0, ALU=0
MVRLA R6     step  7: -REG-FUNC-RD, -REG-RD-LO, -VMA, -ALU-FUNC, UCODE-COUNT-RESET, ADDR-REG-ID=0, REG-RD-ID=6, REG-LD-ID=0, ALU=0
MVRLA R7     step  0: -MEM-RD, -VMA, ADDR-REG-ID=0, REG-RD-ID=0, REG-LD-ID=0, ALU=0
MVRLA R7     step  1: -MEM-RD, -VMA, LD-INS-REG, ADDR-REG-ID=0, REG-RD-ID=0, REG-LD-ID=0, ALU=0
MVRLA R7     step  2: -REG-FUNC-RD, -REG-UP, -VMA, ADDR-REG-ID=0, REG-RD-ID=0, REG-LD-ID=0, ALU=0
MVRLA R7     step  3: -VMA, ADDR-REG-ID=0, REG-RD-ID=0, REG-LD-ID=0, ALU=0
MVRLA R7     step  4: -REG-FUNC-RD, -REG-RD-LO, -VMA, -ALU-FUNC, ADDR-REG-ID=0, REG-RD-ID=7, REG-LD-ID=0, ALU=0
MVRLA R7     step  5: -REG-FUNC-RD, -REG-RD-LO, -VMA, -ALU-FUNC, -AC-LD, ADDR-REG-ID=0, REG-RD-ID=7, REG-LD-ID=0, ALU=0
MVRLA R7     step  6: -REG-FUNC-RD, -REG-RD-LO, -VMA, -ALU-FUNC, ADDR-REG-ID=0, REG-RD-ID=7, REG-LD-ID=0, ALU=0
MVRLA R7     step  7: -REG-FUNC-RD, -REG-RD-LO, -VMA, -ALU-FUNC, UCODE-COUNT-RESET, ADDR-REG-ID=0, REG-RD-ID=7, REG-LD-ID=0, ALU=0
MVRHA        step  0: -MEM-RD, -VMA, ADDR-REG-ID=0, REG-RD-ID=0, REG-LD-ID=0, ALU=0
MVRHA        step  1: -MEM-RD, -VMA, LD-INS-REG, ADDR-REG-ID=0, REG-RD-ID=0, REG-LD-ID=0, ALU=0
MVRHA        step  2: -REG-FUNC-RD, -REG-UP, -VMA, ADDR-REG-ID=0, REG-RD-ID=0, REG-LD-ID=0, ALU=0
MVRHA        step  3: -REG-FUNC-RD, -REG-RD-HI, -VMA, -ALU-FUNC, -HL-SWAP, ADDR-REG-ID=0, REG-RD-ID=0, REG-LD-ID=0, ALU=0
MVRHA        step  4: -REG-FUNC-RD, -REG-RD-HI, -VMA, -ALU-FUNC, -AC-LD, -HL-SWAP, ADDR-REG-ID=0, REG-RD-ID=0, REG-LD-ID=0, ALU=0
MVRHA        step  5: -REG-FUNC-RD, -REG-RD-HI, -VMA, -ALU-FUNC, -HL-SWAP, ADDR-REG-ID=0, REG-RD-ID=0, REG-LD-ID=0, ALU=0
MVRHA        step  6: -REG-FUNC-RD, -REG-RD-HI, -VMA, -ALU-FUNC, -HL-SWAP, UCODE-COUNT-RESET, ADDR-REG-ID=0, REG-RD-ID=0, REG-LD-ID=0, ALU=0
MVRHA R1     step  0: -MEM-RD, -VMA, ADDR-REG-ID=0, REG-RD-ID=0, REG-LD-ID=0, ALU=0
MVRHA R1     step  1: -MEM-RD, -VMA, LD-INS-REG, ADDR-REG-ID=0, REG-RD-ID=0, REG-LD-ID=0, ALU=0
MVRHA R1     step  2: -REG-FUNC-RD, -REG-UP, -VMA, ADDR-REG-ID=0, REG-RD-ID=0, REG-LD-ID=0, ALU=0
MVRHA R1     step  3: -VMA, ADDR-REG-ID=0, REG-RD-ID=0, REG-LD-ID=0, ALU=0
MVRHA R1     step  4: -REG-FUNC-RD, -REG-RD-HI, -VMA, -ALU-FUNC, -HL-SWAP, ADDR-REG-ID=0, REG-RD-ID=1, REG-LD-ID=0, ALU=0
MVRHA R1     step  5: -REG-FUNC-RD, -REG-RD-HI, -VMA, -ALU-FUNC, -AC-LD, -HL-SWAP, ADDR-REG-ID=0, REG-RD-ID=1, REG-LD-ID=0, ALU=0
MVRHA R1     step  6: -REG-FUNC-RD, -REG-RD-HI, -VMA, -ALU-FUNC, -HL-SWAP, ADDR-REG-ID=0, REG-RD-ID=1, REG-LD-ID=0, ALU=0
MVRHA R1     step  7: -REG-FUNC-RD, -REG-RD-HI, -VMA, -ALU-FUNC, -HL-SWAP, UCODE-COUNT-RESET, ADDR-REG-ID=0, REG-RD-ID=1, REG-LD-ID=0, ALU=0
MVRHA R2     step  0: -MEM-RD, -VMA, ADDR-REG-ID=0, REG-RD-ID=0, REG-LD-ID=0, ALU=0
MVRHA R2     step  1: -MEM-RD, -VMA, LD-INS-REG, ADDR-REG-ID=0, REG-RD-ID=0, REG-LD-ID=0, ALU=0
MVRHA R2     step  2: -REG-FUNC-RD, -REG-UP, -VMA, ADDR-REG-ID=0, REG-RD-ID=0, REG-LD-ID=0, ALU=0
MVRHA R2     step  3: -VMA, ADDR-REG-ID=0, REG-RD-ID=0, REG-LD-ID=0, ALU=0
MVRHA R2     step  4: -REG-FUNC-RD, -REG-RD-HI, -VMA, -ALU-FUNC, -HL-SWAP, ADDR-REG-ID=0, REG-RD-ID=2, REG-LD-ID=0, ALU=0
MVRHA R2     step  5: -REG-FUNC-RD, -REG-RD-HI, -VMA, -ALU-FUNC, -AC-LD, -HL-SWAP, ADDR-REG-ID=0, REG-RD-ID=2, REG-LD-ID=0, ALU=0
MVRHA R2     step  6: -REG-FUNC-RD, -REG-RD-HI, -VMA, -ALU-FUNC, -HL-SWAP, ADDR-REG-ID=0, REG-RD-ID=2, REG-LD-ID=0, ALU=0
MVRHA R2     step  7: -REG-FUNC-RD, -REG-RD-HI, -VMA, -ALU-FUNC, -HL-SWAP, UCODE-COUNT-RESET, ADDR-REG-ID=0, REG-RD-ID=2, REG-LD-ID=0, ALU=0
MVRHA R3     step  0: -MEM-RD, -VMA, ADDR-REG-ID=0, REG-RD-ID=0, REG-LD-ID=0, ALU=0
MVRHA R3     step  1: -MEM-RD, -VMA, LD-INS-REG, ADDR-REG-ID=0, REG-RD-ID=0, REG-LD-ID=0, ALU=0
MVRHA R3     step  2: -REG-FUNC-RD, -REG-UP, -VMA, ADDR-REG-ID=0, REG-RD-ID=0, REG-LD-ID=0, ALU=0
MVRHA R3     step  3: -VMA, ADDR-REG-ID=0, REG-RD-ID=0, REG-LD-ID=0, ALU=0
MVRHA R3     step  4: -REG-FUNC-RD, -REG-RD-HI, -VMA, -ALU-FUNC, -HL-SWAP, ADDR-REG-ID=0, REG-RD-ID=3, REG-LD-ID=0, ALU=0
MVRHA R3     step  5: -REG-FUNC-RD, -REG-RD-HI, -VMA, -ALU-FUNC, -AC-LD, -HL-SWAP, ADDR-REG-ID=0, REG-RD-ID=3, REG-LD-ID=0, ALU=0
MVRHA R3     step  6: -REG-FUNC-RD, -REG-RD-HI, -VMA, -ALU-FUNC, -HL-SWAP, ADDR-REG-ID=0, REG-RD-ID=3, REG-LD-ID=0, ALU=0
MVRHA R3     step  7: -REG-FUNC-RD, -REG-RD-HI, -VMA, -ALU-FUNC, -HL-SWAP, UCODE-COUNT-RESET, ADDR-REG-ID=0, REG-RD-ID=3, REG-LD-ID=0, ALU=0
MVRHA R4     step  0: -MEM-RD, -VMA, ADDR-REG-ID=0, REG-RD-ID=0, REG-LD-ID=0, ALU=0
MVRHA R4     step  1: -MEM-RD, -VMA, LD-INS-REG, ADDR-REG-ID=0, REG-RD-ID=0, REG-LD-ID=0, ALU=0
MVRHA R4     step  2: -REG-FUNC-RD, -REG-UP, -VMA, ADDR-REG-ID=0, REG-RD-ID=0, REG-LD-ID=0, ALU=0
MVRHA R4     step  3: -VMA, ADDR-REG-ID=0, REG-RD-ID=0, REG-LD-ID=0, ALU=0
MVRHA R4     step  4: -REG-FUNC-RD, -REG-RD-HI, -VMA, -ALU-FUNC, -HL-SWAP, ADDR-REG-ID=0, REG-RD-ID=4, REG-LD-ID=0, ALU=0
MVRHA R4     step  5: -REG-FUNC-RD, -REG-RD-HI, -VMA, -ALU-FUNC, -AC-LD, -HL-SWAP, ADDR-REG-ID=0, REG-RD-ID=4, REG-LD-ID=0, ALU=0
MVRHA R4     step  6: -REG-FUNC-RD, -REG-RD-HI, -VMA, -ALU-FUNC, -HL-SWAP, ADDR-REG-ID=0, REG-RD-ID=4, REG-LD-ID=0, ALU=0
MVRHA R4     step  7: -REG-FUNC-RD, -REG-RD-HI, -VMA, -ALU-FUNC, -HL-SWAP, UCODE-COUNT-RESET, ADDR-REG-ID=0, REG-RD-ID=4, REG-LD-ID=0, ALU=0
MVRHA R5     step  0: -MEM-RD, -VMA, ADDR-REG-ID=0, REG-RD-ID=0, REG-LD-ID=0, ALU=0
MVRHA R5     step  1: -MEM-RD, -VMA, LD-INS-REG, ADDR-REG-ID=0, REG-RD-ID=0, REG-LD-ID=0, ALU=0
MVRHA R5     step  2: -REG-FUNC-RD, -REG-UP, -VMA, ADDR-REG-ID=0, REG-RD-ID=0, REG-LD-ID=0, ALU=0
MVRHA R5     step  3: -VMA, ADDR-REG-ID=0, REG-RD-ID=0, REG-LD-ID=0, ALU=0
MVRHA R5     step  4: -REG-FUNC-RD, -REG-RD-HI, -VMA, -ALU-FUNC, -HL-SWAP, ADDR-REG-ID=0, REG-RD-ID=5, REG-LD-ID=0, ALU=0
MVRHA R5     step  5: -REG-FUNC-RD, -REG-RD-HI, -VMA, -ALU-FUNC, -AC-LD, -HL-SWAP, ADDR-REG-ID=0, REG-RD-ID=5, REG-LD-ID=0, ALU=0
MVRHA R5     step  6: -REG-FUNC-RD, -REG-RD-HI, -VMA, -ALU-FUNC, -HL-SWAP, ADDR-REG-ID=0, REG-RD-ID=5, REG-LD-ID=0, ALU=0
MVRHA R5     step  7: -REG-FUNC-RD, -REG-RD-HI, -VMA, -ALU-FUNC, -HL-SWAP, UCODE-COUNT-RESET, ADDR-REG-ID=0, REG-RD-ID=5, REG-LD-ID=0, ALU=0
MVRHA R6     step  0: -MEM-RD, -VMA, ADDR-REG-ID=0, REG-RD-ID=0, REG-LD-ID=0, ALU=0
MVRHA R6     step  1: -MEM-RD, -VMA, LD-INS-REG, ADDR-REG-ID=0, REG-RD-ID=0, REG-LD-ID=0, ALU=0
MVRHA R6     step  2: -REG-FUNC-RD, -REG-UP, -VMA, ADDR-REG-ID=0, REG-RD-ID=0, REG-LD-ID=0, ALU=0
MVRHA R6     step  3: -VMA, ADDR-REG-ID=0, REG-RD-ID=0, REG-LD-ID=0, ALU=0
MVRHA R6     step  4: -REG-FUNC-RD, -REG-RD-HI, -VMA, -ALU-FUNC, -HL-SWAP, ADDR-REG-ID=0, REG-RD-ID=6, REG-LD-ID=0, ALU=0
MVRHA R6     step  5: -REG-FUNC-RD, -REG-RD-HI, -VMA, -ALU-FUNC, -AC-LD, -HL-SWAP, ADDR-REG-ID=0, REG-RD-ID=6, REG-LD-ID=0, ALU=0
MVRHA R6     step  6: -REG-FUNC-RD, -REG-RD-HI, -VMA, -ALU-FUNC, -HL-SWAP, ADDR-REG-ID=0, REG-RD-ID=6, REG-LD-ID=0, ALU=0
MVRHA R6     step  7: -REG-FUNC-RD, -REG-RD-HI, -VMA, -ALU-FUNC, -HL-SWAP, UCODE-COUNT-RESET, ADDR-REG-ID=0, REG-RD-ID=6, REG-LD-ID=0, ALU=0
MVRHA R7     step  0: -MEM-RD, -VMA, ADDR-REG-ID=0, REG-RD-ID=0, REG-LD-ID=0, ALU=0
MVRHA R7     step  1: -MEM-RD, -VMA, LD-INS-REG, ADDR-REG-ID=0, REG-RD-ID=0, REG-LD-ID=0, ALU=0
MVRHA R7     step  2: -REG-FUNC-RD, -REG-UP, -VMA, ADDR-REG-ID=0, REG-RD-ID=0, REG-LD-ID=0, ALU=0
MVRHA R7     step  3: -VMA, ADDR-REG-ID=0, REG-RD-ID=0, REG-LD-ID=0, ALU=0
MVRHA R7     step  4: -REG-FUNC-RD, -REG-RD-HI, -VMA, -ALU-FUNC, -HL-SWAP, ADDR-REG-ID=0, REG-RD-ID=7, REG-LD-ID=0, ALU=0
MVRHA R7     step  5: -REG-FUNC-RD, -REG-RD-HI, -VMA, -ALU-FUNC, -AC-LD, -HL-SWAP, ADDR-REG-ID=0, REG-RD-ID=7, REG-LD-ID=0, ALU=0
MVRHA R7     step  6: -REG-FUNC-RD, -REG-RD-HI, -VMA, -ALU-FUNC, -HL-SWAP, ADDR-REG-ID=0, REG-RD-ID=7, REG-LD-ID=0, ALU=0
MVRHA R7     step  7: -REG-FUNC-RD, -REG-RD-HI, -VMA, -ALU-FUNC, -HL-SWAP, UCODE-COUNT-RESET, ADDR-REG-ID=0, REG-RD-ID=7, REG-LD-ID=0, ALU=0
MVARL        step  0: -MEM-RD, -VMA, ADDR-REG-ID=0, REG-RD-ID=0, REG-LD-ID=0, ALU=0
MVARL        step  1: -MEM-RD, -VMA, LD-INS-REG, ADDR-REG-ID=0, REG-RD-ID=0, REG-LD-ID=0, ALU=0
MVARL        step  2: -REG-FUNC-RD, -REG-UP, -VMA, ADDR-REG-ID=0, REG-RD-ID=0, REG-LD-ID=0, ALU=0
MVARL        step  3: -VMA, -ALU-FUNC, -AC-RD, ADDR-REG-ID=0, REG-RD-ID=0, REG-LD-ID=0, ALU=0
MVARL        step  4: -REG-FUNC-LD, -VMA, -ALU-FUNC, -AC-RD, ADDR-REG-ID=0, REG-RD-ID=0, REG-LD-ID=0, ALU=0
MVARL        step  5: -REG-FUNC-LD, REG-LD-LO, -VMA, -ALU-FUNC, -AC-RD, ADDR-REG-ID=0, REG-RD-ID=0, REG-LD-ID=0, ALU=0
MVARL        step  6: -REG-FUNC-LD, -VMA, -ALU-FUNC, -AC-RD, ADDR-REG-ID=0, REG-RD-ID=0, REG-LD-ID=0, ALU=0
MVARL        step  7: -VMA, -ALU-FUNC, -AC-RD, ADDR-REG-ID=0, REG-RD-ID=0, REG-LD-ID=0, ALU=0
MVARL        step  8: -VMA, -ALU-FUNC, -AC-RD, UCODE-COUNT-RESET, ADDR-REG-ID=0, REG-RD-ID=0, REG-LD-ID=0, ALU=0
MVARL R1     step  0: -MEM-RD, -VMA, ADDR-REG-ID=0, REG-RD-ID=0, REG-LD-ID=0, ALU=0
MVARL R1     step  1: -MEM-RD, -VMA, LD-INS-REG, ADDR-REG-ID=0, REG-RD-ID=0, REG-LD-ID=0, ALU=0
MVARL R1     step  2: -REG-FUNC-RD, -REG-UP, -VMA, ADDR-REG-ID=0, REG-RD-ID=0, REG-LD-ID=0, ALU=0
MVARL R1     step  3: -VMA, -ALU-FUNC, -AC-RD, ADDR-REG-ID=0, REG-RD-ID=0, REG-LD-ID=0, ALU=0
MVARL R1     step  4: -REG-FUNC-LD, -VMA, -ALU-FUNC, -AC-RD, ADDR-REG-ID=0, REG-RD-ID=0, REG-LD-ID=1, ALU=0
MVARL R1     step  5: -REG-FUNC-LD, REG-LD-LO, -VMA, -ALU-FUNC, -AC-RD, ADDR-REG-ID=0, REG-RD-ID=0, REG-LD-ID=1, ALU=0
MVARL R1     step  6: -REG-FUNC-LD, -VMA, -ALU-FUNC, -AC-RD, ADDR-REG-ID=0, REG-RD-ID=0, REG-LD-ID=1, ALU=0
MVARL R1     step  7: -VMA, -ALU-FUNC, -AC-RD, ADDR-REG-ID=0, REG-RD-ID=0, REG-LD-ID=1, ALU=0
MVARL R1     step  8: -VMA, -ALU-FUNC, -AC-RD, UCODE-COUNT-RESET, ADDR-REG-ID=0, REG-RD-ID=0, REG-LD-ID=1, ALU=0
MVARL R2     step  0: -MEM-RD, -VMA, ADDR-REG-ID=0, REG-RD-ID=0, REG-LD-ID=0, ALU=0
MVARL R2     step  1: -MEM-RD, -VMA, LD-INS-REG, ADDR-REG-ID=0, REG-RD-ID=0, REG-LD-ID=0, ALU=0
MVARL R2     step  2: -REG-FUNC-RD, -REG-UP, -VMA, ADDR-REG-ID=0, REG-RD-ID=0, REG-LD-ID=0, ALU=0
MVARL R2     step  3: -VMA, -ALU-FUNC, -AC-RD, ADDR-REG-ID=0, REG-RD-ID=0, REG-LD-ID=0, ALU=0
MVARL R2     step  4: -REG-FUNC-LD, -VMA, -ALU-FUNC, -AC-RD, ADDR-REG-ID=0, REG-RD-ID=0, REG-LD-ID=2, ALU=0
MVARL R2     step  5: -REG-FUNC-LD, REG-LD-LO, -VMA, -ALU-FUNC, -AC-RD, ADDR-REG-ID=0, REG-RD-ID=0, REG-LD-ID=2, ALU=0
MVARL R2     step  6: -REG-FUNC-LD, -VMA, -ALU-FUNC, -AC-RD, ADDR-REG-ID=0, REG-RD-ID=0, REG-LD-ID=2, ALU=0
MVARL R2     step  7: -VMA, -ALU-FUNC, -AC-RD, ADDR-REG-ID=0, REG-RD-ID=0, REG-LD-ID=2, ALU=0
MVARL R2     step  8: -VMA, -ALU-FUNC, -AC-RD, UCODE-COUNT-RESET, ADDR-REG-ID=0, REG-RD-ID=0, REG-LD-ID=2, ALU=0
MVARL R3     step  0: -MEM-RD, -VMA, ADDR-REG-ID=0, REG-RD-ID=0, REG-LD-ID=0, ALU=0
MVARL R3     step  1: -MEM-RD, -VMA, LD-INS-REG, ADDR-REG-ID=0, REG-RD-ID=0, REG-LD-ID=0, ALU=0
MVARL R3     step  2: -REG-FUNC-RD, -REG-UP, -VMA, ADDR-REG-ID=0, REG-RD-ID=0, REG-LD-ID=0, ALU=0
MVARL R3     step  3: -VMA, -ALU-FUNC, -AC-RD, ADDR-REG-ID=0, REG-RD-ID=0, REG-LD-ID=0, ALU=0
MVARL R3     step  4: -REG-FUNC-LD, -VMA, -ALU-FUNC, -AC-RD, ADDR-REG-ID=0, REG-RD-ID=0, REG-LD-ID=3, ALU=0
MVARL R3     step  5: -REG-FUNC-LD, REG-LD-LO, -VMA, -ALU-FUNC, -AC-RD, ADDR-REG-ID=0, REG-RD-ID=0, REG-LD-ID=3, ALU=0
MVARL R3     step  6: -REG-FUNC-LD, -VMA, -ALU-FUNC, -AC-RD, ADDR-REG-ID=0, REG-RD-ID=0, REG-LD-ID=3, ALU=0
MVARL R3     step  7: -VMA, -ALU-FUNC, -AC-RD, ADDR-REG-ID=0, REG-RD-ID=0, REG-LD-ID=3, ALU=0
MVARL R3     step  8: -VMA, -ALU-FUNC, -AC-RD, UCODE-COUNT-RESET, ADDR-REG-ID=0, REG-RD-ID=0, REG-LD-ID=3, ALU=0
MVARL R4     step  0: -MEM-RD, -VMA, ADDR-REG-ID=0, REG-RD-ID=0, REG-LD-ID=0, ALU=0
MVARL R4     step  1: -MEM-RD, -VMA, LD-INS-REG, ADDR-REG-ID=0, REG-RD-ID=0, REG-LD-ID=0, ALU=0
MVARL R4     step  2: -REG-FUNC-RD, -REG-UP, -VMA, ADDR-REG-ID=0, REG-RD-ID=0, REG-LD-ID=0, ALU=0
MVARL R4     step  3: -VMA, -ALU-FUNC, -AC-RD, ADDR-REG-ID=0, REG-RD-ID=0, REG-LD-ID=0, ALU=0
MVARL R4     step  4: -REG-FUNC-LD, -VMA, -ALU-FUNC, -AC-RD, ADDR-REG-ID=0, REG-RD-ID=0, REG-LD-ID=4, ALU=0
MVARL R4     step  5: -REG-FUNC-LD, REG-LD-LO, -VMA, -ALU-FUNC, -AC-RD, ADDR-REG-ID=0, REG-RD-ID=0, REG-LD-ID=4, ALU=0
MVARL R4     step  6: -REG-FUNC-LD, -VMA, -ALU-FUNC, -AC-RD, ADDR-REG-ID=0, REG-RD-ID=0, REG-LD-ID=4, ALU=0
MVARL R4     step  7: -VMA, -ALU-FUNC, -AC-RD, ADDR-REG-ID=0, REG-RD-ID=0, REG-LD-ID=4, ALU=0
MVARL R4     step  8: -VMA, -ALU-FUNC, -AC-RD, UCODE-COUNT-RESET, ADDR-REG-ID=0, REG-RD-ID=0, REG-LD-ID=4, ALU=0
MVARL R5     step  0: -MEM-RD, -VMA, ADDR-REG-ID=0, REG-RD-ID=0, REG-LD-ID=0, ALU=0
MVARL R5     step  1: -MEM-RD, -VMA, LD-INS-REG, ADDR-REG-ID=0, REG-RD-ID=0, REG-LD-ID=0, ALU=0
MVARL R5     step  2: -REG-FUNC-RD, -REG-UP, -VMA, ADDR-REG-ID=0, REG-RD-ID=0, REG-LD-ID=0, ALU=0
MVARL R5     step  3: -VMA, -ALU-FUNC, -AC-RD, ADDR-REG-ID=0, REG-RD-ID=0, REG-LD-ID=0, ALU=0
MVARL R5     step  4: -REG-FUNC-LD, -VMA, -ALU-FUNC, -AC-RD, ADDR-REG-ID=0, REG-RD-ID=0, REG-LD-ID=5, ALU=0
MVARL R5     step  5: -REG-FUNC-LD, REG-LD-LO, -VMA, -ALU-FUNC, -AC-RD, ADDR-REG-ID=0, REG-RD-ID=0, REG-LD-ID=5, ALU=0
MVARL R5     step  6: -REG-FUNC-LD, -VMA, -ALU-FUNC, -AC-RD, ADDR-REG-ID=0, REG-RD-ID=0, REG-LD-ID=5, ALU=0
MVARL R5     step  7: -VMA, -ALU-FUNC, -AC-RD, ADDR-REG-ID=0, REG-RD-ID=0, REG-LD-ID=5, ALU=0
MVARL R5     step  8: -VMA, -ALU-FUNC, -AC-RD, UCODE-COUNT-RESET, ADDR-REG-ID=0, REG-RD-ID=0, REG-LD-ID=5, ALU=0
MVARL R6     step  0: -MEM-RD, -VMA, ADDR-REG-ID=0, REG-RD-ID=0, REG-LD-ID=0, ALU=0
MVARL R6     step  1: -MEM-RD, -VMA, LD-INS-REG, ADDR-REG-ID=0, REG-RD-ID=0, REG-LD-ID=0, ALU=0
MVARL R6     step  2: -REG-FUNC-RD, -REG-UP, -VMA, ADDR-REG-ID=0, REG-RD-ID=0, REG-LD-ID=0, ALU=0
MVARL R6     step  3: -VMA, -ALU-FUNC, -AC-RD, ADDR-REG-ID=0, REG-RD-ID=0, REG-LD-ID=0, ALU=0
MVARL R6     step  4: -REG-FUNC-LD, -VMA, -ALU-FUNC, -AC-RD, ADDR-REG-ID=0, REG-RD-ID=0, REG-LD-ID=6, ALU=0
MVARL R6     step  5: -REG-FUNC-LD, REG-LD-LO, -VMA, -ALU-FUNC, -AC-RD, ADDR-REG-ID=0, REG-RD-ID=0, REG-LD-ID=6, ALU=0
MVARL R6     step  6: -REG-FUNC-LD, -VMA, -ALU-FUNC, -AC-RD, ADDR-REG-ID=0, REG-RD-ID=0, REG-LD-ID=6, ALU=0
MVARL R6     step  7: -VMA, -ALU-FUNC, -AC-RD, ADDR-REG-ID=0, REG-RD-ID=0, REG-LD-ID=6, ALU=0
MVARL R6     step  8: -VMA, -ALU-FUNC, -AC-RD, UCODE-COUNT-RESET, ADDR-REG-ID=0, REG-RD-ID=0, REG-LD-ID=6, ALU=0
MVARL R7     step  0: -MEM-RD, -VMA, ADDR-REG-ID=0, REG-RD-ID=0, REG-LD-ID=0, ALU=0
MVARL R7     step  1: -MEM-RD, -VMA, LD-INS-REG, ADDR-REG-ID=0, REG-RD-ID=0, REG-LD-ID=0, ALU=0
MVARL R7     step  2: -REG-FUNC-RD, -REG-UP, -VMA, ADDR-REG-ID=0, REG-RD-ID=0, REG-LD-ID=0, ALU=0
MVARL R7     step  3: -VMA, -ALU-FUNC, -AC-RD, ADDR-REG-ID=0, REG-RD-ID=0, REG-LD-ID=0, ALU=0
MVARL R7     step  4: -REG-FUNC-LD, -VMA, -ALU-FUNC, -AC-RD, ADDR-REG-ID=0, REG-RD-ID=0, REG-LD-ID=7, ALU=0
MVARL R7     step  5: -REG-FUNC-LD, REG-LD-LO, -VMA, -ALU-FUNC, -AC-RD, ADDR-REG-ID=0, REG-RD-ID=0, REG-LD-ID=7, ALU=0
MVARL R7     step  6: -REG-FUNC-LD, -VMA, -ALU-FUNC, -AC-RD, ADDR-REG-ID=0, REG-RD-ID=0, REG-LD-ID=7, ALU=0
MVARL R7     step  7: -VMA, -ALU-FUNC, -AC-RD, ADDR-REG-ID=0, REG-RD-ID=0, REG-LD-ID=7, ALU=0
MVARL R7     step  8: -VMA, -ALU-FUNC, -AC-RD, UCODE-COUNT-RESET, ADDR-REG-ID=0, REG-RD-ID=0, REG-LD-ID=7, ALU=0
MVARH        step  0: -MEM-RD, -VMA, ADDR-REG-ID=0, REG-RD-ID=0, REG-LD-ID=0, ALU=0
MVARH        step  1: -MEM-RD, -VMA, LD-INS-REG, ADDR-REG-ID=0, REG-RD-ID=0, REG-LD-ID=0, ALU=0
MVARH        step  2: -REG-FUNC-RD, -REG-UP, -VMA, ADDR-REG-ID=0, REG-RD-ID=0, REG-LD-ID=0, ALU=0
MVARH        step  3: -VMA, -ALU-FUNC, -AC-RD, ADDR-REG-ID=0, REG-RD-ID=0, REG-LD-ID=0, ALU=0
MVARH        step  4: -REG-FUNC-LD, -VMA, -ALU-FUNC, -AC-RD, -HL-SWAP, ADDR-REG-ID=0, REG-RD-ID=0, REG-LD-ID=0, ALU=0
MVARH        step  5: -REG-FUNC-LD, REG-LD-HI, -VMA, -ALU-FUNC, -AC-RD, -HL-SWAP, ADDR-REG-ID=0, REG-RD-ID=0, REG-LD-ID=0, ALU=0
MVARH        step  6: -REG-FUNC-LD, -VMA, -ALU-FUNC, -AC-RD, -HL-SWAP, ADDR-REG-ID=0, REG-RD-ID=0, REG-LD-ID=0, ALU=0
MVARH        step  7: -VMA, -ALU-FUNC, -AC-RD, -HL-SWAP, ADDR-REG-ID=0, REG-RD-ID=0, REG-LD-ID=0, ALU=0
MVARH        step  8: -VMA, -ALU-FUNC, -AC-RD, -HL-SWAP, UCODE-COUNT-RESET, ADDR-REG-ID=0, REG-RD-ID=0, REG-LD-ID=0, ALU=0
MVARH R1     step  0: -MEM-RD, -VMA, ADDR-REG-ID=0, REG-RD-ID=0, REG-LD-ID=0, ALU=0
MVARH R1     step  1: -MEM-RD, -VMA, LD-INS-REG, ADDR-REG-ID=0, REG-RD-ID=0, REG-LD-ID=0, ALU=0
MVARH R1     step  2: -REG-FUNC-RD, -REG-UP, -VMA, ADDR-REG-ID=0, REG-RD-ID=0, REG-LD-ID=0, ALU=0
MVARH R1     step  3: -VMA, -ALU-FUNC, -AC-RD, ADDR-REG-ID=0, REG-RD-ID=0, REG-LD-ID=0, ALU=0
MVARH R1     step  4: -REG-FUNC-LD, -VMA, -ALU-FUNC, -AC-RD, -HL-SWAP, ADDR-REG-ID=0, REG-RD-ID=0, REG-LD-ID=1, ALU=0
MVARH R1     step  5: -REG-FUNC-LD, REG-LD-HI, -VMA, -ALU-FUNC, -AC-RD, -HL-SWAP, ADDR-REG-ID=0, REG-RD-ID=0, REG-LD-ID=1, ALU=0
MVARH R1     step  6: -REG-FUNC-LD, -VMA, -ALU-FUNC, -AC-RD, -HL-SWAP, ADDR-REG-ID=0, REG-RD-ID=0, REG-LD-ID=1, ALU=0
MVARH R1     step  7: -VMA, -ALU-FUNC, -AC-RD, -HL-SWAP, ADDR-REG-ID=0, REG-RD-ID=0, REG-LD-ID=1, ALU=0
MVARH R1     step  8: -VMA, -ALU-FUNC, -AC-RD, -HL-SWAP, UCODE-COUNT-RESET, ADDR-REG-ID=0, REG-RD-ID=0, REG-LD-ID=1, ALU=0
MVARH R2     step  0: -MEM-RD, -VMA, ADDR-REG-ID=0, REG-RD-ID=0, REG-LD-ID=0, ALU=0
MVARH R2     step  1: -MEM-RD, -VMA, LD-INS-REG, ADDR-REG-ID=0, REG-RD-ID=0, REG-LD-ID=0, ALU=0
MVARH R2     step  2: -REG-FUNC-RD, -REG-UP, -VMA, ADDR-REG-ID=0, REG-RD-ID=0, REG-LD-ID=0, ALU=0
MVARH R2     step  3: -VMA, -ALU-FUNC, -AC-RD, ADDR-REG-ID=0, REG-RD-ID=0, REG-LD-ID=0, ALU=0
MVARH R2     step  4: -REG-FUNC-LD, -VMA, -ALU-FUNC, -AC-RD, -HL-SWAP, ADDR-REG-ID=0, REG-RD-ID=0, REG-LD-ID=2, ALU=0
MVARH R2     step  5: -REG-FUNC-LD, REG-LD-HI, -VMA, -ALU-FUNC, -AC-RD, -HL-SWAP, ADDR-REG-ID=0, REG-RD-ID=0, REG-LD-ID=2, ALU=0
MVARH R2     step  6: -REG-FUNC-LD, -VMA, -ALU-FUNC, -AC-RD, -HL-SWAP, ADDR-REG-ID=0, REG-RD-ID=0, REG-LD-ID=2, ALU=0
MVARH R2     step  7: -VMA, -ALU-FUNC, -AC-RD, -HL-SWAP, ADDR-REG-ID=0, REG-RD-ID=0, REG-LD-ID=2, ALU=0
MVARH R2     step  8: -VMA, -ALU-FUNC, -AC-RD, -HL-SWAP, UCODE-COUNT-RESET, ADDR-REG-ID=0, REG-RD-ID=0, REG-LD-ID=2, ALU=0
MVARH R3     step  0: -MEM-RD, -VMA, ADDR-REG-ID=0, REG-RD-ID=0, REG-LD-ID=0, ALU=0
MVARH R3     step  1: -MEM-RD, -VMA, LD-INS-REG, ADDR-REG-ID=0, REG-RD-ID=0, REG-LD-ID=0, ALU=0
MVARH R3     step  2: -REG-FUNC-RD, -REG-UP, -VMA, ADDR-REG-ID=0, REG-RD-ID=0, REG-LD-ID=0, ALU=0
MVARH R3     step  3: -VMA, -ALU-FUNC, -AC-RD, ADDR-REG-ID=0, REG-RD-ID=0, REG-LD-ID=0, ALU=0
MVARH R3     step  4: -REG-FUNC-LD, -VMA, -ALU-FUNC, -AC-RD, -HL-SWAP, ADDR-REG-ID=0, REG-RD-ID=0, REG-LD-ID=3, ALU=0
MVARH R3     step  5: -REG-FUNC-LD, REG-LD-HI, -VMA, -ALU-FUNC, -AC-RD, -HL-SWAP, ADDR-REG-ID=0, REG-RD-ID=0, REG-LD-ID=3, ALU=0
MVARH R3     step  6: -REG-FUNC-LD, -VMA, -ALU-FUNC, -AC-RD, -HL-SWAP, ADDR-REG-ID=0, REG-RD-ID=0, REG-LD-ID=3, ALU=0
MVARH R3     step  7: -VMA, -ALU-FUNC, -AC-RD, -HL-SWAP, ADDR-REG-ID=0, REG-RD-ID=0, REG-LD-ID=3, ALU=0
MVARH R3     step  8: -VMA, -ALU-FUNC, -AC-RD, -HL-SWAP, UCODE-COUNT-RESET, ADDR-REG-ID=0, REG-RD-ID=0, REG-LD-ID=3, ALU=0
MVARH R4     step  0: -MEM-RD, -VMA, ADDR-REG-ID=0, REG-RD-ID=0, REG-LD-ID=0, ALU=0
MVARH R4     step  1: -MEM-RD, -VMA, LD-INS-REG, ADDR-REG-ID=0, REG-RD-ID=0, REG-LD-ID=0, ALU=0
MVARH R4     step  2: -REG-FUNC-RD, -REG-UP, -VMA, ADDR-REG-ID=0, REG-RD-ID=0, REG-LD-ID=0, ALU=0
MVARH R4     step  3: -VMA, -ALU-FUNC, -AC-RD, ADDR-REG-ID=0, REG-RD-ID=0, REG-LD-ID=0, ALU=0
MVARH R4     step  4: -REG-FUNC-LD, -VMA, -ALU-FUNC, -AC-RD, -HL-SWAP, ADDR-REG-ID=0, REG-RD-ID=0, REG-LD-ID=4, ALU=0
MVARH R4     step  5: -REG-FUNC-LD, REG-LD-HI, -VMA, -ALU-FUNC, -AC-RD, -HL-SWAP, ADDR-REG-ID=0, REG-RD-ID=0, REG-LD-ID=4, ALU=0
MVARH R4     step  6: -REG-FUNC-LD, -VMA, -ALU-FUNC, -AC-RD, -HL-SWAP, ADDR-REG-ID=0, REG-RD-ID=0, REG-LD-ID=4, ALU=0
MVARH R4     step  7: -VMA, -ALU-FUNC, -AC-RD, -HL-SWAP, ADDR-REG-ID=0, REG-RD-ID=0, REG-LD-ID=4, ALU=0
MVARH R4     step  8: -VMA, -ALU-FUNC, -AC-RD, -HL-SWAP, UCODE-COUNT-RESET, ADDR-REG-ID=0, REG-RD-ID=0, REG-LD-ID=4, ALU=0
MVARH R5     step  0: -MEM-RD, -VMA, ADDR-REG-ID=0, REG-RD-ID=0, REG-LD-ID=0, ALU=0
MVARH R5     step  1: -MEM-RD, -VMA, LD-INS-REG, ADDR-REG-ID=0, REG-RD-ID=0, REG-LD-ID=0, ALU=0
MVARH R5     step  2: -REG-FUNC-RD, -REG-UP, -VMA, ADDR-REG-ID=0, REG-RD-ID=0, REG-LD-ID=0, ALU=0
MVARH R5     step  3: -VMA, -ALU-FUNC, -AC-RD, ADDR-REG-ID=0, REG-RD-ID=0, REG-LD-ID=0, ALU=0
MVARH R5     step  4: -REG-FUNC-LD, -VMA, -ALU-FUNC, -AC-RD, -HL-SWAP, ADDR-REG-ID=0, REG-RD-ID=0, REG-LD-ID=5, ALU=0
MVARH R5     step  5: -REG-FUNC-LD, REG-LD-HI, -VMA, -ALU-FUNC, -AC-RD, -HL-SWAP, ADDR-REG-ID=0, REG-RD-ID=0, REG-LD-ID=5, ALU=0
MVARH R5     step  6: -REG-FUNC-LD, -VMA, -ALU-FUNC, -AC-RD, -HL-SWAP, ADDR-REG-ID=0, REG-RD-ID=0, REG-LD-ID=5, ALU=0
MVARH R5     step  7: -VMA, -ALU-FUNC, -AC-RD, -HL-SWAP, ADDR-REG-ID=0, REG-RD-ID=0, REG-LD-ID=5, ALU=0
MVARH R5     step  8: -VMA, -ALU-FUNC, -AC-RD, -HL-SWAP, UCODE-COUNT-RESET, ADDR-REG-ID=0, REG-RD-ID=0, REG-LD-ID=5, ALU=0
MVARH R6     step  0: -MEM-RD, -VMA, ADDR-REG-ID=0, REG-RD-ID=0, REG-LD-ID=0, ALU=0
MVARH R6     step  1: -MEM-RD, -VMA, LD-INS-REG, ADDR-REG-ID=0, REG-RD-ID=0, REG-LD-ID=0, ALU=0
MVARH R6     step  2: -REG-FUNC-RD, -REG-UP, -VMA, ADDR-REG-ID=0, REG-RD-ID=0, REG-LD-ID=0, ALU=0
MVARH R6     step  3: -VMA, -ALU-FUNC, -AC-RD, ADDR-REG-ID=0, REG-RD-ID=0, REG-LD-ID=0, ALU=0
MVARH R6     step  4: -REG-FUNC-LD, -VMA, -ALU-FUNC, -AC-RD, -HL-SWAP, ADDR-REG-ID=0, REG-RD-ID=0, REG-LD-ID=6, ALU=0
MVARH R6     step  5: -REG-FUNC-LD, REG-LD-HI, -VMA, -ALU-FUNC, -AC-RD, -HL-SWAP, ADDR-REG-ID=0, REG-RD-ID=0, REG-LD-ID=6, ALU=0
MVARH R6     step  6: -REG-FUNC-LD, -VMA, -ALU-FUNC, -AC-RD, -HL-SWAP, ADDR-REG-ID=0, REG-RD-ID=0, REG-LD-ID=6, ALU=0
MVARH R6     step  7: -VMA, -ALU-FUNC, -AC-RD, -HL-SWAP, ADDR-REG-ID=0, REG-RD-ID=0, REG-LD-ID=6, ALU=0
MVARH R6     step  8: -VMA, -ALU-FUNC, -AC-RD, -HL-SWAP, UCODE-COUNT-RESET, ADDR-REG-ID=0, REG-RD-ID=0, REG-LD-ID=6, ALU=0
MVARH R7     step  0: -MEM-RD, -VMA, ADDR-REG-ID=0, REG-RD-ID=0, REG-LD-ID=0, ALU=0
MVARH R7     step  1: -MEM-RD, -VMA, LD-INS-REG, ADDR-REG-ID=0, REG-RD-ID=0, REG-LD-ID=0, ALU=0
MVARH R7     step  2: -REG-FUNC-RD, -REG-UP, -VMA, ADDR-REG-ID=0, REG-RD-ID=0, REG-LD-ID=0, ALU=0
MVARH R7     step  3: -VMA, -ALU-FUNC, -AC-RD, ADDR-REG-ID=0, REG-RD-ID=0, REG-LD-ID=0, ALU=0
MVARH R7     step  4: -REG-FUNC-LD, -VMA, -ALU-FUNC, -AC-RD, -HL-SWAP, ADDR-REG-ID=0, REG-RD-ID=0, REG-LD-ID=7, ALU=0
MVARH R7     step  5: -REG-FUNC-LD, REG-LD-HI, -VMA, -ALU-FUNC, -AC-RD, -HL-SWAP, ADDR-REG-ID=0, REG-RD-ID=0, REG-LD-ID=7, ALU=0
MVARH R7     step  6: -REG-FUNC-LD, -VMA, -ALU-FUNC, -AC-RD, -HL-SWAP, ADDR-REG-ID=0, REG-RD-ID=0, REG-LD-ID=7, ALU=0
MVARH R7     step  7: -VMA, -ALU-FUNC, -AC-RD, -HL-SWAP, ADDR-REG-ID=0, REG-RD-ID=0, REG-LD-ID=7, ALU=0
MVARH R7     step  8: -VMA, -ALU-FUNC, -AC-RD, -HL-SWAP, UCODE-COUNT-RESET, ADDR-REG-ID=0, REG-RD-ID=0, REG-LD-ID=7, ALU=0
LDAVR        step  0: -MEM-RD, -VMA, ADDR-REG-ID=0, REG-RD-ID=0, REG-LD-ID=0, ALU=0
LDAVR        step  1: -MEM-RD, -VMA, LD-INS-REG, ADDR-REG-ID=0, REG-RD-ID=0, REG-LD-ID=0, ALU=0
LDAVR        step  2: -REG-FUNC-RD, -REG-UP, -VMA, ADDR-REG-ID=0, REG-RD-ID=0, REG-LD-ID=0, ALU=0
LDAVR        step  3: -MEM-RD, -VMA, ADDR-REG-ID=0, REG-RD-ID=0, REG-LD-ID=0, ALU=0
LDAVR        step  4: -MEM-RD, -VMA, -ALU-FUNC, ADDR-REG-ID=0, REG-RD-ID=0, REG-LD-ID=0, ALU=0
LDAVR        step  5: -MEM-RD, -VMA, -ALU-FUNC, -AC-LD, ADDR-REG-ID=0, REG-RD-ID=0, REG-LD-ID=0, ALU=0
LDAVR        step  6: -MEM-RD, -VMA, -ALU-FUNC, ADDR-REG-ID=0, REG-RD-ID=0, REG-LD-ID=0, ALU=0
LDAVR        step  7: -MEM-RD, -VMA, -ALU-FUNC, UCODE-COUNT-RESET, ADDR-REG-ID=0, REG-RD-ID=0, REG-LD-ID=0, ALU=0
LDAVR R1     step  0: -MEM-RD, -VMA, ADDR-REG-ID=0, REG-RD-ID=0, REG-LD-ID=0, ALU=0
LDAVR R1     step  1: -MEM-RD, -VMA, LD-INS-REG, ADDR-REG-ID=0, REG-RD-ID=0, REG-LD-ID=0, ALU=0
LDAVR R1     step  2: -REG-FUNC-RD, -REG-UP, -VMA, ADDR-REG-ID=0, REG-RD-ID=0, REG-LD-ID=0, ALU=0
LDAVR R1     step  3: -MEM-RD, -VMA, ADDR-REG-ID=1, REG-RD-ID=0, REG-LD-ID=0, ALU=0
LDAVR R1     step  4: -MEM-RD, -VMA, -ALU-FUNC, ADDR-REG-ID=1, REG-RD-ID=0, REG-LD-ID=0, ALU=0
LDAVR R1     step  5: -MEM-RD, -VMA, -ALU-FUNC, -AC-LD, ADDR-REG-ID=1, REG-RD-ID=0, REG-LD-ID=0, ALU=0
LDAVR R1     step  6: -MEM-RD, -VMA, -ALU-FUNC, ADDR-REG-ID=1, REG-RD-ID=0, REG-LD-ID=0, ALU=0
LDAVR R1     step  7: -MEM-RD, -VMA, -ALU-FUNC, UCODE-COUNT-RESET, ADDR-REG-ID=1, REG-RD-ID=0, REG-LD-ID=0, ALU=0
LDAVR R2     step  0: -MEM-RD, -VMA, ADDR-REG-ID=0, REG-RD-ID=0, REG-LD-ID=0, ALU=0
LDAVR R2     step  1: -MEM-RD, -VMA, LD-INS-REG, ADDR-REG-ID=0, REG-RD-ID=0, REG-LD-ID=0, ALU=0
LDAVR R2     step  2: -REG-FUNC-RD, -REG-UP, -VMA, ADDR-REG-ID=0, REG-RD-ID=0, REG-LD-ID=0, ALU=0
LDAVR R2     step  3: -MEM-RD, -VMA, ADDR-REG-ID=2, REG-RD-ID=0, REG-LD-ID=0, ALU=0
LDAVR R2     step  4: -MEM-RD, -VMA, -ALU-FUNC, ADDR-REG-ID=2, REG-RD-ID=0, REG-LD-ID=0, ALU=0
LDAVR R2     step  5: -MEM-RD, -VMA, -ALU-FUNC, -AC-LD, ADDR-REG-ID=2, REG-RD-ID=0, REG-LD-ID=0, ALU=0
LDAVR R2     step  6: -MEM-RD, -VMA, -ALU-FUNC, ADDR-REG-ID=2, REG-RD-ID=0, REG-LD-ID=0, ALU=0
LDAVR R2     step  7: -MEM-RD, -VMA, -ALU-FUNC, UCODE-COUNT-RESET, ADDR-REG-ID=2, REG-RD-ID=0, REG-LD-ID=0, ALU=0
LDAVR R3     step  0: -MEM-RD, -VMA, ADDR-REG-ID=0, REG-RD-ID=0, REG-LD-ID=0, ALU=0
LDAVR R3     step  1: -MEM-RD, -VMA, LD-INS-REG, ADDR-REG-ID=0, REG-RD-ID=0, REG-LD-ID=0, ALU=0
LDAVR R3     step  2: -REG-FUNC-RD, -REG-UP, -VMA, ADDR-REG-ID=0, REG-RD-ID=0, REG-LD-ID=0, ALU=0
LDAVR R3     step  3: -MEM-RD, -VMA, ADDR-REG-ID=3, REG-RD-ID=0, REG-LD-ID=0, ALU=0
LDAVR R3     step  4: -MEM-RD, -VMA, -ALU-FUNC, ADDR-REG-ID=3, REG-RD-ID=0, REG-LD-ID=0, ALU=0
LDAVR R3     step  5: -MEM-RD, -VMA, -ALU-FUNC, -AC-LD, ADDR-REG-ID=3, REG-RD-ID=0, REG-LD-ID=0, ALU=0
LDAVR R3     step  6: -MEM-RD, -VMA, -ALU-FUNC, ADDR-REG-ID=3, REG-RD-ID=0, REG-LD-ID=0, ALU=0
LDAVR R3     step  7: -MEM-RD, -VMA, -ALU-FUNC, UCODE-COUNT-RESET, ADDR-REG-ID=3, REG-RD-ID=0, REG-LD-ID=0, ALU=0
LDAVR R4     step  0: -MEM-RD, -VMA, ADDR-REG-ID=0, REG-RD-ID=0, REG-LD-ID=0, ALU=0
LDAVR R4     step  1: -MEM-RD, -VMA, LD-INS-REG, ADDR-REG-ID=0, REG-RD-ID=0, REG-LD-ID=0, ALU=0
LDAVR R4     step  2: -REG-FUNC-RD, -REG-UP, -VMA, ADDR-REG-ID=0, REG-RD-ID=0, REG-LD-ID=0, ALU=0
LDAVR R4     step  3: -MEM-RD, -VMA, ADDR-REG-ID=4, REG-RD-ID=0, REG-LD-ID=0, ALU=0
LDAVR R4     step  4: -MEM-RD, -VMA, -ALU-FUNC, ADDR-REG-ID=4, REG-RD-ID=0, REG-LD-ID=0, ALU=0
LDAVR R4     step  5: -MEM-RD, -VMA, -ALU-FUNC, -AC-LD, ADDR-REG-ID=4, REG-RD-ID=0, REG-LD-ID=0, ALU=0
LDAVR R4     step  6: -MEM-RD, -VMA, -ALU-FUNC, ADDR-REG-ID=4, REG-RD-ID=0, REG-LD-ID=0, ALU=0
LDAVR R4     step  7: -MEM-RD, -VMA, -ALU-FUNC, UCODE-COUNT-RESET, ADDR-REG-ID=4, REG-RD-ID=0, REG-LD-ID=0, ALU=0
LDAVR R5     step  0: -MEM-RD, -VMA, ADDR-REG-ID=0, REG-RD-ID=0, REG-LD-ID=0, ALU=0
LDAVR R5     step  1: -MEM-RD, -VMA, LD-INS-REG, ADDR-REG-ID=0, REG-RD-ID=0, REG-LD-ID=0, ALU=0
LDAVR R5     step  2: -REG-FUNC-RD, -REG-UP, -VMA, ADDR-REG-ID=0, REG-RD-ID=0, REG-LD-ID=0, ALU=0
LDAVR R5     step  3: -MEM-RD, -VMA, ADDR-REG-ID=5, REG-RD-ID=0, REG-LD-ID=0, ALU=0
LDAVR R5     step  4: -MEM-RD, -VMA, -ALU-FUNC, ADDR-REG-ID=5, REG-RD-ID=0, REG-LD-ID=0, ALU=0
LDAVR R5     step  5: -MEM-RD, -VMA, -ALU-FUNC, -AC-LD, ADDR-REG-ID=5, REG-RD-ID=0, REG-LD-ID=0, ALU=0
LDAVR R5     step  6: -MEM-RD, -VMA, -ALU-FUNC, ADDR-REG-ID=5, REG-RD-ID=0, REG-LD-ID=0, ALU=0
LDAVR R5     step  7: -MEM-RD, -VMA, -ALU-FUNC, UCODE-COUNT-RESET, ADDR-REG-ID=5, REG-RD-ID=0, REG-LD-ID=0, ALU=0
LDAVR R6     step  0: -MEM-RD, -VMA, ADDR-REG-ID=0, REG-RD-ID=0, REG-LD-ID=0, ALU=0
LDAVR R6     step  1: -MEM-RD, -VMA, LD-INS-REG, ADDR-REG-ID=0, REG-RD-ID=0, REG-LD-ID=0, ALU=0
LDAVR R6     step  2: -REG-FUNC-RD, -REG-UP, -VMA, ADDR-REG-ID=0, REG-RD-ID=0, REG-LD-ID=0, ALU=0
LDAVR R6     step  3: -MEM-RD, -VMA, ADDR-REG-ID=6, REG-RD-ID=0, REG-LD-ID=0, ALU=0
LDAVR R6     step  4: -MEM-RD, -VMA, -ALU-FUNC, ADDR-REG-ID=6, REG-RD-ID=0, REG-LD-ID=0, ALU=0
LDAVR R6     step  5: -MEM-RD, -VMA, -ALU-FUNC, -AC-LD, ADDR-REG-ID=6, REG-RD-ID=0, REG-LD-ID=0, ALU=0
LDAVR R6     step  6: -MEM-RD, -VMA, -ALU-FUNC, ADDR-REG-ID=6, REG-RD-ID=0, REG-LD-ID=0, ALU=0
LDAVR R6     step  7: -MEM-RD, -VMA, -ALU-FUNC, UCODE-COUNT-RESET, ADDR-REG-ID=6, REG-RD-ID=0, REG-LD-ID=0, ALU=0
LDAVR R7     step  0: -MEM-RD, -VMA, ADDR-REG-ID=0, REG-RD-ID=0, REG-LD-ID=0, ALU=0
LDAVR R7     step  1: -MEM-RD, -VMA, LD-INS-REG, ADDR-REG-ID=0, REG-RD-ID=0, REG-LD-ID=0, ALU=0
LDAVR R7     step  2: -REG-FUNC-RD, -REG-UP, -VMA, ADDR-REG-ID=0, REG-RD-ID=0, REG-LD-ID=0, ALU=0
LDAVR R7     step  3: -MEM-RD, -VMA, ADDR-REG-ID=7, REG-RD-ID=0, REG-LD-ID=0, ALU=0
LDAVR R7     step  4: -MEM-RD, -VMA, -ALU-FUNC, ADDR-REG-ID=7, REG-RD-ID=0, REG-LD-ID=0, ALU=0
LDAVR R7     step  5: -MEM-RD, -VMA, -ALU-FUNC, -AC-LD, ADDR-REG-ID=7, REG-RD-ID=0, REG-LD-ID=0, ALU=0
LDAVR R7     step  6: -MEM-RD, -VMA, -ALU-FUNC, ADDR-REG-ID=7, REG-RD-ID=0, REG-LD-ID=0, ALU=0
LDAVR R7     step  7: -MEM-RD, -VMA, -ALU-FUNC, UCODE-COUNT-RESET, ADDR-REG-ID=7, REG-RD-ID=0, REG-LD-ID=0, ALU=0
STAVR        step  0: -MEM-RD, -VMA, ADDR-REG-ID=0, REG-RD-ID=0, REG-LD-ID=0, ALU=0
STAVR        step  1: -MEM-RD, -VMA, LD-INS-REG, ADDR-REG-ID=0, REG-RD-ID=0, REG-LD-ID=0, ALU=0
STAVR        step  2: -REG-FUNC-RD, -REG-UP, -VMA, ADDR-REG-ID=0, REG-RD-ID=0, REG-LD-ID=0, ALU=0
STAVR        step  3: -VMA, -ALU-FUNC, ADDR-REG-ID=0, REG-RD-ID=0, REG-LD-ID=0, ALU=0
STAVR        step  4: -VMA, -ALU-FUNC, -AC-RD, ADDR-REG-ID=0, REG-RD-ID=0, REG-LD-ID=0, ALU=0
STAVR        step  5: -MEM-WR, -VMA, -ALU-FUNC, -AC-RD, ADDR-REG-ID=0, REG-RD-ID=0, REG-LD-ID=0, ALU=0
STAVR        step  6: -VMA, -ALU-FUNC, -AC-RD, ADDR-REG-ID=0, REG-RD-ID=0, REG-LD-ID=0, ALU=0
STAVR        step  7: -VMA, -ALU-FUNC, ADDR-REG-ID=0, REG-RD-ID=0, REG-LD-ID=0, ALU=0
STAVR        step  8: -VMA, -ALU-FUNC, UCODE-COUNT-RESET, ADDR-REG-ID=0, REG-RD-ID=0, REG-LD-ID=0, ALU=0
STAVR R1     step  0: -MEM-RD, -VMA, ADDR-REG-ID=0, REG-RD-ID=0, REG-LD-ID=0, ALU=0
STAVR R1     step  1: -MEM-RD, -VMA, LD-INS-REG, ADDR-REG-ID=0, REG-RD-ID=0, REG-LD-ID=0, ALU=0
STAVR R1     step  2: -REG-FUNC-RD, -REG-UP, -VMA, ADDR-REG-ID=0, REG-RD-ID=0, REG-LD-ID=0, ALU=0
STAVR R1     step  3: -VMA, -ALU-FUNC, ADDR-REG-ID=0, REG-RD-ID=0, REG-LD-ID=0, ALU=0
STAVR R1     step  4: -VMA, -ALU-FUNC, -AC-RD, ADDR-REG-ID=1, REG-RD-ID=0, REG-LD-ID=0, ALU=0
STAVR R1     step  5: -MEM-WR, -VMA, -ALU-FUNC, -AC-RD, ADDR-REG-ID=1, REG-RD-ID=0, REG-LD-ID=0, ALU=0
STAVR R1     step  6: -VMA, -ALU-FUNC, -AC-RD, ADDR-REG-ID=1, REG-RD-ID=0, REG-LD-ID=0, ALU=0
STAVR R1     step  7: -VMA, -ALU-FUNC, ADDR-REG-ID=1, REG-RD-ID=0, REG-LD-ID=0, ALU=0
STAVR R1     step  8: -VMA, -ALU-FUNC, UCODE-COUNT-RESET, ADDR-REG-ID=1, REG-RD-ID=0, REG-LD-ID=0, ALU=0
STAVR R2     step  0: -MEM-RD, -VMA, ADDR-REG-ID=0, REG-RD-ID=0, REG-LD-ID=0, ALU=0
STAVR R2     step  1: -MEM-RD, -VMA, LD-INS-REG, ADDR-REG-ID=0, REG-RD-ID=0, REG-LD-ID=0, ALU=0
STAVR R2     step  2: -REG-FUNC-RD, -REG-UP, -VMA, ADDR-REG-ID=0, REG-RD-ID=0, REG-LD-ID=0, ALU=0
STAVR R2     step  3: -VMA, -ALU-FUNC, ADDR-REG-ID=0, REG-RD-ID=0, REG-LD-ID=0, ALU=0
STAVR R2     step  4: -VMA, -ALU-FUNC, -AC-RD, ADDR-REG-ID=2, REG-RD-ID=0, REG-LD-ID=0, ALU=0
STAVR R2     step  5: -MEM-WR, -VMA, -ALU-FUNC, -AC-RD, ADDR-REG-ID=2, REG-RD-ID=0, REG-LD-ID=0, ALU=0
STAVR R2     step  6: -VMA, -ALU-FUNC, -AC-RD, ADDR-REG-ID=2, REG-RD-ID=0, REG-LD-ID=0, ALU=0
STAVR R2     step  7: -VMA, -ALU-FUNC, ADDR-REG-ID=2, REG-RD-ID=0, REG-LD-ID=0, ALU=0
STAVR R2     step  8: -VMA, -ALU-FUNC, UCODE-COUNT-RESET, ADDR-REG-ID=2, REG-RD-ID=0, REG-LD-ID=0, ALU=0
STAVR R3     step  0: -MEM-RD, -VMA, ADDR-REG-ID=0, REG-RD-ID=0, REG-LD-ID=0, ALU=0
STAVR R3     step  1: -MEM-RD, -VMA, LD-INS-REG, ADDR-REG-ID=0, REG-RD-ID=0, REG-LD-ID=0, ALU=0
STAVR R3     step  2: -REG-FUNC-RD, -REG-UP, -VMA, ADDR-REG-ID=0, REG-RD-ID=0, REG-LD-ID=0, ALU=0
STAVR R3     step  3: -VMA, -ALU-FUNC, ADDR-REG-ID=0, REG-RD-ID=0, REG-LD-ID=0, ALU=0
STAVR R3     step  4: -VMA, -ALU-FUNC, -AC-RD, ADDR-REG-ID=3, REG-RD-ID=0, REG-LD-ID=0, ALU=0
STAVR R3     step  5: -MEM-WR, -VMA, -ALU-FUNC, -AC-RD, ADDR-REG-ID=3, REG-RD-ID=0, REG-LD-ID=0, ALU=0
STAVR R3     step  6: -VMA, -ALU-FUNC, -AC-RD, ADDR-REG-ID=3, REG-RD-ID=0, REG-LD-ID=0, ALU=0
STAVR R3     step  7: -VMA, -ALU-FUNC, ADDR-REG-ID=3, REG-RD-ID=0, REG-LD-ID=0, ALU=0
STAVR R3     step  8: -VMA, -ALU-FUNC, UCODE-COUNT-RESET, ADDR-REG-ID=3, REG-RD-ID=0, REG-LD-ID=0, ALU=0
STAVR R4     step  0: -MEM-RD, -VMA, ADDR-REG-ID=0, REG-RD-ID=0, REG-LD-ID=0, ALU=0
STAVR R4     step  1: -MEM-RD, -VMA, LD-INS-REG, ADDR-REG-ID=0, REG-RD-ID=0, REG-LD-ID=0, ALU=0
STAVR R4     step  2: -REG-FUNC-RD, -REG-UP, -VMA, ADDR-REG-ID=0, REG-RD-ID=0, REG-LD-ID=0, ALU=0
STAVR R4     step  3: -VMA, -ALU-FUNC, ADDR-REG-ID=0, REG-RD-ID=0, REG-LD-ID=0, ALU=0
STAVR R4     step  4: -VMA, -ALU-FUNC, -AC-RD, ADDR-REG-ID=4, REG-RD-ID=0, REG-LD-ID=0, ALU=0
STAVR R4     step  5: -MEM-WR, -VMA, -ALU-FUNC, -AC-RD, ADDR-REG-ID=4, REG-RD-ID=0, REG-LD-ID=0, ALU=0
STAVR R4     step  6: -VMA, -ALU-FUNC, -AC-RD, ADDR-REG-ID=4, REG-RD-ID=0, REG-LD-ID=0, ALU=0
STAVR R4     step  7: -VMA, -ALU-FUNC, ADDR-REG-ID=4, REG-RD-ID=0, REG-LD-ID=0, ALU=0
STAVR R4     step  8: -VMA, -ALU-FUNC, UCODE-COUNT-RESET, ADDR-REG-ID=4, REG-RD-ID=0, REG-LD-ID=0, ALU=0
STAVR R5     step  0: -MEM-RD, -VMA, ADDR-REG-ID=0, REG-RD-ID=0, REG-LD-ID=0, ALU=0
STAVR R5     step  1: -MEM-RD, -VMA, LD-INS-REG, ADDR-REG-ID=0, REG-RD-ID=0, REG-LD-ID=0, ALU=0
STAVR R5     step  2: -REG-FUNC-RD, -REG-UP, -VMA, ADDR-REG-ID=0, REG-RD-ID=0, REG-LD-ID=0, ALU=0
STAVR R5     step  3: -VMA, -ALU-FUNC, ADDR-REG-ID=0, REG-RD-ID=0, REG-LD-ID=0, ALU=0
STAVR R5     step  4: -VMA, -ALU-FUNC, -AC-RD, ADDR-REG-ID=5, REG-RD-ID=0, REG-LD-ID=0, ALU=0
STAVR R5     step  5: -MEM-WR, -VMA, -ALU-FUNC, -AC-RD, ADDR-REG-ID=5, REG-RD-ID=0, REG-LD-ID=0, ALU=0
STAVR R5     step  6: -VMA, -ALU-FUNC, -AC-RD, ADDR-REG-ID=5, REG-RD-ID=0, REG-LD-ID=0, ALU=0
STAVR R5     step  7: -VMA, -ALU-FUNC, ADDR-REG-ID=5, REG-RD-ID=0, REG-LD-ID=0, ALU=0
STAVR R5     step  8: -VMA, -ALU-FUNC, UCODE-COUNT-RESET, ADDR-REG-ID=5, REG-RD-ID=0, REG-LD-ID=0, ALU=0
STAVR R6     step  0: -MEM-RD, -VMA, ADDR-REG-ID=0, REG-RD-ID=0, REG-LD-ID=0, ALU=0
STAVR R6     step  1: -MEM-RD, -VMA, LD-INS-REG, ADDR-REG-ID=0, REG-RD-ID=0, REG-LD-ID=0, ALU=0
STAVR R6     step  2: -REG-FUNC-RD, -REG-UP, -VMA, ADDR-REG-ID=0, REG-RD-ID=0, REG-LD-ID=0, ALU=0
STAVR R6     step  3: -VMA, -ALU-FUNC, ADDR-REG-ID=0, REG-RD-ID=0, REG-LD-ID=0, ALU=0
STAVR R6     step  4: -VMA, -ALU-FUNC, -AC-RD, ADDR-REG-ID=6, REG-RD-ID=0, REG-LD-ID=0, ALU=0
STAVR R6     step  5: -MEM-WR, -VMA, -ALU-FUNC, -AC-RD, ADDR-REG-ID=6, REG-RD-ID=0, REG-LD-ID=0, ALU=0
STAVR R6     step  6: -VMA, -ALU-FUNC, -AC-RD, ADDR-REG-ID=6, REG-RD-ID=0, REG-LD-ID=0, ALU=0
STAVR R6     step  7: -VMA, -ALU-FUNC, ADDR-REG-ID=6, REG-RD-ID=0, REG-LD-ID=0, ALU=0
STAVR R6     step  8: -VMA, -ALU-FUNC, UCODE-COUNT-RESET, ADDR-REG-ID=6, REG-RD-ID=0, REG-LD-ID=0, ALU=0
STAVR R7     step  0: -MEM-RD, -VMA, ADDR-REG-ID=0, REG-RD-ID=0, REG-LD-ID=0, ALU=0
STAVR R7     step  1: -MEM-RD, -VMA, LD-INS-REG, ADDR-REG-ID=0, REG-RD-ID=0, REG-LD-ID=0, ALU=0
STAVR R7     step  2: -REG-FUNC-RD, -REG-UP, -VMA, ADDR-REG-ID=0, REG-RD-ID=0, REG-LD-ID=0, ALU=0
STAVR R7     step  3: -VMA, -ALU-FUNC, ADDR-REG-ID=0, REG-RD-ID=0, REG-LD-ID=0, ALU=0
STAVR R7     step  4: -VMA, -ALU-FUNC, -AC-RD, ADDR-REG-ID=7, REG-RD-ID=0, REG-LD-ID=0, ALU=0
STAVR R7     step  5: -MEM-WR, -VMA, -ALU-FUNC, -AC-RD, ADDR-REG-ID=7, REG-RD-ID=0, REG-LD-ID=0, ALU=0
STAVR R7     step  6: -VMA, -ALU-FUNC, -AC-RD, ADDR-REG-ID=7, REG-RD-ID=0, REG-LD-ID=0, ALU=0
STAVR R7     step  7: -VMA, -ALU-FUNC, ADDR-REG-ID=7, REG-RD-ID=0, REG-LD-ID=0, ALU=0
STAVR R7     step  8: -VMA, -ALU-FUNC, UCODE-COUNT-RESET, ADDR-REG-ID=7, REG-RD-ID=0, REG-LD-ID=0, ALU=0
INCR         step  0: -MEM-RD, -VMA, ADDR-REG-ID=0, REG-RD-ID=0, REG-LD-ID=0, ALU=0
INCR         step  1: -MEM-RD, -VMA, LD-INS-REG, ADDR-REG-ID=0, REG-RD-ID=0, REG-LD-ID=0, ALU=0
INCR         step  2: -REG-FUNC-RD, -REG-UP, -VMA, ADDR-REG-ID=0, REG-RD-ID=0, REG-LD-ID=0, ALU=0
INCR         step  3: -VMA, ADDR-REG-ID=0, REG-RD-ID=0, REG-LD-ID=0, ALU=0
INCR         step  4: -REG-FUNC-RD, -REG-UP, -VMA, ADDR-REG-ID=0, REG-RD-ID=0, REG-LD-ID=0, ALU=0
INCR         step  5: -VMA, UCODE-COUNT-RESET, ADDR-REG-ID=0, REG-RD-ID=0, REG-LD-ID=0, ALU=0
INCR R1      step  0: -MEM-RD, -VMA, ADDR-REG-ID=0, REG-RD-ID=0, REG-LD-ID=0, ALU=0
INCR R1      step  1: -MEM-RD, -VMA, LD-INS-REG, ADDR-REG-ID=0, REG-RD-ID=0, REG-LD-ID=0, ALU=0
INCR R1      step  2: -REG-FUNC-RD, -REG-UP, -VMA, ADDR-REG-ID=0, REG-RD-ID=0, REG-LD-ID=0, ALU=0
INCR R1      step  3: -VMA, ADDR-REG-ID=0, REG-RD-ID=0, REG-LD-ID=0, ALU=0
INCR R1      step  4: -REG-FUNC-RD, -REG-UP, -VMA, ADDR-REG-ID=0, REG-RD-ID=1, REG-LD-ID=0, ALU=0
INCR R1      step  5: -VMA, UCODE-COUNT-RESET, ADDR-REG-ID=0, REG-RD-ID=1, REG-LD-ID=0, ALU=0
INCR R2      step  0: -MEM-RD, -VMA, ADDR-REG-ID=0, REG-RD-ID=0, REG-LD-ID=0, ALU=0
INCR R2      step  1: -MEM-RD, -VMA, LD-INS-REG, ADDR-REG-ID=0, REG-RD-ID=0, REG-LD-ID=0, ALU=0
INCR R2      step  2: -REG-FUNC-RD, -REG-UP, -VMA, ADDR-REG-ID=0, REG-RD-ID=0, REG-LD-ID=0, ALU=0
INCR R2      step  3: -VMA, ADDR-REG-ID=0, REG-RD-ID=0, REG-LD-ID=0, ALU=0
INCR R2      step  4: -REG-FUNC-RD, -REG-UP, -VMA, ADDR-REG-ID=0, REG-RD-ID=2, REG-LD-ID=0, ALU=0
INCR R2      step  5: -VMA, UCODE-COUNT-RESET, ADDR-REG-ID=0, REG-RD-ID=2, REG-LD-ID=0, ALU=0
INCR R3      step  0: -MEM-RD, -VMA, ADDR-REG-ID=0, REG-RD-ID=0, REG-LD-ID=0, ALU=0
INCR R3      step  1: -MEM-RD, -VMA, LD-INS-REG, ADDR-REG-ID=0, REG-RD-ID=0, REG-LD-ID=0, ALU=0
INCR R3      step  2: -REG-FUNC-RD, -REG-UP, -VMA, ADDR-REG-ID=0, REG-RD-ID=0, REG-LD-ID=0, ALU=0
INCR R3      step  3: -VMA, ADDR-REG-ID=0, REG-RD-ID=0, REG-LD-ID=0, ALU=0
INCR R3      step  4: -REG-FUNC-RD, -REG-UP, -VMA, ADDR-REG-ID=0, REG-RD-ID=3, REG-LD-ID=0, ALU=0
INCR R3      step  5: -VMA, UCODE-COUNT-RESET, ADDR-REG-ID=0, REG-RD-ID=3, REG-LD-ID=0, ALU=0
INCR R4      step  0: -MEM-RD, -VMA, ADDR-REG-ID=0, REG-RD-ID=0, REG-LD-ID=0, ALU=0
INCR R4      step  1: -MEM-RD, -VMA, LD-INS-REG, ADDR-REG-ID=0, REG-RD-ID=0, REG-LD-ID=0, ALU=0
INCR R4      step  2: -REG-FUNC-RD, -REG-UP, -VMA, ADDR-REG-ID=0, REG-RD-ID=0, REG-LD-ID=0, ALU=0
INCR R4      step  3: -VMA, ADDR-REG-ID=0, REG-RD-ID=0, REG-LD-ID=0, ALU=0
INCR R4      step  4: -REG-FUNC-RD, -REG-UP, -VMA, ADDR-REG-ID=0, REG-RD-ID=4, REG-LD-ID=0, ALU=0
INCR R4      step  5: -VMA, UCODE-COUNT-RESET, ADDR-REG-ID=0, REG-RD-ID=4, REG-LD-ID=0, ALU=0
INCR R5      step  0: -MEM-RD, -VMA, ADDR-REG-ID=0, REG-RD-ID=0, REG-LD-ID=0, ALU=0
INCR R5      step  1: -MEM-RD, -VMA, LD-INS-REG, ADDR-REG-ID=0, REG-RD-ID=0, REG-LD-ID=0, ALU=0
INCR R5      step  2: -REG-FUNC-RD, -REG-UP, -VMA, ADDR-REG-ID=0, REG-RD-ID=0, REG-LD-ID=0, ALU=0
INCR R5      step  3: -VMA, ADDR-REG-ID=0, REG-RD-ID=0, REG-LD-ID=0, ALU=0
INCR R5      step  4: -REG-FUNC-RD, -REG-UP, -VMA, ADDR-REG-ID=0, REG-RD-ID=5, REG-LD-ID=0, ALU=0
INCR R5      step  5: -VMA, UCODE-COUNT-RESET, ADDR-REG-ID=0, REG-RD-ID=5, REG-LD-ID=0, ALU=0
INCR R6      step  0: -MEM-RD, -VMA, ADDR-REG-ID=0, REG-RD-ID=0, REG-LD-ID=0, ALU=0
INCR R6      step  1: -MEM-RD, -VMA, LD-INS-REG, ADDR-REG-ID=0, REG-RD-ID=0, REG-LD-ID=0, ALU=0
INCR R6      step  2: -REG-FUNC-RD, -REG-UP, -VMA, ADDR-REG-ID=0, REG-RD-ID=0, REG-LD-ID=0, ALU=0
INCR R6      step  3: -VMA, ADDR-REG-ID=0, REG-RD-ID=0, REG-LD-ID=0, ALU=0
INCR R6      step  4: -REG-FUNC-RD, -REG-UP, -VMA, ADDR-REG-ID=0, REG-RD-ID=6, REG-LD-ID=0, ALU=0
INCR R6      step  5: -VMA, UCODE-COUNT-RESET, ADDR-REG-ID=0, REG-RD-ID=6, REG-LD-ID=0, ALU=0
INCR R7      step  0: -MEM-RD, -VMA, ADDR-REG-ID=0, REG-RD-ID=0, REG-LD-ID=0, ALU=0
INCR R7      step  1: -MEM-RD, -VMA, LD-INS-REG, ADDR-REG-ID=0, REG-RD-ID=0, REG-LD-ID=0, ALU=0
INCR R7      step  2: -REG-FUNC-RD, -REG-UP, -VMA, ADDR-REG-ID=0, REG-RD-ID=0, REG-LD-ID=0, ALU=0
INCR R7      step  3: -VMA, ADDR-REG-ID=0, REG-RD-ID=0, REG-LD-ID=0, ALU=0
INCR R7      step  4: -REG-FUNC-RD, -REG-UP, -VMA, ADDR-REG-ID=0, REG-RD-ID=7, REG-LD-ID=0, ALU=0
INCR R7      step  5: -VMA, UCODE-COUNT-RESET, ADDR-REG-ID=0, REG-RD-ID=7, REG-LD-ID=0, ALU=0
DECR         step  0: -MEM-RD, -VMA, ADDR-REG-ID=0, REG-RD-ID=0, REG-LD-ID=0, ALU=0
DECR         step  1: -MEM-RD, -VMA, LD-INS-REG, ADDR-REG-ID=0, REG-RD-ID=0, REG-LD-ID=0, ALU=0
DECR         step  2: -REG-FUNC-RD, -REG-UP, -VMA, ADDR-REG-ID=0, REG-RD-ID=0, REG-LD-ID=0, ALU=0
DECR         step  3: -REG-FUNC-RD, -VMA, ADDR-REG-ID=0, REG-RD-ID=0, REG-LD-ID=0, ALU=0
DECR         step  4: -REG-FUNC-RD, -REG-DN, -VMA, ADDR-REG-ID=0, REG-RD-ID=0, REG-LD-ID=0, ALU=0
DECR         step  5: -VMA, UCODE-COUNT-RESET, ADDR-REG-ID=0, REG-RD-ID=0, REG-LD-ID=0, ALU=0
DECR R1      step  0: -MEM-RD, -VMA, ADDR-REG-ID=0, REG-RD-ID=0, REG-LD-ID=0, ALU=0
DECR R1      step  1: -MEM-RD, -VMA, LD-INS-REG, ADDR-REG-ID=0, REG-RD-ID=0, REG-LD-ID=0, ALU=0
DECR R1      step  2: -REG-FUNC-RD, -REG-UP, -VMA, ADDR-REG-ID=0, REG-RD-ID=0, REG-LD-ID=0, ALU=0
DECR R1      step  3: -VMA, ADDR-REG-ID=0, REG-RD-ID=0, REG-LD-ID=0, ALU=0
DECR R1      step  4: -REG-FUNC-RD, -VMA, ADDR-REG-ID=0, REG-RD-ID=1, REG-LD-ID=0, ALU=0
DECR R1      step  5: -REG-FUNC-RD, -REG-DN, -VMA, ADDR-REG-ID=0, REG-RD-ID=1, REG-LD-ID=0, ALU=0
DECR R1      step  6: -VMA, UCODE-COUNT-RESET, ADDR-REG-ID=0, REG-RD-ID=1, REG-LD-ID=0, ALU=0
DECR R2      step  0: -MEM-RD, -VMA, ADDR-REG-ID=0, REG-RD-ID=0, REG-LD-ID=0, ALU=0
DECR R2      step  1: -MEM-RD, -VMA, LD-INS-REG, ADDR-REG-ID=0, REG-RD-ID=0, REG-LD-ID=0, ALU=0
DECR R2      step  2: -REG-FUNC-RD, -REG-UP, -VMA, ADDR-REG-ID=0, REG-RD-ID=0, REG-LD-ID=0, ALU=0
DECR R2      step  3: -VMA, ADDR-REG-ID=0, REG-RD-ID=0, REG-LD-ID=0, ALU=0
DECR R2      step  4: -REG-FUNC-RD, -VMA, ADDR-REG-ID=0, REG-RD-ID=2, REG-LD-ID=0, ALU=0
DECR R2      step  5: -REG-FUNC-RD, -REG-DN, -VMA, ADDR-REG-ID=0, REG-RD-ID=2, REG-LD-ID=0, ALU=0
DECR R2      step  6: -VMA, UCODE-COUNT-RESET, ADDR-REG-ID=0, REG-RD-ID=2, REG-LD-ID=0, ALU=0
DECR R3      step  0: -MEM-RD, -VMA, ADDR-REG-ID=0, REG-RD-ID=0, REG-LD-ID=0, ALU=0
DECR R3      step  1: -MEM-RD, -VMA, LD-INS-REG, ADDR-REG-ID=0, REG-RD-ID=0, REG-LD-ID=0, ALU=0
DECR R3      step  2: -REG-FUNC-RD, -REG-UP, -VMA, ADDR-REG-ID=0, REG-RD-ID=0, REG-LD-ID=0, ALU=0
DECR R3      step  3: -VMA, ADDR-REG-ID=0, REG-RD-ID=0, REG-LD-ID=0, ALU=0
DECR R3      step  4: -REG-FUNC-RD, -VMA, ADDR-REG-ID=0, REG-RD-ID=3, REG-LD-ID=0, ALU=0
DECR R3      step  5: -REG-FUNC-RD, -REG-DN, -VMA, ADDR-REG-ID=0, REG-RD-ID=3, REG-LD-ID=0, ALU=0
DECR R3      step  6: -VMA, UCODE-COUNT-RESET, ADDR-REG-ID=0, REG-RD-ID=3, REG-LD-ID=0, ALU=0
DECR R4      step  0: -MEM-RD, -VMA, ADDR-REG-ID=0, REG-RD-ID=0, REG-LD-ID=0, ALU=0
DECR R4      step  1: -MEM-RD, -VMA, LD-INS-REG, ADDR-REG-ID=0, REG-RD-ID=0, REG-LD-ID=0, ALU=0
DECR R4      step  2: -REG-FUNC-RD, -REG-UP, -VMA, ADDR-REG-ID=0, REG-RD-ID=0, REG-LD-ID=0, ALU=0
DECR R4      step  3: -VMA, ADDR-REG-ID=0, REG-RD-ID=0, REG-LD-ID=0, ALU=0
DECR R4      step  4: -REG-FUNC-RD, -VMA, ADDR-REG-ID=0, REG-RD-ID=4, REG-LD-ID=0, ALU=0
DECR R4      step  5: -REG-FUNC-RD, -REG-DN, -VMA, ADDR-REG-ID=0, REG-RD-ID=4, REG-LD-ID=0, ALU=0
DECR R4      step  6: -VMA, UCODE-COUNT-RESET, ADDR-REG-ID=0, REG-RD-ID=4, REG-LD-ID=0, ALU=0
DECR R5      step  0: -MEM-RD, -VMA, ADDR-REG-ID=0, REG-RD-ID=0, REG-LD-ID=0, ALU=0
DECR R5      step  1: -MEM-RD, -VMA, LD-INS-REG, ADDR-REG-ID=0, REG-RD-ID=0, REG-LD-ID=0, ALU=0
DECR R5      step  2: -REG-FUNC-RD, -REG-UP, -VMA, ADDR-REG-ID=0, REG-RD-ID=0, REG-LD-ID=0, ALU=0
DECR R5      step  3: -VMA, ADDR-REG-ID=0, REG-RD-ID=0, REG-LD-ID=0, ALU=0
DECR R5      step  4: -REG-FUNC-RD, -VMA, ADDR-REG-ID=0, REG-RD-ID=5, REG-LD-ID=0, ALU=0
DECR R5      step  5: -REG-FUNC-RD, -REG-DN, -VMA, ADDR-REG-ID=0, REG-RD-ID=5, REG-LD-ID=0, ALU=0
DECR R5      step  6: -VMA, UCODE-COUNT-RESET, ADDR-REG-ID=0, REG-RD-ID=5, REG-LD-ID=0, ALU=0
DECR R6      step  0: -MEM-RD, -VMA, ADDR-REG-ID=0, REG-RD-ID=0, REG-LD-ID=0, ALU=0
DECR R6      step  1: -MEM-RD, -VMA, LD-INS-REG, ADDR-REG-ID=0, REG-RD-ID=0, REG-LD-ID=0, ALU=0
DECR R6      step  2: -REG-FUNC-RD, -REG-UP, -VMA, ADDR-REG-ID=0, REG-RD-ID=0, REG-LD-ID=0, ALU=0
DECR R6      step  3: -VMA, ADDR-REG-ID=0, REG-RD-ID=0, REG-LD-ID=0, ALU=0
DECR R6      step  4: -REG-FUNC-RD, -VMA, ADDR-REG-ID=0, REG-RD-ID=6, REG-LD-ID=0, ALU=0
DECR R6      step  5: -REG-FUNC-RD, -REG-DN, -VMA, ADDR-REG-ID=0, REG-RD-ID=6, REG-LD-ID=0, ALU=0
DECR R6      step  6: -VMA, UCODE-COUNT-RESET, ADDR-REG-ID=0, REG-RD-ID=6, REG-LD-ID=0, ALU=0
DECR R7      step  0: -MEM-RD, -VMA, ADDR-REG-ID=0, REG-RD-ID=0, REG-LD-ID=0, ALU=0
DECR R7      step  1: -MEM-RD, -VMA, LD-INS-REG, ADDR-REG-ID=0, REG-RD-ID=0, REG-LD-ID=0, ALU=0
DECR R7      step  2: -REG-FUNC-RD, -REG-UP, -VMA, ADDR-REG-ID=0, REG-RD-ID=0, REG-LD-ID=0, ALU=0
DECR R7      step  3: -VMA, ADDR-REG-ID=0, REG-RD-ID=0, REG-LD-ID=0, ALU=0
DECR R7      step  4: -REG-FUNC-RD, -VMA, ADDR-REG-ID=0, REG-RD-ID=7, REG-LD-ID=0, ALU=0
DECR R7      step  5: -REG-FUNC-RD, -REG-DN, -VMA, ADDR-REG-ID=0, REG-RD-ID=7, REG-LD-ID=0, ALU=0
DECR R7      step  6: -VMA, UCODE-COUNT-RESET, ADDR-REG-ID=0, REG-RD-ID=7, REG-LD-ID=0, ALU=0
OUTA         step  0: -MEM-RD, -VMA, ADDR-REG-ID=0, REG-RD-ID=0, REG-LD-ID=0, ALU=0
OUTA         step  1: -MEM-RD, -VMA, LD-INS-REG, ADDR-REG-ID=0, REG-RD-ID=0, REG-LD-ID=0, ALU=0
OUTA         step  2: -REG-FUNC-RD, -REG-UP, -VMA, ADDR-REG-ID=0, REG-RD-ID=0, REG-LD-ID=0, ALU=0
OUTA         step  3: -VMA, -ALU-FUNC, -AC-RD, ADDR-REG-ID=0, REG-RD-ID=0, REG-LD-ID=0, ALU=0
OUTA         step  4: -IO-ADDR-LD, -VMA, -ALU-FUNC, -AC-RD, ADDR-REG-ID=0, REG-RD-ID=0, REG-LD-ID=0, ALU=0
OUTA         step  5: -VMA, -ALU-FUNC, -AC-RD, ADDR-REG-ID=0, REG-RD-ID=0, REG-LD-ID=0, ALU=0
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

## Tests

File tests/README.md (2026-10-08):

# tests

- `bus-tester-scripts/` — `CMD:OPERAND#` scripts for the Bus Test Card (sent by `embedded/command-sender/` or
  `tools/busdrv.py`): `ALU/*.new` (2020 signal names), `IO/`, `Index Register/`, `Memory Card Tests/`,
  `Gen Test Vectors/` (C program that generates vector scripts), `ramtest.logicsettings` (Saleae Logic capture setup).
  `deprecated/gen1-2016/` = the 2016 gen-1 scripts in the OLD signal names (RESET, ALU-FUNC, RD-AC, WDATA…) plus `fix`,
  the sed converter that produced the `.new` files; `deprecated/address-register-2020-07/` = tests for the retired card.
- `assembler/` — `yacc1test.asm`, the CPU test program (2020-10-31), its 15 dated 2020 snapshots, a 2026 run log; `ledcount/`
  (the 16-byte switch-ROM LED counter); `brur/` (the BRUR $AD test, `ABC0123` on the emulator, 2026-09-22).
- `memory/` — `rom_verify.py` (~30 s): every ROM byte against the image assembled from `basic.img` + `monitor.img`;
  `memory_status.py` (~1 min): boot remap, every ROM byte against `basic.img` + `monitor.img` (what the emulator
  loads; `tools/romimage.py`), low RAM spots, and a classification of every 4K block above $8000 (RAM / ROM / video /
  undecoded). `memory_full_test.py` (~16 min with the blocks-1 bus-tester firmware): ROM, address lines, two full RAM
  patterns over $0000-$CFFF written then verified in separate sweeps, the video RAM, ROM again. Logs beside them:
  2026-09-21 all RAM cells good, ROM = sources, video RAM good.
- `sequencer/` — run-mode boot transcripts of the sequencer-memory ATmega (2026-09-21): the clobbered copy with -BUS-EN
  asserted, the clean copy with the bus quiet, and the Sequencer4 boot (16 s copy, 29 s verify, RAM == EEPROM).
- `video/` — `video_ram_test.py`, the video card's display-RAM test over the bus tester (patterns, inverse, neighbour
  isolation, the block-0/9 write-through check, read stability); 8/8 on 2026-09-21 after the +5V/VCC join.
- `basic/` — `test`, a small BASIC program (LET/FOR loops) used to exercise the interpreter.
- `compiler/` — the C compiler's test programs (`*.c` + expected `.out`/`.in`/`.err`) and `run.py`, which compiles each with
  `software/compiler/y1cc.py --boot`, assembles it and runs it on `emulator -x`; `--oracle` regenerates the expectations with
  the host C compiler through `host_shim.h`. 15/15 on 2026-09-22 (switch.c also compiled with `--no-brur` as switchnb.c); `make cc-test`.
  22 programs since 2026-09-24 (the recursion tests `rfact rmutual rlocals rcalc`, errors `recurse rmain adjstr`). Beside it:
  `corpus.py` (every C program the tree compiles, with its options), `diffcheck.py` (an old y1cc.py from git against the
  working one over the corpus: identical assembly), `twin.py` (y1cc.py against its C twin `software/compiler/c/y1cc`, also
  `--16`; `--chain`/`--chain16` against the multi-pass compiler `y1ccp`, cc1..cc9), `twinfuzz.py` (random subset programs and
  60 invalid ones through both compilers; `--chain` too), `passes.py` (each pass of the multi-pass compiler against the Y1/OS
  program area: image, tables, measured stack; the corpus through the passes with their Y1/OS table sizes). Since
  2026-09-24 `run.py`, `twin.py`, `twinfuzz.py`, `passes.py` and `../ucemu/run.py` take `--xisa` (every compile with
  y1cc's `--xisa`: the LDZ/STZ page, ADDIW, SHL16), `xisa.c` (`// y1cc: --xisa`) is the 23rd program, and `diffcheck.py`
  proves the default output unchanged.
- `os/` — Y1/OS: `run.py` builds `os/disk.img`, boots it on both emulators with the console script `basic.session`
  after the monitor's `O` command, and diffs the transcripts (`basic.int.out`, `basic.uc.out`; the latter shows the
  monitor's input echo). `make os-test`. `NOXISA=1 python3 tests/os/run.py` runs the same sessions with every
  `/BIN` program built by y1cc `--no-xisa` (`make -C os NOXISA=1`; `--xisa` is the default since 2026-10-04); the
  program sizes `ls`/`load` print are masked.
- `asm/` — the native assemblers `/BIN/ASMC` (asm.c, 2026-09-25) and `/BIN/ASM` (asm.asm, in YACC1 assembly, 2026-09-26;
  `run.py` also runs it under Y1/OS on the instruction-level emulator on the whole corpus and compares its messages
  and files with asm.c's, `--uc` 27 sources on the microcode emulator too): `run.py` builds `os/commands/asm.c` for the Mac against an
  emulation of the Y1/OS syscalls (`host_asm.c`, `host_sys.c`: int = unsigned short, unsigned char) and compares it with
  the host assembler RC/asm on every source in the tree (the y1cc corpus plain and `--xisa`, the firmware, the
  hand-written tests, `y1os.asm`, and `src/`: `quirks.asm` with two INCLUDE levels, six sources both must refuse), as
  Intel hex and as program files: 297 sources, 0 different. `run.py --target` (`target.py`, `target.session`, the
  transcripts `target.int.out`/`target.uc.out`) runs `asm` under Y1/OS on both emulators - y1cc programs assembled
  and run, the ROM monitor, `isa.asm`, compiler pass cc4 - and compares every file it wrote with RC/asm's output.
  `make asm-test`; both in `make check`.
- `disasm/` — `/BIN/DISASM` (os/commands/disasm.c, 2026-09-29): `run.py` builds it for the Mac (`host_disasm.c`,
  `host_sys.c`: int = unsigned short, OPEN/GETC/CLOSE/ENTRY/SEEK and peek emulated) and round-trips - `disasm -s`,
  RC/asm, the same bytes, the listing true to them - over tests/asm's corpus, every program of the OS build, the ROM
  from memory, random bytes and every opcode + operand byte (382, ~20 s), then START/COUNT ranges and the errors;
  `tools/gen_y1_distab.py --check` first. The run on Y1/OS is `tests/os/disasm.session`. `make disasm-test`; in
  `make check`.
- `ucemu/` — the same programs (and `assembler/brur`) on the MICROCODE-level emulator `software/ucemu` with the monitor ROM
  loaded (`run.py`, 14/14 on 2026-09-22, `chars.ucout` = the expectation with the monitor's input echo), and `isa.asm`, a
  differential test of every instruction whose port-2 byte stream must be identical on both emulators (it is, BRDEV aside;
  since 2026-09-24 it covers LDZ/STZ/ADDIW/SHL16 too, 114 bytes, and `tests/bench` runs it on the machine).
- `y1term/` — `tools/y1term.py --send` against the microcode emulator through a pty (2026-10-08): `good.bas` (lower
  case, a tab, a blank line, a `#` comment, FOR/NEXT) sent with `--new --run` must print `Hello 1 2 3 21`; `bad.bas`
  must exit 1 naming its `print !` line as SYNTAX ERROR, the other lines stored. In `make check`.
- `kermit/` — `/BIN/KERMIT` (2026-09-26): `run.py` boots Y1/OS on both emulators with the console on a pseudo-terminal
  and runs `tools/y1kermit.py` against `kermit -r`, `-s` and `-x`: text, all 256 byte values, a 70K file, long runs, an
  empty file, a name to clean; block checks 1-2, 8th-bit prefixing, text mode, `-n`, `-a`; damaged, missing and
  unanswered packets both ways, three Ctrl-Cs; the server's SEND/GET/FINISH. Files compared on the host and on the
  disk image (`p8xfs.py get`, fsck); the throughput from the instruction-level emulator's PC histogram; `--calib`
  checks `os/kermit_io.asm`'s timing on the microcode emulator (a timeout second = 1,000,176 clocks, 217 clocks a
  received character, with the 2026-09-29 microcode). In `make check` (~2.5 minutes).
- Hardware findings of 2026-09 (memory-card block map, EPROM identity, video-card write-through) are in the card READMEs.

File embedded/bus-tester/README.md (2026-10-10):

Bus Test Card Software

bus-driver
    Command line interface to drive/read bus signals
    see BUS Driver Commands (gdoc) for more information

bus-monitor
    Listens to bus and reports changes

bus-test
    Tests for shorts on bus

led-switch-test
    Simple test of LEDs & Switchs
    Read switches, adds 1, displays on LEDS

Test EEPROM
    Simple test to verify onboard controller can read/write onboard EEPROM chip

BUS Driver commands
    Command format for bus-driver program

---
*YACC1-D note (2026-09-19): the text above is the original Readme.md migrated from `YACC1-2024/Software-vs/Bus Test Card/Readme.md`. Placeholder description from the tree layout:*

# embedded/bus-tester

bus-driver (drive), bus-monitor (listen), bus-test, led-switch-test, test-eeprom. Separate sketches, loaded one at a time.

_Contents migrated 2026-09-19; MIGRATION.md at the repo root says which copy each item came from._

## Block memory commands (bus-driver, 2026-09-21)

The per-byte idiom costs 4 round trips per byte (~0.16 s at 19200 baud, mostly USB latency). `bus-driver.ino` now also
answers `RDBLK:addr,count#` (1–64 bytes back as `Data: hh hh ...`) and `WRBLK:addr,count,hh...#` (1–32 bytes in, 2 hex
digits each): one round trip per block, the same -MEM-RD / -MEM-WR pulses as before, data-bus direction switched by the
card. It prints `bus-driver blocks-1 2026-09-21` before its first prompt; `tools/busdrv.py` looks for `blocks-` in that
banner and uses `read_block()` / `write_block()` (falling back to the per-byte commands on the older firmware, which
would HALT on an unknown opcode - never send RDBLK to it). Block errors reply `Error: ...` without halting. Baud is the
`BAUD` define (19200; busdrv.py and the Processing sender must match). **Flashed to the card 2026-09-21** (arduino-cli, Uno, 115200 through the FTDI); the previous flash - the 2020 bus-driver - was read out first to `readback/`.

## bus-stepper (2026-10-10)

The card as a single-step clock for the sequencer that reads the whole bus after every edge: IC6 GPA4 (the OUT-LED pin,
which only drives the card's own LED through R16) becomes the clock output, jumpered to the sequencer's JP4 pin 2
(EXTERNAL-SINGLESTEP-CLK, SS-SEL on 2-3); with the sequencer's SS/WAIT toggle on FREERUN the machine runs from its
oscillator, on SS from the tester. 115200 baud; commands `p`, `t`, `nN`, `qN`, `l0|1`, `fAAAA,BB[,M]` (step until the
opcode BB is fetched from AAAA) - the sketch's header has the details. `tools/busstep.py` sends them and decodes each
line (address, data, the register-select fields, the asserted strobes). Built to single-step POPR, which loads wrong
values at 1 MHz and right ones at 6 MHz (`tests/bench/diag/poprloop.asm`, `BACKLOG.md`). Flash with `arduino-cli
compile --fqbn arduino:avr:uno --libraries embedded/libraries -u -p /dev/cu.usbserial-AB6WZCQX
embedded/bus-tester/bus-stepper`; back to listening with the saved bus-monitor image (`readback/`).

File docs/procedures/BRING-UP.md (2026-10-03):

# YACC1 bench procedures: power, reset, clock, microcode, ROM, test programs, bus tester

The procedure book for the machine on the bench: how to bring it up, how to load what it needs, how to prove each
piece with the programs and scripts in the tree, and what to look at when a step fails.

Written 2026-09-23 from the YACC1-D tree.

Sources (every section says which one it draws on): `docs/system/MACHINE.md` (what is in the machine and what is
loaded), `hardware/FABRICATED.md`, `tools/ucode_send.py` (docstring), `embedded/sequencer-card/README.md` and
`sequencer4/Sequencer4.ino`, `firmware/rom/README.md`, `firmware/abi/README.md`, `firmware/rom/eprom-captured-2026-09-18.bin`
and `firmware/rom/shipped/rom.bin` (compared byte for byte for this document), `tests/assembler/{ledcount,romcount,romdiag,brur}/README.md`,
`docs/procedures/BUS Driver Commands - Google Docs.pdf` (the script language; read with pypdf), `tests/bus-tester-scripts/README.md`,
`tools/busdrv.py`, `embedded/bus-tester/README.md` and `bus-driver/bus-driver.ino`, `tests/memory/*.py` and their logs,
`tests/video/README.md`, `tests/sequencer/*.log`, `hardware/DESIGN-REVIEW-NOTES-datapath.md`, `hardware/DESIGN-REVIEW-NOTES-control-io.md`,
`docs/isa/MICROCODE-REVIEW-NOTES.md` (section 7), the card READMEs and `Build Notes.md` under `hardware/cards/`, `docs/procedures/System Build Notes.md`,
`docs/system/connector/README.md`, and the generated `docs/bom/*.md` (for the names of switches, jumpers and LEDs on each card).
Anything the tree does not settle is marked **To verify:** with what would settle it.

The companion document `TESTING.md` lists every test in the tree; this one is about the bench.

---

## 1. What is on the bench

The machine is a set of cards on a 96-pin DIN 41612 backplane (Bus Template V3.2 signal names, `docs/system/connector/README.md`).
From `docs/system/MACHINE.md` (2026-09-20, updated through 2026-09-23):

| Slot use | Card | Revision | Why it is there |
|---|---|---|---|
| bus | Backplane | V2.0 | 8 slots X1..X8, bulk electrolytics C7/C8, 5 V and GND wire pads, PWR LED (`docs/bom/backplane.md`) |
| CPU | Sequencer logic | v2.1 ("V2.1l", 218 mm) | instruction register, step counter, the pipeline latches that drive every control line, front panel |
| CPU | Sequencer memory | V2.1 + EEPROM adaptor in IC9 | the control store: 64 steps x 8 bytes per opcode in eight 62256 RAMs, loaded from the I2C EEPROMs by an ATmega328P |
| CPU | ALU | V3.2 | accumulator, TMP path, adders, shifter, the branch-condition mux |
| CPU | Index registers x2 | 1.1 | card 0 = R0..R3, card 1 = R4..R7 (J3 selects the card); R0 is the PC, R1 the stack pointer (`firmware/abi/README.md`) |
| I/O | I/O | V1.1 | 16C550 UART behind P0/P1 at 38400, switch/LED port, two TIL311 displays, LCD header |
| memory | Memory | v1.3 | 2 x 62256 (64K RAM), one 28C64 (8K EEPROM at $E000), FORCE-ROM boot remap, the TMP0/TMP1 registers |
| video | Video | V1.0 (Fusion export) | installed for bring-up, **6845 socket empty**, +5V and VCC joined by a wire (2026-09-21) |
| bench | Bus Test Card | v1.1 | ATmega328P + MCP23017 expanders; drives or watches every bus line from a serial console (FTDI, 19200) |
| bench | Mem Switch | V1.1 | 16-byte switch-programmed ROM at $0000 (sixteen 8-way DIP switches named `0000`..`1111`), for CPU bring-up without the memory card |
| bench | Mem Register | V1.0 | 16-byte RAM at $0010 with read/write LEDs, the same purpose |

Not fitted and not needed: the two bus jumper boards (obsolete), Address+TMP (retired 2021), Bus Tester V3.1 (never ordered).

The order in which the cards were originally built and brought up is in `docs/procedures/System Build Notes.md`:
bus tester, backplane, memory, (prototype), index register 1, ALU, index register 2, sequencer memory, sequencer logic.
That is also a sensible order for a rebuild, because each step can be proved with the bus tester before the next card
depends on it (sections 6 and 7).

### 1.1 Board check before a card ever goes on the bus

From the card `Build Notes.md` files (memory, bus tester; the text is the same on both):

1. GND is the 3 far-right and 3 far-left pins of the 96-pin connector, VCC the 3 pins next to GND on each side. Check they
   are connected on the card.
2. VCC must not be shorted to GND. Check with a meter on any bypass capacitor (every cap has a GND side and a VCC side), so
   the check also proves the rails reach the card.
3. Plug the card in, power the bus: the card's PWR LED must light (every card has one, `docs/bom/<card>.md`).
4. With the Bus Test Card fitted, run its `bus-test` sketch (`embedded/bus-tester/bus-test`) to look for shorts between
   bus lines before any ICs are installed.

---

## 2. Power

- The backplane takes 5 V on its `5V` / `GND` wire pads (`docs/bom/backplane.md`: two WIREPAD parts, package 4,16O1,6) and
  has a PWR LED and two bulk electrolytics (C7/C8, added in V2.0 per `hardware/FABRICATED.md`). Every card is TTL/LS on the
  one 5 V rail.
- **To verify:** the bench supply's rating and connector. The tree records no current figure for the full card set; measure
  it once at the supply and note it in `docs/system/MACHINE.md`.
- The bus tester and the sequencer-memory card can also be powered from their FTDI cable through the `FTDI-VCC` solder
  jumper (`docs/bom/bus-tester.md`, `docs/bom/sequencer-memory.md`). The bus-tester build notes say: jumper FTDI-VCC only when
  the card is being run **off** the bus; remove it when the card is on a powered bus. `hardware/DESIGN-REVIEW-NOTES-control-io.md`
  2.2 says why: closed on the bus it parallels the FTDI's 5 V with the backplane rail.
- The video card as designed had its `+5V` net fed by nothing (`hardware/cards/video/README.md`); `+5V` was joined to `VCC`
  with a wire on 2026-09-21. Do not remove that wire: IC1, IC2, RN2 and every decoupling capacitor on the card hang off it.

### 2.1 What happens at power-up (why the machine is not usable for the first minute)

1. The sequencer-memory ATmega boots (`embedded/sequencer-card/sequencer4/Sequencer4.ino`). With the `UCODE` switch in run
   mode it copies the microcode from the I2C EEPROMs into the eight 62256 RAMs (16 s), reads the whole copy back and compares
   it with the EEPROM (29 s), and only then raises READY - 54 s after reset (`tests/sequencer/boot-run-mode-2026-09-21-sequencer4.log`).
   LOADING is on while copying; READY comes on when done; on a mismatch FAULT blinks six times and READY never comes.
2. READY drives the bus signal `-BUS-EN` through the logic card (`DESIGN-REVIEW-NOTES-control-io.md` 1.8). Until then every
   control line on rows B and C of the bus is a tri-stated 74LS374 output with no pull-up anywhere (`DESIGN-REVIEW-NOTES-datapath.md`
   M5, S3): the lines float at ~1.5-1.9 V. LS inputs read that as high (inactive), so nothing is selected, but the levels are
   undefined. This is the window in which the memory card's `-WE` follows an undefined `-MEM-WR` (M2, M5).
3. **The bus must be quiet during the copy.** The clobbered transcript `tests/sequencer/boot-run-mode-2026-09-21.log` is what
   you get when the bus tester holds `-BUS-EN` asserted while the ATmega writes the RAMs: the logic card drives the address
   lines, every write lands on address 0 and every dumped instruction reads as zeros. With the tester idle
   (`bus-monitor` sketch, or `bus-driver` with nothing asserted) the same boot gives RAM == EEPROM (`...-bus-quiet.log`).
4. There is **no power-on reset** (`DESIGN-REVIEW-NOTES-datapath.md` S1): `-RESET` comes from a manual RS latch on the logic
   card (RESET = NOR(FP-RESET, RUN)). After a cold start the memory card's FORCE-ROM flip-flop, the sixteen 74LS192 register
   counters and the ALU's carry/shift flip-flops are in arbitrary states until the front-panel RESET is operated. So the first
   thing after READY is always a reset (section 3).

---

## 3. Reset and run: the front panel

The sequencer-logic card carries the front panel (`docs/bom/sequencer-logic.md`): three toggle switches `RESET`, `SS/WAIT`
and `STEP-CLK` (9070-1W), two push buttons `HALT` and `CONT`, an `OUT` LED (the ON/OFF flag the `ON`/`OFF` instructions set,
`firmware/abi`), jumpers `JP1`..`JP4`, `SS-SEL` and `-INT-PULLUP`, and the oscillator socket `QG1`.

### 3.1 Reset

- `RESET` toggle: in the RESET position the latch holds `RESET` high and `-RESET` (bus pin C30) low; moving it to the run
  position (called EXECUTE in the design review) releases it. Only the **release** edge reloads the pipeline (a ~30-45 ns pulse
  `N$32`, `DESIGN-REVIEW-NOTES-control-io.md` 1.3): while the switch sits in RESET the pipeline latches keep driving whatever
  step was executing, or power-up garbage, onto the bus.
- What reset does around the machine (`DESIGN-REVIEW-NOTES-datapath.md` S2, `software/ucemu/README.md` "Reset"): the
  instruction register clears, all sixteen register counters clear (so PC = R0 = $0000), the ALU carry/shift flip-flops
  clear, and the memory card's FORCE-ROM flip-flop is preset, so the 28C64 answers **every** address until the first `-VMA`
  cycle with ADDR15 high. That is why the first fetch at $0000 gets the byte at ROM offset $1000 = $F000, and why every
  ROM image in the tree starts with a `BR` to an address above $8000 (`tests/assembler/romcount/README.md`: `F000 A0 F0 03 BR begin`).
- From the bus tester: `-RESET:1#` then `-RESET:0#` (asserts then releases; the firmware inverts active-low names,
  `tools/busdrv.py`). `busdrv.py --reset` does the same pulse. The tester also has push buttons `BUS-RESET` and `CPU-RESET`
  (`docs/bom/bus-tester.md`). **To verify:** which of the two drives bus `-RESET` and which resets the tester's own ATmega;
  the schematic `hardware/cards/bus-tester/eagle/v1.1/tester.sch` answers it.
- The sequencer-memory card has its own `LOCAL-CPU-RESET` push button that resets **its ATmega** (and through JP1 pin 2 /
  `-MEM-CPU-RESET` can be tied to the logic card, `DESIGN-REVIEW-NOTES-control-io.md` 1.4). Pressing it restarts the 54 s
  copy. It is what "reset the card" means in the microcode-loading procedure (section 4).

Known hazard while reset is held (control-io 1.3): a stale pipeline word with `-MEM-WR` and `-VMA` asserted writes the
28C64 during reset, because the memory card's EEPROM `-WE` is `-MEM-WR` unqualified (`DESIGN-REVIEW-NOTES-datapath.md` M2).
It has not been seen to happen (the chip read back byte-identical to the 2021 sources on 2026-09-18), but do not leave the
machine sitting in RESET, and re-check the ROM (`tests/memory/rom_verify.py`) after a batch of power cycles.

### 3.2 Clock

- The logic card's `QG1` is a 14-pin oscillator socket (BOM: deviceset `XO-`, package DIL14S). During bring-up the machine has
  been clocked from a **function generator's TTL output plugged into that socket: pin 8 = clock, pin 7 = GND**
  (`docs/system/MACHINE.md`, 2026-09-21). At a few hertz every step is visible on the LEDs (`tests/assembler/ledcount/README.md`).
- One microcode step is two clock periods (the step counter's QA is a phase bit, `DESIGN-REVIEW-NOTES-control-io.md` 1.2;
  `software/ucemu/README.md`). `tests/assembler/romcount/README.md` gives the scale: ~590,000 clocks per LED count with the
  $2000 delay, about 0.6 s per count at 1 MHz.
- Single-stepping: `STEP-CLK` and `SS/WAIT` toggles and the `SS-SEL` jumper select the step-clock source - the front-panel
  latch (IC29) or an external clock on `JP4` pin 2 (control-io "Checked, no issue": "Step-clock source jumper SS-SEL ...;
  JP4 exposes UCODE-COUNT-RESET"). `embedded/clocker/clocker.ino` is an Arduino for that external input: pin 13 outputs the
  clock, pin 12 reads `UCODE_CLOCK`, and three buttons give one pulse, one instruction (pulse until the `UCODE_CLOCK`
  input goes high, then one more) or ten instructions. **To verify:** which JP4 pin the clocker's pin 12 goes to (the
  sketch calls it UCODE_CLOCK; the review calls the exposed signal UCODE-COUNT-RESET) and the exact switch positions for
  external stepping - read `hardware/cards/sequencer-logic/eagle/v2.1/Sequencer-Logic-Prod-V2.1l.sch` sheet with IC29/JP4.
- **To verify:** the maximum clock. Nothing in the tree gives it; `docs/isa/MICROCODE-REVIEW-NOTES.md` section 7 item 6 is
  the experiment: raise the generator until `BR` mis-targets or `INP` reads $FF and note the frequency.
- `HALT` / `CONT` buttons: HALT sets a flip-flop at the next UCODE-COUNT-RESET (instruction boundary), CONT or RESET clears
  it (control-io "Checked, no issue"). The `HALT` **instruction** ($03) stops the machine the same way (SOFT-HALT).

### 3.3 Jumpers that must be right (per card)

The names are from `docs/bom/<card>.md`; the meaning from the READMEs and the design review.

| Card | Header | Setting in the machine | Source |
|---|---|---|---|
| Memory v1.3 | `U$1` 3x8 block header | one column per 4K block $8000..$FFFF: jumper **up** = RAM, **down** = ROM, **none** = undecoded. Fitted: $8000-$CFFF up (5), $D000 none (video), $E000-$FFFF down (2) | `docs/system/MACHINE.md`, `hardware/cards/memory/README.md` |
| Memory v1.3 | `JP1` 1x3 | must be fitted: it feeds IC7's G2B (the block decoder) | `DESIGN-REVIEW-NOTES-datapath.md` M7 |
| Memory v1.3 | wire from IC7 pin 4 | present, unconnected, purpose not remembered | `MACHINE.md`, BACKLOG |
| Index registers 1.1 | `J1` (RD), `J2` (LD), `J3` (ADDR), each 2x4 | all three on one card set to the **same** ID2-3 code: card 0 = R0-R3, card 1 = R4-R7 | `hardware/cards/register/README.md`; datapath "Checked, no issue" |
| ALU V3.2 | `JP1` 1x3 | the branch-condition mux enable: pin 1 = `-ALU-FUNC`, pin 3 = GND. On GND the mux always drives BR-COND (C24); on `-ALU-FUNC` it floats whenever `-ALU-FUNC` is high | `DESIGN-REVIEW-NOTES-datapath.md` A1. **To verify:** which position is fitted (meter on C24 with `-ALU-FUNC` high) |
| ALU V3.2 | `JP2` 1x3 | **To verify:** not described in the review notes; read the schematic | |
| Sequencer logic v2.1 | `JP2` 1x2 | **must stay OPEN**: it would tie the pipeline's SPARE3 bit (always 0) to the sequencer-memory ATmega's reset and hold the loader in reset for ever | control-io 1.4 |
| Sequencer logic v2.1 | `JP3` 1x5 + `-INT-PULLUP` 1x2 | interrupt mode: `-INT` (C13) to pin 2 = edge or pin 4 = level, and the **other** input jumpered to its GND neighbour, else PRE or the clock floats | control-io 1.6 |
| Sequencer logic v2.1 | `JP1` 2x2 | SPARE3 / -MEM-CPU-RESET / SRC-ADDR / DEST-ADDR, 1:1 with the memory card's JP1 over the ribbon | control-io "Checked" |
| Sequencer logic v2.1 | `SS-SEL` 1x3, `JP4` 1x4 | step-clock source / external step clock and UCODE-COUNT-RESET (section 3.2) | control-io "Checked" |
| Sequencer memory V2.1 | `DTR-RESET` solder jumper | dead-ends (pin 2 reaches nothing): flashing the ATmega needs the local reset button | control-io 2.2 |
| Sequencer memory V2.1 | `FTDI-VCC` | open while the card is on the bus (section 2) | control-io 2.2 |
| Sequencer memory V2.1 | `JP2` 1x3, `CADDR14` 1x2 | **To verify:** not covered by the review; `CADDR14` is presumably the 15th control-store address bit for the doubled EEPROM (the adaptor) - read the schematic | |
| Video V1.0 | `SV3` 2x4 | board address compared by the 7485: installed = 0, open = 1; $D000 needs only SV3 5-6 | `hardware/cards/video/README.md` |
| Video V1.0 | `SV4` 1x3 | dot-clock source | control-io 6.3 |
| I/O V1.1 | `IO-ADDR-HL` 2x3, `IO-ADDR` 2x8, `DATA-ADDR` 2x8 | pick which two of the sixteen port addresses are the control latch and the data port; the ROM expects **P0 = control, P1 = data** | `firmware/abi/README.md`; control-io 3.3 |
| Bus tester v1.1 | `DTR-RESET`, `FTDI-VCC` | build notes: jumper DTR-RESET so opening the port resets the ATmega; FTDI-VCC only off-bus. The review (2.2) finds DTR-RESET's second pad unconnected on this board too - yet `busdrv.py` waits for the "DTR reset -> LED flash" on open. **To verify:** whether the flash is the DTR path or the bootloader's own start-up; meter on the ATmega reset pin when the port opens | build notes; control-io 2.2; `tools/busdrv.py` |

---

## 4. Loading the microcode into the sequencer card

What is being loaded: `firmware/microcode/ucode-generator2/test.hex`, 256 records (one per opcode) of 512 bytes = 64 steps x
8 bytes, regenerated by `make -C firmware/microcode/ucode-generator2 regen` and checked by `make check` (`firmware/microcode/README.md`).
The card keeps it in two 24Cxx I2C EEPROMs on the adaptor in IC9 (addresses $56/$57, `sequencer4/uCodeROM.ino`) and copies it to
RAM at every boot (section 2.1). `firmware/microcode/ucode-generator2/cache` is the sender's record of what the card holds.

The 2026-09-22 image is what is in the card now (`MACHINE.md`: loaded with `--all` that evening; `cache` == `test.hex`).
The procedure, from `tools/ucode_send.py`'s docstring and `embedded/sequencer-card/README.md`:

1. Build the image and make sure it is what you want to load: `make -C firmware/microcode/ucode-generator2 check` must say
   `test.hex: IDENTICAL to the committed microcode image`. `python3 tools/ucode_send.py --dry-run` lists which records differ
   from `cache` (only those go, unless `--all`).
2. On the card: `UCODE` switch to **DOWNLOAD**, then reset the card (`LOCAL-CPU-RESET`): the LOADING LED comes on.
3. **Run the sender first**, then press `START`:
   ```
   python3 tools/ucode_send.py                # finds the single /dev/cu.usbserial* or usbmodem*; --port to choose
   python3 tools/ucode_send.py --all          # every record regardless of the cache (what the 2026-09-22 reload used)
   ```
   The order matters because opening the FTDI port resets the ATmega (DTR). The sender says it is waiting; press `START`;
   the card answers with a `>>` prompt before every instruction.
4. Per record the card flashes a LED for 100 ms after its prompt before it reads, and its serial buffer is 64 bytes, so the
   sender waits 250 ms after every prompt (`--settle`); without that the head of the record is lost and the card waits for
   ever (seen 2026-09-22). The record's trailing `-` in `test.hex` is **not** sent (the card reads exactly 512 byte values;
   a stray character is an "Unexpected Char" fault, FAULT LED blinking 5). The cache is rewritten record by record, so an
   interrupted load resumes by running the command again.
5. Afterwards: `UCODE` back to **run**, reset the card. Sequencer4 copies EEPROM to RAM (16 s), verifies (29 s), READY at ~54 s.
6. Prove it: `python3 tools/ucode_send.py --boot-check [--log FILE]` captures the run-mode boot transcript over the same port
   and compares the five instructions the firmware dumps (0, 1, 7, 124, 255) with `test.hex`. The clean transcript looks like
   `tests/sequencer/boot-run-mode-2026-09-22-reload.log`: the banner `Sequencer4 2026-09-21 (...)`, `Copying Instruction 0 ... 224`,
   `- done, 16 s`, `Verify RAM against EEPROM`, `- 29 s, RAM == EEPROM for all 256 instructions`, the dumps, then
   `RAM copy complete and verified, READY!!!` and a `RAW=... Ins=00 Line=.. Data=...` line showing the first control word
   on the ribbon.

What the older Processing sender did the same way: `embedded/sequencer-card/microcode-loader/simple_microcode_sender_64`
(115200, reads `test.hexz`, keeps the same `cache`); its 25 ms/char pace met the two timing needs by accident.

Firmware in the card: `embedded/sequencer-card/sequencer4` (flashed 2026-09-21 by arduino-cli as an Uno through the FTDI at
115200, per `MACHINE.md`; the DTR auto-reset dead-ends, so use the local reset button for the bootloader window - control-io 2.2).

Bench checks that the reloaded image still owes (BACKLOG, `MACHINE.md` item 6): `tests/assembler/brur/` (`ABC0123` on the
console) and `tests/ucemu/isa.asm` (the port-2 byte stream, on the machine through the UART). The first real evidence of the
2026-09-22 image working is `romcount` counting overnight into 2026-09-23 (section 6).

---
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

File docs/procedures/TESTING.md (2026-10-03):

# YACC1 test inventory: every test in the tree, what it proves, how to run it

The complete list of tests under `tests/`, the root `make check`, the verification tools under `tools/`, and the emulator
modes they rely on. For each: what it proves, how to run it, what a pass looks like, and whether it needs hardware.

Written 2026-09-23 from the YACC1-D tree.

Sources: `Makefile` (root), `tests/README.md` and the READMEs under `tests/*/`, the docstrings of every `run.py` and of
`tools/verify_firmware.py`, `verify_embedded.py`, `verify_processing.py`, `audit_tree.py`, `gen_bom.py`; `software/emulator/README.md`,
`software/ucemu/README.md`, `os/README.md` and `os/Makefile`; `software/assembler/Makefile` and `firmware/microcode/ucode-generator2/Makefile`
(the two `check` targets); `tests/memory/*.log`, `tests/sequencer/*.log`, `tests/video/README.md`. The "pass looks like" columns
are from a run of every software-only test on this tree on 2026-09-23 (all passed). The bench procedures behind the hardware
tests are in `BRING-UP.md`.

**Needs hardware?** column: **no** = runs on the Mac alone; **tester** = the machine on the bench with the Bus Test Card on its
FTDI port; **card** = the sequencer-memory card's FTDI port; **burn** = a 28C64 to program and the machine to run it.

---

## 1. `make check` - the tree's own proof, in order

`make check` at the root runs, in this order (root `Makefile`):

| Step | Command | What it enforces |
|---|---|---|
| 1 | `python3 tools/audit_tree.py` | every file in the tree is explained (section 4) |
| 2 | `python3 tools/verify_firmware.py` | the ROM and microcode images reproduce from source (section 4) |
| 3 | `python3 tools/verify_embedded.py` | every Arduino sketch compiles with zero warnings (needs arduino-cli) |
| 4 | `python3 tools/verify_processing.py` | the Processing command sender builds with zero warnings (needs Processing 4) |
| 5 | `make -C software/assembler check` | monitor.img / basic.img / shipped rom re-assemble identical |
| 6 | `make -C firmware/microcode/ucode-generator2 check` | test.hex regenerates identical |
| 7 | `python3 tests/compiler/run.py` | 15 C programs on the instruction-level emulator |
| 8 | `python3 tests/ucemu/run.py` | 13 of them + brur on the microcode-level emulator |
| 9 | `python3 tests/os/run.py` | the Y1/OS session on both emulators |
| 10 | `python3 tests/sequencer/run.py` | the microcode sender against a mock card |
| 11 | `python3 tests/assembler/romcount/run.py` | the ROM counter on the microcode emulator |
| 12 | `python3 tests/assembler/romdiag/run.py` | the ROM diagnostic on the microcode emulator |
| 13 | `python3 tests/monload/run.py` | the monitor's `:` loader on both emulators (error paths too) and `tools/monload.py` over a pty (2026-09-23) |
| 14 | `python3 tests/bench/run.py` | the 15 bench programs on both emulators against their expected transcripts, the committed images, and the `--port` path over a pty (2026-09-23) |
| - | `python3 tests/disasm/run.py` | `/BIN/DISASM` round trip (2026-09-29): its output reassembled by RC/asm gives the same bytes, over tests/asm's corpus, the OS build's programs, the ROM and synthetic bytes (section 3.10) |
| 15 | `python3 tests/kermit/run.py` | `/BIN/KERMIT` against `tools/y1kermit.py` over a pty on both emulators: files both ways, options, damaged/missing packets and timeouts, the server; then `--calib`, the receive loop's and the timeouts' clocks on the microcode emulator (2026-09-26) |

Shortcuts: `make cc-test` = steps 7+8, `make os-test` = step 9. `make` (all) first builds the C tools the tests need:
`software/emulator`, `software/ucemu`, `software/assembler`, `firmware/microcode/ucode-generator2`, `software/disassembler/disasm2`,
`software/ubasic-c/ubasic-master`, the bus-tester vector generator - after `tools/layout_links.py` has laid the include symlinks.
Steps 3 and 4 are the only ones that need tools outside the tree (arduino-cli, Processing 4); everything else is Python 3 and cc.

Generated documentation has its own checks that are **not** in `make check`: `python3 tools/gen_bom.py --check` (`docs/bom/`,
section 4) and `make isa` (`docs/isa/`, regenerate rather than check).

---

## 2. The emulators and their scripted modes

Two emulators, deliberately different (`software/ucemu/README.md`):

- **`software/emulator/emulator`** - the instruction-level reference model (`main.c`): knows what every opcode does, 64K, 16
  ports, console on port 2. Quick and forgiving. Options used by the tests: `-x` scripted mode (no load/dump chatter, no raw
  tty, stdout flushed, `HALT` exits with `HALT at aaaa after N instructions, R3=xxxx` on stderr), `-f FILE` load an Intel-hex
  image (the assembler's `.img`), `-m` load the monitor+BASIC ROM (`firmware/basic/basic.img` + `firmware/monitor/monitor.img`,
  found relative to the executable), `-c disk.img` a CompactFlash image on ports P8/P9 (`MACHINE.md`). Since 2026-09-22 `BRVR`
  and `JSRUR` do what the microcode does, so the monitor's `G` and `T` work on it. It also stops itself at an instruction limit
  (`tests/os/basic.int.out` ends with `instruction limit reached at f530 after 6000000 instructions`).
- **`software/ucemu/y1ucemu`** - the microcode-level model: does not know what any instruction does; it steps the control words
  of `firmware/microcode/ucode-generator2/test.hex` (256 x 64 x 64 bits) through a model of the cards (sequencer, register cards,
  ALU, memory with FORCE-ROM, I/O with the 16550 model), and counts **bus fights** (two drivers disagreeing on a data lane, per
  opcode and step). This is what turned the microcode review's findings into runnable tests. Options: `-x` scripted, `-m`
  monitor ROM, `-f FILE`, `-u test.hex` another control store, `-F and|src` how a fight resolves (AND = the usual TTL outcome;
  src = the ALU's `-AC-RD` loses), `-s NN` the switch byte, `-l N` stop after N steps, `-t` one line per instruction fetch,
  `-T` every step with signals, `-w` list every fight as it first occurs, `-i 0|1` the input-switch line level (`BRINH/BRINL`),
  `-I N` flip that line every N steps, `-L` report LED-board / TIL311 / ON-OFF writes on stderr, `-R 1|2` the number of
  index-register cards fitted (with 1, R4..R7 read $FF and lose loads and counts), `-c disk.img`. Its status line gives
  instructions, steps, clocks (a step is two clock periods), R3 and the fight count - e.g. `HALT at 3046 after 90 instructions,
  1187 steps, 2285 clocks, R3=0000; bus fights: 0 in 0 (opcode,step) pairs; weak pull-up drives: 162`.

Under the microcode `BRDEV` always branches, so a program's console goes through the monitor's `charout`/`uartin` and the UART
model - the path the real machine takes - and the monitor's `uartin` **echoes** every character it reads. That is why some
tests have a second expectation file (`.ucout`, `.uc.out`) for the microcode emulator.

Every test image is loaded at $3000 (the C compiler's default; BASIC's token buffer is $1000-$1FFF) and starts with a branch to
an address above $8000 (`--boot` stub) so that the FORCE-ROM remap is released exactly as on the hardware.

---

## 3. The tests under `tests/`
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

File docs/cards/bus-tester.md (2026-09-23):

# Bus Test Card v1.1 (and the unbuilt v3.1) — theory of operation

An ATmega328 and six MCP23017 I2C port expanders that can drive or read every line of the backplane from a serial
console, so that each card can be exercised without a CPU. It is the instrument behind every 2026-09 memory, ROM
and video test.

Written 2026-09-23 from the YACC1-D tree.

Sources: `hardware/cards/bus-tester/eagle/v1.1/tester.sch` and `.brd` (the board in use; parts and nets parsed from
the Eagle XML), `hardware/cards/bus-tester/eagle/v3.1/tester.sch` (the 2020 redesign, never ordered),
`hardware/cards/bus-tester/README.md`, `eagle/v1.1/Notes.md`, `eagle/v1.1/Build Notes.md`, `eagle/v3.1/Notes.md`,
`embedded/bus-tester/README.md`, `embedded/bus-tester/bus-driver/bus-driver.ino`,
`embedded/libraries/YACC/YACC_Common_header.h` (the signal table), `tools/busdrv.py`, `tools/alias_min.py`,
`docs/procedures/BUS Driver Commands - Google Docs.pdf`, `tests/bus-tester-scripts/README.md` and the scripts,
`tests/memory/memory_full_test.py`, `rom_verify.py`, `memory_status.py`, `tests/video/*.py`,
`hardware/DESIGN-REVIEW-NOTES-control-io.md` (sections 1.1, 4, 5.1, cross-card), `docs/system/MACHINE.md`,
`hardware/FABRICATED.md`, `BACKLOG.md`.

## 1. Purpose and place in the machine

The tester plugs into any backplane slot and pretends to be the rest of the machine. Six MCP23017 expanders give
96 GPIO lines; 32 of them are the address and data buses, 52 are the control signals of the Bus V3.2 pinout, and
the remaining 12 serve an on-card switch/LED byte. The ATmega runs the `bus-driver` sketch: it reads one command
at a time from an FTDI serial cable (`CMD:OPERAND#`, 19200 baud, no line ending), sets or reads the named line
through the expander, and answers with an optional `Data: n` line and a `>>` prompt. A host script (`tools/busdrv.py`
on the Mac; formerly the Processing `command_sender_8`) strings commands into memory reads, writes, dumps and tests.

It is a *static* instrument: it sets levels and leaves them; there is no clock, no timing. That is enough to prove
decoding, storage and data paths (the memory card's block map, the ROM contents, the video RAM, the I/O card's UART
registers in 2020), and it is why some hazards that depend on edges (the memory card's M1 race) pass the tester and
would not pass the CPU.
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

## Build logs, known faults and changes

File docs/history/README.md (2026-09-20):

# docs/history — kept verbatim

- `readme-2021.md`, `status-2021.md` — the front page and status of the old `YACC1-2020` git repo (2021-03/07).
- `pcb-readme-2021.md` — how the old `PCB/Production` vs `Working` folders were meant (replaced by the per-card layout here).
- `NOTES Jan 2:17 orig.rtf` — January 2017 build notes (gen-1 → 2020 transition ideas).
- `general-notes/` — 2020 design notes (`NOTES-Update from old project.rtf`, `dev notes.rtf`).
- The 142 MB `yacc1.pptx` presentation (and the 90 MB PDF of it in the gen-1 backup) are NOT in the tree: see
  `migration/large-files-manifest.tsv` for their location and checksums.

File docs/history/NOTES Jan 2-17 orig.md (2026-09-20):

*Converted from `NOTES Jan 2-17 orig.rtf` (saved 2020-08-23) by `tools/rtf_to_md.py`; the .rtf is the original.*

BUILD NOTES:

BUS
Add method to chain card together at edge using right angle male/female 96 pin DIN connectors
Once old boards on old bus have been updates mount newer bus card on plywood
    Add Power supply to plywood
    Add on/off switch to above
    Maybe add amp meter???
    Use distribution bus for power (screw terminals)

ALU
IC8A  CARRY SHIFT Register, should it have a reset capability ?
    connect CLR pin 1 to -RESET?
    What about a software reset ability? 
        Should This be done on add/sub without carry

Any Other Status bits required? 
    Look at other CPU designs

IC34 Compare register
    Remove test for 0 from HI data byte (8-15) and replace with INPUT line from bus
    This will allow INPUT signal status line to be same as every other test

SWAP  A and B lines into IC43 and IC44
    First retest this logic with test card and test vectors

Incorporate existing PCB Mods

SEQUENCER LOGIC
IC14 Reuse U-TEST-IN
is soft reset needed or reuse?
sheet 4, cleanup logic now that testin input is gone, use br-cond only
Maybe move HALT and CONTINUE switches to TOP edge

Rename branch register to data immediate and add another 2 x 74374 for add(r?) immediate
clk into new  74374s same as ic26 and 27
output new 74374s to addr lines
Does existing 74374s need separate hi and lo read lines ???
    Can one be use for existing 74374s (DATA) and other for new 74374s (ADDR)
Possible methods for I/O ADDR line
1) Reuse testin line and drive either UNUSED1 or UNUSED2 on bus
2) Is there a way to generate a pulse on UNUSED1 or 2 delayed after 74274 ADDR outputs enabled?

review front panel, new circuit, jumpers? make it easier to add single step clock

fix naming , rename -halt-cont to -fp-halt-cont

SEQUENCER MEMORY
Fixes re PCB Mods
Move CPU reset to top edge of board

SP/PC
Now called ??? ADDR/INDEX/GP
DONE:
USES 7400 NAND (NOT AND) for gating UP/DN signals for counters
UP/DOWN count on rising edge but other line must be high
Example to count up, DOWN line held high, pulse UP by setting/clearing SP/PC-UP - this will appear as low then high at counter pin
DONE:
Front Panel wiring CAREFUL CHECK numbering scheme for RxDx lines from counter chips

DONE:
update sheet 5 to match logic test
DONE:
Arrange so board select can either be driven from unused 1 to become 3rd addr-reg signal or gnd
MAYBE use unused line to add another address line for a 2nd card???

REGISTER BOARD
Now callee DATA REGISTER CARD
incorporate mods to board and verify changes to production design in ‘mods’ DIRECTORY

TBD RESEARCH
Interrupt Line: Should this be open collector with pull down and or up
Input Line: Should this be open collector with pull down and/or up

Should tmp register be on sequencer card or not exist at all
    This would free up two bus lines although the bottleneck is still the number of control signals in sequencer connector

MEMORY CARD - BASIC
How to get info into card ?? Using Front Panel ??

MEMORY CARD - FULL
How many ram chips
    Best case 1 x 64k x 8
    Worst case 8 x 8k x 8

1 4k eprom
eprom mapping circuit
    On reset EPROM is mapped into 0x0000
    all memory access goes to EPROM
    first access to location with addr 15 set (HIGH) 
        remaps EPROM to 0xFxxx 
        RAM is mapped to 0x0000
    Accomplished by first EPROM code BRANCH to 0XF003 (BRANCH instruction is 3 bytes)

I/O CARD

Design Changes (from old file) Incorporate into above info
1) Remove address latch register from register file
    recover bus pins & men cantle pins
    update 1.2 bus definition
        on definition
        cards in progress or prod

2) add temp 8 bit latch to sequencer card to facilitate men to men transfer

3) convert reg card to 8 registers
    modify bus definition to 3 bits register select, 1 bit board select
    modify bus definition + all cords in process

4) Reduce to 8 registers only, jumper to hold the now 1 bit board select to 0
maybe add jumpers so reg selection is 3 bit, tie upper bit to 0

5) TESTER Board
probably (almost for sure) do not need individual pull-ups for CNTL chips

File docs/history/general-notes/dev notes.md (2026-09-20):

*Converted from `dev notes.rtf` (saved 2025-03-06) by `tools/rtf_to_md.py`; the .rtf is the original.*

Verify opcode using putBusAtMemReg 
    removed clear -vma

Add halt indicator led to sequencer board
Expose code-counter-reset either on bus or as a pin to support external clock control

Memory

Add leds for each of 3 chips CS

Add keyhole optimizer looking for duplicate lines in micro code

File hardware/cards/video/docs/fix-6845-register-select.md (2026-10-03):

# Video card V1.0 — bench fix for the unreachable 6845 data register

Written 2026-09-21 from the board netlist (`kicad/.../reports/netlist.net`, proven against the Eagle board).

## What is wrong

The 6845 (IC17, DIP-40) has -CS on pin 25 and RS on pin 24. RS = 0 addresses the CRTC's address register,
RS = 1 its data register. On the card:

| Signal | Comes from | Logic |
|---|---|---|
| IC17 pin 24 RS | ADDR0 (bus A0) directly | RS = A0 |
| IC17 pin 25 -CS | IC19 (74LS00) pin 3 = NAND(pin 1, pin 2) | -CS = NOT(BOARDSEL · N$2) |
| IC19 pin 2 (N$2) | IC1 (74ALS08) pin 11 = AND(pin 12, pin 13) | N$2 = A11 · /A0 |
| IC1 pin 13 (N$5) | IC27 (7416) pin 8, input pin 9 = ADDR0 | /A0 (open collector, no pull-up) |

So the CRTC is selected only while A0 = 0, and A0 = 0 is always RS = 0. Only the address register can ever be
accessed; the data register never.

The odd addresses are not free either: IC2 (74LS373) is a read-back latch whose eight D inputs come from JP1
(pins 1, 2, 4, 6, 8, 10, 12, 14; latch enable from JP1 pin 13) and whose outputs sit on DATA0–7. Its -OE (pin 1)
is IC27 pin 10 = NOT(IC1 pin 8), and IC1 pin 8 = AND(IC1 pin 9, ADDR0) with IC1 pin 9 = IC1 pin 6 = AND(BOARDSEL,
A11). So **odd addresses in the high half of the block drive the latch onto the bus**. Simply removing /A0 from the
CRTC select (tying IC1 pin 13 high) would put the CRTC data register and the latch on the bus together at every odd
address: a bus fight. Don't do that.

## The fix: move RS from A0 to A1

Keep the decode as it is (CRTC at even addresses, latch at odd ones) and let A1 pick the CRTC register:

| Address (repeats every 4 bytes through $DFFF) | A1 | A0 | What answers |
|---|---|---|---|
| $D800 | 0 | 0 | 6845 address register |
| $D801 | 0 | 1 | JP1 read-back latch (IC2) |
| $D802 | 1 | 0 | 6845 data register |
| $D803 | 1 | 1 | JP1 read-back latch (IC2) |

(Confirmed 2026-09-25: video RAM is $D000-$D7FF, the 6845 half is $D800-$DFFF. This document said $D400 until then.)

One connection changes: **IC17 pin 24 leaves ADDR0 and goes to ADDR1**. ADDR1 is on exactly two pins of the
board: bus connector X1 pin A4 and the dual-port RAM IC15 pin 41. Nothing else on the card uses A1, and nothing
else is on the IC17 pin 24 pad except the ADDR0 track, so no other pin is disturbed.

### Steps (chip in a socket, no board cutting)

1. Card out of the bus, power off.
2. Take the 6845 you are going to fit. **Bend pin 24 straight out** so it stays outside the socket when the chip is
   plugged in. Pin 24 is on the side opposite the notch end's pin 1 row: pins 21–40 run up that side, pin 21 at the
   end nearest pin 20, so pin 24 is the **4th pin from that end**; pin 25 (-CS) is the 5th, right beside it.
   Double-check with the datasheet pinout before bending: pin 24 = RS, pin 25 = -CS, pin 23 = E, pin 22 = R/W.
3. Plug the 6845 in with pin 24 sticking out. The socket's pin-24 contact (ADDR0) is now unused; it stays wired to
   A0 for the other chips, which is fine.
4. Solder a wire (30 AWG wire-wrap is ideal) from the **bent-out pin 24** to **IC15 pin 41** (ADDR1). IC15 is the
   48-pin dual-port RAM; pin 41 is on the pin 25–48 side, 8th pin from the pin-48 end (pins 48, 47, … 41). Solder to the
   pin where it leaves the socket or IC body, not to the board pad. If IC15's pin 41 is awkward, the alternative pickup
   is bus connector X1 pin A4 on the solder side.
5. Confirm with a meter, card still out: continuity IC17 pin 24 ↔ IC15 pin 41 (and ↔ X1 A4); **no** continuity
   IC17 pin 24 ↔ IC17 socket pin 24 / X1 A3 (that would mean the pin went into the socket after all).

If you would rather not bend a chip pin: lift socket pin 24 instead (desolder that one socket pin and bend it up, or
cut the ADDR0 track at the pad) and wire the socket pin to IC15 pin 41. Same result; more work.

### Verifying with the bus tester (before a 6845 is fitted, or with it fitted)

`tests/video/hold_address.py HEX [--rd]` parks an address on the bus and waits, so a meter can sit on the socket:

| Command | IC17 pin 25 (-CS) | IC17 pin 24 (RS) |
|---|---|---|
| `hold_address.py D800` | low | low |
| `hold_address.py D802` | low | **high** (this is the new behaviour; before the fix it read low) |
| `hold_address.py D801` | high | (latch selected instead) |
| `hold_address.py D001` | high | — (A11 = 0: video RAM half) |
| `hold_address.py C400` | high | — (BOARDSEL off) |

With a 6845 fitted, the software test is: write R12/R13 (start address, registers 12 and 13) through $D800/$D802 and read
them back, or write a value to the data register and read it back at $D802 after re-selecting the register at $D800. The
6845's registers 12–17 are readable; 0–11 are write-only, so read back R12 or R14.

Software note: the ROM (2026-09-25, `VCRTCA`/`VCRTCD` in `monitor.asm`, the monitor's `VR` command) does the register
access as `$D800 ← register number`, then `$D802 ← value` (or `value ← $D802`). Odd addresses read the JP1 latch.

## Design change for the next revision (not a bench item)

- RS (IC17 pin 24) to A1 in the schematic, as above.
- Pull-ups on the 7416 outputs (IC27 pins 2, 4, 6, 8, 10, 12); N$5 today only reads high because it floats.
- Join the +5V and VCC nets (see the card README: the +5V rail had no source).

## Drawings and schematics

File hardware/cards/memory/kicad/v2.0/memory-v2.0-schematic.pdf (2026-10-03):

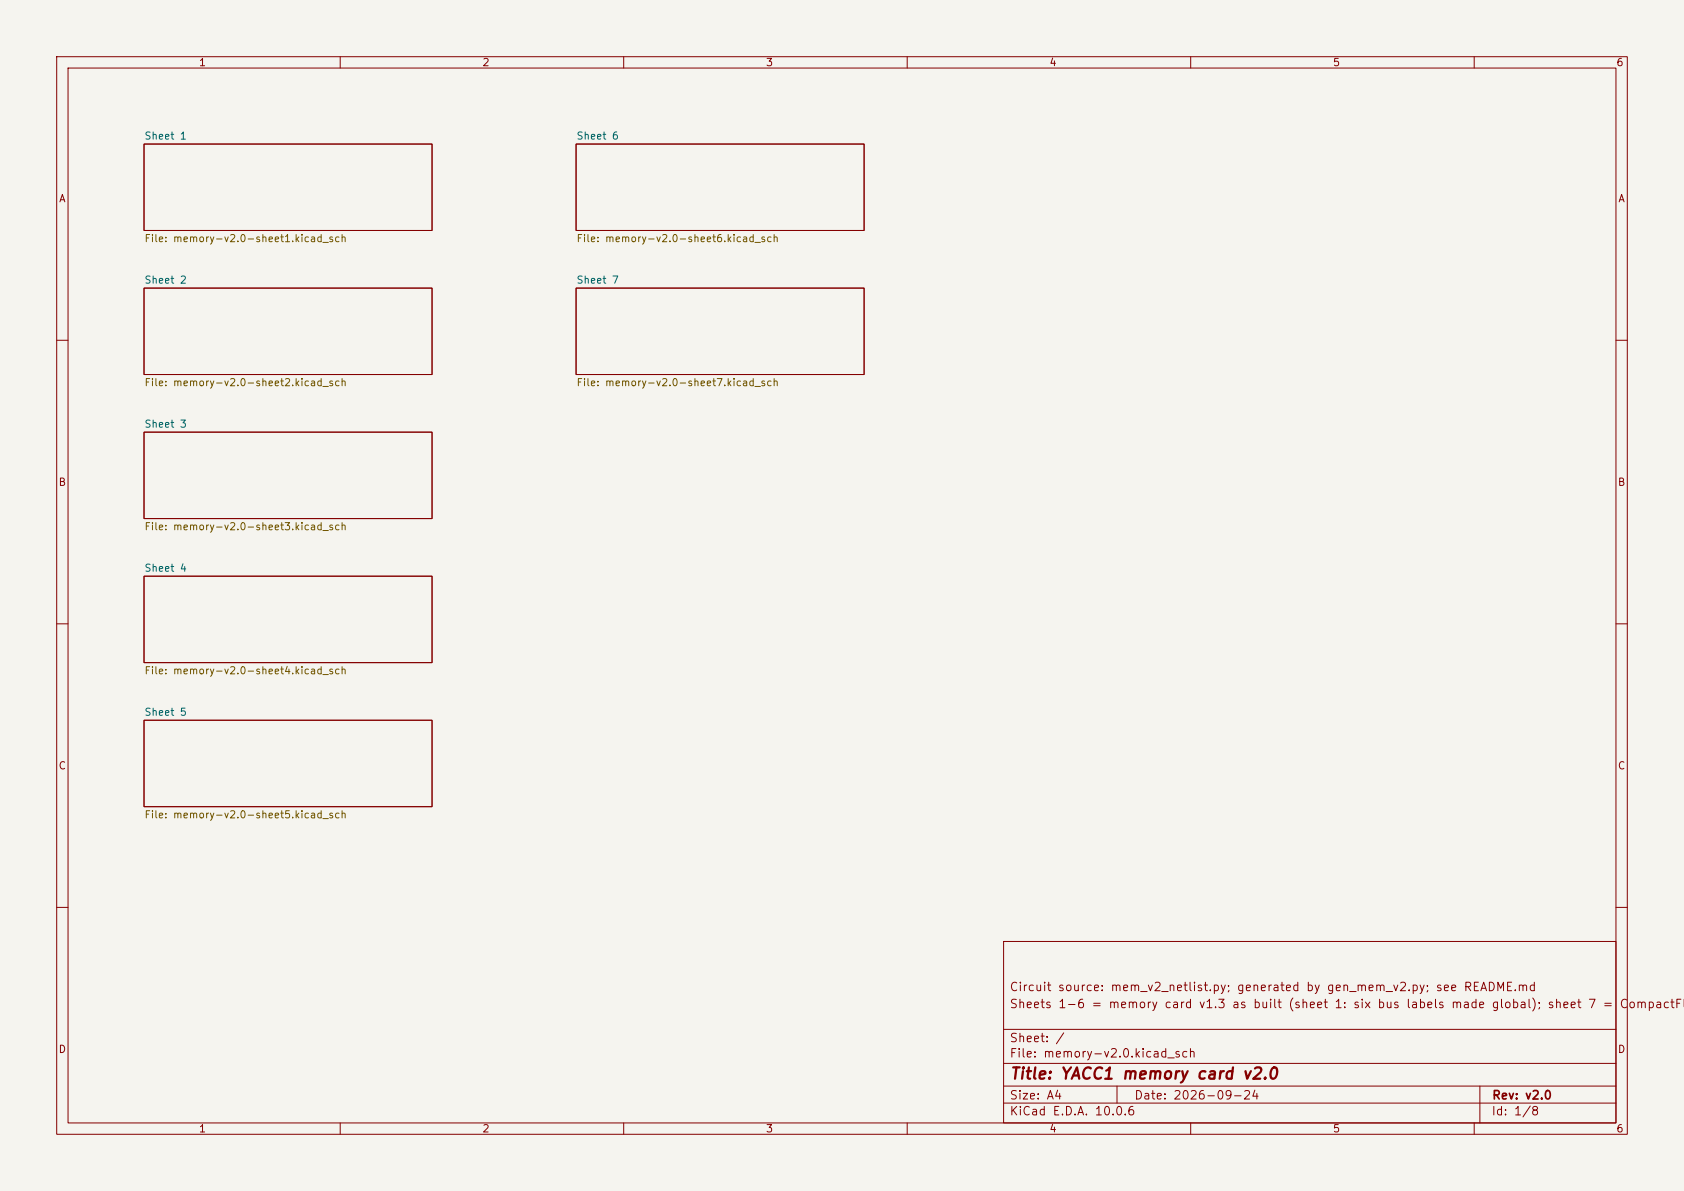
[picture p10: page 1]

Circuit source: mem_v2_netlist.py; generated by gen_mem_v2.py; see README.md

Size: A4 | Rev: v2.0
KiCad E.D.A. 10.0.6 | Id: 1/8

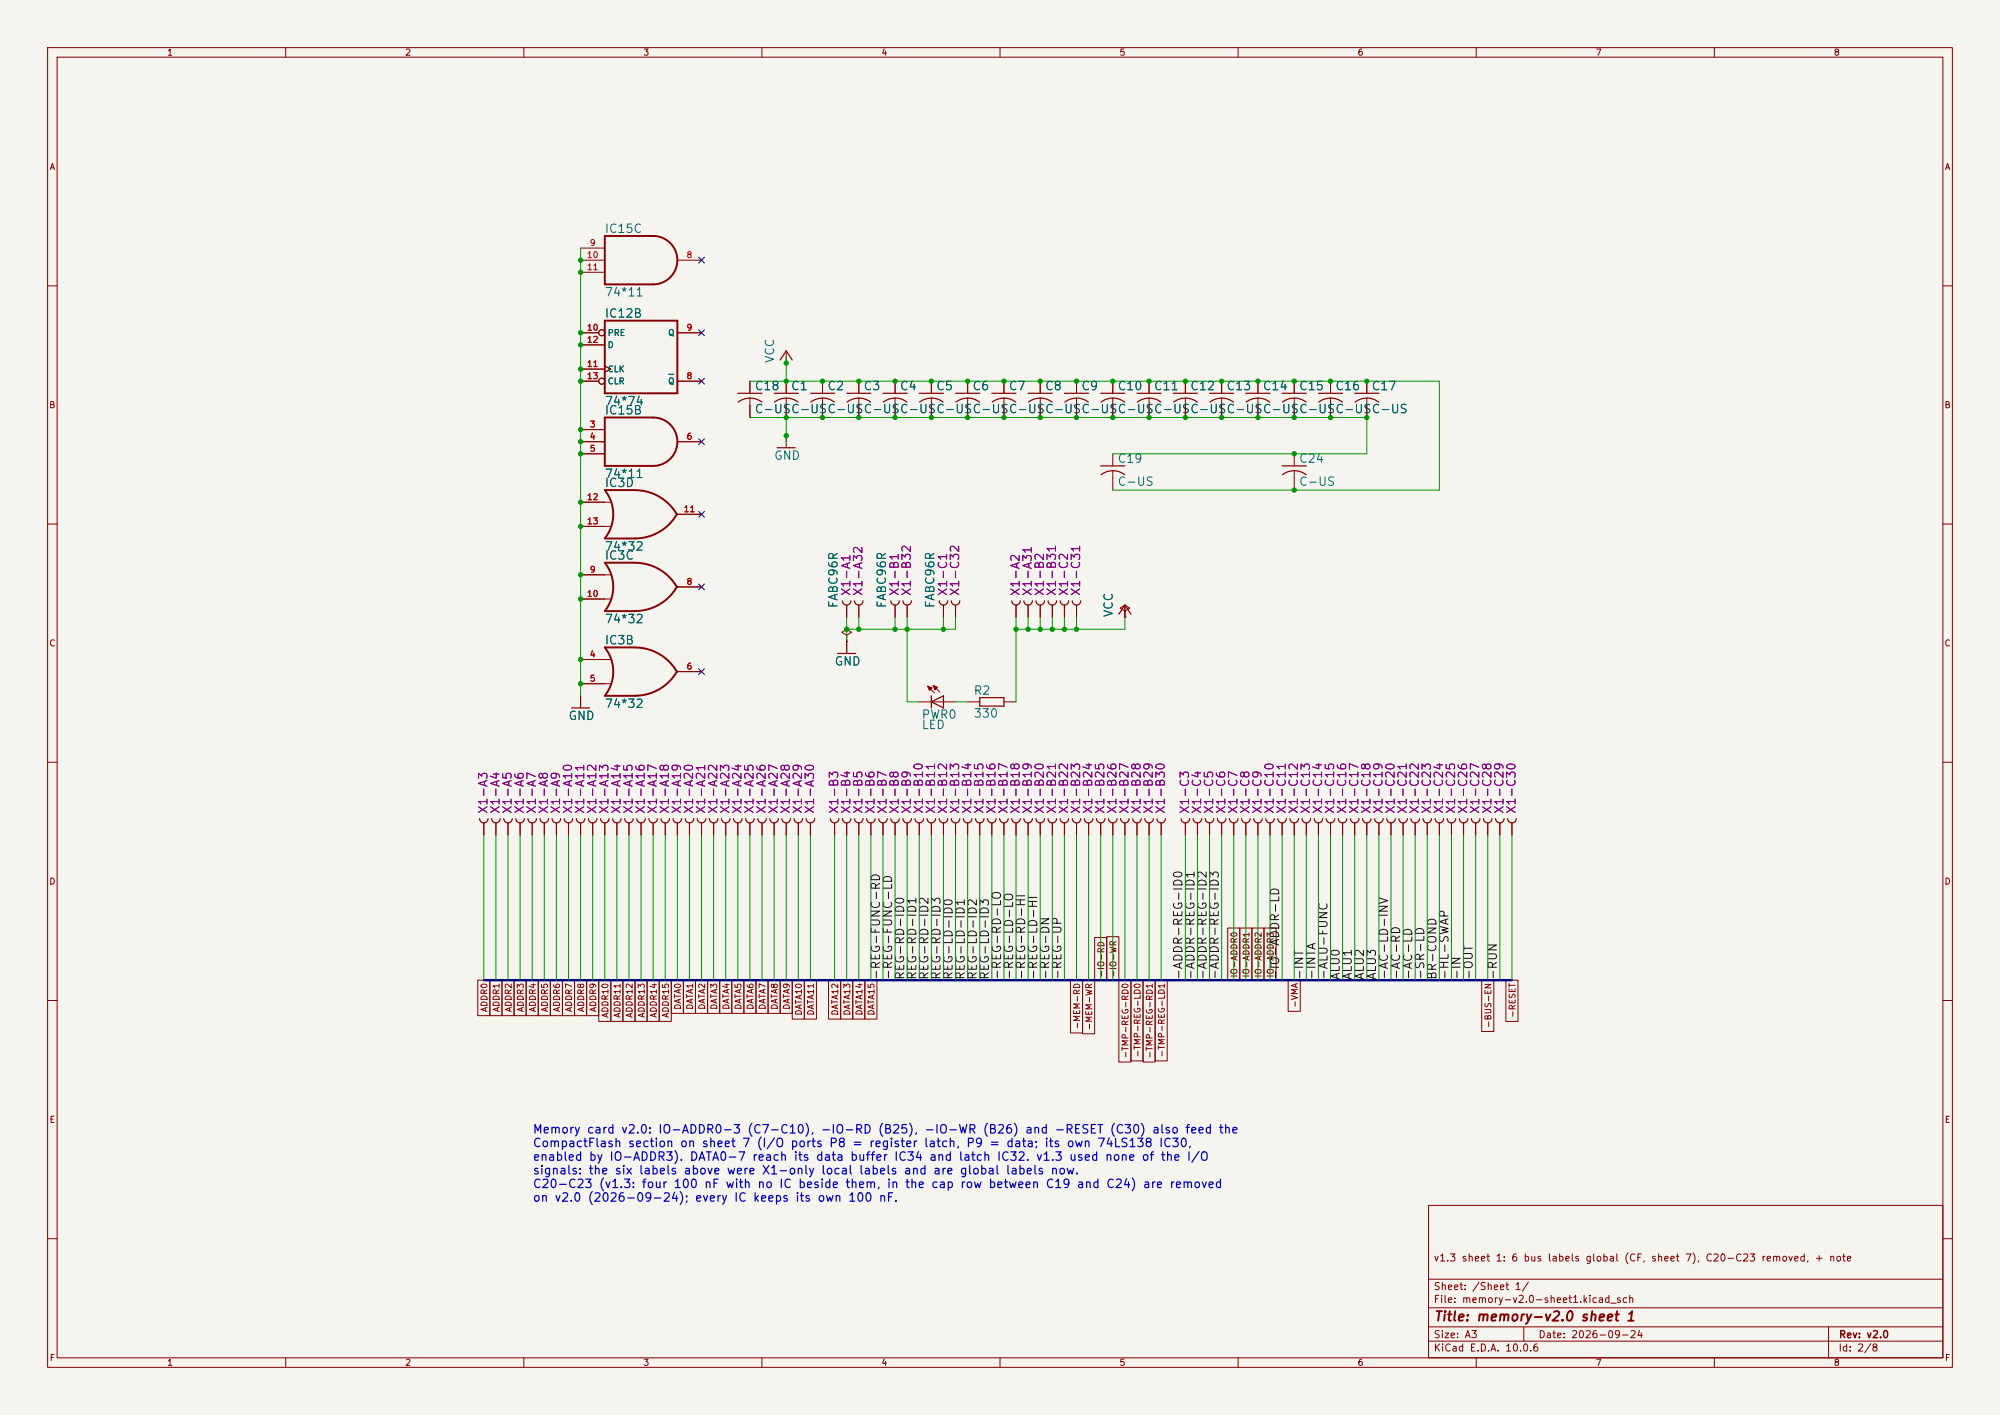
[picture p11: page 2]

Memory card v2.0: IO-ADDR0-3 (C7-C10), -IO-RD (B25), -IO-WR (B26) and -RESET (C30) also feed the
CompactFlash section on sheet 7 (I/O ports P8 = register latch, P9 = data; its own 74LS138 IC30,
enabled by IO-ADDR3). DATA0-7 reach its data buffer IC34 and latch IC32. v1.3 used none of the I/O
signals: the six labels above were X1-only local labels and are global labels now. C20-C23 (v1.3: four 100 nF with no IC beside them, in the cap row between C19 and C24) are removed

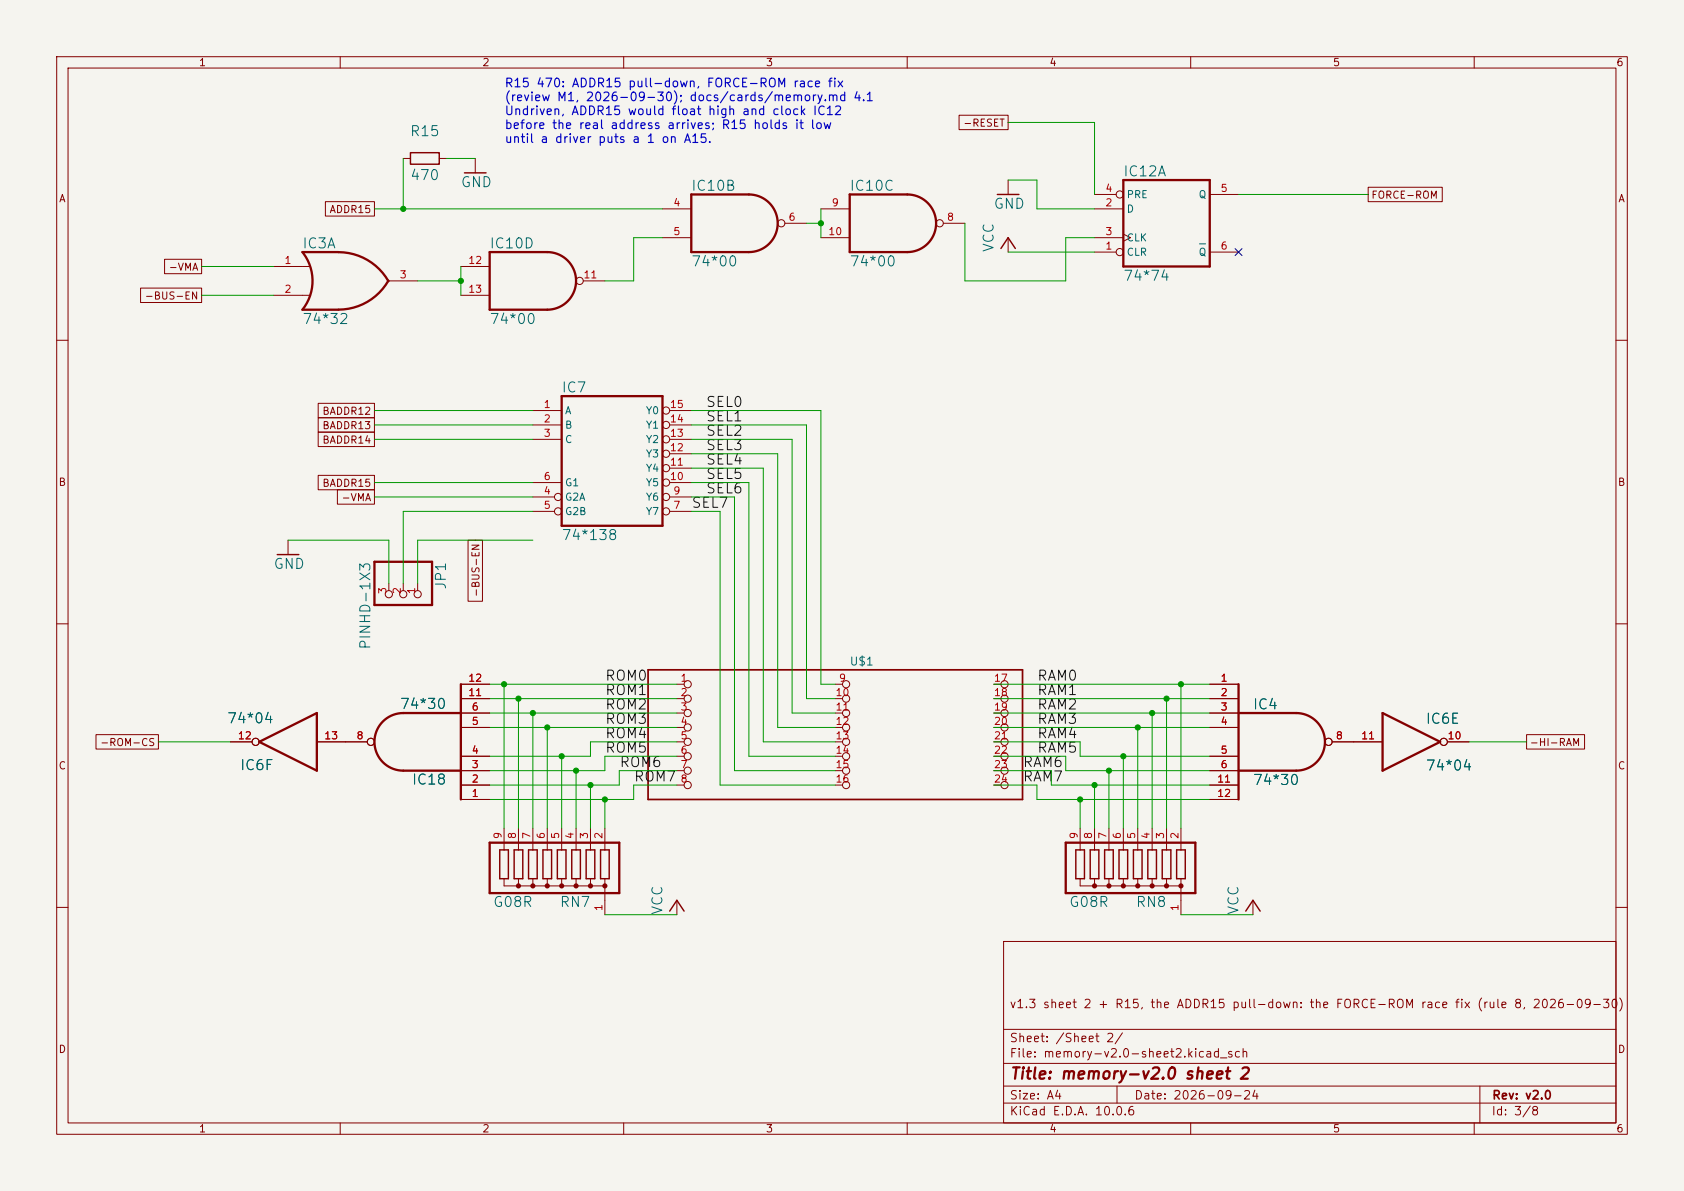
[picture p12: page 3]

R15 470: ADDR15 pull-down, FORCE-ROM race fix
(review M1, 2026-09-30); docs/cards/memory.md 4.1
Undriven, ADDR15 would float high and clock IC12
before the real address arrives; R15 holds it low
until a driver puts a 1 on A15.

FORCE-ROM -RESET BADDR15 BADDR13 BADDR12 -VMA -ROM-CS-BUS-EN -VMA

v1.3 sheet 2 + R15, the ADDR15 pull-down: the FORCE-ROM race fix (rule 8, 2026-09-30) 3

11 11 | ROM1
6 6 | | ROM2
5 5 | | | ROM3

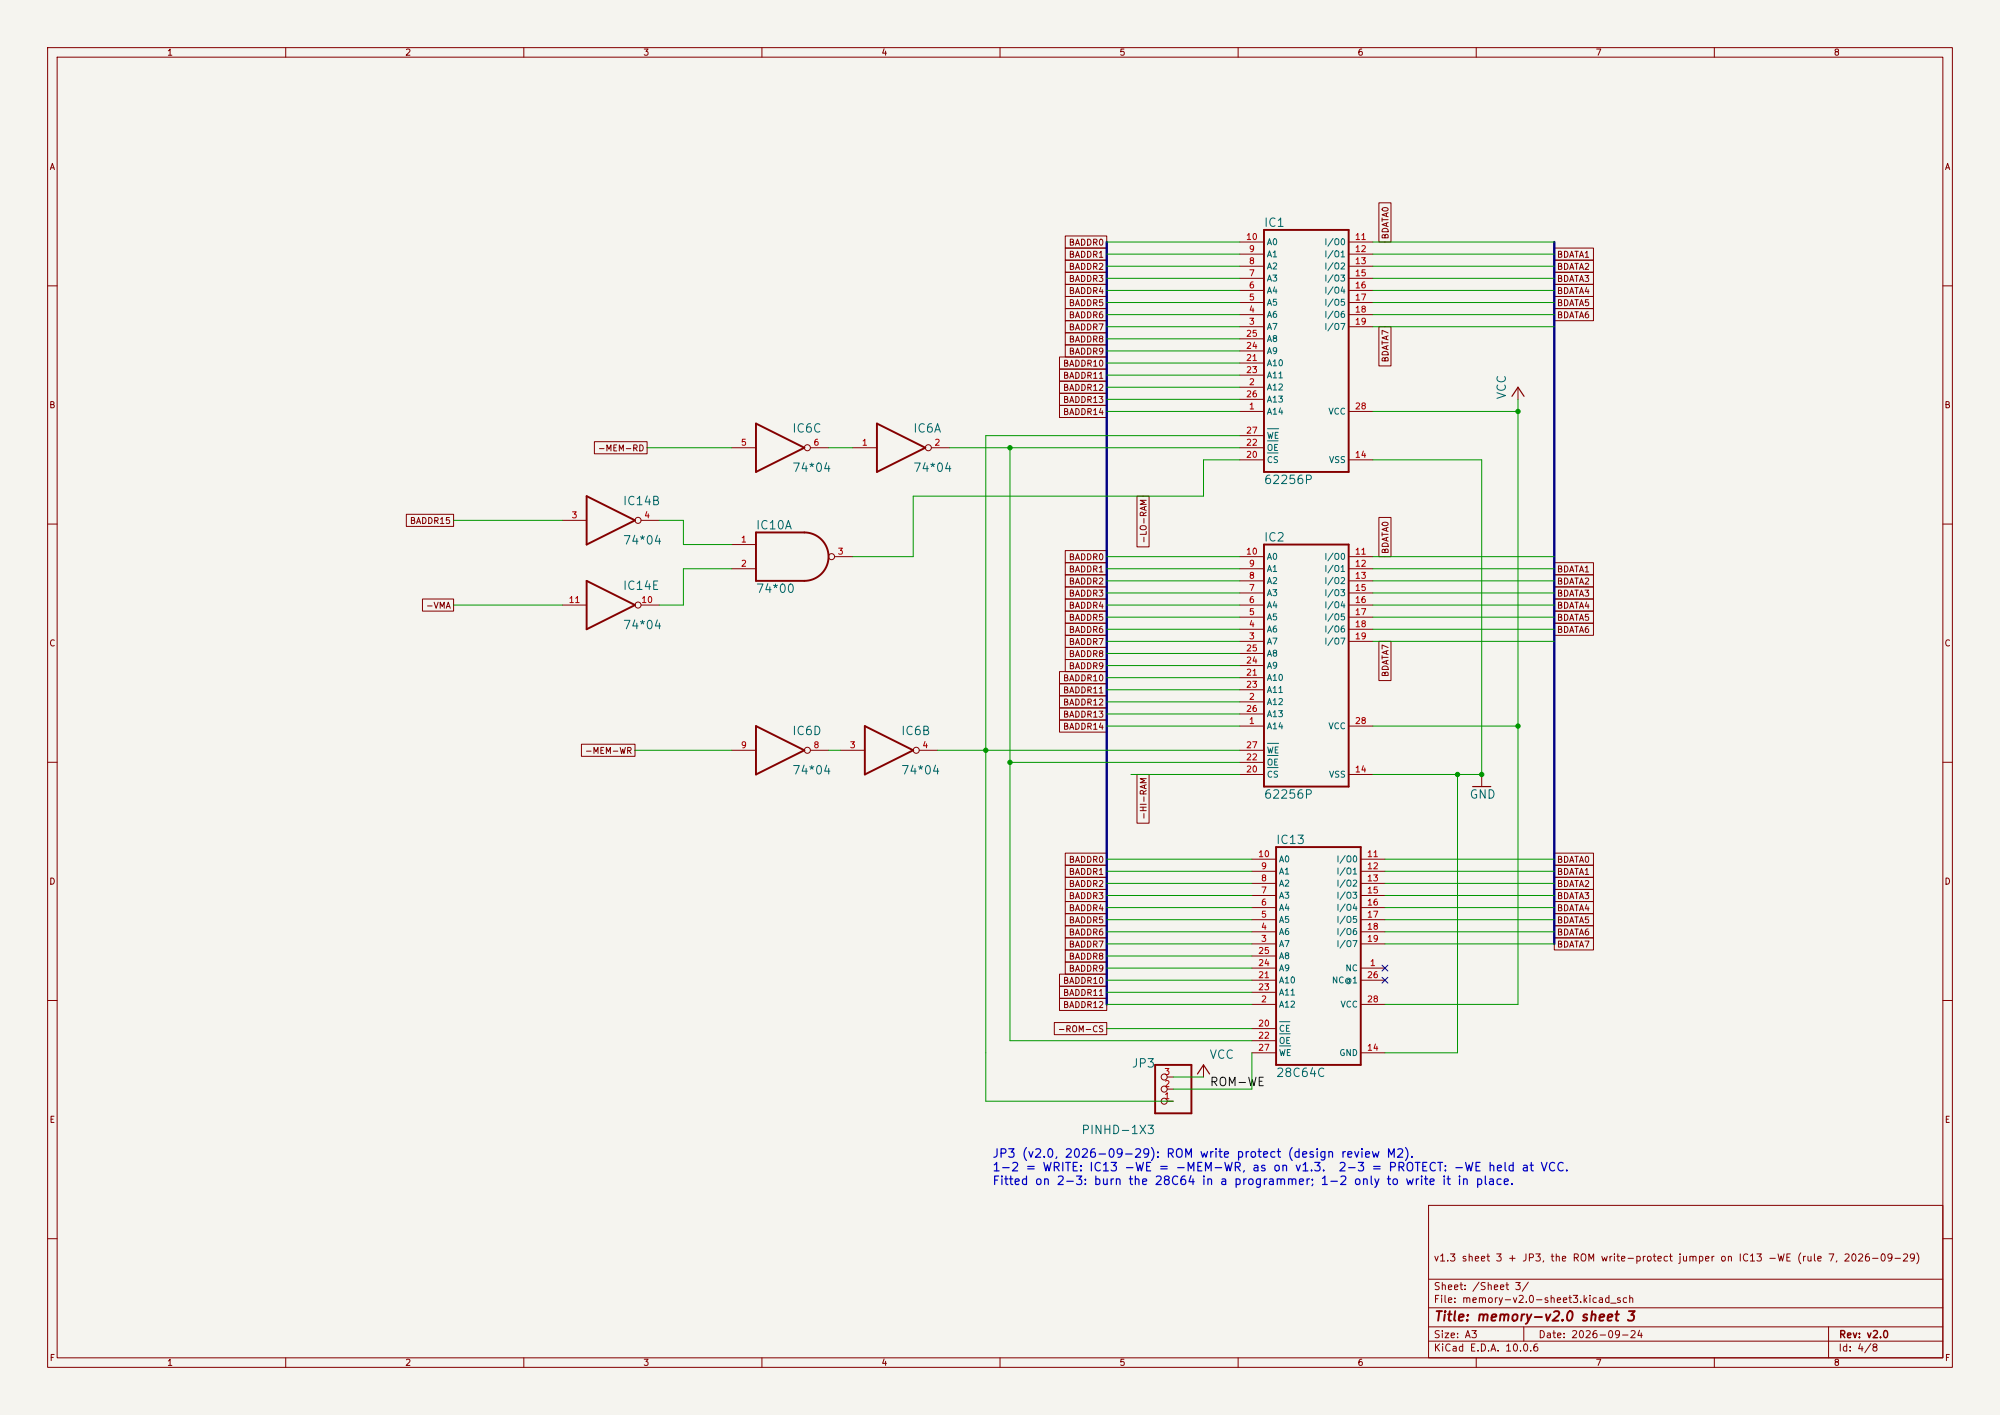
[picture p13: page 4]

JP3 (v2.0, 2026-09-29): ROM write protect (design review M2).
1-2 = WRITE: IC13 -WE = -MEM-WR, as on v1.3. 2-3 = PROTECT: -WE held at VCC.
Fitted on 2-3: burn the 28C64 in a programmer; 1-2 only to write it in place.

v1.3 sheet 3 + JP3, the ROM write-protect jumper on IC13 -WE (rule 7, 2026-09-29)

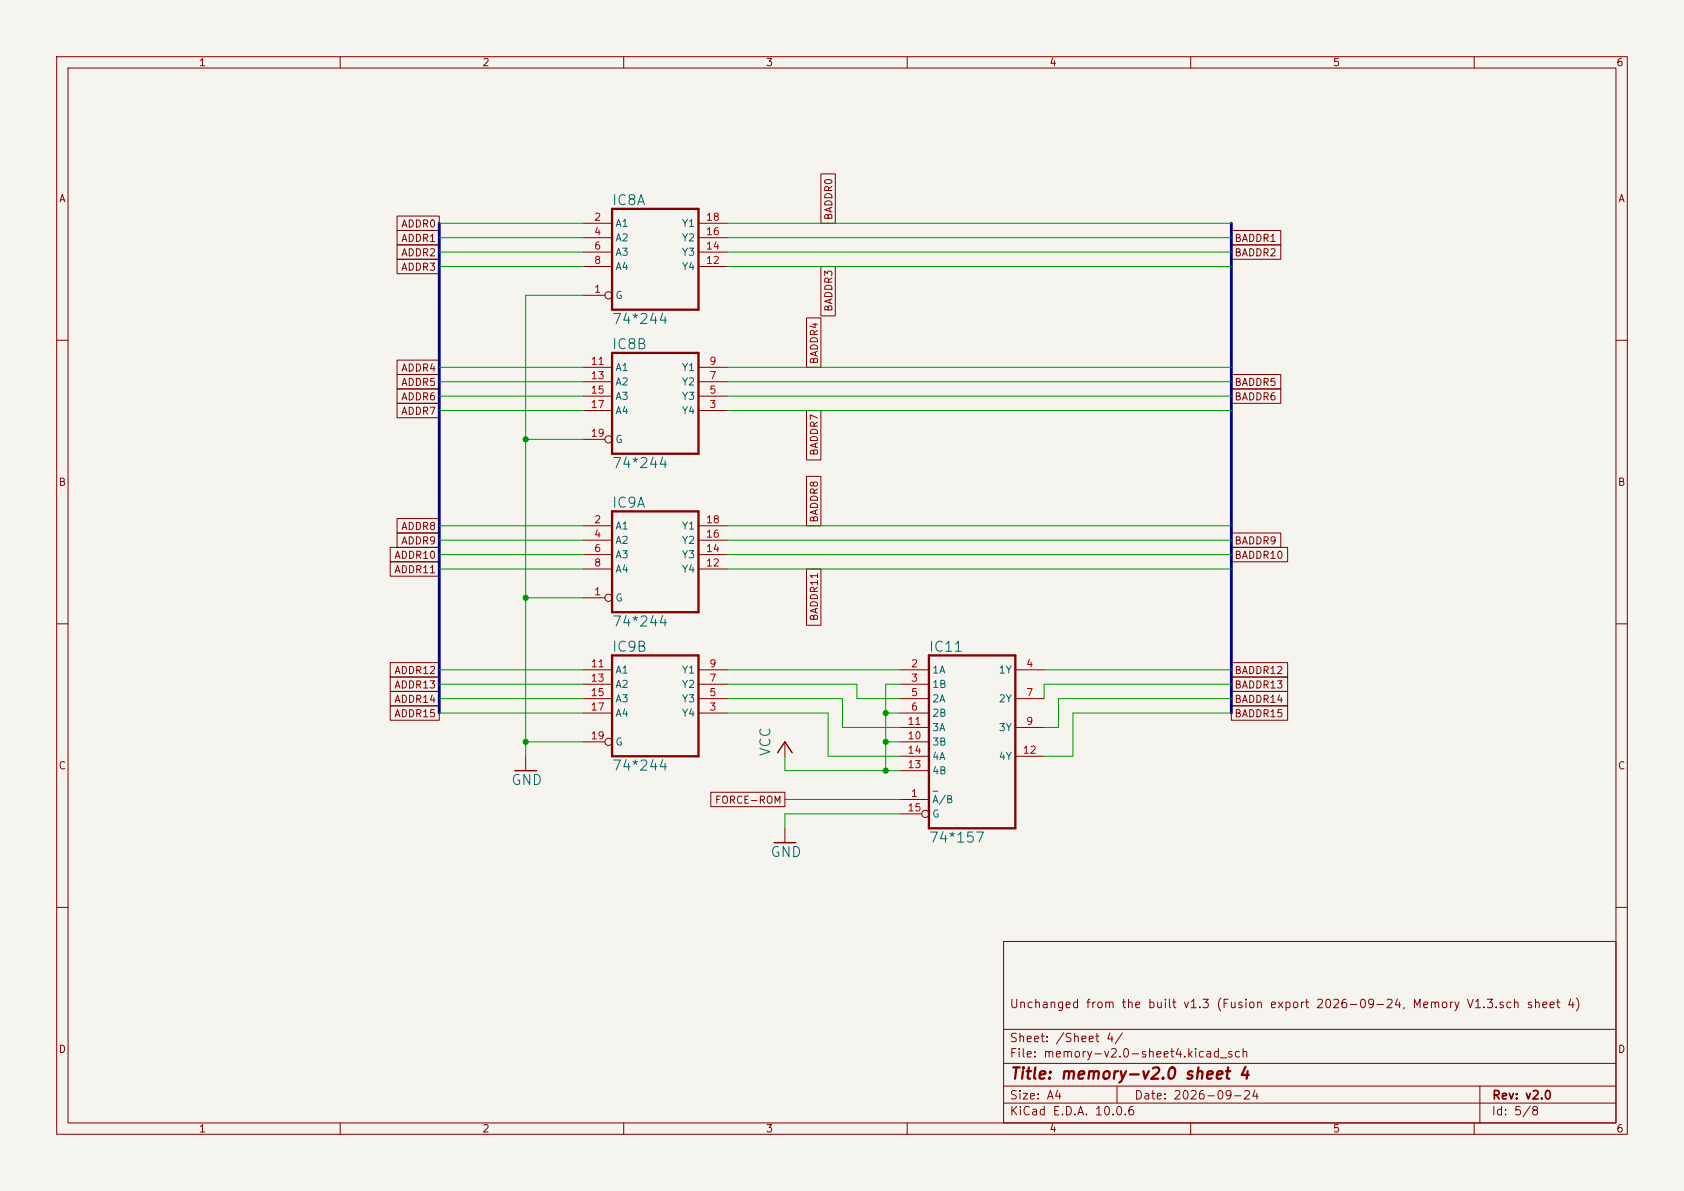
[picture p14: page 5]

Unchanged from the built v1.3 (Fusion export 2026-09-24, Memory V1.3.sch sheet 4) A/B 1

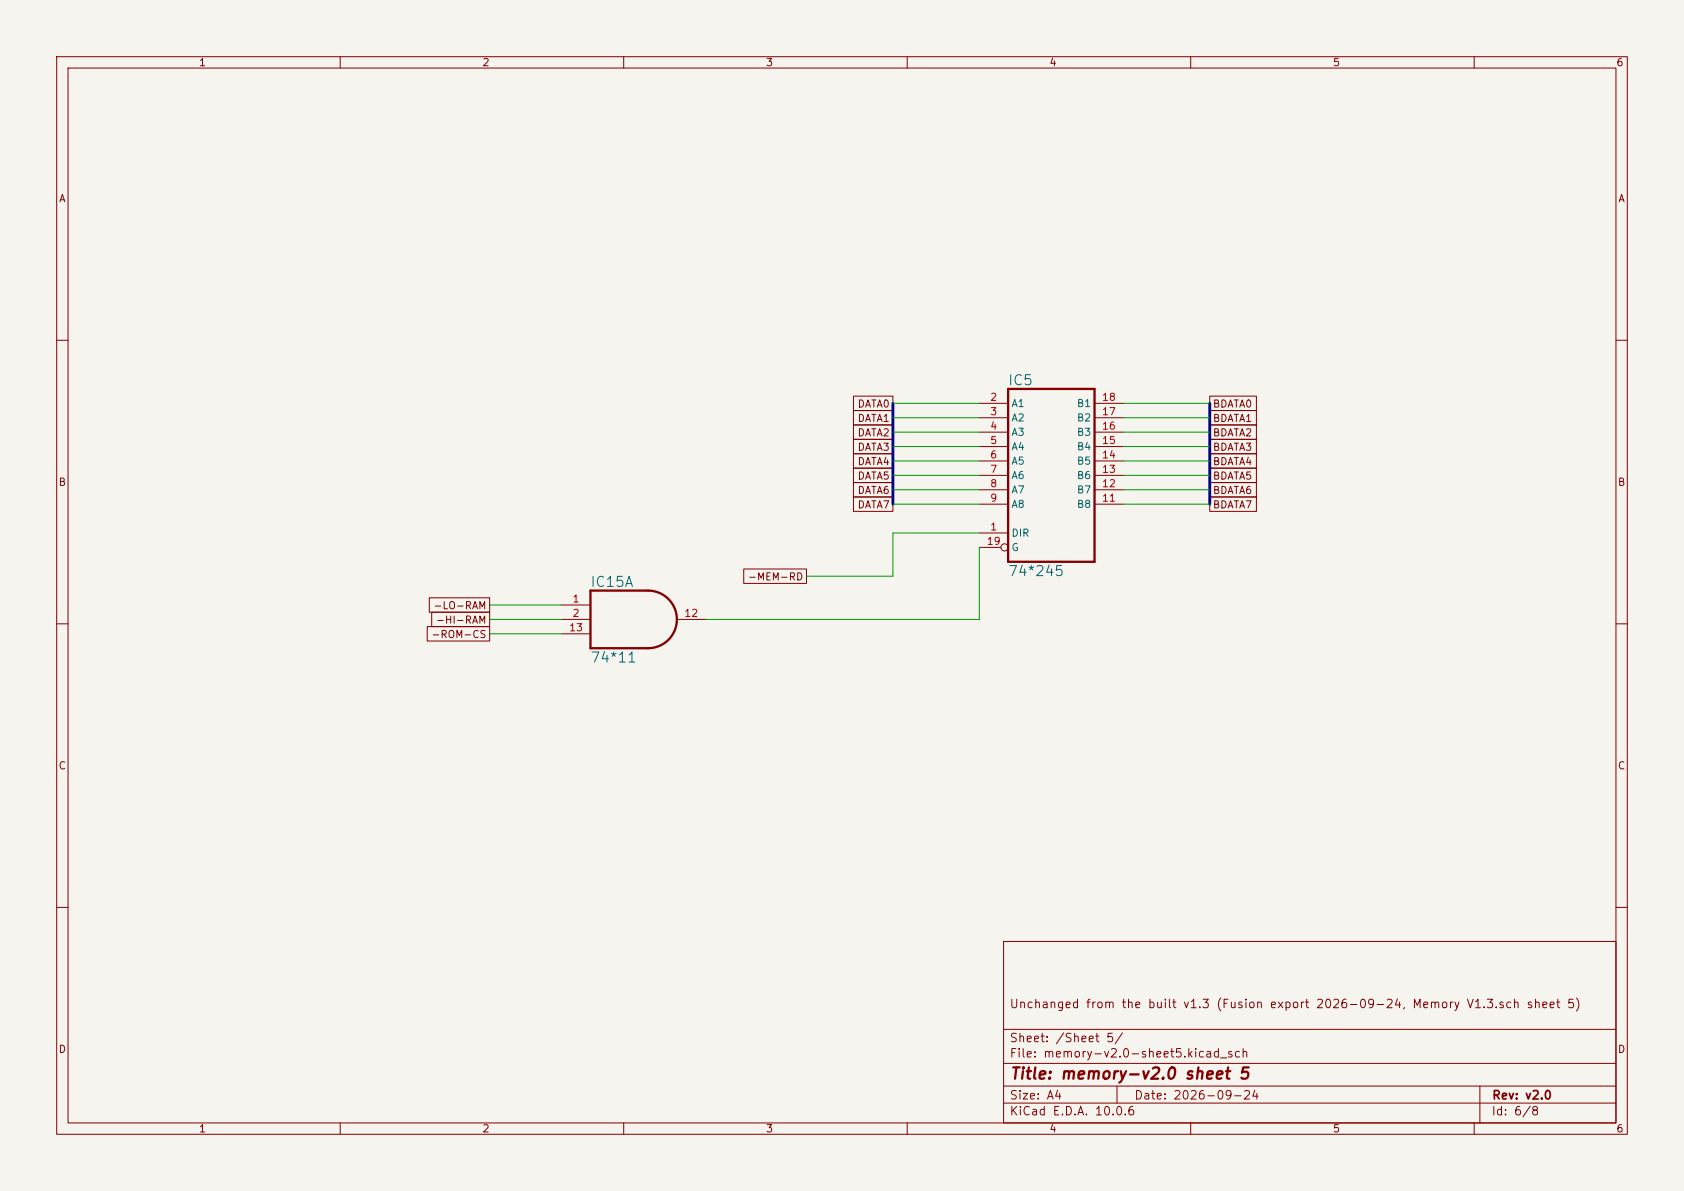
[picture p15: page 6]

Unchanged from the built v1.3 (Fusion export 2026-09-24, Memory V1.3.sch sheet 5) 1

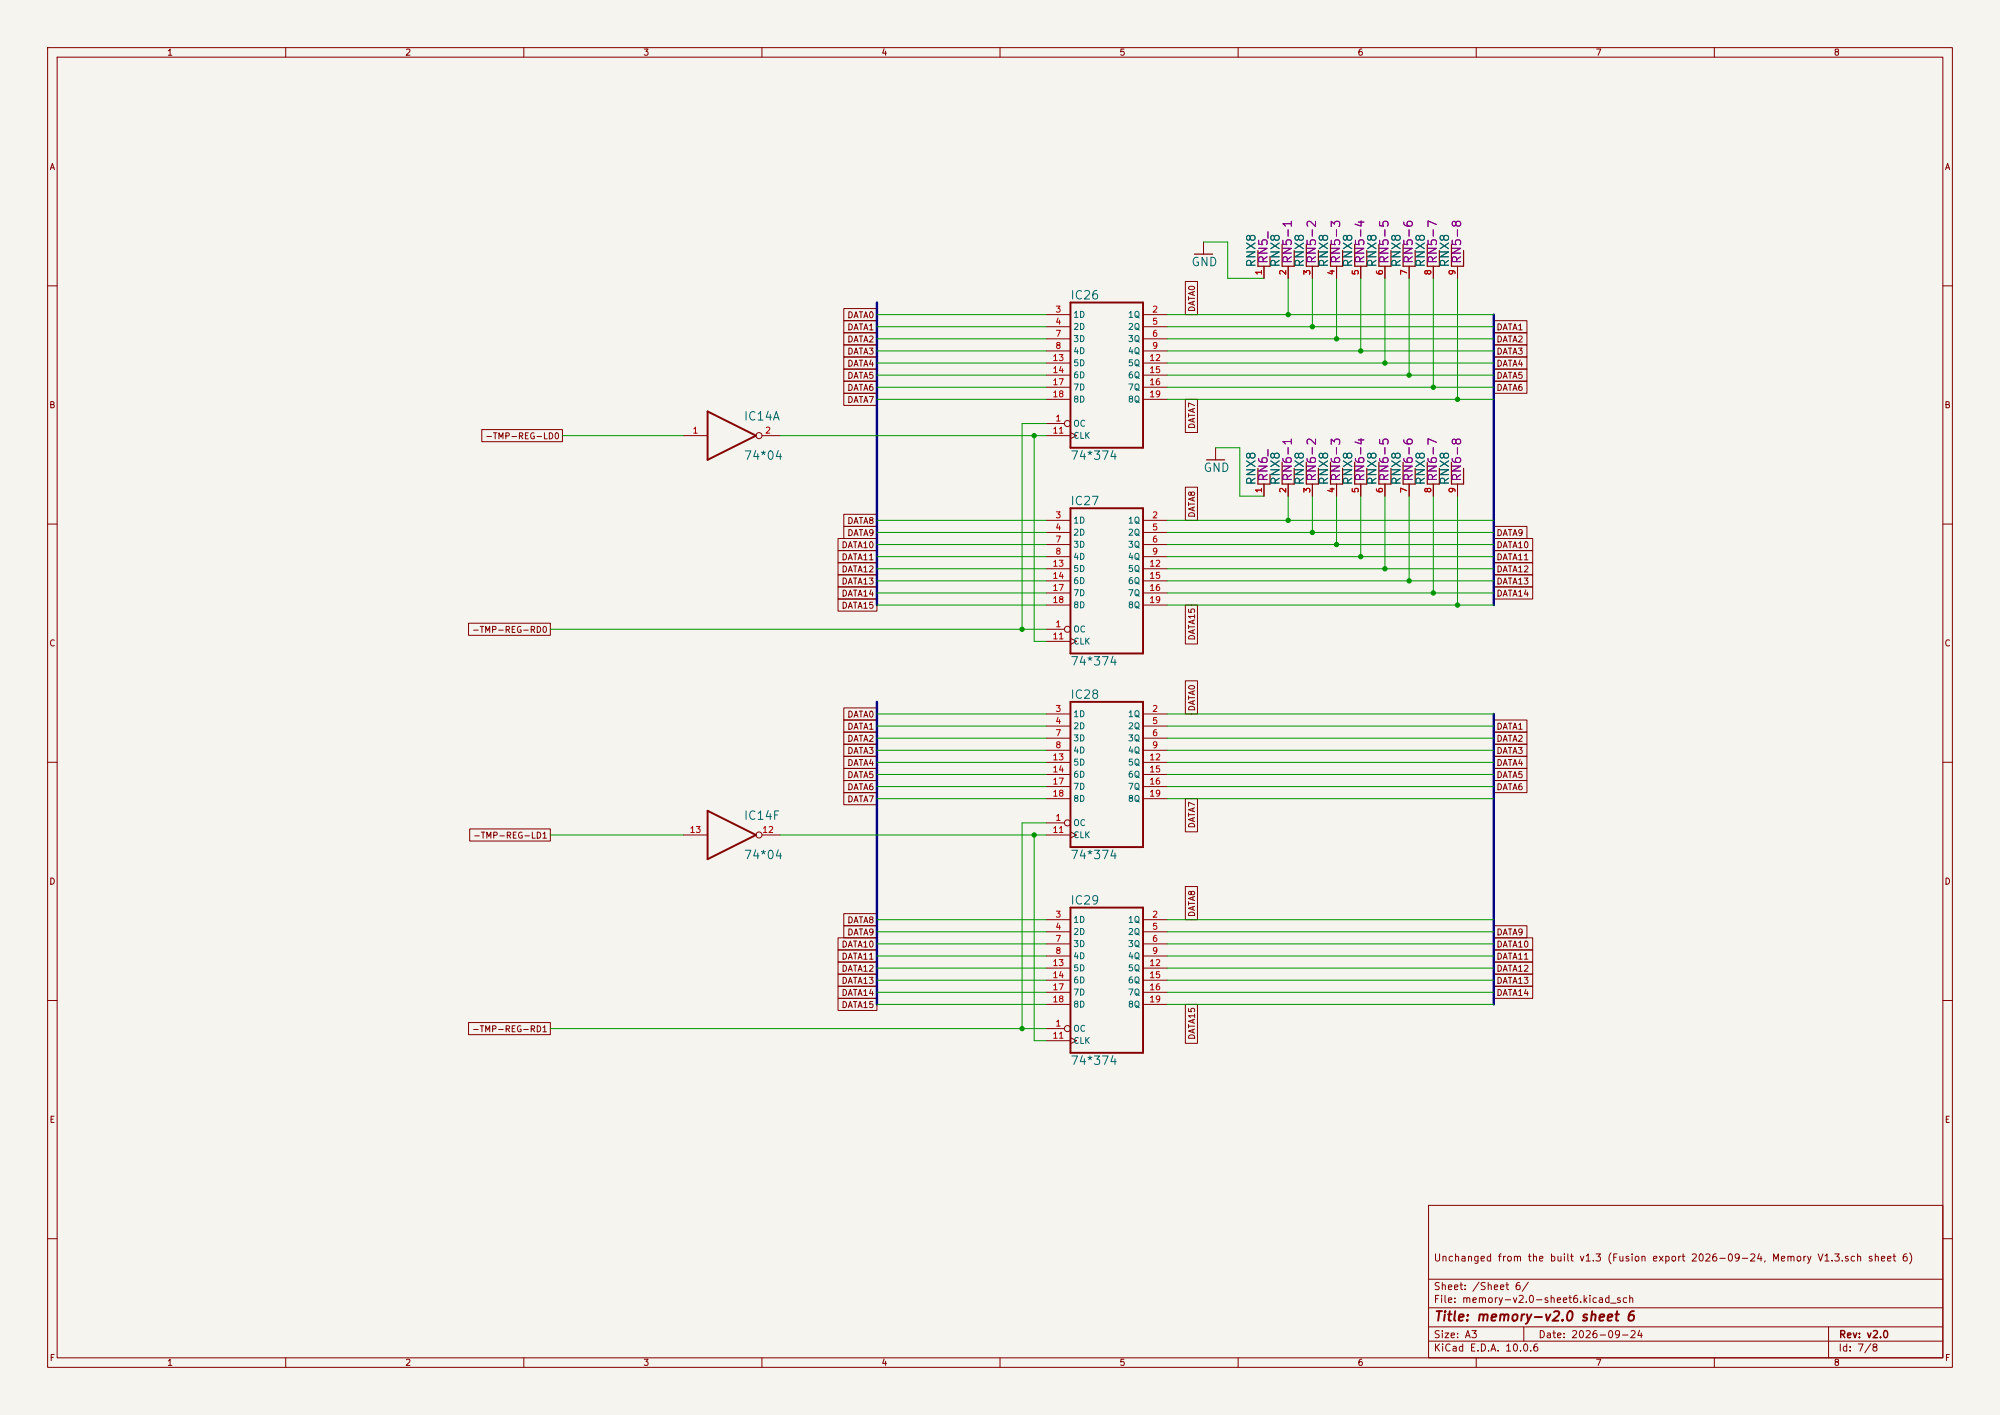
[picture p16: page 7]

Unchanged from the built v1.3 (Fusion export 2026-09-24, Memory V1.3.sch sheet 6) 9 RNX8 RN6-8

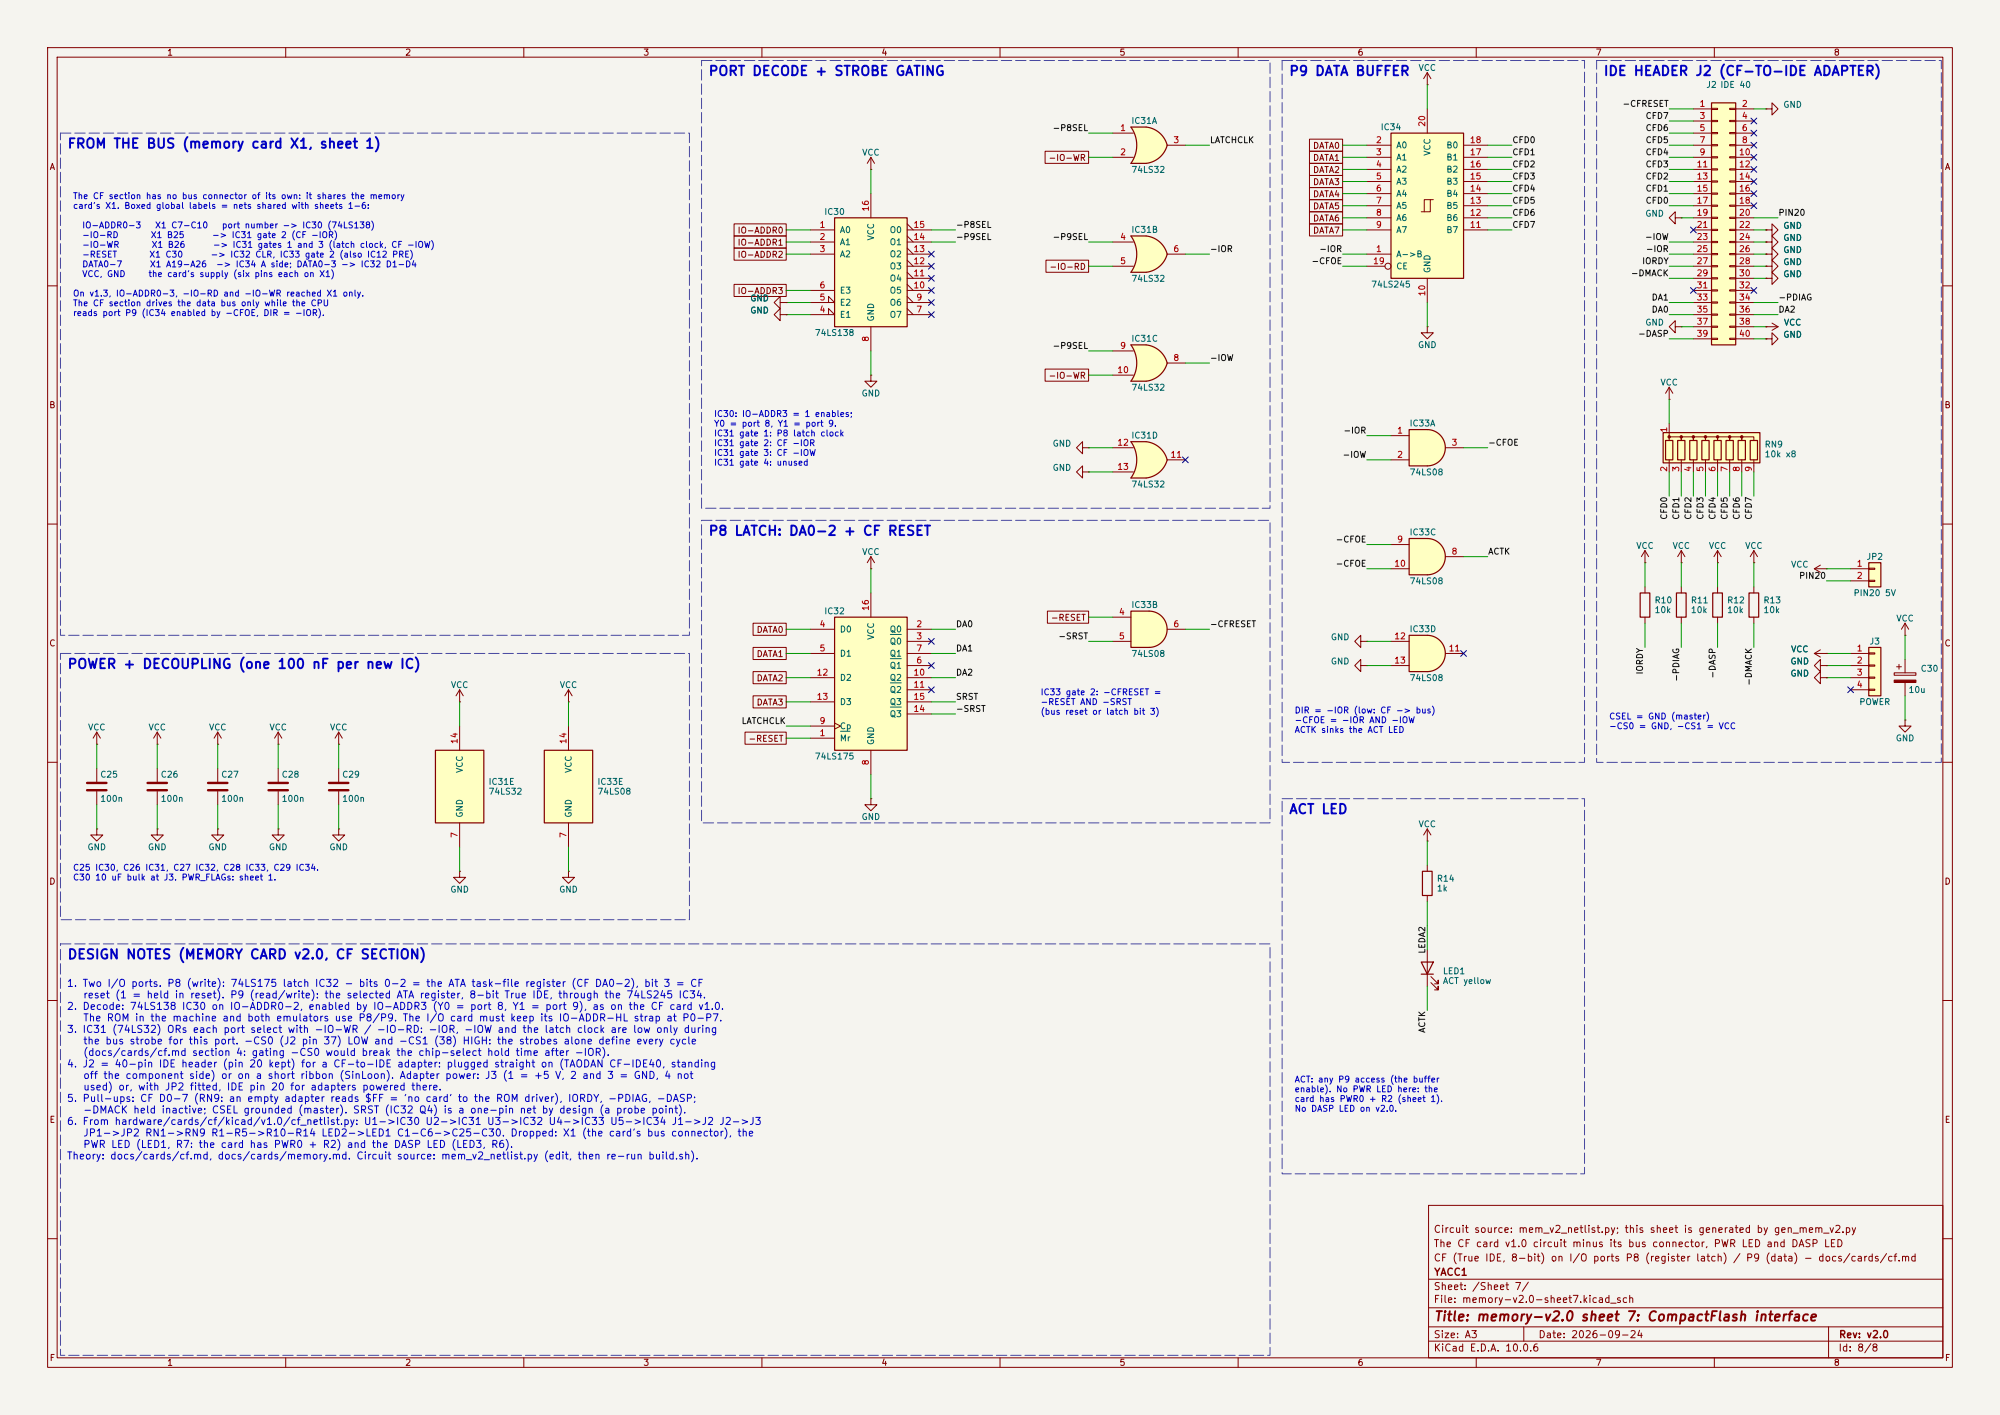
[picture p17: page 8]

PORT DECODE + STROBE GATING

IDE HEADER J2 (CF-TO-IDE ADAPTER)

FROM THE BUS (memory card X1, sheet 1)

The CF section has no bus connector of its own: it shares the memory card's X1. Boxed global labels = nets shared with sheets 1-6:

reads port P9 (IC34 enabled by -CFOE, DIR = -IOR).

IC30: IO-ADDR3 = 1 enables; Y0 = port 8, Y1 = port 9.

ACTK sinks the ACT LED P8 LATCH: DA0-2 + CF RESET

POWER + DECOUPLING (one 100 nF per new IC)

IC33 gate 2: -CFRESET =
-RESET AND -SRST
(bus reset or latch bit 3)

DIR = -IOR (low: CF -> bus) -CFOE = -IOR AND -IOW

CSEL = GND (master) -CS0 = GND, -CS1 = VCC

C25 IC30, C26 IC31, C27 IC32, C28 IC33, C29 IC34. C30 10 uF bulk at J3. PWR_FLAGs: sheet 1. DESIGN NOTES (MEMORY CARD v2.0, CF SECTION)

1. Two I/O ports. P8 (write): 74LS175 latch IC32 - bits 0-2 = the ATA task-file register (CF DA0-2), bit 3 = CF
reset (1 = held in reset). P9 (read/write): the selected ATA register, 8-bit True IDE, through the 74LS245 IC34.
2. Decode: 74LS138 IC30 on IO-ADDR0-2, enabled by IO-ADDR3 (Y0 = port 8, Y1 = port 9), as on the CF card v1.0.
The ROM in the machine and both emulators use P8/P9. The I/O card must keep its IO-ADDR-HL strap at P0-P7.
3. IC31 (74LS32) ORs each port select with -IO-WR / -IO-RD: -IOR, -IOW and the latch clock are low only during
the bus strobe for this port. -CS0 (J2 pin 37) LOW and -CS1 (38) HIGH: the strobes alone define every cycle
(docs/cards/cf.md section 4: gating -CS0 would break the chip-select hold time after -IOR).
4. J2 = 40-pin IDE header (pin 20 kept) for a CF-to-IDE adapter: plugged straight on (TAODAN CF-IDE40, standing
off the component side) or on a short ribbon (SinLoon). Adapter power: J3 (1 = +5 V, 2 and 3 = GND, 4 not
used) or, with JP2 fitted, IDE pin 20 for adapters powered there.
5. Pull-ups: CF D0-7 (RN9: an empty adapter reads $FF = 'no card' to the ROM driver), IORDY, -PDIAG, -DASP;
-DMACK held inactive; CSEL grounded (master). SRST (IC32 Q4) is a one-pin net by design (a probe point).
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

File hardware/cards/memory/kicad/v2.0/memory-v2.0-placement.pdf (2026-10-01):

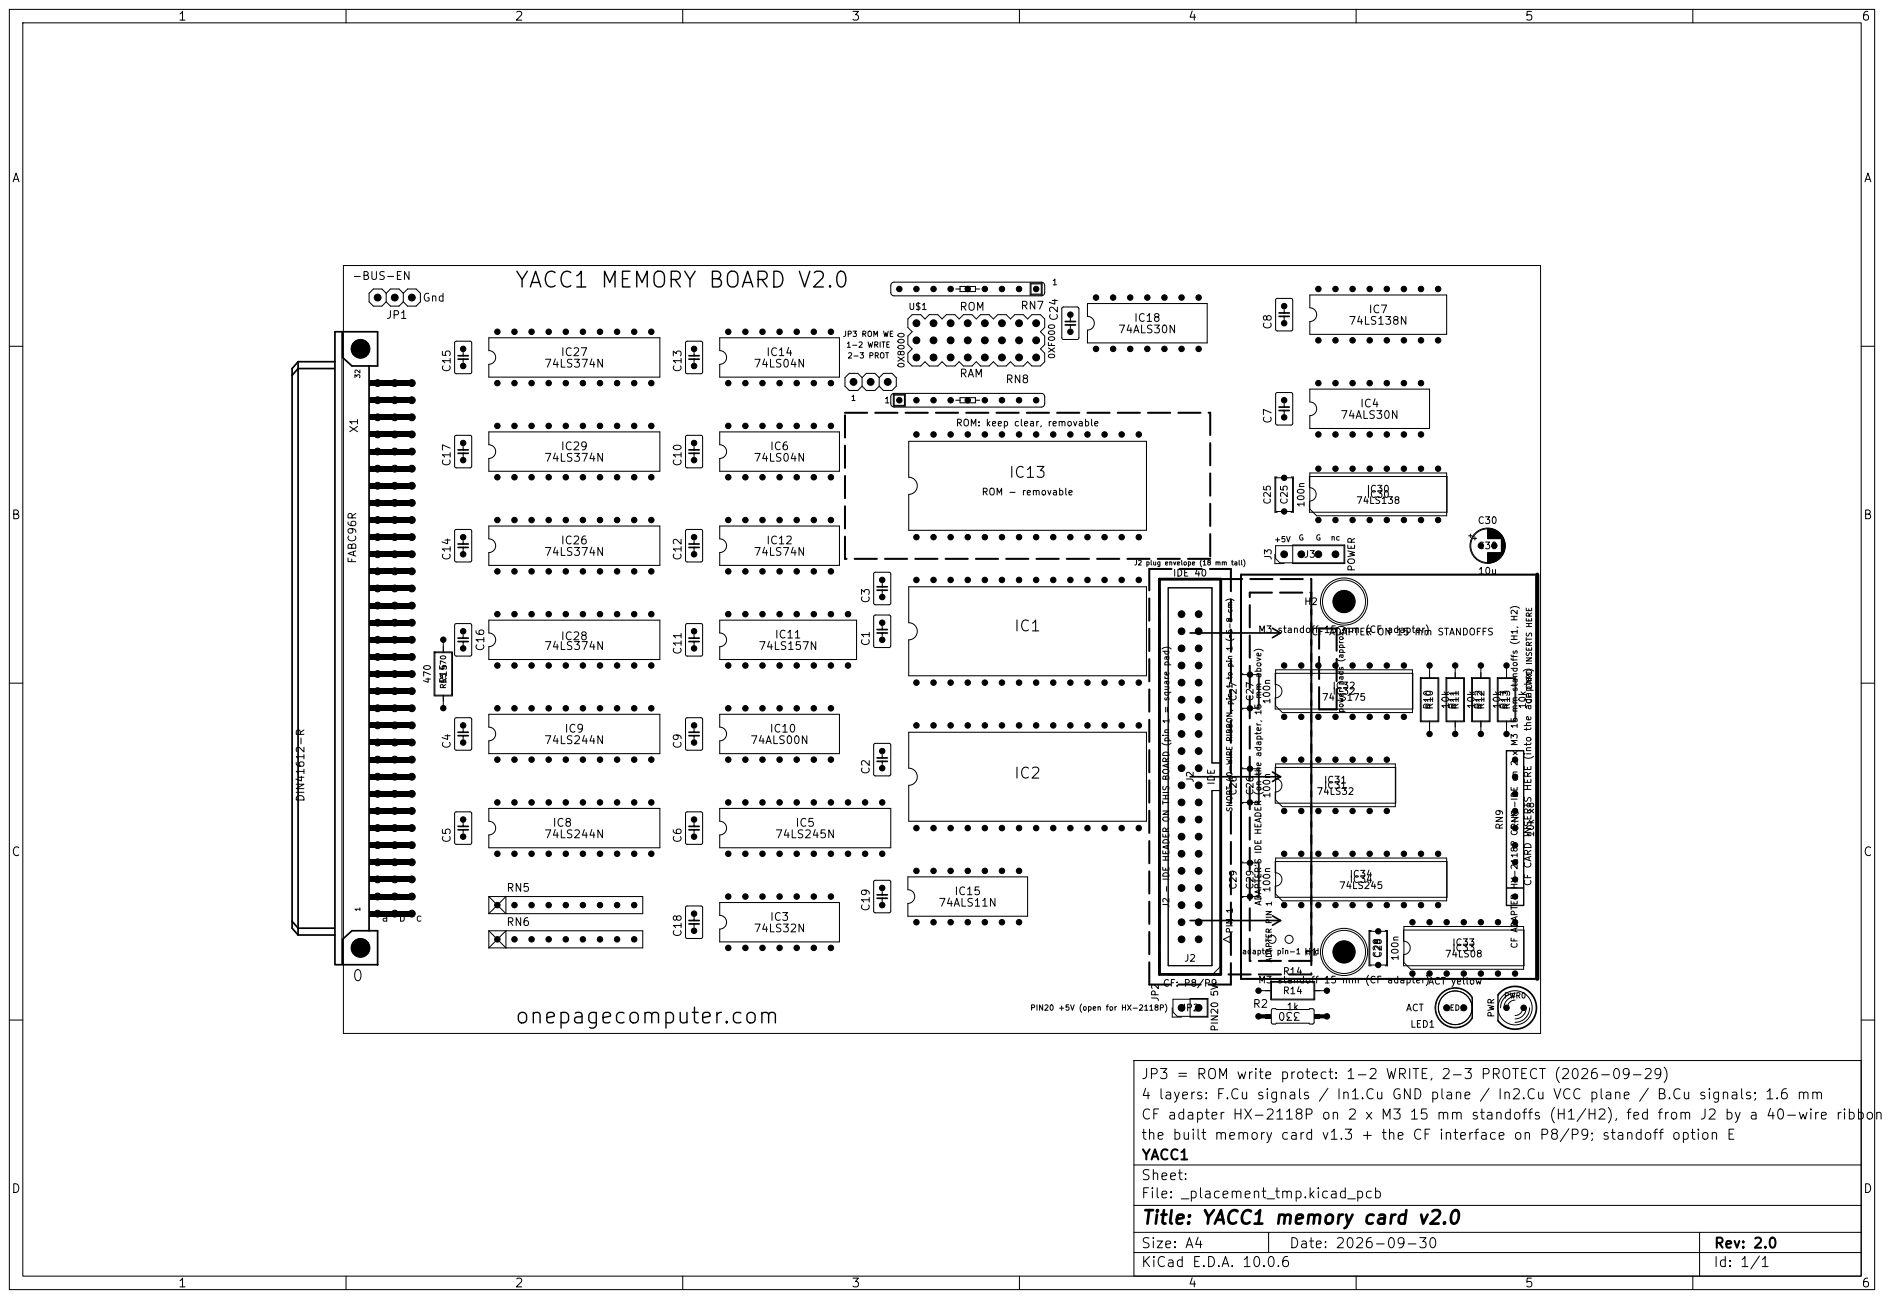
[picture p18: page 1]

M3 standoff 15 mm (CF adapter) H1

JP3 = ROM write protect: 1-2 WRITE, 2-3 PROTECT (2026-09-29)
4 layers: F.Cu signals / In1.Cu GND plane / In2.Cu VCC plane / B.Cu signals; 1.6 mm
CF adapter HX-2118P on 2 x M3 15 mm standoffs (H1/H2), fed from J2 by a 40-wire ribbon
the built memory card v1.3 + the CF interface on P8/P9; standoff option E
YACC1
Sheet:
File: _placement_tmp.kicad_pcb
Title: YACC1 memory card v2.0

Size: A4 | Rev: 2.0
KiCad E.D.A. 10.0.6 | Id: 1/1

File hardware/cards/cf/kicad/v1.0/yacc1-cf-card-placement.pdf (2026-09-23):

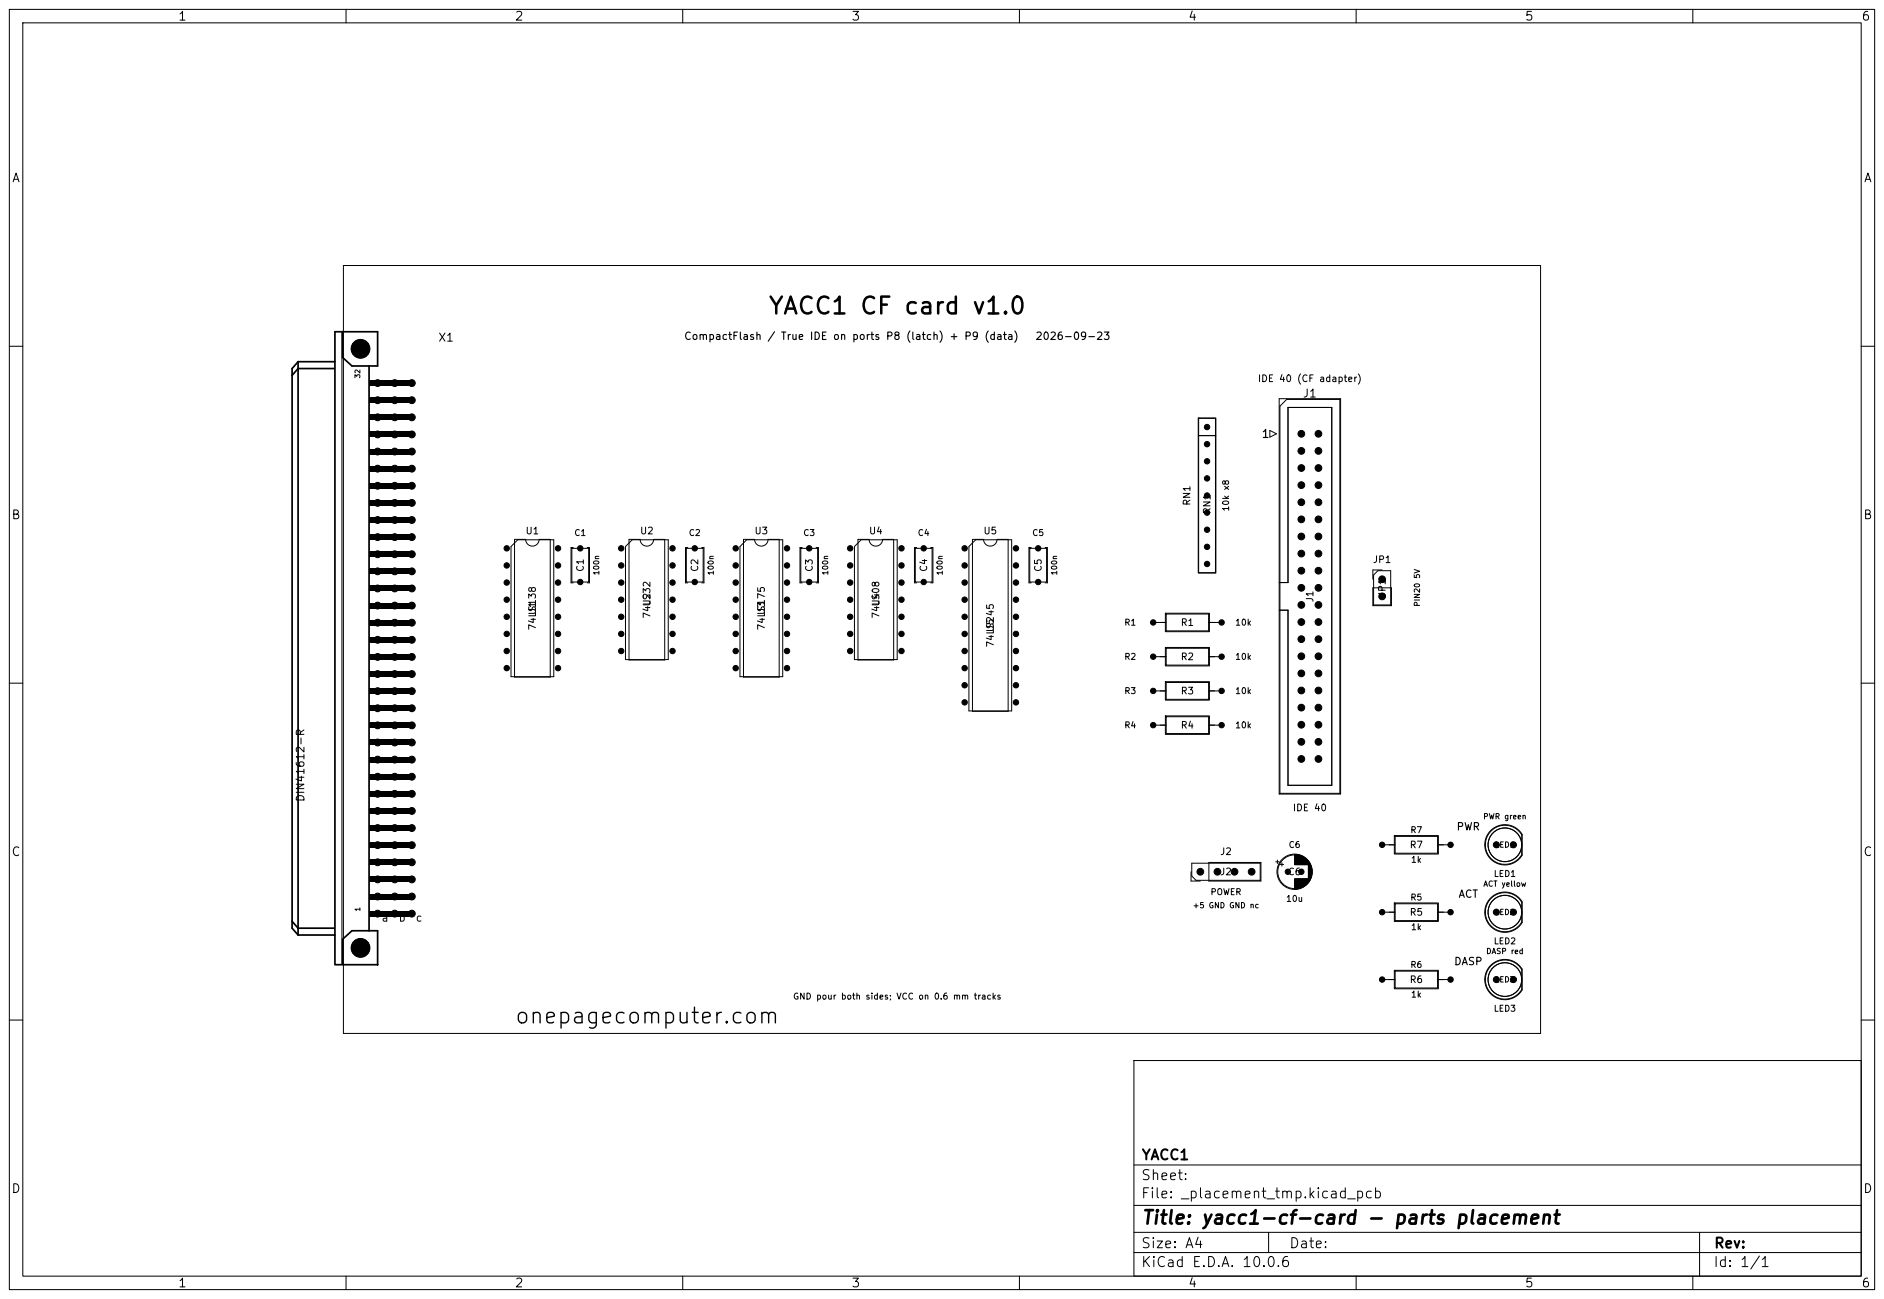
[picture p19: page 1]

ACT DASP 1 onepagecomputer.com

+5 GND GND nc GND pour both sides; VCC on 0.6 mm tracks

Size: A4 | Rev:
KiCad E.D.A. 10.0.6 | Id: 1/1

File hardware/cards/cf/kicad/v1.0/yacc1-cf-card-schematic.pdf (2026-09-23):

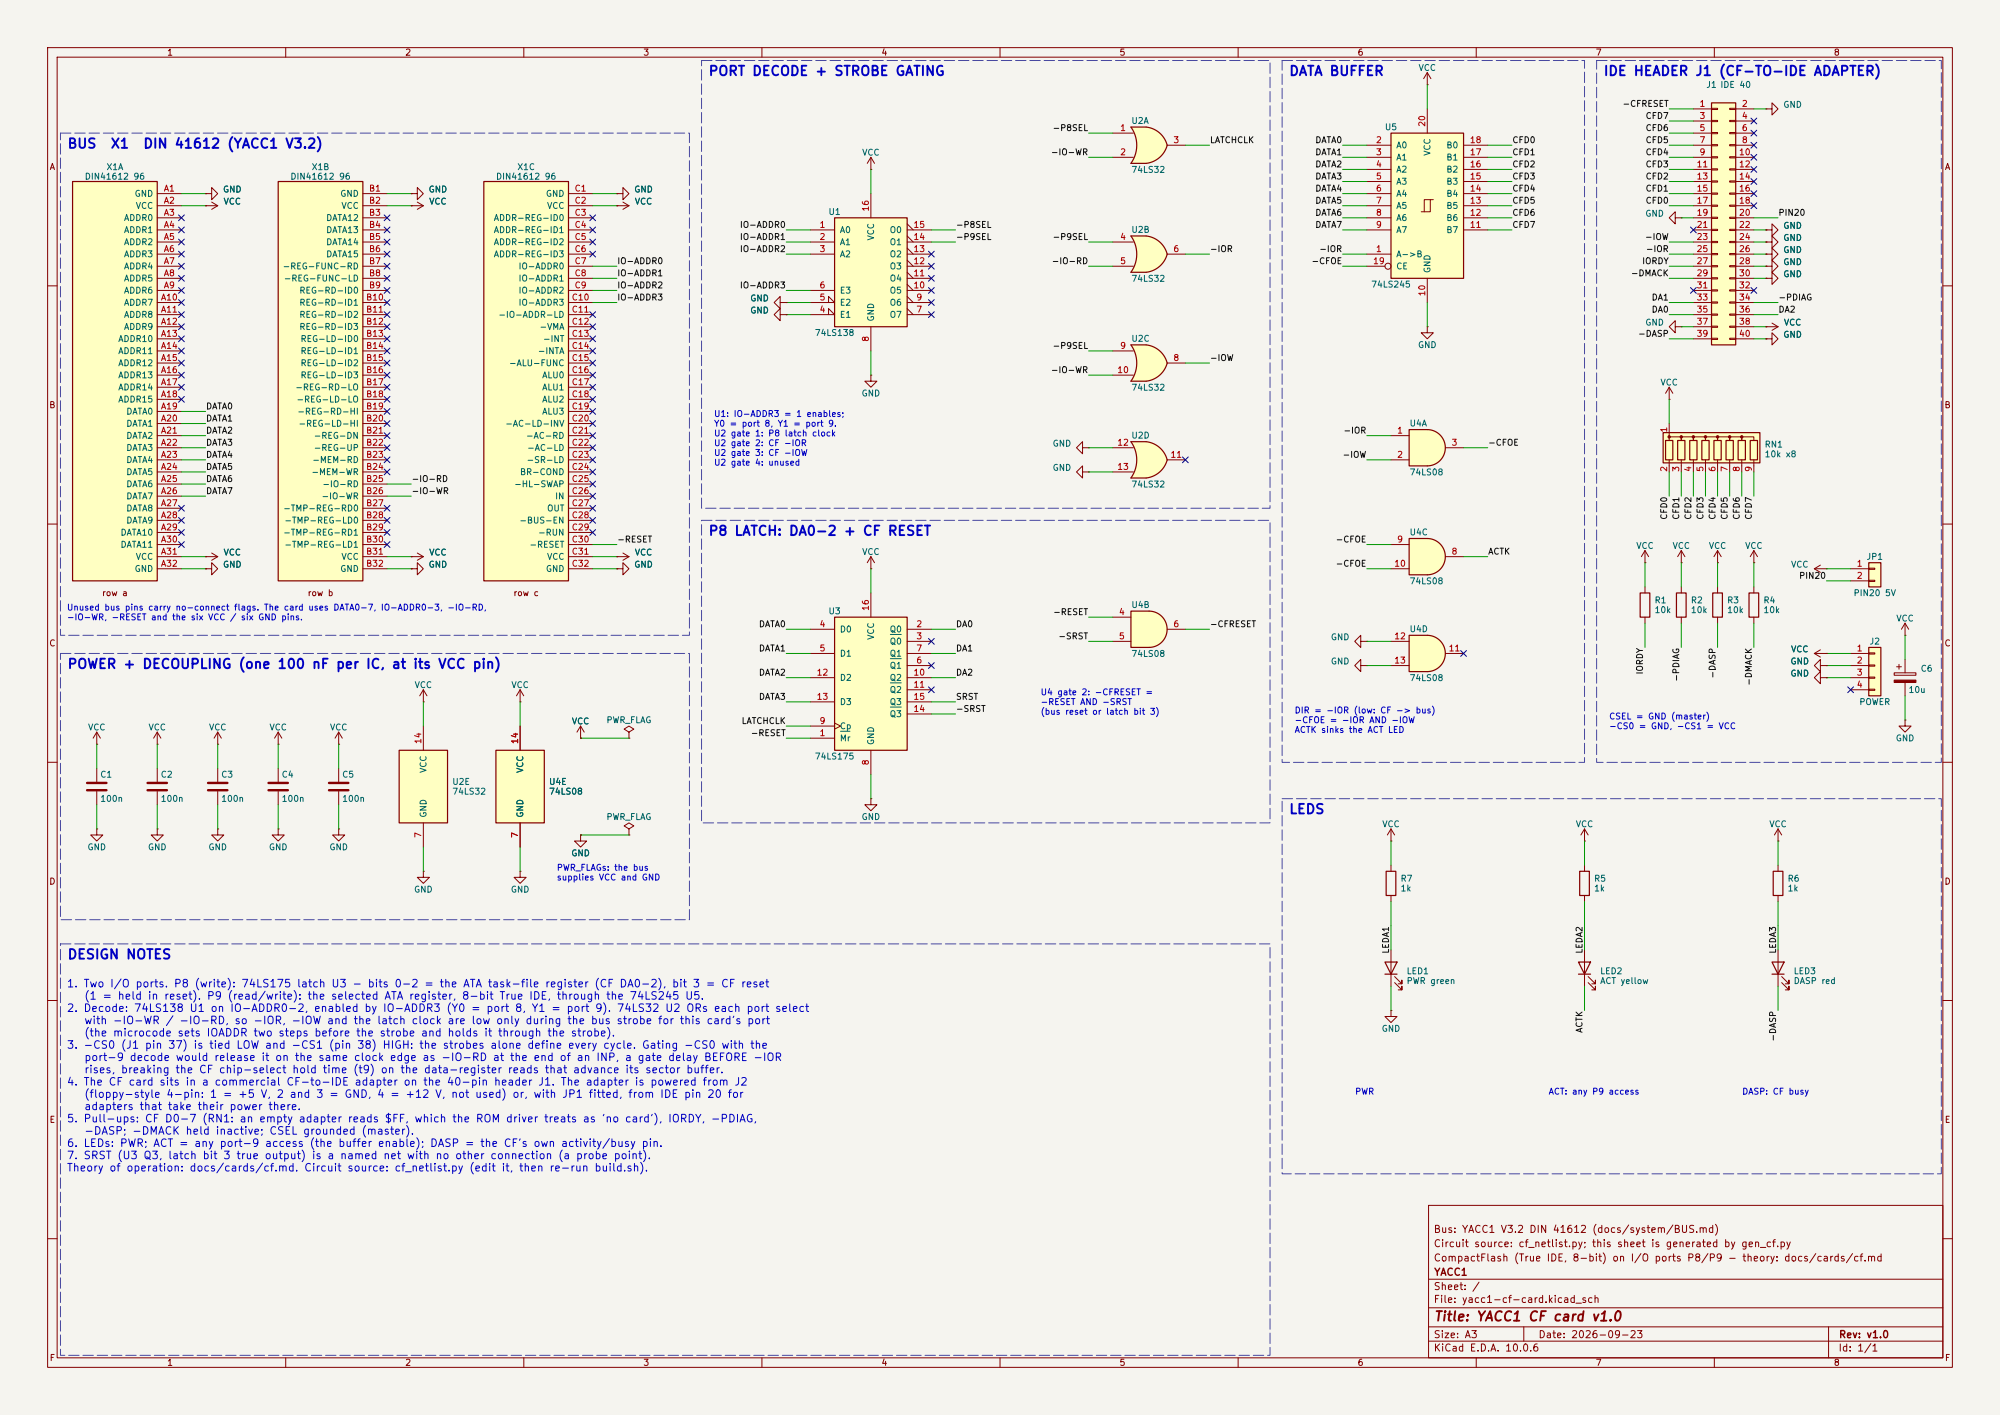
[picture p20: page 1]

U2 gate 4: unused PORT DECODE + STROBE GATING

IDE HEADER J1 (CF-TO-IDE ADAPTER)

CSEL = GND (master) -CS0 = GND, -CS1 = VCC BUS X1 DIN 41612 (YACC1 V3.2)

U1: IO-ADDR3 = 1 enables; Y0 = port 8, Y1 = port 9. U2 gate 1: P8 latch clock U2 gate 2: CF -IOR U2 gate 3: CF -IOW

Unused bus pins carry no-connect flags. The card uses DATA0-7, IO-ADDR0-3, -IO-RD,
-IO-WR, -RESET and the six VCC / six GND pins.

POWER + DECOUPLING (one 100 nF per IC, at its VCC pin)

DIR = -IOR (low: CF -> bus) -CFOE = -IOR AND -IOW

ACTK sinks the ACT LED

LED3 DASP red GND
Theory of operation: docs/cards/cf.md. Circuit source: cf_netlist.py (edit it, then re-run build.sh). PWR_FLAGs: the bus
supplies VCC and GND DESIGN NOTES

1. Two I/O ports. P8 (write): 74LS175 latch U3 - bits 0-2 = the ATA task-file register (CF DA0-2), bit 3 = CF reset
(1 = held in reset). P9 (read/write): the selected ATA register, 8-bit True IDE, through the 74LS245 U5.
2. Decode: 74LS138 U1 on IO-ADDR0-2, enabled by IO-ADDR3 (Y0 = port 8, Y1 = port 9). 74LS32 U2 ORs each port select
with -IO-WR / -IO-RD, so -IOR, -IOW and the latch clock are low only during the bus strobe for this card's port
(the microcode sets IOADDR two steps before the strobe and holds it through the strobe).
3. -CS0 (J1 pin 37) is tied LOW and -CS1 (pin 38) HIGH: the strobes alone define every cycle. Gating -CS0 with the
port-9 decode would release it on the same clock edge as -IO-RD at the end of an INP, a gate delay BEFORE -IOR
rises, breaking the CF chip-select hold time (t9) on the data-register reads that advance its sector buffer.
4. The CF card sits in a commercial CF-to-IDE adapter on the 40-pin header J1. The adapter is powered from J2
(floppy-style 4-pin: 1 = +5 V, 2 and 3 = GND, 4 = +12 V, not used) or, with JP1 fitted, from IDE pin 20 for
adapters that take their power there.
5. Pull-ups: CF D0-7 (RN1: an empty adapter reads $FF, which the ROM driver treats as 'no card'), IORDY, -PDIAG,

-DASP; -DMACK held inactive; CSEL grounded (master).
6. LEDs: PWR; ACT = any port-9 access (the buffer enable); DASP = the CF's own activity/busy pin.
7. SRST (U3 Q3, latch bit 3 true output) is a named net with no other connection (a probe point).

Bus: YACC1 V3.2 DIN 41612 (docs/system/BUS.md)
Circuit source: cf_netlist.py; this sheet is generated by gen_cf.py
CompactFlash (True IDE, 8-bit) on I/O ports P8/P9 - theory: docs/cards/cf.md
YACC1
Sheet: /
File: yacc1-cf-card.kicad_sch
Title: YACC1 CF card v1.0

Size: A3 | Rev: v1.0 | F Date: 2026-09-23
KiCad E.D.A. 10.0.6 | Id: 1/1

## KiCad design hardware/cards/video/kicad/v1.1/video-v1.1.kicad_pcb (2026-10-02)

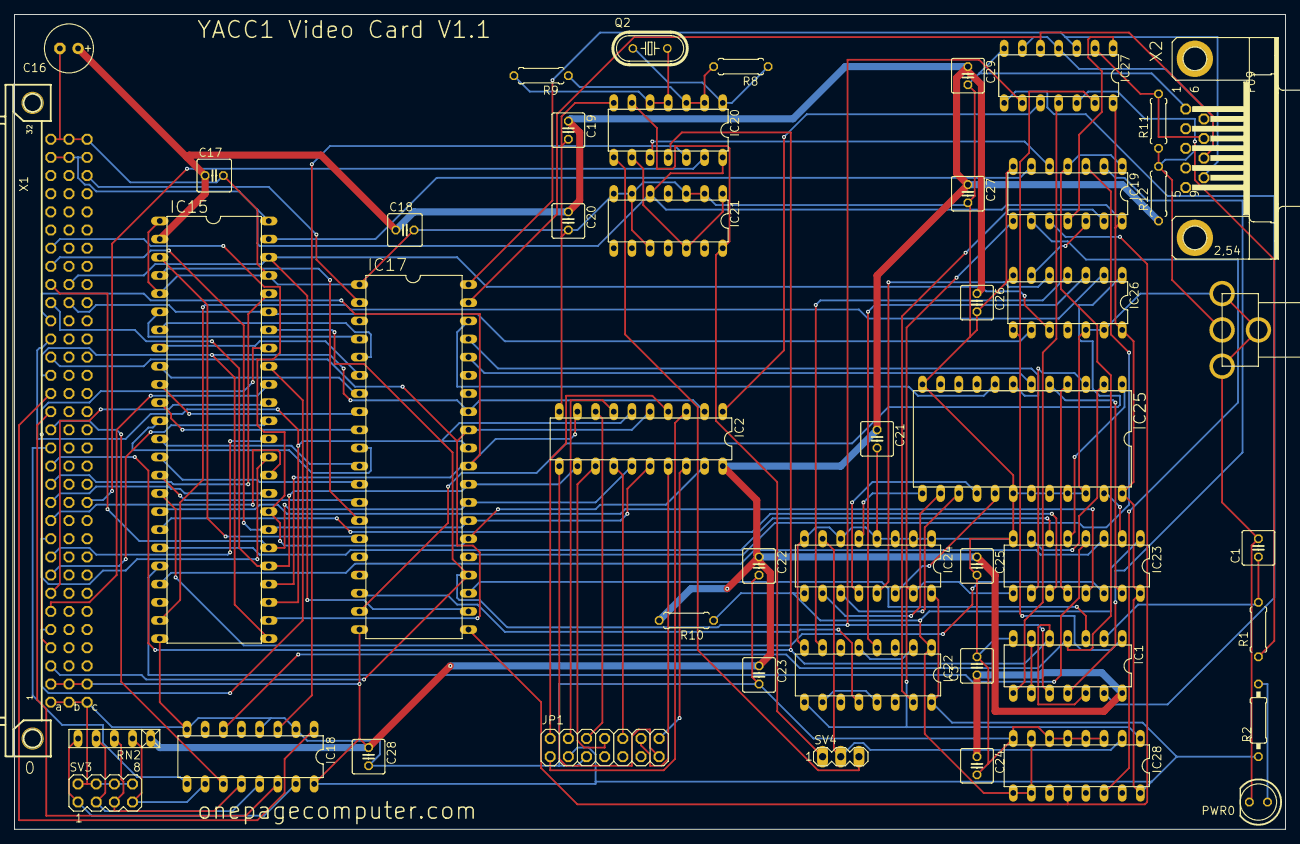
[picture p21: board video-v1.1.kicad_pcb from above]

Board: 2 copper layers, 177.8 x 114.0 mm, 47 parts (0 on the bottom side), 116 nets.

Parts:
C1: 1; C025-050X050
C3, C17, C18, C19, C20, C21, C22, C23, C24, C25, C26, C27, C28, C29: .1; C025-050X050
C16: 10.0; E2,5-7
IC1: 74ALS08N; DIL14
IC2: 74LS373N; DIL20
IC15: VRAM; DIL48
IC17: 6845; DIL40
IC18: 74S85N; DIL16
IC19: 74LS00N; DIL14
IC20: 74LS04N; DIL14
IC21: 74LS90N; DIL14
IC22: 74LS175N; DIL16
IC23: 74LS174N; DIL16
IC24: 74LS166N; DIL16
IC25: CHARGEN; DIL24
IC26: 74LS86N; DIL14
IC27: 7416N; DIL14
IC28: 74HC160N; DIL16
JP1: PINHD-2X7; 2X07
PWR0: LED5MM
Q2: HC49U-V
R1: 10K; 0207_7
R2: 330; 0207_10
R8, R9, R10: 1K; 0207_7
R11: 33; 0207_7
R12: 270; 0207_7
RN2: RN-5
SV3: MA04-2
SV4: MA03-1
U$3: RCA
X1: FABC96R
X2: F09HP

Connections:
-MEM-RD: IC15.43, IC26.9, X1.B23
-MEM-WR: IC15.46, IC17.22, IC26.10, X1.B24
-RESET: IC17.2, X1.C30
-VMA: IC20.13, X1.C12
ADDR0: IC1.10, IC15.42, IC17.24, IC27.9, X1.A3
ADDR1: IC15.41, X1.A4
ADDR2: IC15.40, X1.A5
ADDR3: IC15.39, X1.A6
ADDR4: IC15.38, X1.A7
ADDR5: IC15.37, X1.A8
ADDR6: IC15.36, X1.A9
ADDR7: IC15.35, X1.A10
ADDR8: IC15.34, X1.A11
ADDR9: IC15.33, X1.A12
ADDR10: IC15.44, X1.A13
ADDR11: IC1.5, IC1.12, IC20.11, X1.A14
ADDR12: IC18.9, X1.A15
ADDR13: IC18.11, X1.A16
ADDR14: IC18.14, X1.A17
ADDR15: IC18.1, X1.A18
BOARDSEL: IC1.4, IC18.6, IC19.1, IC19.4
CHARCLOCK: IC19.8, IC22.9, IC23.9, IC24.15, IC28.1
CLK: IC1.3, IC17.23
CRTCCLOCK: IC17.21, IC19.10, IC28.12
DATA0: IC2.2, IC15.25, IC17.33, X1.A19
DATA1: IC2.5, IC15.26, IC17.32, X1.A20
DATA2: IC2.6, IC15.27, IC17.31, X1.A21
DATA3: IC2.9, IC15.28, IC17.30, X1.A22
DATA4: IC2.12, IC15.29, IC17.29, X1.A23
DATA5: IC2.15, IC15.30, IC17.28, X1.A24
DATA6: IC2.16, IC15.31, IC17.27, X1.A25
DATA7: IC2.19, IC15.32, IC17.26, X1.A26
DOTCLOCK: IC24.7, IC28.2, SV4.2
GND: C1.2, C3.2, C16.-, C17.2, C18.2, C19.2, C20.2, C21.2, C22.2, C23.2, C24.2, C25.2, C26.2, C27.2, C28.2, C29.2, IC1.7, IC2.10, IC15.1, IC15.5, IC15.24, IC15.45, IC17.1, IC18.2, IC18.4, IC18.8, IC19.7, IC20.7, IC21.2, IC21.3, IC21.6, IC21.7, IC21.10, IC22.8, IC23.8, IC24.1, IC24.2, IC24.3, IC24.4, IC24.6, IC24.8, IC25.12, IC25.18, IC25.19, IC25.20, IC25.21, IC25.22, IC26.7, IC26.12, IC26.13, IC27.7, IC28.3, IC28.4, IC28.5, IC28.6, IC28.8, JP1.5, PWR0.K, SV3.2, SV3.4, SV3.6, SV3.8, U$3.S1, U$3.S2, U$3.S3, X1.A1, X1.A32, X1.B1, X1.B32, X1.C1, X1.C32, X2.1
unnamed: IC1.1, IC26.8, IC27.13
unnamed: IC1.11, IC19.2
unnamed: IC27.12, R1.1
unnamed: C1.1, IC1.2, R1.2
unnamed: IC1.13, IC27.8
unnamed: IC1.8, IC27.11
unnamed: IC2.18, JP1.14
unnamed: IC2.17, JP1.12
unnamed: IC2.14, JP1.10
unnamed: IC2.13, JP1.8
unnamed: PWR0.A, R2.1
unnamed: IC2.8, JP1.6
unnamed: IC2.7, JP1.4
unnamed: IC2.4, JP1.2
unnamed: IC2.3, JP1.1
unnamed: IC2.1, IC27.10
unnamed: IC1.6, IC1.9
unnamed: IC2.11, JP1.13
unnamed: IC18.10, RN2.2, SV3.7
unnamed: IC18.12, RN2.3, SV3.5
unnamed: IC18.13, RN2.4, SV3.3
unnamed: IC18.15, RN2.5, SV3.1
unnamed: IC15.47, IC19.6
unnamed: IC20.1, Q2.1, R8.1
unnamed: IC20.4, IC20.5, Q2.2, R9.2
unnamed: IC20.2, IC20.3, R8.2, R9.1
unnamed: IC20.6, IC21.14, SV4.1
unnamed: IC20.9, IC21.1, IC21.12
unnamed: IC20.8, SV4.3
unnamed: IC19.9, IC28.14
unnamed: IC22.2, IC22.5
unnamed: IC24.5, IC25.13
unnamed: IC24.10, IC25.14
unnamed: IC24.11, IC25.15
unnamed: IC24.12, IC25.16
unnamed: IC24.14, IC25.17
unnamed: IC23.2, IC25.23
unnamed: IC23.5, IC25.1
unnamed: IC23.7, IC25.2
unnamed: IC23.10, IC25.3
unnamed: IC23.12, IC25.4
unnamed: IC23.15, IC25.5
unnamed: IC22.1, IC23.1, IC24.9, IC28.7, IC28.9, IC28.10, R10.1
unnamed: IC17.19, IC26.1
unnamed: IC22.4, IC26.3
unnamed: IC22.7, IC26.4
unnamed: IC24.13, IC26.5
unnamed: IC22.10, IC22.13
unnamed: IC17.18, IC22.12
unnamed: IC19.12, IC26.6
unnamed: IC19.13, IC22.15
unnamed: IC17.40, IC27.3, X2.9
unnamed: IC17.39, IC27.5, X2.8
unnamed: IC19.11, IC27.1
unnamed: IC27.4, IC27.6, R11.1, R12.2, U$3.C1
unnamed: IC27.2, R11.2, X2.7
unnamed: IC19.5, IC20.10
unnamed: IC18.3, IC20.12
unnamed: IC17.25, IC19.3
VADDR0: IC15.6, IC17.4
VADDR1: IC15.7, IC17.5
VADDR2: IC15.8, IC17.6
VADDR3: IC15.9, IC17.7
VADDR4: IC15.10, IC17.8
VADDR5: IC15.11, IC17.9
VADDR6: IC15.12, IC17.10
VADDR7: IC15.13, IC17.11
VADDR8: IC15.14, IC17.12
VADDR9: IC15.15, IC17.13
VADDR10: IC15.4, IC17.14
VADDR11: IC15.3, IC17.15
VCC: C3.1, C16.+, C17.1, C18.1, C19.1, C20.1, C21.1, C22.1, C23.1, C24.1, C25.1, C26.1, C27.1, C28.1, C29.1, IC1.14, IC2.20, IC15.2, IC15.48, IC17.20, IC18.16, IC19.14, IC20.14, IC21.5, IC22.16, IC23.16, IC24.16, IC25.24, IC26.14, IC27.14, IC28.16, JP1.3, R2.2, R10.2, R12.1, RN2.1, X1.A2, X1.A31, X1.B2, X1.B31, X1.C2, X1.C31
VDATA0: IC15.16, IC23.14
VDATA1: IC15.17, IC23.13
VDATA2: IC15.18, IC23.11
VDATA3: IC15.19, IC23.6
VDATA4: IC15.20, IC23.4
VDATA5: IC15.21, IC23.3
VDATA7: IC15.23, IC26.2
VROWS0: IC17.38, IC25.8
VROWS1: IC17.37, IC25.7
VROWS2: IC17.36, IC25.6

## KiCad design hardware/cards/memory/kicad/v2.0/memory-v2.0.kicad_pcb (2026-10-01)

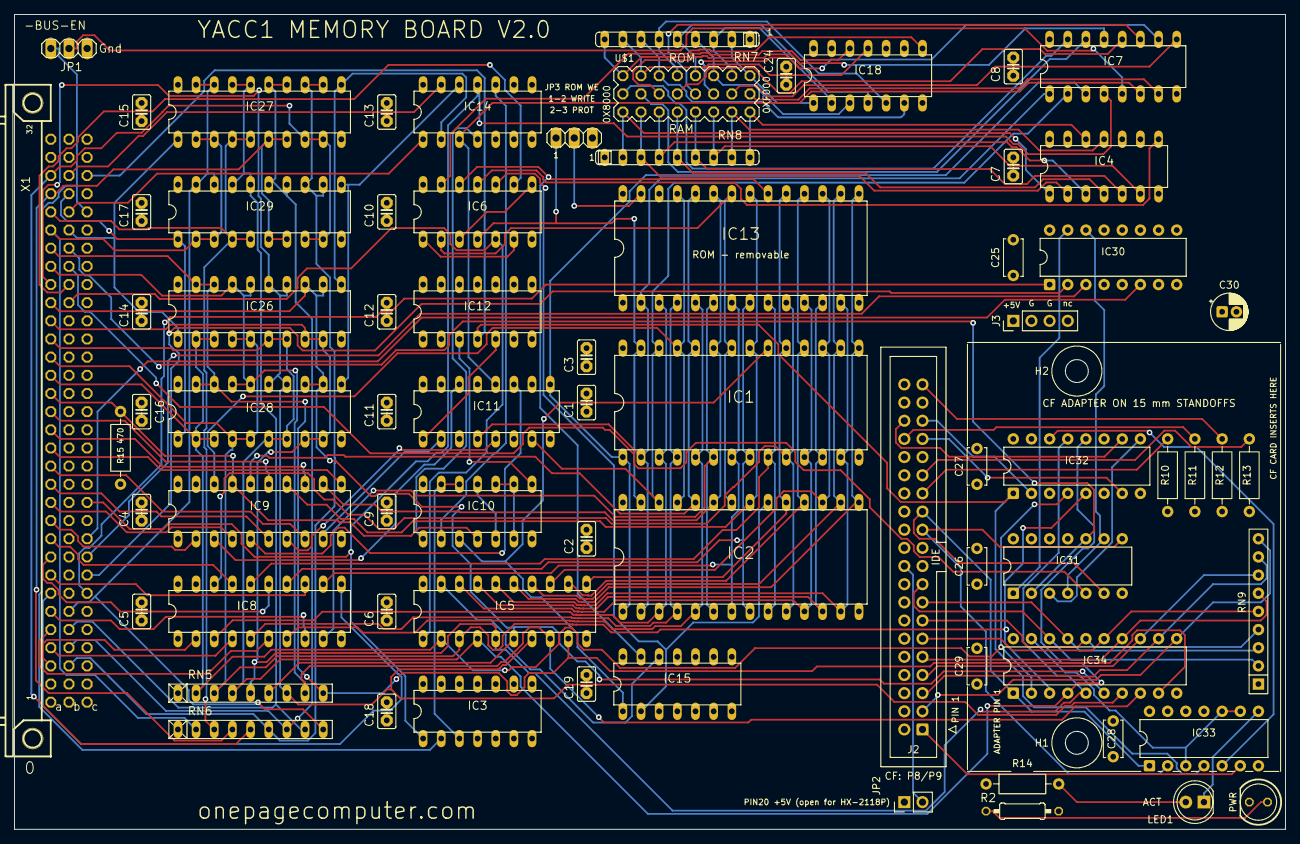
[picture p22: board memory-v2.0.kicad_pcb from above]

Board: 4 copper layers, 177.8 x 114.0 mm, 74 parts (0 on the bottom side), 149 nets.

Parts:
C1, C2, C3, C4, C5, C6, C7, C8, C9, C10, C11, C12, C13, C14, C15, C16, C17, C18, C19, C24: C025-025X050
C25, C26, C27, C28, C29: 100n; C_Disc_D5.0mm_W2.5mm_P5.00mm
C30: 10u; CP_Radial_D5.0mm_P2.00mm
H1, H2: M3 standoff 15 mm (CF adapter); MountingHole_3.2mm_M3
IC1, IC2, IC13: DIL28-6
IC3: 74LS32N; DIL14
IC4, IC18: 74ALS30N; DIL14
IC5: 74LS245N; DIL20
IC6, IC14: 74LS04N; DIL14
IC7: 74LS138N; DIL16
IC8, IC9: 74LS244N; DIL20
IC10: 74ALS00N; DIL14
IC11: 74LS157N; DIL16
IC12: 74LS74N; DIL14
IC15: 74ALS11N; DIL14
IC26, IC27, IC28, IC29: 74LS374N; DIL20
IC30: 74LS138; DIP-16_W7.62mm
IC31: 74LS32; DIP-14_W7.62mm
IC32: 74LS175; DIP-16_W7.62mm
IC33: 74LS08; DIP-14_W7.62mm
IC34: 74LS245; DIP-20_W7.62mm
J2: IDE 40; IDC-Header_2x20_P2.54mm_Vertical
J3: POWER; PinHeader_1x04_P2.54mm_Vertical
JP1: 1X03
JP2: PIN20 5V; PinHeader_1x02_P2.54mm_Vertical
JP3: PINHD-1X3; 1X03
LED1: ACT yellow; LED_D5.0mm
PWR0: LED5MM
R2: 330; 0207_10
R10, R11, R12, R13: 10k; R_Axial_DIN0207_L6.3mm_D2.5mm_P10.16mm_Horizontal
R14: 1k; R_Axial_DIN0207_L6.3mm_D2.5mm_P10.16mm_Horizontal
R15: 470; R_Axial_DIN0207_L6.3mm_D2.5mm_P10.16mm_Horizontal
RN5, RN6: RN-9
RN7, RN8: SIL9
RN9: 10k x8; R_Array_SIP9
U$1: PIN_3X8
X1: FABC96R

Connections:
-BUS-EN: IC3.2, JP1.1, X1.C28
-HI-RAM: IC2.20, IC6.10, IC15.2
-IO-RD: IC31.5, X1.B25
-IO-WR: IC31.2, IC31.10, X1.B26
-LO-RAM: IC1.20, IC10.3, IC15.1
-MEM-RD: IC5.1, IC6.5, X1.B23
-MEM-WR: IC6.9, X1.B24
-RESET: IC12.4, IC32.1, IC33.4, X1.C30
-ROM-CS: IC6.12, IC13.20, IC15.13
-TMP-REG-LD0: IC14.1, X1.B28
-TMP-REG-LD1: IC14.13, X1.B30
-TMP-REG-RD0: IC26.1, IC27.1, X1.B27
-TMP-REG-RD1: IC28.1, IC29.1, X1.B29
-VMA: IC3.1, IC7.4, IC14.11, X1.C12
/Sheet 2/RAM0: IC4.1, RN8.2, U$1.17
/Sheet 2/RAM1: IC4.2, RN8.3, U$1.18
/Sheet 2/RAM2: IC4.3, RN8.4, U$1.19
/Sheet 2/RAM3: IC4.4, RN8.5, U$1.20
/Sheet 2/RAM4: IC4.5, RN8.6, U$1.21
/Sheet 2/RAM5: IC4.6, RN8.7, U$1.22
/Sheet 2/RAM6: IC4.11, RN8.8, U$1.23
/Sheet 2/RAM7: IC4.12, RN8.9, U$1.24
/Sheet 2/ROM0: IC18.12, RN7.9, U$1.1
/Sheet 2/ROM1: IC18.11, RN7.8, U$1.2
/Sheet 2/ROM2: IC18.6, RN7.7, U$1.3
/Sheet 2/ROM3: IC18.5, RN7.6, U$1.4
/Sheet 2/ROM4: IC18.4, RN7.5, U$1.5
/Sheet 2/ROM5: IC18.3, RN7.4, U$1.6
/Sheet 2/ROM6: IC18.2, RN7.3, U$1.7
/Sheet 2/ROM7: IC18.1, RN7.2, U$1.8
/Sheet 2/SEL0: IC7.15, U$1.9
/Sheet 2/SEL1: IC7.14, U$1.10
/Sheet 2/SEL2: IC7.13, U$1.11
/Sheet 2/SEL3: IC7.12, U$1.12
/Sheet 2/SEL4: IC7.11, U$1.13
/Sheet 2/SEL5: IC7.10, U$1.14
/Sheet 2/SEL6: IC7.9, U$1.15
/Sheet 2/SEL7: IC7.7, U$1.16
/Sheet 3/ROM-WE: IC13.27, JP3.2
/Sheet 7/-CFOE: IC33.3, IC33.9, IC33.10, IC34.19
/Sheet 7/-CFRESET: IC33.6, J2.1
/Sheet 7/-DASP: J2.39, R12.2
/Sheet 7/-DMACK: J2.29, R13.2
/Sheet 7/-IOR: IC31.6, IC33.1, IC34.1, J2.25
/Sheet 7/-IOW: IC31.8, IC33.2, J2.23
/Sheet 7/-P8SEL: IC30.15, IC31.1
/Sheet 7/-P9SEL: IC30.14, IC31.4, IC31.9
/Sheet 7/-PDIAG: J2.34, R11.2
/Sheet 7/-SRST: IC32.14, IC33.5
/Sheet 7/ACTK: IC33.8, LED1.1
/Sheet 7/CFD0: IC34.18, J2.17, RN9.2
/Sheet 7/CFD1: IC34.17, J2.15, RN9.3
/Sheet 7/CFD2: IC34.16, J2.13, RN9.4
/Sheet 7/CFD3: IC34.15, J2.11, RN9.5
/Sheet 7/CFD4: IC34.14, J2.9, RN9.6
/Sheet 7/CFD5: IC34.13, J2.7, RN9.7
/Sheet 7/CFD6: IC34.12, J2.5, RN9.8
/Sheet 7/CFD7: IC34.11, J2.3, RN9.9
/Sheet 7/DA0: IC32.2, J2.35
/Sheet 7/DA1: IC32.7, J2.33
/Sheet 7/DA2: IC32.10, J2.36
/Sheet 7/IORDY: J2.27, R10.2
/Sheet 7/LATCHCLK: IC31.3, IC32.9
/Sheet 7/LEDA2: LED1.2, R14.2
/Sheet 7/PIN20: J2.20, JP2.2
ADDR0: IC8.2, X1.A3
ADDR1: IC8.4, X1.A4
ADDR2: IC8.6, X1.A5
ADDR3: IC8.8, X1.A6
ADDR4: IC8.11, X1.A7
ADDR5: IC8.13, X1.A8
ADDR6: IC8.15, X1.A9
ADDR7: IC8.17, X1.A10
ADDR8: IC9.2, X1.A11
ADDR9: IC9.4, X1.A12
ADDR10: IC9.6, X1.A13
ADDR11: IC9.8, X1.A14
ADDR12: IC9.11, X1.A15
ADDR13: IC9.13, X1.A16
ADDR14: IC9.15, X1.A17
ADDR15: IC9.17, IC10.4, R15.1, X1.A18
BADDR0: IC1.10, IC2.10, IC8.18, IC13.10
BADDR1: IC1.9, IC2.9, IC8.16, IC13.9
BADDR2: IC1.8, IC2.8, IC8.14, IC13.8
BADDR3: IC1.7, IC2.7, IC8.12, IC13.7
BADDR4: IC1.6, IC2.6, IC8.9, IC13.6
BADDR5: IC1.5, IC2.5, IC8.7, IC13.5
BADDR6: IC1.4, IC2.4, IC8.5, IC13.4
BADDR7: IC1.3, IC2.3, IC8.3, IC13.3
BADDR8: IC1.25, IC2.25, IC9.18, IC13.25
BADDR9: IC1.24, IC2.24, IC9.16, IC13.24
BADDR10: IC1.21, IC2.21, IC9.14, IC13.21
BADDR11: IC1.23, IC2.23, IC9.12, IC13.23
BADDR12: IC1.2, IC2.2, IC7.1, IC11.4, IC13.2
BADDR13: IC1.26, IC2.26, IC7.2, IC11.7
BADDR14: IC1.1, IC2.1, IC7.3, IC11.9
BADDR15: IC7.6, IC11.12, IC14.3
BDATA0: IC1.11, IC2.11, IC5.18, IC13.11
BDATA1: IC1.12, IC2.12, IC5.17, IC13.12
BDATA2: IC1.13, IC2.13, IC5.16, IC13.13
BDATA3: IC1.15, IC2.15, IC5.15, IC13.15
BDATA4: IC1.16, IC2.16, IC5.14, IC13.16
BDATA5: IC1.17, IC2.17, IC5.13, IC13.17
BDATA6: IC1.18, IC2.18, IC5.12, IC13.18
BDATA7: IC1.19, IC2.19, IC5.11, IC13.19
DATA0: IC5.2, IC26.2, IC26.3, IC28.2, IC28.3, IC32.4, IC34.2, RN5.2, X1.A19
DATA1: IC5.3, IC26.4, IC26.5, IC28.4, IC28.5, IC32.5, IC34.3, RN5.3, X1.A20
DATA2: IC5.4, IC26.6, IC26.7, IC28.6, IC28.7, IC32.12, IC34.4, RN5.4, X1.A21
DATA3: IC5.5, IC26.8, IC26.9, IC28.8, IC28.9, IC32.13, IC34.5, RN5.5, X1.A22
DATA4: IC5.6, IC26.12, IC26.13, IC28.12, IC28.13, IC34.6, RN5.6, X1.A23
DATA5: IC5.7, IC26.14, IC26.15, IC28.14, IC28.15, IC34.7, RN5.7, X1.A24
DATA6: IC5.8, IC26.16, IC26.17, IC28.16, IC28.17, IC34.8, RN5.8, X1.A25
DATA7: IC5.9, IC26.18, IC26.19, IC28.18, IC28.19, IC34.9, RN5.9, X1.A26
DATA8: IC27.2, IC27.3, IC29.2, IC29.3, RN6.2, X1.A27
DATA9: IC27.4, IC27.5, IC29.4, IC29.5, RN6.3, X1.A28
DATA10: IC27.6, IC27.7, IC29.6, IC29.7, RN6.4, X1.A29
DATA11: IC27.8, IC27.9, IC29.8, IC29.9, RN6.5, X1.A30
DATA12: IC27.12, IC27.13, IC29.12, IC29.13, RN6.6, X1.B3
DATA13: IC27.14, IC27.15, IC29.14, IC29.15, RN6.7, X1.B4
DATA14: IC27.16, IC27.17, IC29.16, IC29.17, RN6.8, X1.B5
DATA15: IC27.18, IC27.19, IC29.18, IC29.19, RN6.9, X1.B6
FORCE-ROM: IC11.1, IC12.5
GND: C1.2, C2.2, C3.2, C4.2, C5.2, C6.2, C7.2, C8.2, C9.2, C10.2, C11.2, C12.2, C13.2, C14.2, C15.2, C16.2, C17.2, C18.2, C19.1, C24.1, C25.2, C26.2, C27.2, C28.2, C29.2, C30.2, IC1.14, IC2.14, IC3.4, IC3.5, IC3.7, IC3.9, IC3.10, IC3.12, IC3.13, IC4.7, IC5.10, IC6.7, IC7.8, IC8.1, IC8.10, IC8.19, IC9.1, IC9.10, IC9.19, IC10.7, IC11.8, IC11.15, IC12.2, IC12.7, IC12.10, IC12.11, IC12.12, IC12.13, IC13.14, IC14.7, IC15.3, IC15.4, IC15.5, IC15.7, IC15.9, IC15.10, IC15.11, IC18.7, IC26.10, IC27.10, IC28.10, IC29.10, IC30.4, IC30.5, IC30.8, IC31.7, IC31.12, IC31.13, IC32.8, IC33.7, IC33.12, IC33.13, IC34.10, J2.2, J2.19, J2.22, J2.24, J2.26, J2.28, J2.30, J2.37, J2.40, J3.2, J3.3, JP1.3, PWR0.K, R15.2, RN5.1, RN6.1, X1.A1, X1.A32, X1.B1, X1.B32, X1.C1, X1.C32
IO-ADDR0: IC30.1, X1.C7
IO-ADDR1: IC30.2, X1.C8
IO-ADDR2: IC30.3, X1.C9
IO-ADDR3: IC30.6, X1.C10
unnamed: IC1.22, IC2.22, IC6.2, IC13.22
unnamed: IC1.27, IC2.27, IC6.4, JP3.1
unnamed: IC4.8, IC6.11
unnamed: IC6.1, IC6.6
unnamed: IC6.3, IC6.8
unnamed: IC7.5, JP1.2
unnamed: IC10.1, IC14.4
unnamed: IC10.2, IC14.10
unnamed: IC10.5, IC10.11
unnamed: IC10.6, IC10.9, IC10.10
unnamed: IC10.8, IC12.3
unnamed: IC3.3, IC10.12, IC10.13
unnamed: IC9.9, IC11.2
unnamed: IC9.7, IC11.5
unnamed: IC9.5, IC11.11
unnamed: IC9.3, IC11.14
unnamed: IC14.2, IC26.11, IC27.11
unnamed: IC14.12, IC28.11, IC29.11
unnamed: IC5.19, IC15.12
unnamed: IC6.13, IC18.8
unnamed: PWR0.A, R2.1
VCC: C1.1, C2.1, C3.1, C4.1, C5.1, C6.1, C7.1, C8.1, C9.1, C10.1, C11.1, C12.1, C13.1, C14.1, C15.1, C16.1, C17.1, C18.1, C19.2, C24.2, C25.1, C26.1, C27.1, C28.1, C29.1, C30.1, IC1.28, IC2.28, IC3.14, IC4.14, IC5.20, IC6.14, IC7.16, IC8.20, IC9.20, IC10.14, IC11.3, IC11.6, IC11.10, IC11.13, IC11.16, IC12.1, IC12.14, IC13.28, IC14.14, IC15.14, IC18.14, IC26.20, IC27.20, IC28.20, IC29.20, IC30.16, IC31.14, IC32.16, IC33.14, IC34.20, J2.38, J3.1, JP2.1, JP3.3, R2.2, R10.1, R11.1, R12.1, R13.1, R14.1, RN7.1, RN8.1, RN9.1, X1.A2, X1.A31, X1.B2, X1.B31, X1.C2, X1.C31

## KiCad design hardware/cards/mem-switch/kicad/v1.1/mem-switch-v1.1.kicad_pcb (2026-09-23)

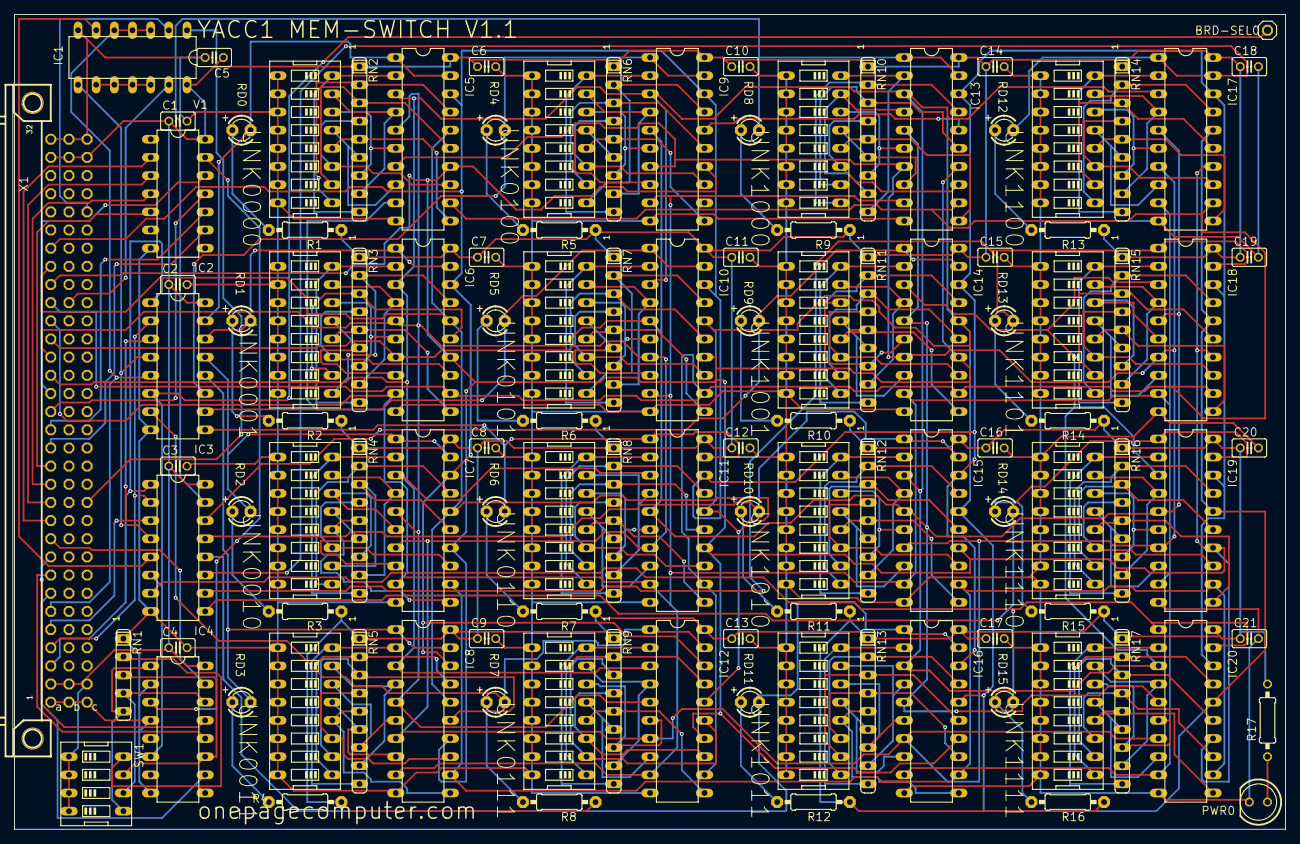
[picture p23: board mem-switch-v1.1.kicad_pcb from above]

Board: 2 copper layers, 177.8 x 114.0 mm, 112 parts (0 on the bottom side), 199 nets.

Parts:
BRD-SEL0: PINHD-1X1; 1X01
C1, C2, C3, C4, C5, C6, C7, C8, C9, C10, C11, C12, C13, C14, C15, C16, C17, C18, C19, C20, C21: C025-025X050
IC1: 74ALS27N; DIL14
IC2, IC3: 74LS138N; DIL16
IC4: 74LS85N; DIL16
IC5, IC6, IC7, IC8, IC9, IC10, IC11, IC12, IC13, IC14, IC15, IC16, IC17, IC18, IC19, IC20: 74LS244N; DIL20
PWR0: LED5MM
R1, R2, R3, R4, R5, R6, R7, R8, R9, R10, R11, R12, R13, R14, R15, R16: 0207_10
R17: 330; 0207_10
RD0, RD1, RD2, RD3, RD4, RD5, RD6, RD7, RD8, RD9, RD10, RD11, RD12, RD13, RD14, RD15: LED3MM
RN1: SIL5
RN2, RN3, RN4, RN5, RN6, RN7, RN8, RN9, RN10, RN11, RN12, RN13, RN14, RN15, RN16, RN17: SIL9
SW1: EDG-04
UNK0000, UNK0001, UNK0010, UNK0011, UNK0100, UNK0101, UNK0110, UNK0111, UNK1000, UNK1001, UNK1010, UNK1011, UNK1100, UNK1101, UNK1110, UNK1111: EDG-08
V1: 744078N; DIL14
X1: FABC96R

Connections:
-BUS-EN: IC1.2, X1.C28
-MEM-RD: IC1.13, X1.B23
-VMA: IC1.1, X1.C12
ADDR0: IC2.1, IC3.1, X1.A3
ADDR1: IC2.2, IC3.2, X1.A4
ADDR2: IC2.3, IC3.3, X1.A5
ADDR3: IC1.3, IC1.4, IC1.5, IC2.5, X1.A6
ADDR4: IC4.10, X1.A7
ADDR5: IC4.12, X1.A8
ADDR6: IC4.13, X1.A9
ADDR7: IC4.15, X1.A10
ADDR8: V1.2, X1.A11
ADDR9: V1.3, X1.A12
ADDR10: V1.4, X1.A13
ADDR11: V1.5, X1.A14
ADDR12: V1.9, X1.A15
ADDR13: V1.10, X1.A16
ADDR14: V1.11, X1.A17
ADDR15: V1.12, X1.A18
DATA0: IC5.3, IC6.3, IC7.3, IC8.3, IC9.3, IC10.3, IC11.3, IC12.3, IC13.3, IC14.3, IC15.3, IC16.3, IC17.3, IC18.3, IC19.3, IC20.3, X1.A19
DATA1: IC5.5, IC6.5, IC7.5, IC8.5, IC9.5, IC10.5, IC11.5, IC12.5, IC13.5, IC14.5, IC15.5, IC16.5, IC17.5, IC18.5, IC19.5, IC20.5, X1.A20
DATA2: IC5.7, IC6.7, IC7.7, IC8.7, IC9.7, IC10.7, IC11.7, IC12.7, IC13.7, IC14.7, IC15.7, IC16.7, IC17.7, IC18.7, IC19.7, IC20.7, X1.A21
DATA3: IC5.9, IC6.9, IC7.9, IC8.9, IC9.9, IC10.9, IC11.9, IC12.9, IC13.9, IC14.9, IC15.9, IC16.9, IC17.9, IC18.9, IC19.9, IC20.9, X1.A22
DATA4: IC5.12, IC6.12, IC7.12, IC8.12, IC9.12, IC10.12, IC11.12, IC12.12, IC13.12, IC14.12, IC15.12, IC16.12, IC17.12, IC18.12, IC19.12, IC20.12, X1.A23
DATA5: IC5.14, IC6.14, IC7.14, IC8.14, IC9.14, IC10.14, IC11.14, IC12.14, IC13.14, IC14.14, IC15.14, IC16.14, IC17.14, IC18.14, IC19.14, IC20.14, X1.A24
DATA6: IC5.16, IC6.16, IC7.16, IC8.16, IC9.16, IC10.16, IC11.16, IC12.16, IC13.16, IC14.16, IC15.16, IC16.16, IC17.16, IC18.16, IC19.16, IC20.16, X1.A25
DATA7: IC5.18, IC6.18, IC7.18, IC8.18, IC9.18, IC10.18, IC11.18, IC12.18, IC13.18, IC14.18, IC15.18, IC16.18, IC17.18, IC18.18, IC19.18, IC20.18, X1.A26
GND: C1.2, C2.2, C3.2, C4.2, C5.2, C6.2, C7.2, C8.2, C9.2, C10.2, C11.2, C12.2, C13.2, C14.2, C15.2, C16.2, C17.2, C18.2, C19.2, C20.2, C21.2, IC1.7, IC2.8, IC3.8, IC4.2, IC4.4, IC4.8, IC5.10, IC6.10, IC7.10, IC8.10, IC9.10, IC10.10, IC11.10, IC12.10, IC13.10, IC14.10, IC15.10, IC16.10, IC17.10, IC18.10, IC19.10, IC20.10, PWR0.K, RN1.1, UNK0000.9, UNK0000.10, UNK0000.11, UNK0000.12, UNK0000.13, UNK0000.14, UNK0000.15, UNK0000.16, UNK0001.9, UNK0001.10, UNK0001.11, UNK0001.12, UNK0001.13, UNK0001.14, UNK0001.15, UNK0001.16, UNK0010.9, UNK0010.10, UNK0010.11, UNK0010.12, UNK0010.13, UNK0010.14, UNK0010.15, UNK0010.16, UNK0011.9, UNK0011.10, UNK0011.11, UNK0011.12, UNK0011.13, UNK0011.14, UNK0011.15, UNK0011.16, UNK0100.9, UNK0100.10, UNK0100.11, UNK0100.12, UNK0100.13, UNK0100.14, UNK0100.15, UNK0100.16, UNK0101.9, UNK0101.10, UNK0101.11, UNK0101.12, UNK0101.13, UNK0101.14, UNK0101.15, UNK0101.16, UNK0110.9, UNK0110.10, UNK0110.11, UNK0110.12, UNK0110.13, UNK0110.14, UNK0110.15, UNK0110.16, UNK0111.9, UNK0111.10, UNK0111.11, UNK0111.12, UNK0111.13, UNK0111.14, UNK0111.15, UNK0111.16, UNK1000.9, UNK1000.10, UNK1000.11, UNK1000.12, UNK1000.13, UNK1000.14, UNK1000.15, UNK1000.16, UNK1001.9, UNK1001.10, UNK1001.11, UNK1001.12, UNK1001.13, UNK1001.14, UNK1001.15, UNK1001.16, UNK1010.9, UNK1010.10, UNK1010.11, UNK1010.12, UNK1010.13, UNK1010.14, UNK1010.15, UNK1010.16, UNK1011.9, UNK1011.10, UNK1011.11, UNK1011.12, UNK1011.13, UNK1011.14, UNK1011.15, UNK1011.16, UNK1100.9, UNK1100.10, UNK1100.11, UNK1100.12, UNK1100.13, UNK1100.14, UNK1100.15, UNK1100.16, UNK1101.9, UNK1101.10, UNK1101.11, UNK1101.12, UNK1101.13, UNK1101.14, UNK1101.15, UNK1101.16, UNK1110.9, UNK1110.10, UNK1110.11, UNK1110.12, UNK1110.13, UNK1110.14, UNK1110.15, UNK1110.16, UNK1111.9, UNK1111.10, UNK1111.11, UNK1111.12, UNK1111.13, UNK1111.14, UNK1111.15, UNK1111.16, V1.7, X1.A1, X1.A32, X1.B1, X1.B32, X1.C1, X1.C32
unnamed: IC5.17, RN2.2, UNK0000.1
unnamed: IC5.15, RN2.3, UNK0000.2
unnamed: IC5.13, RN2.4, UNK0000.3
unnamed: IC5.11, RN2.5, UNK0000.4
unnamed: IC5.8, RN2.6, UNK0000.5
unnamed: BRD-SEL0.1, IC2.6, IC3.6, IC4.6
unnamed: IC5.6, RN2.7, UNK0000.6
unnamed: IC5.4, RN2.8, UNK0000.7
unnamed: IC5.2, RN2.9, UNK0000.8
unnamed: IC6.17, RN3.2, UNK0001.1
unnamed: PWR0.A, R17.1
unnamed: IC6.15, RN3.3, UNK0001.2
unnamed: IC6.13, RN3.4, UNK0001.3
unnamed: IC6.11, RN3.5, UNK0001.4
unnamed: IC6.8, RN3.6, UNK0001.5
unnamed: IC6.6, RN3.7, UNK0001.6
unnamed: IC6.4, RN3.8, UNK0001.7
unnamed: IC6.2, RN3.9, UNK0001.8
unnamed: IC1.9, IC1.10, IC1.11, IC1.12
unnamed: IC7.17, RN4.2, UNK0010.1
unnamed: IC7.15, RN4.3, UNK0010.2
unnamed: IC7.13, RN4.4, UNK0010.3
unnamed: IC7.11, RN4.5, UNK0010.4
unnamed: IC7.8, RN4.6, UNK0010.5
unnamed: IC7.6, RN4.7, UNK0010.6
unnamed: IC7.4, RN4.8, UNK0010.7
unnamed: IC7.2, RN4.9, UNK0010.8
unnamed: IC4.9, RN1.2, SW1.8
unnamed: IC8.17, RN5.2, UNK0011.1
unnamed: IC8.15, RN5.3, UNK0011.2
unnamed: IC8.13, RN5.4, UNK0011.3
unnamed: IC8.11, RN5.5, UNK0011.4
unnamed: IC8.8, RN5.6, UNK0011.5
unnamed: IC8.6, RN5.7, UNK0011.6
unnamed: IC8.4, RN5.8, UNK0011.7
unnamed: IC8.2, RN5.9, UNK0011.8
unnamed: IC1.6, IC3.5
unnamed: IC9.17, RN6.2, UNK0100.1
unnamed: IC9.15, RN6.3, UNK0100.2
unnamed: IC9.13, RN6.4, UNK0100.3
unnamed: IC9.11, RN6.5, UNK0100.4
unnamed: IC9.8, RN6.6, UNK0100.5
unnamed: IC9.6, RN6.7, UNK0100.6
unnamed: IC9.4, RN6.8, UNK0100.7
unnamed: IC9.2, RN6.9, UNK0100.8
unnamed: IC4.11, RN1.3, SW1.7
unnamed: IC10.17, RN7.2, UNK0101.1
unnamed: IC10.15, RN7.3, UNK0101.2
unnamed: IC10.13, RN7.4, UNK0101.3
unnamed: IC10.11, RN7.5, UNK0101.4
unnamed: IC10.8, RN7.6, UNK0101.5
unnamed: IC10.6, RN7.7, UNK0101.6
unnamed: IC10.4, RN7.8, UNK0101.7
unnamed: IC10.2, RN7.9, UNK0101.8
unnamed: IC4.3, V1.13
unnamed: IC11.17, RN8.2, UNK0110.1
unnamed: IC11.15, RN8.3, UNK0110.2
unnamed: IC11.13, RN8.4, UNK0110.3
unnamed: IC11.11, RN8.5, UNK0110.4
unnamed: IC11.8, RN8.6, UNK0110.5
unnamed: IC11.6, RN8.7, UNK0110.6
unnamed: IC11.4, RN8.8, UNK0110.7
unnamed: IC11.2, RN8.9, UNK0110.8
unnamed: IC4.14, RN1.4, SW1.6
unnamed: IC12.17, RN9.2, UNK0111.1
unnamed: IC12.15, RN9.3, UNK0111.2
unnamed: IC12.13, RN9.4, UNK0111.3
unnamed: IC12.11, RN9.5, UNK0111.4
unnamed: IC12.8, RN9.6, UNK0111.5
unnamed: IC12.6, RN9.7, UNK0111.6
unnamed: IC12.4, RN9.8, UNK0111.7
unnamed: IC12.2, RN9.9, UNK0111.8
unnamed: IC4.1, RN1.5, SW1.5
unnamed: IC13.17, RN10.2, UNK1000.1
unnamed: IC13.15, RN10.3, UNK1000.2
unnamed: IC13.13, RN10.4, UNK1000.3
unnamed: IC13.11, RN10.5, UNK1000.4
unnamed: IC13.8, RN10.6, UNK1000.5
unnamed: IC13.6, RN10.7, UNK1000.6
unnamed: IC13.4, RN10.8, UNK1000.7
unnamed: IC13.2, RN10.9, UNK1000.8
unnamed: IC1.8, IC2.4, IC3.4
unnamed: IC14.17, RN11.2, UNK1001.1
unnamed: IC14.15, RN11.3, UNK1001.2
unnamed: IC14.13, RN11.4, UNK1001.3
unnamed: IC14.11, RN11.5, UNK1001.4
unnamed: IC14.8, RN11.6, UNK1001.5
unnamed: IC14.6, RN11.7, UNK1001.6
unnamed: IC14.4, RN11.8, UNK1001.7
unnamed: IC14.2, RN11.9, UNK1001.8
unnamed: R1.2, RD0.A
unnamed: IC15.17, RN12.2, UNK1010.1
unnamed: IC15.15, RN12.3, UNK1010.2
unnamed: IC15.13, RN12.4, UNK1010.3
unnamed: IC15.11, RN12.5, UNK1010.4
unnamed: IC15.8, RN12.6, UNK1010.5
unnamed: IC15.6, RN12.7, UNK1010.6
unnamed: IC15.4, RN12.8, UNK1010.7
unnamed: IC15.2, RN12.9, UNK1010.8
unnamed: R2.2, RD1.A
unnamed: IC16.17, RN13.2, UNK1011.1
unnamed: IC16.15, RN13.3, UNK1011.2
unnamed: IC16.13, RN13.4, UNK1011.3
unnamed: IC16.11, RN13.5, UNK1011.4
unnamed: IC16.8, RN13.6, UNK1011.5
unnamed: IC16.6, RN13.7, UNK1011.6
unnamed: IC16.4, RN13.8, UNK1011.7
unnamed: IC16.2, RN13.9, UNK1011.8
unnamed: R3.2, RD2.A
unnamed: IC17.17, RN14.2, UNK1100.1
unnamed: IC17.15, RN14.3, UNK1100.2
unnamed: IC17.13, RN14.4, UNK1100.3
unnamed: IC17.11, RN14.5, UNK1100.4
unnamed: IC17.8, RN14.6, UNK1100.5
unnamed: IC17.6, RN14.7, UNK1100.6
unnamed: IC17.4, RN14.8, UNK1100.7
unnamed: IC17.2, RN14.9, UNK1100.8
unnamed: R4.2, RD3.A
unnamed: IC18.17, RN15.2, UNK1101.1
unnamed: IC18.15, RN15.3, UNK1101.2
unnamed: IC18.13, RN15.4, UNK1101.3
unnamed: IC18.11, RN15.5, UNK1101.4
unnamed: IC18.8, RN15.6, UNK1101.5
unnamed: IC18.6, RN15.7, UNK1101.6
unnamed: IC18.4, RN15.8, UNK1101.7
unnamed: IC18.2, RN15.9, UNK1101.8
unnamed: R5.2, RD4.A
unnamed: IC19.17, RN16.2, UNK1110.1
unnamed: IC19.15, RN16.3, UNK1110.2
unnamed: IC19.13, RN16.4, UNK1110.3
unnamed: IC19.11, RN16.5, UNK1110.4
unnamed: IC19.8, RN16.6, UNK1110.5
unnamed: IC19.6, RN16.7, UNK1110.6
unnamed: IC19.4, RN16.8, UNK1110.7
unnamed: IC19.2, RN16.9, UNK1110.8
unnamed: R6.2, RD5.A
unnamed: IC20.17, RN17.2, UNK1111.1
unnamed: IC20.15, RN17.3, UNK1111.2
unnamed: IC20.13, RN17.4, UNK1111.3
unnamed: IC20.11, RN17.5, UNK1111.4
unnamed: IC20.8, RN17.6, UNK1111.5
unnamed: IC20.6, RN17.7, UNK1111.6
unnamed: IC20.4, RN17.8, UNK1111.7
unnamed: IC20.2, RN17.9, UNK1111.8
unnamed: R7.2, RD6.A
unnamed: R8.2, RD7.A
unnamed: R9.2, RD8.A
unnamed: R10.2, RD9.A
unnamed: R11.2, RD10.A
unnamed: R12.2, RD11.A
unnamed: R13.2, RD12.A
unnamed: R14.2, RD13.A
unnamed: R15.2, RD14.A
unnamed: R16.2, RD15.A
SW0: IC2.15, IC5.1, IC5.19, RD0.K
SW1: IC2.14, IC6.1, IC6.19, RD1.K
SW2: IC2.13, IC7.1, IC7.19, RD2.K
SW3: IC2.12, IC8.1, IC8.19, RD3.K
SW4: IC2.11, IC9.1, IC9.19, RD4.K
SW5: IC2.10, IC10.1, IC10.19, RD5.K
SW6: IC2.9, IC11.1, IC11.19, RD6.K
SW7: IC2.7, IC12.1, IC12.19, RD7.K
SW8: IC3.15, IC13.1, IC13.19, RD8.K
SW9: IC3.14, IC14.1, IC14.19, RD9.K
SW10: IC3.13, IC15.1, IC15.19, RD10.K
SW11: IC3.12, IC16.1, IC16.19, RD11.K
SW12: IC3.11, IC17.1, IC17.19, RD12.K
SW13: IC3.10, IC18.1, IC18.19, RD13.K
SW14: IC3.9, IC19.1, IC19.19, RD14.K
SW15: IC3.7, IC20.1, IC20.19, RD15.K
VCC: C1.1, C2.1, C3.1, C4.1, C5.1, C6.1, C7.1, C8.1, C9.1, C10.1, C11.1, C12.1, C13.1, C14.1, C15.1, C16.1, C17.1, C18.1, C19.1, C20.1, C21.1, IC1.14, IC2.16, IC3.16, IC4.16, IC5.20, IC6.20, IC7.20, IC8.20, IC9.20, IC10.20, IC11.20, IC12.20, IC13.20, IC14.20, IC15.20, IC16.20, IC17.20, IC18.20, IC19.20, IC20.20, R1.1, R2.1, R3.1, R4.1, R5.1, R6.1, R7.1, R8.1, R9.1, R10.1, R11.1, R12.1, R13.1, R14.1, R15.1, R16.1, R17.2, RN2.1, RN3.1, RN4.1, RN5.1, RN6.1, RN7.1, RN8.1, RN9.1, RN10.1, RN11.1, RN12.1, RN13.1, RN14.1, RN15.1, RN16.1, RN17.1, SW1.1, SW1.2, SW1.3, SW1.4, V1.14, X1.A2, X1.A31, X1.B2, X1.B31, X1.C2, X1.C31

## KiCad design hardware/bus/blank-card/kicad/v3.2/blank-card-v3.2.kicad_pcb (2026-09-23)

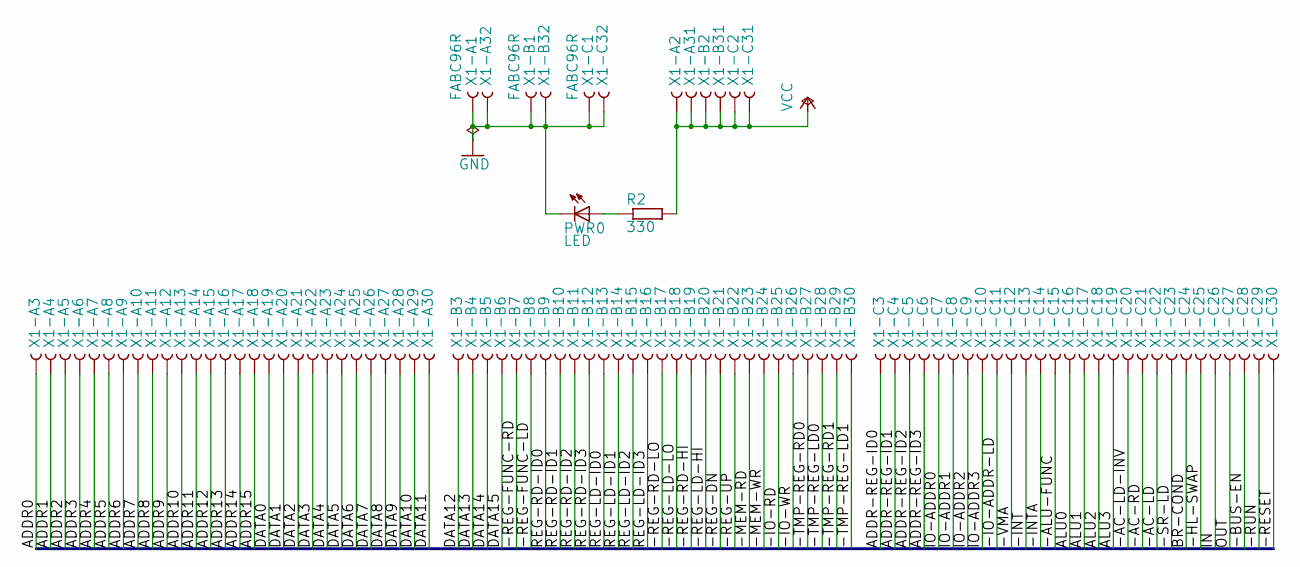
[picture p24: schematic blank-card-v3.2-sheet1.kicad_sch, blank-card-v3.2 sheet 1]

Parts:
PWR0: LED; LED5MM
R2: 330; 0207_10
X1: FABC96R

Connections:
-AC-LD: X1.C22
-AC-LD-INV: X1.C20
-AC-RD: X1.C21
-ALU-FUNC: X1.C15
-BUS-EN: X1.C28
-HL-SWAP: X1.C25
-INT: X1.C13
-INTA: X1.C14
-IO-ADDR-LD: X1.C11
-IO-RD: X1.B25
-IO-WR: X1.B26
-MEM-RD: X1.B23
-MEM-WR: X1.B24
-REG-DN: X1.B21
-REG-FUNC-LD: X1.B8
-REG-FUNC-RD: X1.B7
-REG-LD-HI: X1.B20
-REG-LD-LO: X1.B18
-REG-RD-HI: X1.B19
-REG-RD-LO: X1.B17
-REG-UP: X1.B22
-RESET: X1.C30
-RUN: X1.C29
-SR-LD: X1.C23
-TMP-REG-LD0: X1.B28
-TMP-REG-LD1: X1.B30
-TMP-REG-RD0: X1.B27
-TMP-REG-RD1: X1.B29
-VMA: X1.C12
ADDR0: X1.A3
ADDR1: X1.A4
ADDR2: X1.A5
ADDR3: X1.A6
ADDR4: X1.A7
ADDR5: X1.A8
ADDR6: X1.A9
ADDR7: X1.A10
ADDR8: X1.A11
ADDR9: X1.A12
ADDR10: X1.A13
ADDR11: X1.A14
ADDR12: X1.A15
ADDR13: X1.A16
ADDR14: X1.A17
ADDR15: X1.A18
ADDR-REG-ID0: X1.C3
ADDR-REG-ID1: X1.C4
ADDR-REG-ID2: X1.C5
ADDR-REG-ID3: X1.C6
ALU0: X1.C16
ALU1: X1.C17
ALU2: X1.C18
ALU3: X1.C19
BR-COND: X1.C24
DATA0: X1.A19
DATA1: X1.A20
DATA2: X1.A21
DATA3: X1.A22
DATA4: X1.A23
DATA5: X1.A24
DATA6: X1.A25
DATA7: X1.A26
DATA8: X1.A27
DATA9: X1.A28
DATA10: X1.A29
DATA11: X1.A30
DATA12: X1.B3
DATA13: X1.B4
DATA14: X1.B5
DATA15: X1.B6
GND: PWR0.K (C), X1.A1, X1.A32, X1.B1, X1.B32, X1.C1, X1.C32
IN: X1.C26
IO-ADDR0: X1.C7
IO-ADDR1: X1.C8
IO-ADDR2: X1.C9
IO-ADDR3: X1.C10
unnamed: PWR0.A, R2.1
OUT: X1.C27
REG-LD-ID0: X1.B13
REG-LD-ID1: X1.B14
REG-LD-ID2: X1.B15
REG-LD-ID3: X1.B16
REG-RD-ID0: X1.B9
REG-RD-ID1: X1.B10
REG-RD-ID2: X1.B11
REG-RD-ID3: X1.B12
VCC: R2.2, X1.A2, X1.A31, X1.B2, X1.B31, X1.C2, X1.C31

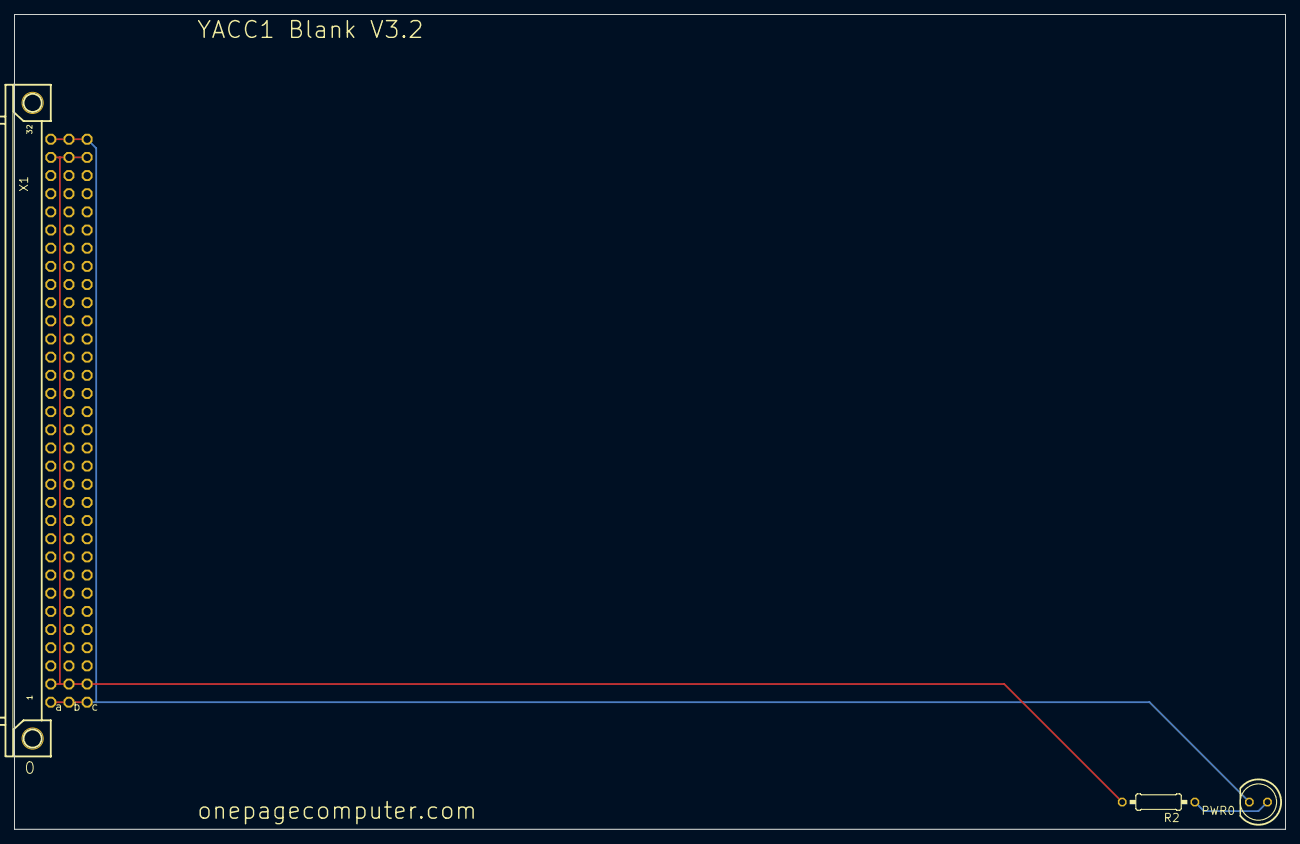
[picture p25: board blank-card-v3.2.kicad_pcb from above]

Board: 2 copper layers, 177.8 x 114.0 mm, 3 parts (0 on the bottom side), 3 nets.

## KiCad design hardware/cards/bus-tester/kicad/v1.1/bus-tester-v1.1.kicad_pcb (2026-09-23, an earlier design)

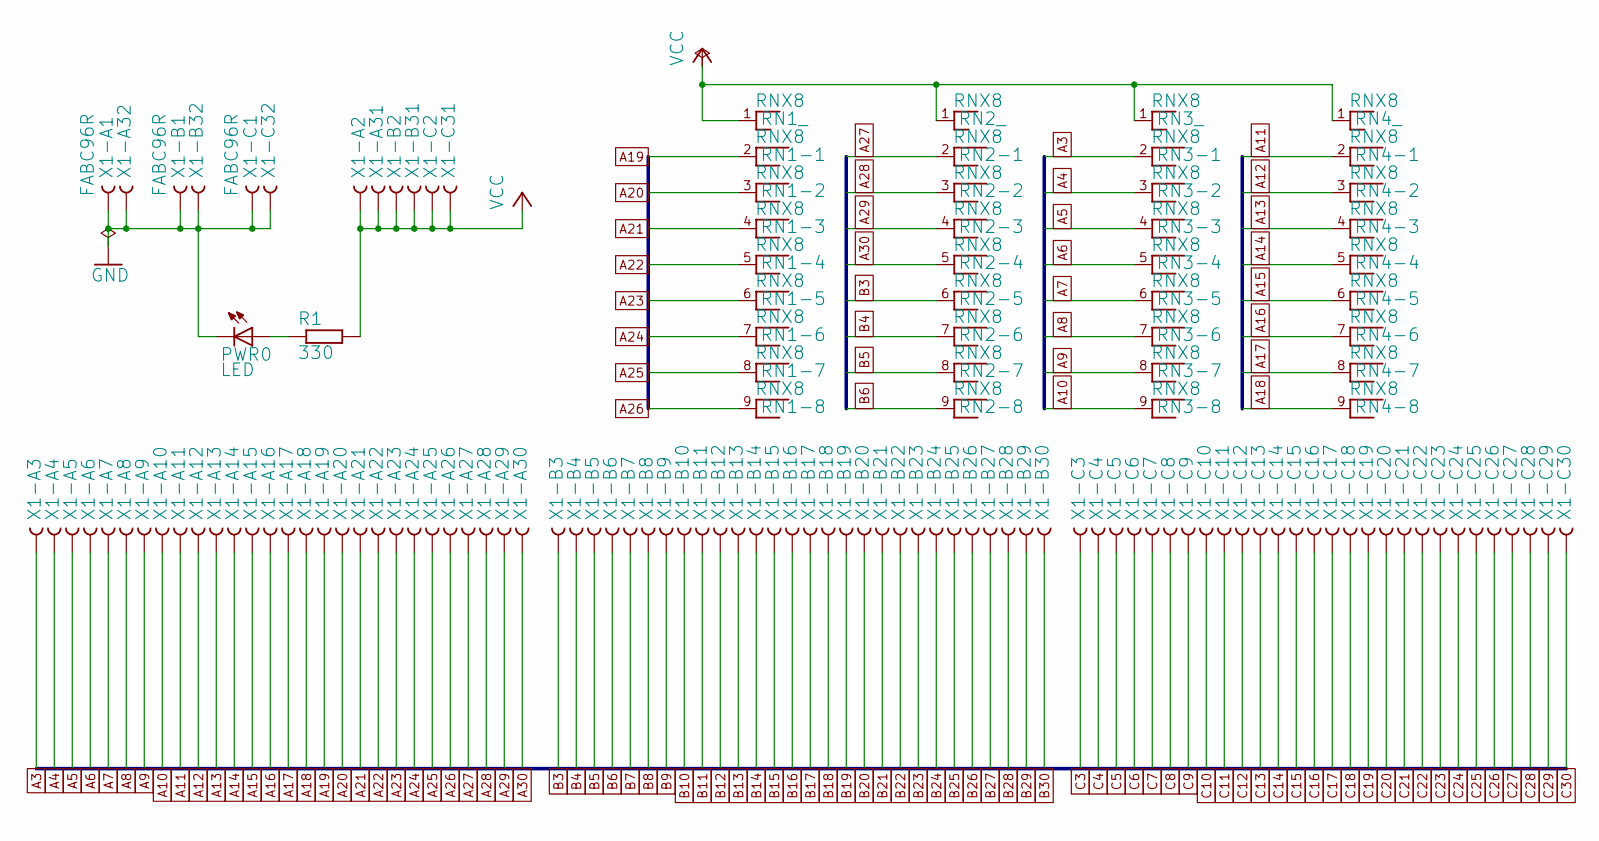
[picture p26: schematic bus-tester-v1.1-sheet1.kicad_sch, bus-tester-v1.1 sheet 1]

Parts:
PWR0: LED; LED5MM
R1: 330; 0207_10
RN1, RN2, RN3, RN4: RNX8; RN-9
X1: FABC96R

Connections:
A3: RN3.2, X1.A3; also elsewhere on the board
A4: RN3.3, X1.A4; also elsewhere on the board
A5: RN3.4, X1.A5; also elsewhere on the board
A6: RN3.5, X1.A6; also elsewhere on the board
A7: RN3.6, X1.A7; also elsewhere on the board
A8: RN3.7, X1.A8; also elsewhere on the board
A9: RN3.8, X1.A9; also elsewhere on the board
A10: RN3.9, X1.A10; also elsewhere on the board
A11: RN4.2, X1.A11; also elsewhere on the board
A12: RN4.3, X1.A12; also elsewhere on the board
A13: RN4.4, X1.A13; also elsewhere on the board
A14: RN4.5, X1.A14; also elsewhere on the board
A15: RN4.6, X1.A15; also elsewhere on the board
A16: RN4.7, X1.A16; also elsewhere on the board
A17: RN4.8, X1.A17; also elsewhere on the board
A18: RN4.9, X1.A18; also elsewhere on the board
A19: RN1.2, X1.A19; also elsewhere on the board
A20: RN1.3, X1.A20; also elsewhere on the board
A21: RN1.4, X1.A21; also elsewhere on the board
A22: RN1.5, X1.A22; also elsewhere on the board
A23: RN1.6, X1.A23; also elsewhere on the board
A24: RN1.7, X1.A24; also elsewhere on the board
A25: RN1.8, X1.A25; also elsewhere on the board
A26: RN1.9, X1.A26; also elsewhere on the board
A27: RN2.2, X1.A27; also elsewhere on the board
A28: RN2.3, X1.A28; also elsewhere on the board
A29: RN2.4, X1.A29; also elsewhere on the board
A30: RN2.5, X1.A30; also elsewhere on the board
B3: RN2.6, X1.B3; also elsewhere on the board
B4: RN2.7, X1.B4; also elsewhere on the board
B5: RN2.8, X1.B5; also elsewhere on the board
B6: RN2.9, X1.B6; also elsewhere on the board
B7: X1.B7; also elsewhere on the board
B8: X1.B8; also elsewhere on the board
B9: X1.B9; also elsewhere on the board
B10: X1.B10; also elsewhere on the board
B11: X1.B11; also elsewhere on the board
B12: X1.B12; also elsewhere on the board
B13: X1.B13; also elsewhere on the board
B14: X1.B14; also elsewhere on the board
B15: X1.B15; also elsewhere on the board
B16: X1.B16; also elsewhere on the board
B17: X1.B17; also elsewhere on the board
B18: X1.B18; also elsewhere on the board
B19: X1.B19; also elsewhere on the board
B20: X1.B20; also elsewhere on the board
B21: X1.B21; also elsewhere on the board
B22: X1.B22; also elsewhere on the board
B23: X1.B23; also elsewhere on the board
B24: X1.B24; also elsewhere on the board
B25: X1.B25; also elsewhere on the board
B26: X1.B26; also elsewhere on the board
B27: X1.B27; also elsewhere on the board
B28: X1.B28; also elsewhere on the board
B29: X1.B29; also elsewhere on the board
B30: X1.B30; also elsewhere on the board
C3: X1.C3; also elsewhere on the board
C4: X1.C4; also elsewhere on the board
C5: X1.C5; also elsewhere on the board
C6: X1.C6; also elsewhere on the board
C7: X1.C7; also elsewhere on the board
C8: X1.C8; also elsewhere on the board
C9: X1.C9; also elsewhere on the board
C10: X1.C10; also elsewhere on the board
C11: X1.C11; also elsewhere on the board
C12: X1.C12; also elsewhere on the board
C13: X1.C13; also elsewhere on the board
C14: X1.C14; also elsewhere on the board
C15: X1.C15; also elsewhere on the board
C16: X1.C16; also elsewhere on the board
C17: X1.C17; also elsewhere on the board
C18: X1.C18; also elsewhere on the board
C19: X1.C19; also elsewhere on the board
C20: X1.C20; also elsewhere on the board
C21: X1.C21; also elsewhere on the board
C22: X1.C22; also elsewhere on the board
C23: X1.C23; also elsewhere on the board
C24: X1.C24; also elsewhere on the board
C25: X1.C25; also elsewhere on the board
C26: X1.C26; also elsewhere on the board
C27: X1.C27; also elsewhere on the board
C28: X1.C28; also elsewhere on the board
C29: X1.C29; also elsewhere on the board
C30: X1.C30; also elsewhere on the board
GND: PWR0.K (C), X1.A1, X1.A32, X1.B1, X1.B32, X1.C1, X1.C32; also elsewhere on the board
unnamed: PWR0.A, R1.1
VCC: R1.2, RN1.1, RN2.1, RN3.1, RN4.1, X1.A2, X1.A31, X1.B2, X1.B31, X1.C2, X1.C31; also elsewhere on the board

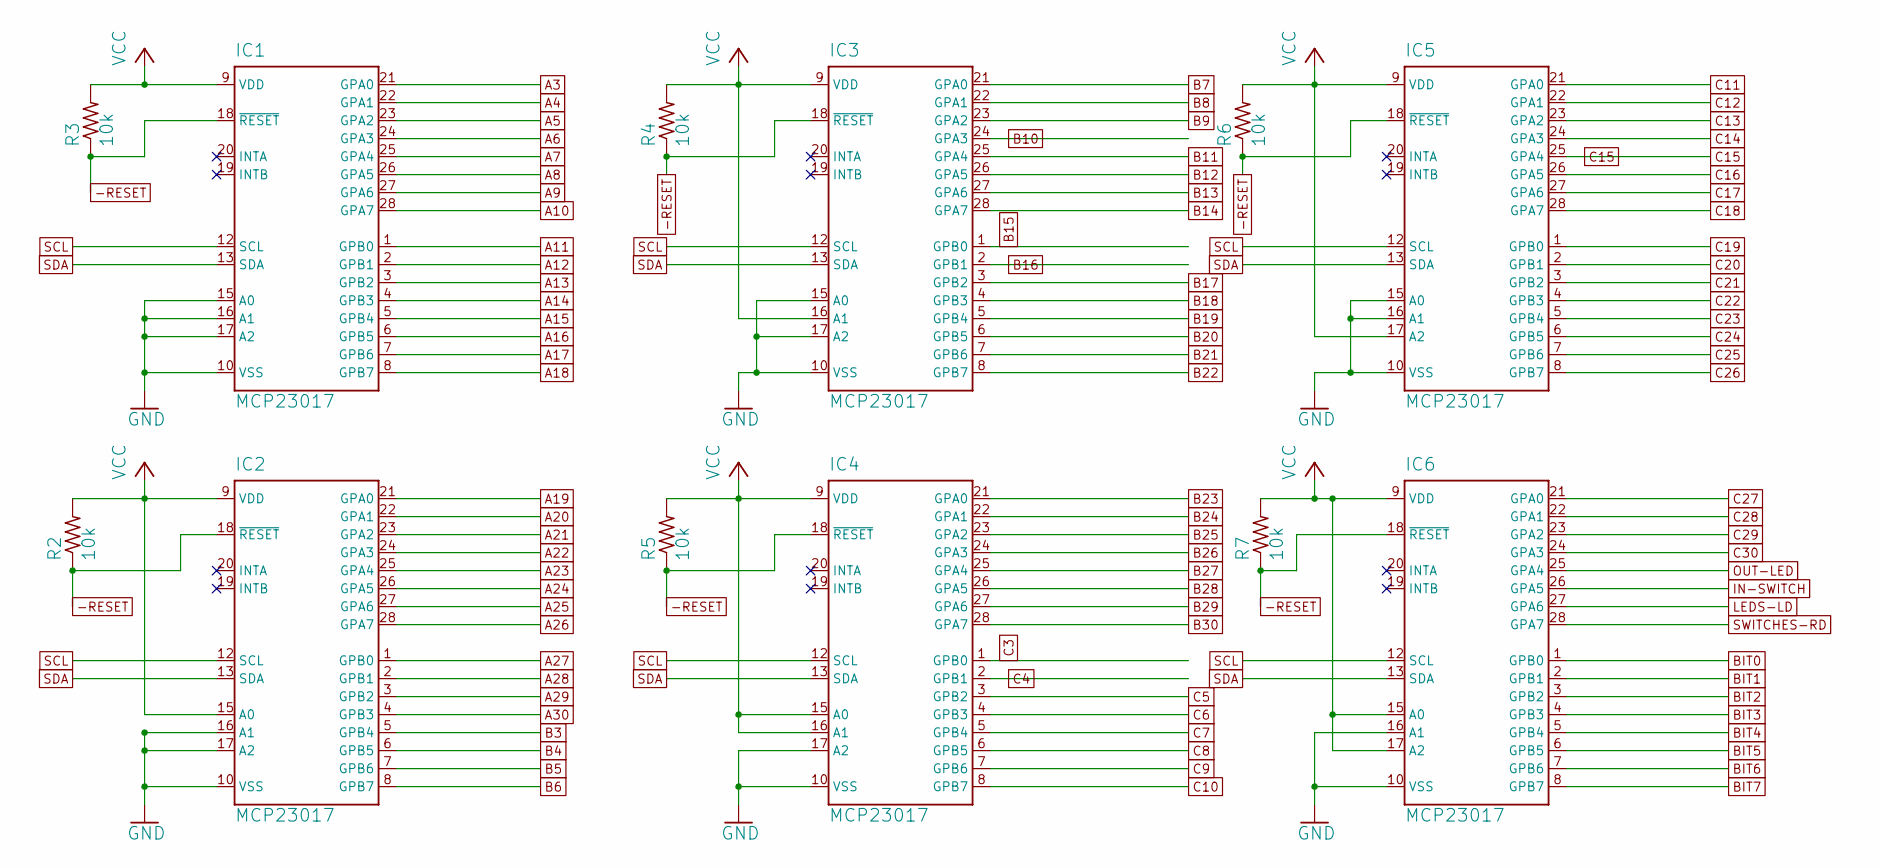
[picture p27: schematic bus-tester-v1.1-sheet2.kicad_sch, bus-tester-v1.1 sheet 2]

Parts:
IC1, IC2, IC3, IC4, IC5, IC6: MCP23017; DIL28-3
R2, R3, R4, R5, R6, R7: 10k; 0207_10

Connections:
-RESET: IC1.18 (~RESET), IC2.18 (~RESET), IC3.18 (~RESET), IC4.18 (~RESET), IC5.18 (~RESET), IC6.18 (~RESET), R2.1, R3.1, R4.1, R5.1, R6.1, R7.1; also elsewhere on the board
A3: IC1.21 (GPA0); also elsewhere on the board
A4: IC1.22 (GPA1); also elsewhere on the board
A5: IC1.23 (GPA2); also elsewhere on the board
A6: IC1.24 (GPA3); also elsewhere on the board
A7: IC1.25 (GPA4); also elsewhere on the board
A8: IC1.26 (GPA5); also elsewhere on the board
A9: IC1.27 (GPA6); also elsewhere on the board
A10: IC1.28 (GPA7); also elsewhere on the board
A11: IC1.1 (GPB0); also elsewhere on the board
A12: IC1.2 (GPB1); also elsewhere on the board
A13: IC1.3 (GPB2); also elsewhere on the board
A14: IC1.4 (GPB3); also elsewhere on the board
A15: IC1.5 (GPB4); also elsewhere on the board
A16: IC1.6 (GPB5); also elsewhere on the board
A17: IC1.7 (GPB6); also elsewhere on the board
A18: IC1.8 (GPB7); also elsewhere on the board
A19: IC2.21 (GPA0); also elsewhere on the board
A20: IC2.22 (GPA1); also elsewhere on the board
A21: IC2.23 (GPA2); also elsewhere on the board
A22: IC2.24 (GPA3); also elsewhere on the board
A23: IC2.25 (GPA4); also elsewhere on the board
A24: IC2.26 (GPA5); also elsewhere on the board
A25: IC2.27 (GPA6); also elsewhere on the board
A26: IC2.28 (GPA7); also elsewhere on the board
A27: IC2.1 (GPB0); also elsewhere on the board
A28: IC2.2 (GPB1); also elsewhere on the board
A29: IC2.3 (GPB2); also elsewhere on the board
A30: IC2.4 (GPB3); also elsewhere on the board
B3: IC2.5 (GPB4); also elsewhere on the board
B4: IC2.6 (GPB5); also elsewhere on the board
B5: IC2.7 (GPB6); also elsewhere on the board
B6: IC2.8 (GPB7); also elsewhere on the board
B7: IC3.21 (GPA0); also elsewhere on the board
B8: IC3.22 (GPA1); also elsewhere on the board
B9: IC3.23 (GPA2); also elsewhere on the board
B10: IC3.24 (GPA3); also elsewhere on the board
B11: IC3.25 (GPA4); also elsewhere on the board
B12: IC3.26 (GPA5); also elsewhere on the board
B13: IC3.27 (GPA6); also elsewhere on the board
B14: IC3.28 (GPA7); also elsewhere on the board
B15: IC3.1 (GPB0); also elsewhere on the board
B16: IC3.2 (GPB1); also elsewhere on the board
B17: IC3.3 (GPB2); also elsewhere on the board
B18: IC3.4 (GPB3); also elsewhere on the board
B19: IC3.5 (GPB4); also elsewhere on the board
B20: IC3.6 (GPB5); also elsewhere on the board
B21: IC3.7 (GPB6); also elsewhere on the board
B22: IC3.8 (GPB7); also elsewhere on the board
B23: IC4.21 (GPA0); also elsewhere on the board
B24: IC4.22 (GPA1); also elsewhere on the board
B25: IC4.23 (GPA2); also elsewhere on the board
B26: IC4.24 (GPA3); also elsewhere on the board
B27: IC4.25 (GPA4); also elsewhere on the board
B28: IC4.26 (GPA5); also elsewhere on the board
B29: IC4.27 (GPA6); also elsewhere on the board
B30: IC4.28 (GPA7); also elsewhere on the board
BIT0: IC6.1 (GPB0); also elsewhere on the board
BIT1: IC6.2 (GPB1); also elsewhere on the board
BIT2: IC6.3 (GPB2); also elsewhere on the board
BIT3: IC6.4 (GPB3); also elsewhere on the board
BIT4: IC6.5 (GPB4); also elsewhere on the board
BIT5: IC6.6 (GPB5); also elsewhere on the board
BIT6: IC6.7 (GPB6); also elsewhere on the board
BIT7: IC6.8 (GPB7); also elsewhere on the board
C3: IC4.1 (GPB0); also elsewhere on the board
C4: IC4.2 (GPB1); also elsewhere on the board
C5: IC4.3 (GPB2); also elsewhere on the board
C6: IC4.4 (GPB3); also elsewhere on the board
C7: IC4.5 (GPB4); also elsewhere on the board
C8: IC4.6 (GPB5); also elsewhere on the board
C9: IC4.7 (GPB6); also elsewhere on the board
C10: IC4.8 (GPB7); also elsewhere on the board
C11: IC5.21 (GPA0); also elsewhere on the board
C12: IC5.22 (GPA1); also elsewhere on the board
C13: IC5.23 (GPA2); also elsewhere on the board
C14: IC5.24 (GPA3); also elsewhere on the board
C15: IC5.25 (GPA4); also elsewhere on the board
C16: IC5.26 (GPA5); also elsewhere on the board
C17: IC5.27 (GPA6); also elsewhere on the board
C18: IC5.28 (GPA7); also elsewhere on the board
C19: IC5.1 (GPB0); also elsewhere on the board
C20: IC5.2 (GPB1); also elsewhere on the board
C21: IC5.3 (GPB2); also elsewhere on the board
C22: IC5.4 (GPB3); also elsewhere on the board
C23: IC5.5 (GPB4); also elsewhere on the board
C24: IC5.6 (GPB5); also elsewhere on the board
C25: IC5.7 (GPB6); also elsewhere on the board
C26: IC5.8 (GPB7); also elsewhere on the board
C27: IC6.21 (GPA0); also elsewhere on the board
C28: IC6.22 (GPA1); also elsewhere on the board
C29: IC6.23 (GPA2); also elsewhere on the board
C30: IC6.24 (GPA3); also elsewhere on the board
GND: IC1.10 (VSS), IC1.15 (A0), IC1.16 (A1), IC1.17 (A2), IC2.10 (VSS), IC2.16 (A1), IC2.17 (A2), IC3.10 (VSS), IC3.15 (A0), IC3.17 (A2), IC4.10 (VSS), IC4.17 (A2), IC5.10 (VSS), IC5.15 (A0), IC5.16 (A1), IC6.10 (VSS), IC6.16 (A1); also elsewhere on the board
IN-SWITCH: IC6.26 (GPA5); also elsewhere on the board
LEDS-LD: IC6.27 (GPA6); also elsewhere on the board
OUT-LED: IC6.25 (GPA4); also elsewhere on the board
SCL: IC1.12 (SCL), IC2.12 (SCL), IC3.12 (SCL), IC4.12 (SCL), IC5.12 (SCL), IC6.12 (SCL); also elsewhere on the board
SDA: IC1.13 (SDA), IC2.13 (SDA), IC3.13 (SDA), IC4.13 (SDA), IC5.13 (SDA), IC6.13 (SDA); also elsewhere on the board
SWITCHES-RD: IC6.28 (GPA7); also elsewhere on the board
VCC: IC1.9 (VDD), IC2.9 (VDD), IC2.15 (A0), IC3.9 (VDD), IC3.16 (A1), IC4.9 (VDD), IC4.15 (A0), IC4.16 (A1), IC5.9 (VDD), IC5.17 (A2), IC6.9 (VDD), IC6.15 (A0), IC6.17 (A2), R2.2, R3.2, R4.2, R5.2, R6.2, R7.2; also elsewhere on the board

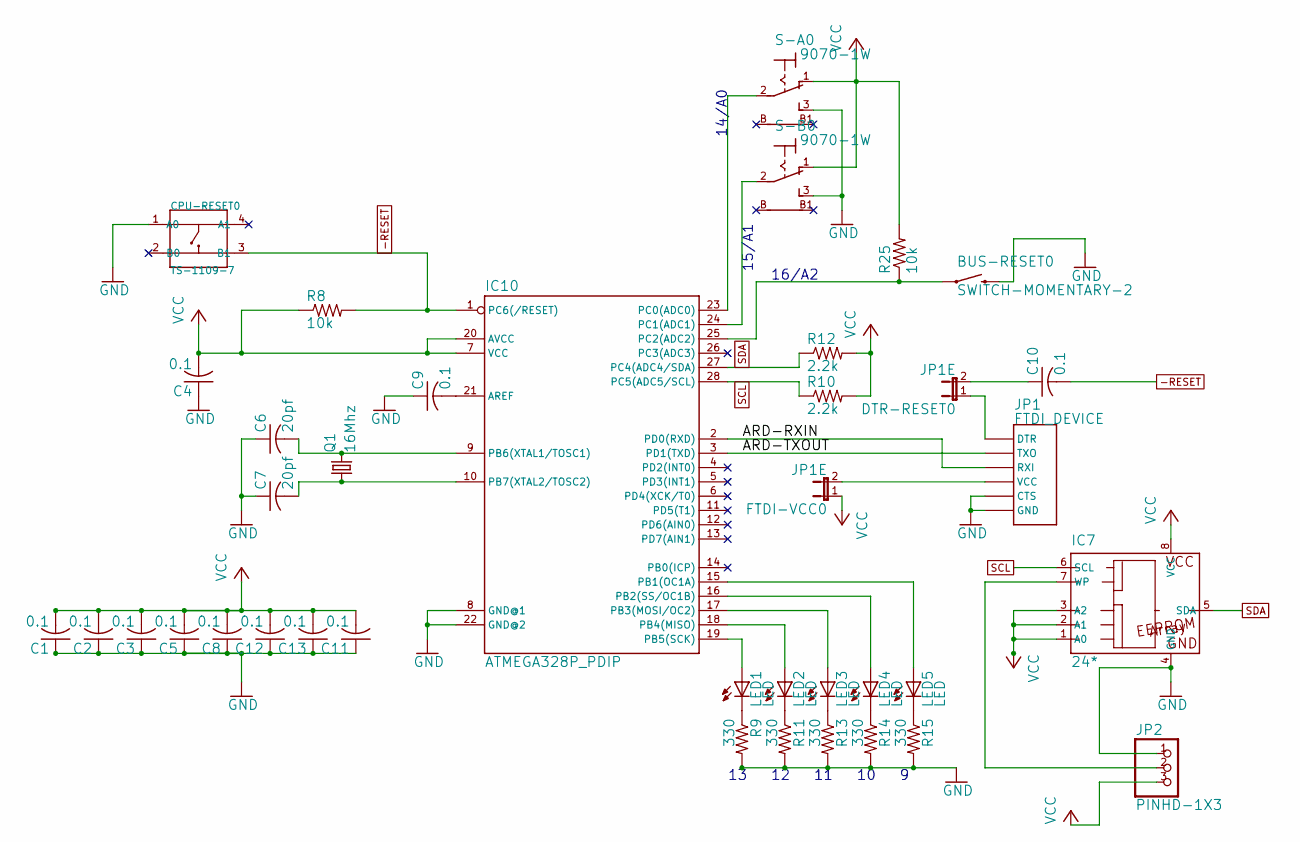
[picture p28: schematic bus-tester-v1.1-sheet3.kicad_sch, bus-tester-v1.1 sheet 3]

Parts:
BUS-RESET0: SWITCH-MOMENTARY-2; TACTILE-PTH-SIDEEZ
C1, C2, C3, C4, C5, C8, C9, C10, C11, C12, C13: 0.1; C025-024X044
C6, C7: 20pf; C025-024X044
CPU-RESET0: TS-1109-7; SW4-6.2X6.2X5.0MM
DTR-RESET0: JP1E; JP1
FTDI-VCC0: JP1E; JP1
IC7: 24*; DIL8
IC10: ATMEGA328P_PDIP; DIL28-3
JP1: FTDI_DEVICE; FTDI_DEVICE_SIDE
JP2: PINHD-1X3; 1X03
LED1, LED2, LED3, LED4, LED5: LED; LED5MM
Q1: 16Mhz; HC49_S
R8, R25: 10k; 0207_10
R9, R11, R13, R14, R15: 330; 0207_10
R10, R12: 2.2k; 0207_10
S-A0: 9070-1W
S-B0: 9070-1W

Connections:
-RESET: C10.2, CPU-RESET0.3 (B1), IC10.1 (PC6(/RESET)), R8.2; also elsewhere on the board
ARD-RXIN: IC10.2 (PD0(RXD)), JP1.P$3 (RXI)
ARD-TXOUT: IC10.3 (PD1(TXD)), JP1.P$2 (TXO)
GND: BUS-RESET0.2, C1.1, C2.1, C3.1, C4.1, C5.1, C6.1, C7.1, C8.1, C9.1, C11.1, C12.1, C13.1, CPU-RESET0.1 (A0), IC7.4 (GND), IC10.8 (GND@1), IC10.22 (GND@2), JP1.P$5 (CTS), JP1.P$6 (GND), JP2.1, R9.2, R11.2, R13.2, R14.2, R15.2, S-A0.3 (S), S-B0.3 (S); also elsewhere on the board
unnamed: IC10.19 (PB5(SCK)), LED1.A
unnamed: IC7.7 (WP), JP2.2
unnamed: C6.2, IC10.9 (PB6(XTAL1/TOSC1)), Q1.2
unnamed: C7.2, IC10.10 (PB7(XTAL2/TOSC2)), Q1.1
unnamed: IC10.18 (PB4(MISO)), LED2.A
unnamed: IC10.17 (PB3(MOSI/OC2)), LED3.A
unnamed: IC10.16 (PB2(SS/OC1B)), LED4.A
unnamed: C10.1, DTR-RESET0.2
unnamed: IC10.15 (PB1(OC1A)), LED5.A
unnamed: LED2.K (C), R11.1
unnamed: LED1.K (C), R9.1
unnamed: LED3.K (C), R13.1
unnamed: C9.2, IC10.21 (AREF)
unnamed: LED4.K (C), R14.1
unnamed: LED5.K (C), R15.1
unnamed: IC10.23 (PC0(ADC0)), S-A0.2
unnamed: IC10.24 (PC1(ADC1)), S-B0.2
unnamed: DTR-RESET0.1, JP1.P$1 (DTR)
unnamed: FTDI-VCC0.2, JP1.P$4 (VCC)
unnamed: BUS-RESET0.1, IC10.25 (PC2(ADC2)), R25.1
SCL: IC7.6 (SCL), IC10.28 (PC5(ADC5/SCL)), R10.1; also elsewhere on the board
SDA: IC7.5 (SDA), IC10.27 (PC4(ADC4/SDA)), R12.1; also elsewhere on the board
VCC: C1.2, C2.2, C3.2, C4.2, C5.2, C8.2, C11.2, C12.2, C13.2, FTDI-VCC0.1, IC7.1 (A0), IC7.2 (A1), IC7.3 (A2), IC7.8 (VCC), IC10.7 (VCC), IC10.20 (AVCC), JP2.3, R8.1, R10.2, R12.2, R25.2, S-A0.1 (O), S-B0.1 (O); also elsewhere on the board

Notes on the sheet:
14/A0
15/A1
16/A2

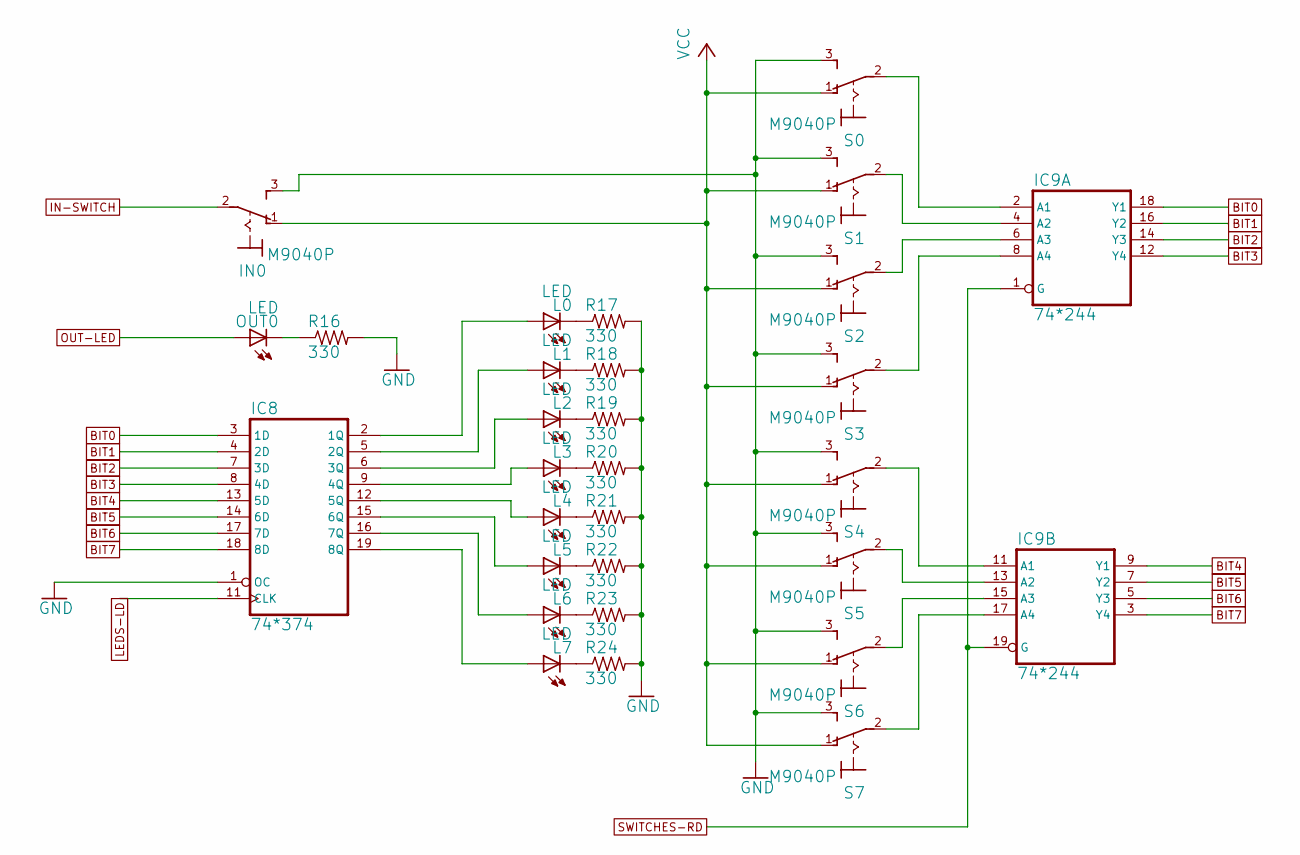
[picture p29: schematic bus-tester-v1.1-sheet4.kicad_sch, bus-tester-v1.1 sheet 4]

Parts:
IC8: 74*374; DIL20
IC9: 74*244; DIL20
IN0: M9040P
L0, L1, L2, L3, L4, L5, L6, L7: LED; LED5MM
OUT0: LED; LED5MM
R16, R17, R18, R19, R20, R21, R22, R23, R24: 330; 0207_10
S0, S1, S2, S3, S4, S5, S6, S7: M9040P

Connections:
BIT0: IC8.3 (1D), IC9.18 (Y1); also elsewhere on the board
BIT1: IC8.4 (2D), IC9.16 (Y2); also elsewhere on the board
BIT2: IC8.7 (3D), IC9.14 (Y3); also elsewhere on the board
BIT3: IC8.8 (4D), IC9.12 (Y4); also elsewhere on the board
BIT4: IC8.13 (5D), IC9.9 (Y1); also elsewhere on the board
BIT5: IC8.14 (6D), IC9.7 (Y2); also elsewhere on the board
BIT6: IC8.17 (7D), IC9.5 (Y3); also elsewhere on the board
BIT7: IC8.18 (8D), IC9.3 (Y4); also elsewhere on the board
GND: IC8.1 (OC), IC8.10 (GND), IC9.10 (GND), IN0.3 (S), R16.2, R17.2, R18.2, R19.2, R20.2, R21.2, R22.2, R23.2, R24.2, S0.3 (S), S1.3 (S), S2.3 (S), S3.3 (S), S4.3 (S), S5.3 (S), S6.3 (S), S7.3 (S); also elsewhere on the board
IN-SWITCH: IN0.2; also elsewhere on the board
LEDS-LD: IC8.11 (CLK); also elsewhere on the board
unnamed: L7.K (C), R24.1
unnamed: L6.K (C), R23.1
unnamed: L5.K (C), R22.1
unnamed: L4.K (C), R21.1
unnamed: L3.K (C), R20.1
unnamed: L2.K (C), R19.1
unnamed: L1.K (C), R18.1
unnamed: L0.K (C), R17.1
unnamed: OUT0.K (C), R16.1
unnamed: IC8.5 (2Q), L1.A
unnamed: IC8.9 (4Q), L3.A
unnamed: IC8.12 (5Q), L4.A
unnamed: IC8.15 (6Q), L5.A
unnamed: IC8.6 (3Q), L2.A
unnamed: IC8.16 (7Q), L6.A
unnamed: IC8.19 (8Q), L7.A
unnamed: IC8.2 (1Q), L0.A
unnamed: IC9.2 (A1), S0.2
unnamed: IC9.8 (A4), S3.2
unnamed: IC9.6 (A3), S2.2
unnamed: IC9.4 (A2), S1.2
unnamed: IC9.11 (A1), S4.2
unnamed: IC9.17 (A4), S7.2
unnamed: IC9.13 (A2), S5.2
unnamed: IC9.15 (A3), S6.2
OUT-LED: OUT0.A; also elsewhere on the board
SWITCHES-RD: IC9.1 (G), IC9.19 (G); also elsewhere on the board
VCC: IC8.20 (VCC), IC9.20 (VCC), IN0.1 (O), S0.1 (O), S1.1 (O), S2.1 (O), S3.1 (O), S4.1 (O), S5.1 (O), S6.1 (O), S7.1 (O); also elsewhere on the board

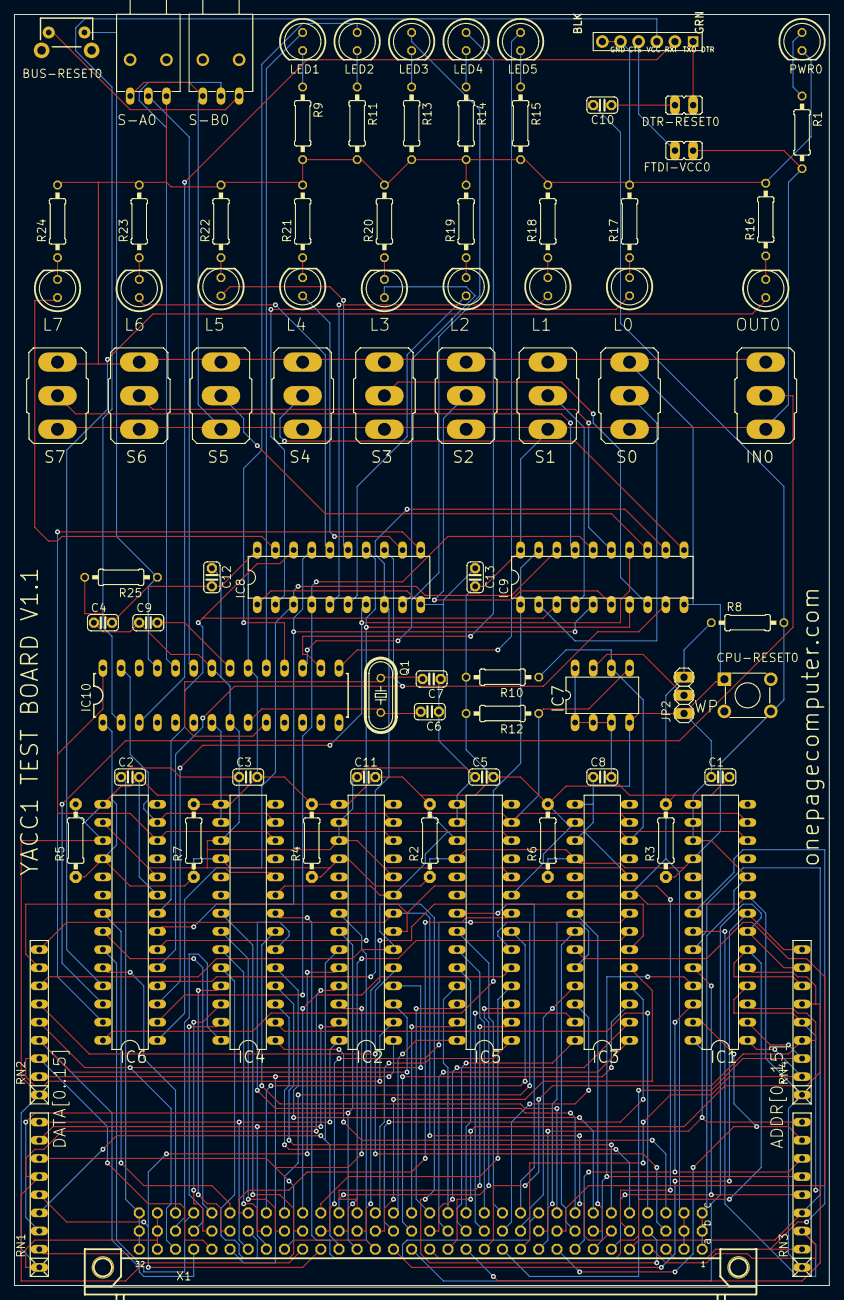
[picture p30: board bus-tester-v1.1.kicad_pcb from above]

Board: 2 copper layers, 114.0 x 177.8 mm, 86 parts (0 on the bottom side), 149 nets.

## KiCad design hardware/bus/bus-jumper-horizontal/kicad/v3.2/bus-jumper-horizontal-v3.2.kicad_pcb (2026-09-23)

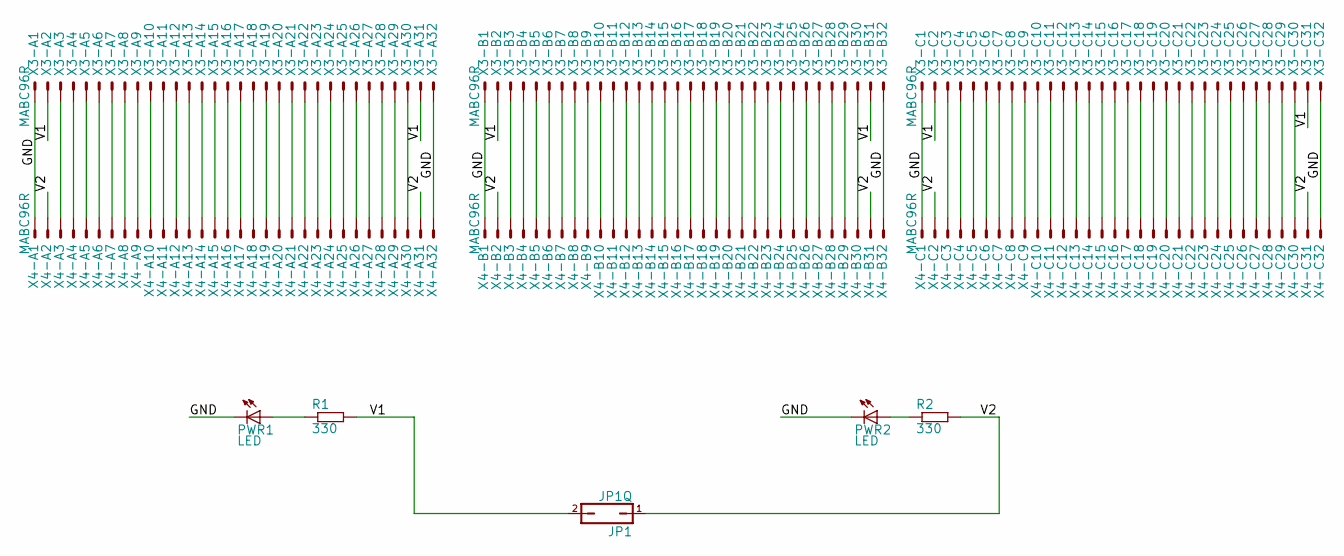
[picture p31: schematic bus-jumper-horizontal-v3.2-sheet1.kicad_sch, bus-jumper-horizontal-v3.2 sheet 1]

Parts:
JP1: JP1Q; JP1
PWR1, PWR2: LED; LED5MM
R1, R2: 330; 0207_10
X3, X4: MABC96R

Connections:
GND: PWR1.K (C), PWR2.K (C), X3.A1, X3.A32, X3.B1, X3.B32, X3.C1, X3.C32, X4.A1, X4.A32, X4.B1, X4.B32, X4.C1, X4.C32
unnamed: X3.A3, X4.A3
unnamed: X3.A4, X4.A4
unnamed: X3.A5, X4.A5
unnamed: X3.A6, X4.A6
unnamed: X3.A7, X4.A7
unnamed: X3.A8, X4.A8
unnamed: X3.A9, X4.A9
unnamed: X3.A10, X4.A10
unnamed: X3.A11, X4.A11
unnamed: X3.A12, X4.A12
unnamed: X3.A13, X4.A13
unnamed: X3.A14, X4.A14
unnamed: X3.A15, X4.A15
unnamed: X3.A16, X4.A16
unnamed: X3.A17, X4.A17
unnamed: X3.A18, X4.A18
unnamed: X3.A19, X4.A19
unnamed: X3.A20, X4.A20
unnamed: X3.A21, X4.A21
unnamed: X3.A22, X4.A22
unnamed: X3.A23, X4.A23
unnamed: X3.A24, X4.A24
unnamed: X3.A25, X4.A25
unnamed: X3.A26, X4.A26
unnamed: X3.A27, X4.A27
unnamed: X3.A28, X4.A28
unnamed: X3.A29, X4.A29
unnamed: X3.A30, X4.A30
unnamed: PWR1.A, R1.1
unnamed: PWR2.A, R2.1
unnamed: X3.B3, X4.B3
unnamed: X3.B4, X4.B4
unnamed: X3.B5, X4.B5
unnamed: X3.B6, X4.B6
unnamed: X3.B7, X4.B7
unnamed: X3.B8, X4.B8
unnamed: X3.B9, X4.B9
unnamed: X3.B10, X4.B10
unnamed: X3.B11, X4.B11
unnamed: X3.B12, X4.B12
unnamed: X3.B13, X4.B13
unnamed: X3.B14, X4.B14
unnamed: X3.B15, X4.B15
unnamed: X3.B16, X4.B16
unnamed: X3.B17, X4.B17
unnamed: X3.B18, X4.B18
unnamed: X3.B19, X4.B19
unnamed: X3.B20, X4.B20
unnamed: X3.B21, X4.B21
unnamed: X3.B22, X4.B22
unnamed: X3.B23, X4.B23
unnamed: X3.B24, X4.B24
unnamed: X3.B25, X4.B25
unnamed: X3.B26, X4.B26
unnamed: X3.B27, X4.B27
unnamed: X3.B28, X4.B28
unnamed: X3.B29, X4.B29
unnamed: X3.B30, X4.B30
unnamed: X3.C3, X4.C3
unnamed: X3.C4, X4.C4
unnamed: X3.C5, X4.C5
unnamed: X3.C6, X4.C6
unnamed: X3.C7, X4.C7
unnamed: X3.C8, X4.C8
unnamed: X3.C9, X4.C9
unnamed: X3.C10, X4.C10
unnamed: X3.C11, X4.C11
unnamed: X3.C12, X4.C12
unnamed: X3.C13, X4.C13
unnamed: X3.C14, X4.C14
unnamed: X3.C15, X4.C15
unnamed: X3.C16, X4.C16
unnamed: X3.C17, X4.C17
unnamed: X3.C18, X4.C18
unnamed: X3.C19, X4.C19
unnamed: X3.C20, X4.C20
unnamed: X3.C21, X4.C21
unnamed: X3.C22, X4.C22
unnamed: X3.C23, X4.C23
unnamed: X3.C24, X4.C24
unnamed: X3.C25, X4.C25
unnamed: X3.C26, X4.C26
unnamed: X3.C27, X4.C27
unnamed: X3.C28, X4.C28
unnamed: X3.C29, X4.C29
unnamed: X3.C30, X4.C30
V1: JP1.2, R1.2, X3.A2, X3.A31, X3.B2, X3.B31, X3.C2, X3.C31
V2: JP1.1, R2.2, X4.A2, X4.A31, X4.B2, X4.B31, X4.C2, X4.C31

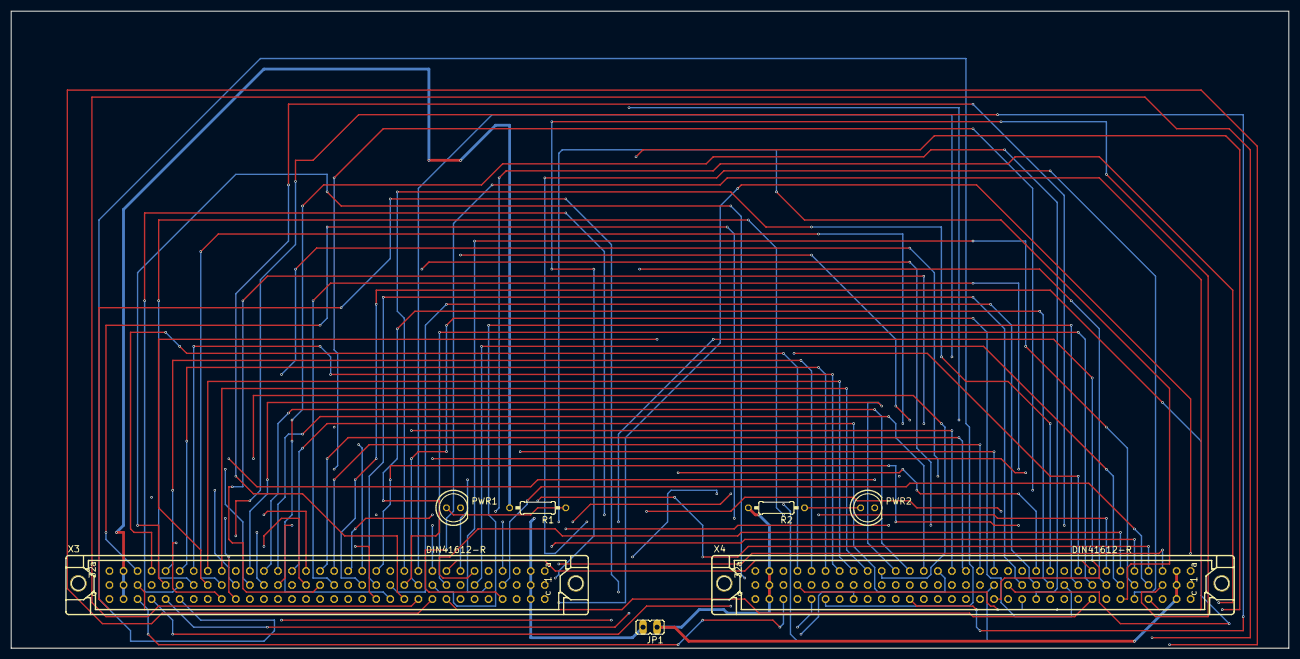
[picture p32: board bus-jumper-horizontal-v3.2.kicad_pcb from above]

Board: 4 copper layers, 231.1 x 115.2 mm, 7 parts (0 on the bottom side), 89 nets.

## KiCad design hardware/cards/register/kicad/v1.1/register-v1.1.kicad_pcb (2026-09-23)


Board: 4 copper layers, 177.8 x 114.6 mm, 102 parts (0 on the bottom side), 223 nets.

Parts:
C1, C2, C3, C4, C5, C6, C7, C8, C9, C10, C11, C12, C13, C14, C15, C16, C17, C18, C19, C20, C21, C22, C23, C24, C25, C26, C27, C28, C29, C30, C31, C32, C33, C34, C35, C36, C37, C38, C39, C40, C41, C42, C43, C44, C45, C46, C47: 0.1; C025-040X050
IC1, IC2, IC15, IC25, IC26, IC31, IC40, IC47: 74LS32N; DIL14
IC3, IC4, IC5, IC6, IC9, IC10, IC11, IC12, IC19, IC20, IC21, IC22, IC29, IC30, IC43, IC44: 74LS192N; DIL16
IC7, IC8, IC13, IC14, IC17, IC18, IC23, IC24, IC27, IC28, IC41, IC42, IC45, IC46, IC49, IC50: 74LS244N; DIL20
IC32, IC33, IC38: 74LS139N; DIL16
IC34: 4077N; DIL14
IC35, IC36, IC37: 74LS245N; DIL20
J1, J2, J3: 2X4
PWR0: LED5MM
R1: 330; 0207_10
RN1, RN2: 10k; RN-9
X1: FABC96R

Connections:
-ADDRSEL: IC38.1, J3.2, J3.4, J3.6, J3.8
-ARD0: IC38.12, J3.1
-BUS-EN: IC31.1, IC31.4, IC40.1, X1.C28
-HL-SWAP: IC31.13, IC34.9, X1.C25
-LDSEL: IC33.15, IC34.6, IC34.13, J2.2, J2.4, J2.6, J2.8
-R0-ADDRSEL: IC38.4, IC41.1, IC41.19, IC42.1, IC42.19
-R0-LDSEL: IC1.9, IC1.12, IC33.12
-R0-RDSEL: IC1.1, IC1.4, IC2.1, IC2.4, IC33.4
-R1-ADDRSEL: IC17.1, IC17.19, IC18.1, IC18.19, IC38.5
-R1-LDSEL: IC15.9, IC15.12, IC33.11
-R1-RDSEL: IC2.9, IC2.12, IC15.1, IC15.4, IC33.5
-R2-ADDRSEL: IC27.1, IC27.19, IC28.1, IC28.19, IC38.6
-R2-LDSEL: IC25.9, IC25.12, IC33.10
-R2-RDSEL: IC25.1, IC25.4, IC26.1, IC26.4, IC33.6
-R3-ADDRSEL: IC38.7, IC49.1, IC49.19, IC50.1, IC50.19
-R3-LDSEL: IC33.9, IC47.9, IC47.12
-R3-RDSEL: IC26.9, IC26.12, IC33.7, IC47.1, IC47.4
-RDSEL: IC33.1, IC34.12, J1.2, J1.4, J1.6, J1.8
-REG-DN: IC1.5, IC15.5, IC25.5, IC47.5, X1.B21
-REG-FUNC-LD: IC31.5, X1.B8
-REG-FUNC-RD: IC31.2, X1.B7
-REG-LD-HI: IC1.13, IC15.13, IC25.13, IC47.13, X1.B20
-REG-LD-LO: IC1.10, IC15.10, IC25.10, IC47.10, X1.B18
-REG-RD-HI: IC2.5, IC2.13, IC26.5, IC26.13, X1.B19
-REG-RD-LO: IC2.2, IC2.10, IC26.2, IC26.10, X1.B17
-REG-UP: IC1.2, IC15.2, IC25.2, IC47.2, X1.B22
-RESET: IC34.2, X1.C30
-RLD0: IC32.12, J2.1
-RRD0: IC32.4, J1.1
-VMA: IC40.2, X1.C12
ADATA0: IC3.15, IC7.9, IC9.15, IC13.9, IC19.15, IC23.9, IC29.15, IC35.18, IC45.9, RN1.2
ADATA1: IC3.1, IC7.7, IC9.1, IC13.7, IC19.1, IC23.7, IC29.1, IC35.17, IC45.7, RN1.3
ADATA2: IC3.10, IC7.5, IC9.10, IC13.5, IC19.10, IC23.5, IC29.10, IC35.16, IC45.5, RN1.4
ADATA3: IC3.9, IC7.3, IC9.9, IC13.3, IC19.9, IC23.3, IC29.9, IC35.15, IC45.3, RN1.5
ADATA4: IC4.15, IC7.18, IC10.15, IC13.18, IC20.15, IC23.18, IC30.15, IC35.14, IC45.18, RN1.6
ADATA5: IC4.1, IC7.16, IC10.1, IC13.16, IC20.1, IC23.16, IC30.1, IC35.13, IC45.16, RN1.7
ADATA6: IC4.10, IC7.14, IC10.10, IC13.14, IC20.10, IC23.14, IC30.10, IC35.12, IC45.14, RN1.8
ADATA7: IC4.9, IC7.12, IC10.9, IC13.12, IC20.9, IC23.12, IC30.9, IC35.11, IC45.12, RN1.9
ADATA8: IC5.15, IC8.9, IC11.15, IC14.9, IC21.15, IC24.9, IC36.18, IC37.18, IC43.15, IC46.9, RN2.2
ADATA9: IC5.1, IC8.7, IC11.1, IC14.7, IC21.1, IC24.7, IC36.17, IC37.17, IC43.1, IC46.7, RN2.3
ADATA10: IC5.10, IC8.5, IC11.10, IC14.5, IC21.10, IC24.5, IC36.16, IC37.16, IC43.10, IC46.5, RN2.4
ADATA11: IC5.9, IC8.3, IC11.9, IC14.3, IC21.9, IC24.3, IC36.15, IC37.15, IC43.9, IC46.3, RN2.5
ADATA12: IC6.15, IC8.18, IC12.15, IC14.18, IC22.15, IC24.18, IC36.14, IC37.14, IC44.15, IC46.18, RN2.6
ADATA13: IC6.1, IC8.16, IC12.1, IC14.16, IC22.1, IC24.16, IC36.13, IC37.13, IC44.1, IC46.16, RN2.7
ADATA14: IC6.10, IC8.14, IC12.10, IC14.14, IC22.10, IC24.14, IC36.12, IC37.12, IC44.10, IC46.14, RN2.8
ADATA15: IC6.9, IC8.12, IC12.9, IC14.12, IC22.9, IC24.12, IC36.11, IC37.11, IC44.9, IC46.12, RN2.9
ADDR0: IC17.18, IC27.18, IC41.18, IC49.18, X1.A3
ADDR1: IC17.16, IC27.16, IC41.16, IC49.16, X1.A4
ADDR2: IC17.14, IC27.14, IC41.14, IC49.14, X1.A5
ADDR3: IC17.12, IC27.12, IC41.12, IC49.12, X1.A6
ADDR4: IC17.9, IC27.9, IC41.9, IC49.9, X1.A7
ADDR5: IC17.7, IC27.7, IC41.7, IC49.7, X1.A8
ADDR6: IC17.5, IC27.5, IC41.5, IC49.5, X1.A9
ADDR7: IC17.3, IC27.3, IC41.3, IC49.3, X1.A10
ADDR8: IC18.18, IC28.18, IC42.18, IC50.18, X1.A11
ADDR9: IC18.16, IC28.16, IC42.16, IC50.16, X1.A12
ADDR10: IC18.14, IC28.14, IC42.14, IC50.14, X1.A13
ADDR11: IC18.12, IC28.12, IC42.12, IC50.12, X1.A14
ADDR12: IC18.9, IC28.9, IC42.9, IC50.9, X1.A15
ADDR13: IC18.7, IC28.7, IC42.7, IC50.7, X1.A16
ADDR14: IC18.5, IC28.5, IC42.5, IC50.5, X1.A17
ADDR15: IC18.3, IC28.3, IC42.3, IC50.3, X1.A18
ADDR-REG-ID0: IC38.2, X1.C3
ADDR-REG-ID1: IC38.3, X1.C4
ADDR-REG-ID2: IC38.14, X1.C5
ADDR-REG-ID3: IC38.13, X1.C6
BUS-DIR: IC34.4, IC35.1, IC36.1, IC37.1
DATA0: IC35.2, IC37.2, X1.A19
DATA1: IC35.3, IC37.3, X1.A20
DATA2: IC35.4, IC37.4, X1.A21
DATA3: IC35.5, IC37.5, X1.A22
DATA4: IC35.6, IC37.6, X1.A23
DATA5: IC35.7, IC37.7, X1.A24
DATA6: IC35.8, IC37.8, X1.A25
DATA7: IC35.9, IC37.9, X1.A26
DATA8: IC36.2, X1.A27
DATA9: IC36.3, X1.A28
DATA10: IC36.4, X1.A29
DATA11: IC36.5, X1.A30
DATA12: IC36.6, X1.B3
DATA13: IC36.7, X1.B4
DATA14: IC36.8, X1.B5
DATA15: IC36.9, X1.B6
GND: C1.2, C2.2, C3.2, C4.2, C5.2, C6.2, C7.2, C8.2, C9.2, C10.2, C11.2, C12.2, C13.2, C14.2, C15.2, C16.2, C17.2, C18.2, C19.2, C20.2, C21.2, C22.2, C23.2, C24.2, C25.2, C26.2, C27.2, C28.2, C29.2, C30.2, C31.2, C32.2, C33.2, C34.2, C35.2, C36.2, C37.2, C38.2, C39.2, C40.2, C41.2, C42.2, C43.2, C44.2, C45.2, C46.2, C47.2, IC1.7, IC2.7, IC3.8, IC4.8, IC5.8, IC6.8, IC7.10, IC8.10, IC9.8, IC10.8, IC11.8, IC12.8, IC13.10, IC14.10, IC15.7, IC17.10, IC18.10, IC19.8, IC20.8, IC21.8, IC22.8, IC23.10, IC24.10, IC25.7, IC26.7, IC27.10, IC28.10, IC29.8, IC30.8, IC31.7, IC32.8, IC33.8, IC34.1, IC34.5, IC34.7, IC34.8, IC35.10, IC36.10, IC37.10, IC38.8, IC40.4, IC40.5, IC40.7, IC40.9, IC40.10, IC40.12, IC40.13, IC41.10, IC42.10, IC43.8, IC44.8, IC45.10, IC46.10, IC47.7, IC49.10, IC50.10, PWR0.K, X1.A1, X1.A32, X1.B1, X1.B32, X1.C1, X1.C32
unnamed: IC31.8, IC35.19, IC36.19
unnamed: IC9.13, IC10.4
unnamed: IC9.12, IC10.5
unnamed: IC10.13, IC11.4
unnamed: IC10.12, IC11.5
unnamed: IC11.13, IC12.4
unnamed: IC11.12, IC12.5
unnamed: IC9.11, IC10.11, IC15.8
unnamed: IC9.5, IC15.3
unnamed: IC3.13, IC4.4
unnamed: IC3.12, IC4.5
unnamed: IC4.13, IC5.4
unnamed: IC4.12, IC5.5
unnamed: IC5.13, IC6.4
unnamed: IC5.12, IC6.5
unnamed: IC1.8, IC3.11, IC4.11
unnamed: IC1.3, IC3.5
unnamed: IC1.6, IC3.4
unnamed: IC31.3, IC32.1
unnamed: IC2.3, IC7.1, IC7.19
unnamed: IC2.6, IC8.1, IC8.19
unnamed: IC1.11, IC5.11, IC6.11
unnamed: IC9.4, IC15.6
unnamed: IC31.6, IC32.15
unnamed: IC2.8, IC13.1, IC13.19
unnamed: IC2.11, IC14.1, IC14.19
unnamed: IC11.11, IC12.11, IC15.11
unnamed: IC9.3, IC13.11, IC17.2
unnamed: IC9.2, IC13.13, IC17.4
unnamed: IC9.6, IC13.15, IC17.6
unnamed: IC9.7, IC13.17, IC17.8
unnamed: IC10.3, IC13.2, IC17.11
unnamed: IC10.2, IC13.4, IC17.13
unnamed: IC10.6, IC13.6, IC17.15
unnamed: IC10.7, IC13.8, IC17.17
unnamed: IC11.3, IC14.11, IC18.2
unnamed: IC31.11, IC37.19
unnamed: IC11.2, IC14.13, IC18.4
unnamed: IC11.6, IC14.15, IC18.6
unnamed: IC11.7, IC14.17, IC18.8
unnamed: IC31.9, IC34.10
unnamed: IC31.10, IC31.12, IC34.11
unnamed: IC32.5, J1.3
unnamed: PWR0.A, R1.1
unnamed: IC38.15, IC40.3
unnamed: IC32.6, J1.5
unnamed: IC32.7, J1.7
unnamed: IC32.11, J2.3
unnamed: IC32.10, J2.5
unnamed: IC32.9, J2.7
unnamed: IC38.11, J3.3
unnamed: IC38.10, J3.5
unnamed: IC38.9, J3.7
unnamed: IC12.3, IC14.2, IC18.11
unnamed: IC12.2, IC14.4, IC18.13
unnamed: IC12.6, IC14.6, IC18.15
unnamed: IC12.7, IC14.8, IC18.17
unnamed: IC19.13, IC20.4
unnamed: IC19.12, IC20.5
unnamed: IC20.13, IC21.4
unnamed: IC20.12, IC21.5
unnamed: IC21.13, IC22.4
unnamed: IC21.12, IC22.5
unnamed: IC19.11, IC20.11, IC25.8
unnamed: IC19.5, IC25.3
unnamed: IC19.4, IC25.6
unnamed: IC23.1, IC23.19, IC26.3
unnamed: IC24.1, IC24.19, IC26.6
unnamed: IC21.11, IC22.11, IC25.11
unnamed: IC19.3, IC23.11, IC27.2
unnamed: IC19.2, IC23.13, IC27.4
unnamed: IC19.6, IC23.15, IC27.6
unnamed: IC19.7, IC23.17, IC27.8
unnamed: IC20.3, IC23.2, IC27.11
unnamed: IC20.2, IC23.4, IC27.13
unnamed: IC20.6, IC23.6, IC27.15
unnamed: IC20.7, IC23.8, IC27.17
unnamed: IC21.3, IC24.11, IC28.2
unnamed: IC21.2, IC24.13, IC28.4
unnamed: IC21.6, IC24.15, IC28.6
unnamed: IC21.7, IC24.17, IC28.8
unnamed: IC22.3, IC24.2, IC28.11
unnamed: IC22.2, IC24.4, IC28.13
unnamed: IC22.6, IC24.6, IC28.15
unnamed: IC22.7, IC24.8, IC28.17
unnamed: IC29.13, IC30.4
unnamed: IC29.12, IC30.5
unnamed: IC30.13, IC43.4
unnamed: IC30.12, IC43.5
unnamed: IC43.13, IC44.4
unnamed: IC43.12, IC44.5
unnamed: IC29.11, IC30.11, IC47.8
unnamed: IC29.5, IC47.3
unnamed: IC29.4, IC47.6
unnamed: IC26.8, IC45.1, IC45.19
unnamed: IC26.11, IC46.1, IC46.19
unnamed: IC43.11, IC44.11, IC47.11
unnamed: IC29.3, IC45.11, IC49.2
unnamed: IC29.2, IC45.13, IC49.4
unnamed: IC29.6, IC45.15, IC49.6
unnamed: IC29.7, IC45.17, IC49.8
unnamed: IC30.3, IC45.2, IC49.11
unnamed: IC30.2, IC45.4, IC49.13
unnamed: IC30.6, IC45.6, IC49.15
unnamed: IC30.7, IC45.8, IC49.17
unnamed: IC43.3, IC46.11, IC50.2
unnamed: IC43.2, IC46.13, IC50.4
unnamed: IC43.6, IC46.15, IC50.6
unnamed: IC43.7, IC46.17, IC50.8
unnamed: IC44.3, IC46.2, IC50.11
unnamed: IC44.2, IC46.4, IC50.13
unnamed: IC44.6, IC46.6, IC50.15
unnamed: IC44.7, IC46.8, IC50.17
unnamed: IC3.3, IC7.11, IC41.2
unnamed: IC3.2, IC7.13, IC41.4
unnamed: IC3.6, IC7.15, IC41.6
unnamed: IC3.7, IC7.17, IC41.8
unnamed: IC4.3, IC7.2, IC41.11
unnamed: IC4.2, IC7.4, IC41.13
unnamed: IC4.6, IC7.6, IC41.15
unnamed: IC4.7, IC7.8, IC41.17
unnamed: IC5.3, IC8.11, IC42.2
unnamed: IC5.2, IC8.13, IC42.4
unnamed: IC5.6, IC8.15, IC42.6
unnamed: IC5.7, IC8.17, IC42.8
unnamed: IC6.3, IC8.2, IC42.11
unnamed: IC6.2, IC8.4, IC42.13
unnamed: IC6.6, IC8.6, IC42.15
unnamed: IC6.7, IC8.8, IC42.17
REG-LD-ID0: IC33.14, X1.B13
REG-LD-ID1: IC33.13, X1.B14
REG-LD-ID2: IC32.14, X1.B15
REG-LD-ID3: IC32.13, X1.B16
REG-RD-ID0: IC33.2, X1.B9
REG-RD-ID1: IC33.3, X1.B10
REG-RD-ID2: IC32.2, X1.B11
REG-RD-ID3: IC32.3, X1.B12
RESET: IC3.14, IC4.14, IC5.14, IC6.14, IC9.14, IC10.14, IC11.14, IC12.14, IC19.14, IC20.14, IC21.14, IC22.14, IC29.14, IC30.14, IC34.3, IC43.14, IC44.14
VCC: C1.1, C2.1, C3.1, C4.1, C5.1, C6.1, C7.1, C8.1, C9.1, C10.1, C11.1, C12.1, C13.1, C14.1, C15.1, C16.1, C17.1, C18.1, C19.1, C20.1, C21.1, C22.1, C23.1, C24.1, C25.1, C26.1, C27.1, C28.1, C29.1, C30.1, C31.1, C32.1, C33.1, C34.1, C35.1, C36.1, C37.1, C38.1, C39.1, C40.1, C41.1, C42.1, C43.1, C44.1, C45.1, C46.1, C47.1, IC1.14, IC2.14, IC3.16, IC4.16, IC5.16, IC6.16, IC7.20, IC8.20, IC9.16, IC10.16, IC11.16, IC12.16, IC13.20, IC14.20, IC15.14, IC17.20, IC18.20, IC19.16, IC20.16, IC21.16, IC22.16, IC23.20, IC24.20, IC25.14, IC26.14, IC27.20, IC28.20, IC29.16, IC30.16, IC31.14, IC32.16, IC33.16, IC34.14, IC35.20, IC36.20, IC37.20, IC38.16, IC40.14, IC41.20, IC42.20, IC43.16, IC44.16, IC45.20, IC46.20, IC47.14, IC49.20, IC50.20, R1.2, RN1.1, RN2.1, X1.A2, X1.A31, X1.B2, X1.B31, X1.C2, X1.C31

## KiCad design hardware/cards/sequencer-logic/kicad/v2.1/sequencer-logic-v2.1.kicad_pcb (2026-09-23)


Board: 4 copper layers, 218.4 x 114.0 mm, 108 parts (0 on the bottom side), 282 nets.

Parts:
-INT-PULLUP0: 1X02
.0: OUT; LED5MM
C1, C2, C3, C4, C5, C6, C7, C8, C9, C10, C11, C12, C13, C14, C15, C16, C17, C18, C19, C20, C21, C22, C23, C24, C25, C26, C27, C28, C29, C30, C31, C32, C33, C34, C35, C36, C37, C38: .1; CAP-PTH-SMALLEZ
CONT0: SWITCH-MOMENTARY-2SIDE_EZ; TACTILE-PTH-SIDEEZ
HALT0: SWITCH-MOMENTARY-2SIDE_EZ; TACTILE-PTH-SIDEEZ
IC1, IC2, IC4, IC5, IC11, IC15, IC18, IC35: 74LS244N; DIL20
IC3, IC6, IC7, IC10, IC12, IC13, IC14, IC16, IC17, IC19, IC20, IC21, IC28: 74LS374N; DIL20
IC8, IC9: 74LS175N; DIL16
IC22, IC29, IC32: 74ALS02N; DIL14
IC23: 74LS74N; DIL14
IC24, IC27, IC38: 74LS08N; DIL14
IC25, IC26, IC30: 74LS32N; DIL14
IC31, IC36, IC37: 74LS04N; DIL14
IC33, IC34: 74LS192N; DIL16
JP1: 2X02
JP2: PINHD-1X2; 1X02
JP3: 1X05
JP4: PINHD-1X4; 1X04
PWR0: LED5MM
QG1: DIL14S
R1, R3, R4, R5, R6, R7, R8, R9, R10, R11: 10k; 0207_10
R2: 330; 0207_10
RESET0: 9070-1W
SS-SEL0: 1X03
SS/WAIT0: 9070-1W
STEP-CLK0: 9070-1W
SV1, SV2: MA20-2
UNK_HOLE_0: dummyfp0
UNK_HOLE_1: dummyfp1
UNK_HOLE_2: dummyfp2
UNK_HOLE_3: dummyfp3
X1: FABC96R

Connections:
-2-BYTE-OPERAND-SEL: IC5.1, IC5.19, IC16.16, IC31.3
-AC-LD: IC28.5, X1.C22
-AC-LD-INV: IC7.19, X1.C20
-AC-RD: IC28.2, X1.C21
-ALU-FUNC: IC7.6, X1.C15
-BRANCH-RD: IC13.1, IC16.2, IC21.1
-BUS-EN: IC7.1, IC12.1, IC14.1, IC15.1, IC15.19, IC16.1, IC17.1, IC19.1, IC20.1, IC28.1, IC35.1, IC35.19, IC36.8, X1.C28
-DO-INT: IC1.1, IC1.19, IC36.2
-FP-HALT: HALT0.2, IC31.1, R4.1
-HALT-CONT: CONT0.2, IC31.9, R3.1
-HL-SWAP: IC28.12, X1.C25
-INT: -INT-PULLUP0.2, JP3.3, X1.C13
-INT-JMP: IC3.1, IC10.1, IC16.12
-INTA: IC17.2, X1.C14
-IO-ADDR-LD: IC7.2, X1.C11
-IO-RD: IC14.6, X1.B25
-IO-WR: IC14.9, X1.B26
-MEM-CPU-RESET: JP1.2, JP2.1
-MEM-RD: IC14.2, X1.B23
-MEM-WR: IC14.5, X1.B24
-ONE-OPERAND-SEL: IC4.1, IC4.19, IC18.19, IC31.4
-REG-DN: IC12.16, X1.B21
-REG-FUNC-LD: IC20.5, X1.B8
-REG-FUNC-RD: IC20.2, X1.B7
-REG-LD-HI: IC31.12, X1.B20
-REG-LD-LO: IC31.10, X1.B18
-REG-RD-HI: IC12.12, X1.B19
-REG-RD-LO: IC12.6, X1.B17
-REG-UP: IC12.19, X1.B22
-RESET: IC8.1, IC9.1, IC36.6, X1.C30
-SR-LD: IC28.6, X1.C23
-TMP-REG-LD0: IC14.15, X1.B28
-TMP-REG-LD1: IC14.19, X1.B30
-TMP-REG-RD0: IC14.12, X1.B27
-TMP-REG-RD1: IC14.16, X1.B29
-VMA: IC7.5, X1.C12
ADDR-REG-ID0: IC11.18, IC18.9, IC18.18, X1.C3
ADDR-REG-ID1: IC11.16, IC18.7, IC18.16, X1.C4
ADDR-REG-ID2: IC11.14, IC18.5, IC18.14, X1.C5
ADDR-REG-ID3: IC11.12, IC18.3, IC18.12, X1.C6
ALU0: IC7.9, X1.C16
ALU1: IC7.12, X1.C17
ALU2: IC7.15, X1.C18
ALU3: IC7.16, X1.C19
BR-COND: IC27.1, X1.C24
BR-TEST: IC27.2, IC28.9
BRANCH-LD-HI: IC13.11, IC16.9
BRANCH-LD-LO: IC16.5, IC21.11
BUS-LATCH-CLK: IC7.11, IC12.11, IC14.11, IC16.11, IC17.11, IC19.11, IC20.11, IC25.11, IC28.11
CADDR0: IC35.16, SV1.14
CADDR1: IC35.14, SV1.16
CADDR2: IC35.12, SV1.18
CADDR3: IC35.9, SV1.20
CADDR4: IC35.7, SV1.22
CADDR5: IC35.5, SV1.24
CADDR6: IC15.18, SV1.26
CADDR7: IC15.16, SV1.28
CADDR8: IC15.14, SV1.30
CADDR9: IC15.12, SV1.32
CADDR10: IC15.9, SV1.34
CADDR11: IC15.7, SV1.36
CADDR12: IC15.5, SV1.38
CADDR13: IC15.3, SV1.2
CNT-CLK: IC25.13, IC35.18
COUNT-FAULT: IC26.12, IC35.3
COUNT-RESET: IC26.3, IC33.14, IC34.14
DATA0: IC2.2, IC3.3, IC6.3, IC10.2, IC10.3, IC13.3, IC21.2, IC21.3, X1.A19
DATA1: IC2.4, IC3.4, IC6.4, IC10.4, IC10.5, IC13.4, IC21.4, IC21.5, X1.A20
DATA2: IC2.6, IC3.7, IC6.7, IC10.6, IC10.7, IC13.7, IC21.6, IC21.7, X1.A21
DATA3: IC2.8, IC3.8, IC6.8, IC10.8, IC10.9, IC13.8, IC21.8, IC21.9, X1.A22
DATA4: IC2.11, IC3.13, IC6.13, IC10.12, IC10.13, IC13.13, IC21.12, IC21.13, X1.A23
DATA5: IC2.13, IC3.14, IC6.14, IC10.14, IC10.15, IC13.14, IC21.14, IC21.15, X1.A24
DATA6: IC2.15, IC3.17, IC6.17, IC10.16, IC10.17, IC13.17, IC21.16, IC21.17, X1.A25
DATA7: IC2.17, IC3.18, IC6.18, IC10.18, IC10.19, IC13.18, IC21.18, IC21.19, X1.A26
DATA8: IC3.2, IC13.2, X1.A27
DATA9: IC3.5, IC13.5, X1.A28
DATA10: IC3.6, IC13.6, X1.A29
DATA11: IC3.9, IC13.9, X1.A30
DATA12: IC3.12, IC13.12, X1.B3
DATA13: IC3.15, IC13.15, X1.B4
DATA14: IC3.16, IC13.16, X1.B5
DATA15: IC3.19, IC13.19, X1.B6
DEST-ADDR: IC11.1, IC16.19
DO-HALT: IC23.9, IC26.13
DO-INT: IC2.1, IC2.19, IC24.8, IC36.1
EXTERNAL-SINGLESTEP-CLK: JP4.2, SS-SEL0.3
FP-CLKH: IC29.12, R10.1, STEP-CLK0.3
FP-CLKL: IC29.8, R11.2, STEP-CLK0.1
FP-EXECUTE: IC32.6, R6.1, RESET0.3
FP-FREERUN: IC29.2, R9.2, SS/WAIT0.1
FP-HALT: IC24.12, IC31.2
FP-HALT-CONT: IC31.8, IC32.12
FP-RESET: IC32.2, R7.2, RESET0.1
FP-SINGLE-STEP-CLK: IC29.10, IC29.11, SS-SEL0.1
FP-SS: IC29.6, R8.1, SS/WAIT0.3
FREE-RUN: IC29.3, IC29.4, IC38.10
GND: .0.K, C1.2, C2.2, C3.2, C4.2, C5.2, C6.2, C7.2, C8.2, C9.2, C10.2, C11.2, C12.2, C13.2, C14.2, C15.2, C16.2, C17.2, C18.2, C19.2, C20.2, C21.2, C22.2, C23.2, C24.2, C25.2, C26.2, C27.2, C28.2, C29.2, C30.2, C31.2, C32.2, C33.2, C34.2, C35.2, C36.2, C37.2, C38.2, CONT0.1, HALT0.1, IC1.10, IC2.10, IC3.10, IC4.10, IC5.10, IC6.1, IC6.10, IC7.10, IC8.8, IC9.8, IC10.10, IC11.10, IC11.11, IC11.13, IC11.15, IC11.17, IC11.19, IC12.10, IC13.10, IC14.10, IC15.10, IC16.10, IC17.10, IC18.10, IC19.10, IC20.10, IC21.10, IC22.7, IC23.7, IC24.7, IC25.7, IC26.7, IC27.7, IC28.10, IC29.7, IC30.7, IC31.7, IC32.7, IC33.1, IC33.8, IC33.9, IC33.10, IC33.15, IC34.1, IC34.8, IC34.9, IC34.10, IC34.15, IC35.10, IC36.7, IC37.7, IC37.11, IC38.7, JP3.1, JP3.5, JP4.1, JP4.4, PWR0.K, QG1.7, R6.2, R7.1, R8.2, R9.1, R10.2, R11.1, SV1.39, SV1.40, X1.A1, X1.A32, X1.B1, X1.B32, X1.C1, X1.C32
HALT-CLR: IC23.13, IC32.13
HARD-RESET1: IC29.9, IC29.13
INT-EDGE: IC23.3, JP3.2
INT-EN: IC17.12, IC22.6
INT-LD-HI: IC3.11, IC17.6
INT-LD-LO: IC10.11, IC16.15
INT-LEVEL: IC36.13, JP3.4
INT-START: IC17.9, IC30.9
IO-ADDR0: IC19.12, X1.C7
IO-ADDR1: IC19.15, X1.C8
IO-ADDR2: IC19.16, X1.C9
IO-ADDR3: IC19.19, X1.C10
LADDR-REG-ID0: IC18.11, IC19.2
LADDR-REG-ID1: IC18.13, IC19.5
LADDR-REG-ID2: IC18.15, IC19.6
LADDR-REG-ID3: IC18.17, IC19.9
LD-INS-REG: IC17.15, IC24.1
LD-INS-REG1: IC8.9, IC9.9, IC24.3
LREG-LD-HI: IC12.15, IC24.5
LREG-LD-ID0: IC4.11, IC20.16
LREG-LD-ID1: IC4.13, IC20.19
LREG-LD-ID2: IC4.15, IC12.2
LREG-LD-ID3: IC4.17, IC12.5
LREG-LD-LO: IC12.9, IC27.13
LREG-RD-ID0: IC4.2, IC20.6
LREG-RD-ID1: IC4.4, IC20.9
LREG-RD-ID2: IC4.6, IC20.12
LREG-RD-ID3: IC4.8, IC20.15
unnamed: IC33.12, IC34.5
unnamed: IC9.2, IC15.2
unnamed: IC9.7, IC15.4
unnamed: IC27.5, IC33.5, IC38.6
unnamed: IC1.18, IC2.18, IC9.4
unnamed: IC1.16, IC2.16, IC9.5
unnamed: IC33.3, IC35.2
unnamed: IC33.2, IC35.4
unnamed: IC33.6, IC35.6
unnamed: IC9.10, IC15.6
unnamed: IC33.7, IC35.8
unnamed: IC34.3, IC35.11
unnamed: IC34.2, IC35.13
unnamed: IC34.6, IC35.15
unnamed: IC34.7, IC35.17
unnamed: IC31.6, IC38.1
unnamed: IC1.14, IC2.14, IC9.12
unnamed: IC1.12, IC2.12, IC9.13
unnamed: IC1.9, IC2.9, IC8.4
unnamed: IC1.7, IC2.7, IC8.5
unnamed: IC1.5, IC2.5, IC8.12
unnamed: IC1.3, IC2.3, IC8.13
unnamed: IC9.15, IC15.8
unnamed: IC22.1, IC22.5, IC24.10
unnamed: IC22.3, IC22.4
unnamed: IC26.11, IC31.5
unnamed: IC22.2, IC30.8, IC36.3
unnamed: IC23.5, IC24.9
unnamed: IC23.1, IC36.4
unnamed: PWR0.A, R1.1
unnamed: IC38.3, IC38.4
unnamed: IC25.12, IC32.10
unnamed: IC23.11, IC25.6
unnamed: IC8.2, IC15.11
unnamed: IC8.7, IC15.13
unnamed: IC8.10, IC15.15
unnamed: IC8.15, IC15.17
unnamed: IC26.5, IC38.11
unnamed: IC26.4, IC38.8
unnamed: IC38.9, QG1.8
unnamed: IC23.4, IC36.12
unnamed: IC36.11, IC37.8
unnamed: IC37.2, IC37.9
unnamed: IC25.3, IC25.9
unnamed: IC32.9, IC36.10
unnamed: IC25.10, IC30.11
unnamed: IC22.10, IC22.12
unnamed: -INT-PULLUP0.1, R5.2
unnamed: IC27.9, IC37.12
unnamed: IC27.8, IC30.5
unnamed: IC24.4, IC27.12, IC30.6
unnamed: IC24.11, IC25.4
unnamed: IC26.2, IC27.6
unnamed: IC25.8, IC30.4, IC37.13
unnamed: IC27.11, IC31.11
unnamed: IC24.6, IC31.13
unnamed: .0.A, R2.1
unnamed: IC26.8, IC37.3
unnamed: IC5.17, IC6.19, IC11.8
unnamed: IC5.2, IC6.2, IC18.2
unnamed: IC5.4, IC6.5, IC18.4
unnamed: IC5.6, IC6.6, IC18.6
unnamed: IC5.8, IC6.9, IC18.8
unnamed: IC5.11, IC6.12, IC11.2
unnamed: IC30.3, IC37.5
unnamed: IC5.13, IC6.15, IC11.4
unnamed: IC5.15, IC6.16, IC11.6
unnamed: IC30.1, IC37.4
unnamed: IC26.10, IC27.10, IC37.6
unnamed: IC26.9, IC27.3
OPERAND-CLK: IC6.11, IC17.19
OUT: IC22.8, IC22.13, R2.2, X1.C27
OUT-OFF: IC22.11, IC28.16
OUT-ON: IC22.9, IC28.19
READY: IC36.9, SV1.12
REG-LD-ID0: IC4.9, IC5.9, IC25.1, X1.B13
REG-LD-ID1: IC4.7, IC5.7, IC25.2, X1.B14
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

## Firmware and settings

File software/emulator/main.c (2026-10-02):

/*
 * Author: Ken Rother (original)
 * Changes: Claude (Anthropic), 2026 - see tools/patched_files.txt
 */

/*
 * To change this license header, choose License Headers in Project Properties.
 * To change this template file, choose Tools | Templates
 * and open the template in the editor.
 */

/* 
 * File:   main.c
 * Author: kennethrother
 *
 * Created on October 23, 2020, 1:04 PM
 */

#include <stdio.h>
#include <stdlib.h>
#include <stdbool.h>
#include <string.h>
#include <termios.h>
#include <unistd.h>
#include <ctype.h>
#include <poll.h>             /* YACC1-D 2026-09-26: the UART model's non-blocking data-ready poll */
#include "../opcodes.h"
#include <stdint.h>
#include "../cfmodel.h"        /* YACC1-D 2026-09-22: the CompactFlash card on ports P8 (select) / P9 (data), -c image */
#include "../videomodel.h"     /* YACC1-D 2026-09-25: the video card in $D000-$DFFF (-V screen dump, -W CRTC log, -N absent) */

#define DEBUG 0

#if DEBUG
#define DEBUG_PRINTF(...)  printf(__VA_ARGS__)
#else
#define DEBUG_PRINTF(...)
#endif

#define MEMORY_SIZE 0x10000
#define REGISTERS 9
#define PC 0
#define SP 1
#define PORTS 16

#define IR 8 //HACK
#define ZP 6 /* YACC1-D 2026-09-24: the page register of LDZ/STZ (its high byte) */

#define REG0 0
#define REG1 1
#define REG2 2
#define REG3 3
#define REG4 4
#define REG5 5
#define REG6 6
#define REG7 7

#define PORT0 0
#define PORT1 1
#define PORT2 2
#define PORT3 3
#define PORT4 4
#define PORT5 5
#define PORT6 6
#define PORT7 7
#define PORT8 8
#define PORT9 9
#define PORT10 10
#define PORT11 11
#define PORT12 12
#define PORT13 13
#define PORT14 14
#define PORT15 15

union Register {
    unsigned char byte[2];
    unsigned short word;
} registers[REGISTERS];

unsigned char port[PORTS];

unsigned char memory[MEMORY_SIZE];

unsigned char acc;
unsigned char treg;
int out;
int in;
int jsrdepth;
int pushpopdepth;
int pushpoprdepth;
bool carry;
int firstSwitchRead = 1; // What is this
/* -S (YACC1-D 2026-09-25): the program watch. Every JSRUR to $5000 is Y1/OS starting a program (run_prog; a program
   that EXECs another ends and the next starts the same way) and begins a segment; at the next one and at exit a line
   on stderr reports it: "program N: I instructions" from its first to its last instruction in the program area
   $5000-$CFFF (the syscalls between included), and, for a program on its own stack (y1cc --stack: MVIW R1 into the
   area), ", stack $top down to $low, B bytes", the deepest point it reached (tests/native: the compiler passes
   against their data) */
int stackwatch = 0, sseg = 0;
unsigned sstart = 0, smin = 0x10000;
unsigned long icount = 0;       /* instructions executed (reported at a -x HALT) */
unsigned long sicount = 0, slast = 0;  /* -S: icount when the program started, when it last ran an instruction */
void stack_report(void) {
    if (!stackwatch || !sseg) return;
    fprintf(stderr, "program %d: %lu instructions", sseg, slast - sicount + 1);
    if (sstart && smin < 0x10000) fprintf(stderr, ", stack $%04X down to $%04X, %u bytes", sstart, smin, sstart - smin);
    fprintf(stderr, "\n");
}
/* -P FILE (YACC1-D 2026-09-25): the PC histogram, for profiling. Every instruction counts at its address; at every
   program start (a JSRUR to $5000, as -S sees it) and at exit the counts so far go to FILE as a block
   "program N" (0 = before the first program: the monitor, the OS booting) and one line "AAAA count" per address that
   ran, then start again from zero; tests/native/profile.py turns the blocks into instructions per function from the
   programs' and the OS's assembly */
FILE *pcfile = NULL;
unsigned long pchist[65536];
int pcseg = 0;
void pc_dump(void) {
    if (!pcfile) return;
    fprintf(pcfile, "program %d\n", pcseg);
    for (unsigned a = 0; a < 65536; a++) if (pchist[a]) { fprintf(pcfile, "%04X %lu\n", a, pchist[a]); pchist[a] = 0; }
    fflush(pcfile);
}
void pc_exit(void) { pc_dump(); if (pcfile) fclose(pcfile); pcfile = NULL; }
int exit_on_halt = 0;           /* YACC1-D 2026-09-22: -x, for scripted runs (compiler tests): quiet load, exit at HALT */
unsigned long ilimit = 0;       /* -l N: stop after N instructions (scripted runs of code that never HALTs) */

/* Intel HEX read/write functions, Paul Stoffregen, paul@ece.orst.edu */
/* This code is in the public domain.  Please retain my name and */
/* email address in distributed copies, and let me know about any bugs */

/* I, Paul Stoffregen, give no warranty, expressed or implied for */
/* this software and/or documentation provided, including, without */
/* limitation, warranty of merchantability and fitness for a */
/* particular purpose. */

/* some ansi prototypes.. maybe ought to make a .h file */

/* this loads an intel hex file into the memory[] array */
void load_file(char *filename);

/* this is used by load_file to get each line of intex hex */
int parse_hex_line(char *theline, int bytes[], int *addr, int *num, int *code);

/* prints usage information for the emulator */
void print_usage(const char *progname);

/* parses a line of intel hex code, stores the data in bytes[] */
/* and the beginning address in addr, and returns a 1 if the */
/* line was valid, or a 0 if an error occured.  The variable */

/* num gets the number of bytes that were stored into bytes[] */

int parse_hex_line(char *theline, int bytes[], int *addr, int *num, int *code)
{
    int sum, len, cksum;
    char *ptr;

    *num = 0;
    if (theline[0] != ':') return 0;
    if (strlen(theline) < 11) return 0;
    ptr = theline + 1;
    if (!sscanf(ptr, "%02x", &len)) return 0;
    ptr += 2;
    if (strlen(theline) < (11 + (len * 2))) return 0;
    if (!sscanf(ptr, "%04x", addr)) return 0;
    ptr += 4;
    /* printf("Line: length=%d Addr=%d\n", len, *addr); */
    if (!sscanf(ptr, "%02x", code)) return 0;
    ptr += 2;
    sum = (len & 255) + ((*addr >> 8) & 255) + (*addr & 255) + (*code & 255);
    while (*num != len) {
        if (!sscanf(ptr, "%02x", &bytes[*num])) return 0;
        ptr += 2;
        sum += bytes[*num] & 255;
        (*num)++;
        if (*num >= 256) return 0;
    }
    if (!sscanf(ptr, "%02x", &cksum)) return 0;
    if (((sum & 255) + (cksum & 255)) & 255) return 0; /* checksum error */
    return 1;
}

/* loads an intel hex file into the global memory[] array */

/* filename is a string of the file to be opened */

void load_file(char *filename)
{
    char lp[1000],*line;

    FILE *fin;
    int addr, n, status, bytes[256];
    int i, total = 0, lineno = 1;
    int minaddr = 65536, maxaddr = 0;

    line=lp;

    if (strlen(filename) == 0) {
        printf("   Can't load a file without the filename.");
        printf("  '?' for help\n");
        return;
    }
    fin = fopen(filename, "r");
    if (fin == NULL) {
        printf("   Can't open file '%s' for reading.\n", filename);
        return;
    }
    while (!feof(fin) && !ferror(fin)) {
        line[0] = '\0';
        fgets(line, 1000, fin);
        if (line[strlen(line) - 1] == '\n') line[strlen(line) - 1] = '\0';
        if (line[strlen(line) - 1] == '\r') line[strlen(line) - 1] = '\0';
        if (parse_hex_line(line, bytes, &addr, &n, &status)) {
            if (status == 0) { /* data */
                for (i = 0; i <= (n - 1); i++) {
                    memory[addr] = bytes[i] & 255;
                    total++;
                    if (addr < minaddr) minaddr = addr;
                    if (addr > maxaddr) maxaddr = addr;
                    addr++;
                }
            }
            if (status == 1) { /* end of file */
                fclose(fin);
                if (!exit_on_halt) {
                    printf("   Loaded %d bytes between:", total);
                    printf(" %04X to %04X\n", minaddr, maxaddr);
                }
                return;
            }
            if (status == 2)
                ; /* begin of file */
        } else {
            printf("   Error: '%s', line: %d\n", filename, lineno);
        }
        lineno++;
    }
}

void regdump() {
    int i;

    printf("reg dump - ");
    for (i = 0; i < REGISTERS; i++)
        printf("%d=[%04x]", i, registers[i].word);
    printf("\n");
}

void dump(int start, int end) {
    int i;

    printf("dump %04x %04x\n", start, end);
    for (i = start; i < end; i++) {
        if ((i & 0x0f) == 0)
            printf("\n %04x ", i);
        printf("%02x ", memory[i]);
    }
    printf("\n");
}

/* YACC1-D 2026-09-25: the video card's block goes through software/videomodel.h (display RAM = memory[], the
   CRTC/latch half modelled, -N absent: reads $FF, writes ignored); mem_rd/mem_wr are also LDAVR/STAVR/LDIVR's path */
static unsigned char mem_rd(int address) {
    if (vid_in(address)) { int v = vid_read(address, memory); return v < 0 ? 0xFF : v; }
    return memory[address];
}
static void mem_wr(int address, unsigned char value) {
    if (vid_in(address)) vid_write(address, value, memory); else memory[address] = value;
}
static void vid_exit(void) { fflush(stdout); vid_dump(memory); }

unsigned char memory_read(int address) {
    return (mem_rd(address));
}

void memory_write(int address, unsigned char value) {
    if (address > 0xdfff) {
        printf("Rom Write\n");
        regdump();
        exit(0);
    }
    /*   if ((address == 0x0204) && (value == 0)) {
           printf("argh\n");
           regdump();
       }
     */
    mem_wr(address, value);
}

unsigned char register_read_lo(int registernum) {
    if (registernum > REGISTERS) { //HACK FIX HARD CODE 8
        printf("reg error\n");
        exit(0);
    }
    return (registers[registernum].byte[0]);
}

unsigned char register_read_hi(int registernum) {
    if (registernum > REGISTERS) {
        printf("reg error\n");
        exit(0);
    }
    return (registers[registernum].byte[1]);
}

unsigned short register_read_word(int registernum) {
    if (registernum > REGISTERS) {
        printf("reg error\n");
        exit(0);
    }
    return (registers[registernum].word);
}

void register_write_lo(int registernum, unsigned char val) {
    if (registernum > REGISTERS) {
        printf("reg error\n");
        exit(0);
    }
    registers[registernum].byte[0] = val;
}

void register_write_hi(int registernum, unsigned char val) {
    if (registernum > REGISTERS) {
        printf("reg error\n");
        exit(0);
    }
    registers[registernum].byte[1] = val;
}

void register_write_word(int registernum, unsigned short val) {
    if (registernum > REGISTERS) {
        printf("reg error\n");
        exit(0);
    }
    registers[registernum].word = val;
}

void register_inc(int registernum) {
    registers[registernum].word++;
}

void register_dec(int registernum) {
    registers[registernum].word--;
}

unsigned char acc_read() {
    return acc;
}

void acc_write(unsigned char val) {
    acc = val;
}

unsigned char tmp_read() {
    return treg;
}

void tmp_write(unsigned char val) {
    treg = val;
}

void out_on() {
    out = 1;
    //printf("out on\n");
}

void out_off() {
    out = 0;
    //printf("out off\n");
}

void badOpcode(int ins) {
    printf("bad opcode [%02x] pc[%04x]\n", ins, register_read_word(PC));
    exit(0);
}
#define RUN 0
#define DEBUG_HALT 1
#define SINGLESTEP 2
#define JUMPOVER 3
int stepmode = 0;
int jsrdepth = 0;
int jsrover = 0;

char mygetchar();

void debug_mode(int mode) {
    char c;
    while (1) {
        c = mygetchar();
        c = toupper(c);
        if (c == 'C') {
            return;
        } else if (c == 'S') {
            stepmode = SINGLESTEP;
            jsrover = 0;
            return;
        } else if (c == 'R') {
            stepmode = RUN;
            return;
        } else if (c == 'J') {
            stepmode = JUMPOVER;
            jsrover = jsrdepth;
            return;
        } else if (c == 'D') {
            dump(0x0200, 0x021f);
            dump(0x0f80, 0x0f8f);
            dump(0x0400, 0x040F);
            dump(0x1000, 0x10FF);
            regdump();
        } else {
            return;
        }
    }
}


struct termios orig_termios;

void enableRawMode() {
    tcgetattr(STDIN_FILENO, &orig_termios);
    //atexit(disableRawMode);
    struct termios raw = orig_termios;
    raw.c_iflag &= ~(ICRNL | IXON);
    //raw.c_oflag &= ~(OPOST);
    //raw.c_lflag &= ~(ECHO | ICANON | IEXTEN | ISIG);
    raw.c_lflag &= ~(ICANON | IEXTEN | ISIG);
    tcsetattr(STDIN_FILENO, TCSAFLUSH, &raw);
}
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
int main(int argc, char** argv) {
    int ins;
    int reg;
    int portaddr;
    unsigned char hi, lo;
    int src, dest;
    bool tmpCarry;
    bool load_standard = false;
    char *load_filename = NULL;

    for (int arg = 1; arg < argc; ++arg) {
        if (strcmp(argv[arg], "-h") == 0) {
            print_usage(argv[0]);
            return EXIT_SUCCESS;
        } else if (strcmp(argv[arg], "-m") == 0) {
            load_standard = true;
        } else if (strcmp(argv[arg], "-S") == 0) {
            stackwatch = 1; atexit(stack_report);
        } else if (strcmp(argv[arg], "-P") == 0 && arg + 1 < argc) {
            if (!(pcfile = fopen(argv[++arg], "w"))) { fprintf(stderr, "cannot write %s\n", argv[arg]); return EXIT_FAILURE; }
            atexit(pc_exit);
        } else if (strcmp(argv[arg], "-V") == 0) {
            vid.dump = 1; atexit(vid_exit);
        } else if (strcmp(argv[arg], "-W") == 0) {
            vid.log = 1;
        } else if (strcmp(argv[arg], "-N") == 0) {
            vid.absent = 1;
        } else if (strcmp(argv[arg], "-x") == 0) {
            exit_on_halt = 1;
        } else if (strcmp(argv[arg], "-l") == 0 && arg + 1 < argc) {
            ilimit = strtoul(argv[++arg], NULL, 0);
        } else if (strcmp(argv[arg], "-c") == 0 && arg + 1 < argc) {
            if (!cf_attach(argv[++arg])) { fprintf(stderr, "cannot open CF image %s\n", argv[arg]); return EXIT_FAILURE; }
        } else if (strcmp(argv[arg], "-f") == 0) {
            if (arg + 1 < argc) {
                load_filename = argv[++arg];
            } else {
                fprintf(stderr, "Error: -f requires a filename\n");
                print_usage(argv[0]);
                return EXIT_FAILURE;
            }
        } else {
            fprintf(stderr, "Unknown option: %s\n", argv[arg]);
            print_usage(argv[0]);
            return EXIT_FAILURE;
        }
    }

    if (argc == 1) {
        load_standard = true;
    }

    if (!exit_on_halt) enableRawMode();

    /* ech testwhile (1) {
        myputchar(mygetchar());
        printf(" cc=%d",cc++);
     }
     */

    in = 0;
    registers[PC].word = 0xf000;
    pushpopdepth = 0;
    pushpoprdepth = 0;

    if (load_standard) {
        char img[4096];                                  /* YACC1-D 2026-09-20: images found relative to the executable */
        exe_relative(img, sizeof img, "../../firmware/basic/basic.img", argv[0]);   load_file(img);
        exe_relative(img, sizeof img, "../../firmware/monitor/monitor.img", argv[0]); load_file(img);
    }
    if (load_filename) {
        load_file(load_filename);
    }
    if (!exit_on_halt) dump(0xf700, 0xf7ff);
    fflush(stdout);

    while (1) {

        ins = memory_read(register_read_word(PC));
        icount++;
        if (pcfile) pchist[register_read_word(PC)]++;
        if (stackwatch) {
            unsigned sp = register_read_word(1), pc = register_read_word(PC);
            if (pc >= 0x5000 && pc < 0xD000) slast = icount;
            if (sstart && sp >= 0x5000 && sp < 0xD000 && sp < smin) smin = sp;
        }
        if (ilimit && icount > ilimit) {
            fflush(stdout);
            fprintf(stderr, "instruction limit reached at %04x after %lu instructions, R3=%04x\n", registers[PC].word, icount - 1, register_read_word(3));
            exit(0);
        }

        // trigger condition, for instance test PC value or a reg value
        if (registers[PC].word == 0x0000) {
            debug_mode(SINGLESTEP);
        }


        if (stepmode != 0) {
            if (stepmode == SINGLESTEP) {
                for (int t = 3; t < jsrdepth; t++)
                    printf("->");
                printf("singlestep [%02x] at [%04x] acc=[%02x] tmp=[%02x] R3=[%04x] R7=[%04x]\n", ins, registers[PC].word, acc, treg, register_read_word(3), register_read_word(7));
                debug_mode(SINGLESTEP);
            }

            if ((stepmode == JUMPOVER) && (jsrover <= jsrdepth)) {
                for (int t = 3; t < jsrdepth; t++)
                    printf("->");
                printf("singlestep [%02x] at [%04x] acc=[%02x] R3=[%04x] R7=[%04x]\n", ins, registers[PC].word, acc, register_read_word(3), register_read_word(7));
                debug_mode(SINGLESTEP);
            }
        }

        if ((register_read_word(PC) >= 0xe000) && (register_read_word(PC) <= 0xEFFF)) {
            for (int t = 3; t < jsrdepth; t++)
                DEBUG_PRINTF("->");
            DEBUG_PRINTF("Process opcode [%02x] at [%04x] acc=[%02x] R3=[%04x] R7=[%04x]\n", ins, registers[PC].word, acc, register_read_word(3), register_read_word(7));
        }

        register_inc(PC);
        switch (ins) {
            case START:
                badOpcode(ins);
                break;

            case ON:
                out_on();
                break;

            case OFF:
                out_off();
                break;

            case HALT:
                if (exit_on_halt) {
                    fflush(stdout);
                    fprintf(stderr, "HALT at %04x after %lu instructions, R3=%04x\n", registers[PC].word - 1, icount, register_read_word(3));
                    exit(0);
                }
                printf("\nHalt[%02x] at [%04x] acc=[%02x] tmp=[%02x] R3=[%04x] R7=[%04x]\n", ins, registers[PC].word - 1, acc, treg, register_read_word(3), register_read_word(7));
                dump(0x0200, 0x021f);
                dump(0x0f80, 0x0f8f);
                dump(0x0400, 0x040F);
                dump(0x1000, 0x1020);
                debug_mode(DEBUG_HALT);
                break;

            case JSR:
                jsrdepth++;
                hi = memory_read(register_read_word(PC));
                register_inc(PC);
                lo = memory_read(register_read_word(PC));
                register_inc(PC);

                DEBUG_PRINTF("JSR pc=%04x sp=%04x jsrd=%d %02x%02x\n", (register_read_word(PC) - 3), register_read_word(SP), jsrdepth, hi, lo);
                //dump(0xdump0200, 0x020f);
                memory_write(register_read_word(SP), register_read_hi(PC));
                register_dec(SP);
                memory_write(register_read_word(SP), register_read_lo(PC));
                register_dec(SP);

                register_write_hi(PC, hi);
                register_write_lo(PC, lo);

                //printf("jsr opcode pc[%04x]\n", registers[PC].word);
                break;

            case RET:
                jsrdepth--;
                DEBUG_PRINTF("RET pc=%04x sp=%04x jsrd=%d ", (register_read_word(PC) - 1), register_read_word(SP), jsrdepth);
                //dump(0x0200, 0x020f);
                register_inc(SP);
                register_write_lo(PC, memory_read(register_read_word(SP)));
                register_inc(SP);
                register_write_hi(PC, memory_read(register_read_word(SP)));


                DEBUG_PRINTF(" return to %02x%02x\n", register_read_hi(PC), register_read_lo(PC));

                break;

            case JSRUR:
                jsrdepth++;
                reg = memory_read(register_read_word(PC)) & 0x07;
                register_inc(PC);

                DEBUG_PRINTF("JSR pc=%04x sp=%04x jsrd=%d %02x%02x\n", (register_read_word(PC) - 3), register_read_word(SP), jsrdepth, hi, lo);
                //dump(0xdump0200, 0x020f);
                memory_write(register_read_word(SP), register_read_hi(PC));
                register_dec(SP);
                memory_write(register_read_word(SP), register_read_lo(PC));
                register_dec(SP);

                /* YACC1-D 2026-09-22: PC <- Rn (the bytes were swapped here; the microcode copies hi to hi) */
                register_write_hi(PC, register_read_hi(reg));
                register_write_lo(PC, register_read_lo(reg));
                if (pcfile && register_read_word(PC) == 0x5000) { pc_dump(); pcseg++; }   /* -P: a new block */
                if (stackwatch && register_read_word(PC) == 0x5000) {   /* -S: Y1/OS starts a program */
                    stack_report(); sseg++; sstart = 0; smin = 0x10000; sicount = icount; slast = icount;
                }

                //printf("jsr opcode pc[%04x]\n", registers[PC].word);
                //printf("bad opcode [%02x] pc[%04x]\n", ins, register_read_word(PC));
                break;

            case PUSHR:
                reg = memory_read(register_read_word(PC)) & 0x07;
                register_inc(PC);
                //DEBUG_PRINTF("PUSHR reg=%d pc=%04x pre-sp=%04x\n", reg, (register_read_word(PC) - 1), register_read_word(SP));
                memory_write(register_read_word(SP), register_read_hi(reg));
                register_dec(SP);
                memory_write(register_read_word(SP), register_read_lo(reg));
                register_dec(SP);
                break;
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

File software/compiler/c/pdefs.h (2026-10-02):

/*
 * Author: Claude (Anthropic) for Ken Rother's YACC1 project, 2026
 */

/* pdefs.h - the numbers shared by the passes of the multi-pass y1cc (2026-09-24; software/compiler/README.md,
   "The passes"). #define lines only (y1cc's preprocessor has nothing else). The first half is y1cc.c's: token kinds,
   predefined names, operators, AST node kinds, label kinds, runtime helpers, the machine. The second half is the
   intermediate files: record codes, instruction mnemonics and operand forms, macros, holes, deferred messages. */

/* ---- token kinds (y1cc.c) -------------------------------------------------------------------------------------- */
#define T_EOF 0
#define T_NUM 1
#define T_ID 2
#define T_KW 3
#define T_STR 4
#define T_OP 5
#define T_LINE 8                /* token file only: the line of the following tokens */

/* ---- predefined names: interned first, in this order ----------------------------------------------------------- */
#define K_INT 1
#define K_CHAR 2
#define K_VOID 3
#define K_STRUCT 4
#define K_UNION 5
#define K_UNSIGNED 6
#define K_CONST 7
#define K_STATIC 8
#define K_IF 9
#define K_ELSE 10
#define K_WHILE 11
#define K_FOR 12
#define K_RETURN 13
#define K_BREAK 14
#define K_CONTINUE 15
#define K_SIZEOF 16
#define K_SWITCH 17
#define K_CASE 18
#define K_DEFAULT 19
#define KW_LAST 19
#define NM_MAIN 20
#define B_GETCHAR 21
#define B_PEEK 22
#define B_PEEKW 23
#define B_INP 24
#define B_BIOS 25
#define B_PUTCHAR 26
#define B_PUTS 27
#define B_POKE 28
#define B_POKEW 29
#define B_OUTP 30
#define B_HALT 31
#define B_CALL 32
#define B_ARGSTR 33
#define B_SYS 34
#define B_FUNCADDR 35
#define NM_PREDEF 35

/* ---- operators, in y1cc.py's PUNCT order --------------------------------------------------------------------- */
#define O_SHLEQ 1
#define O_SHREQ 2
#define O_EQ 3
#define O_NE 4
#define O_LE 5
#define O_GE 6
#define O_SHL 7
#define O_SHR 8
#define O_ANDAND 9
#define O_OROR 10
#define O_ARROW 11
#define O_INC 12
#define O_DEC 13
#define O_ADDEQ 14
#define O_SUBEQ 15
#define O_MULEQ 16
#define O_DIVEQ 17
#define O_MODEQ 18
#define O_ANDEQ 19
#define O_OREQ 20
#define O_XOREQ 21
#define O_LBRACE 22
#define O_RBRACE 23
#define O_LPAREN 24
#define O_RPAREN 25
#define O_LBRACK 26
#define O_RBRACK 27
#define O_SEMI 28
#define O_COMMA 29
#define O_ASSIGN 30
#define O_DOT 31
#define O_QUEST 32
#define O_COLON 33
#define O_PLUS 34
#define O_MINUS 35
#define O_STAR 36
#define O_SLASH 37
#define O_PERCENT 38
#define O_LT 39
#define O_GT 40
#define O_NOT 41
#define O_AMP 42
#define O_BAR 43
#define O_CARET 44
#define O_TILDE 45
#define O_LAST 45

/* ---- AST node kinds -------------------------------------------------------------------------------------------- */
#define N_NUM 1
#define N_STR 2
#define N_ID 3
#define N_UNARY 4
#define N_PREINC 5
#define N_POSTINC 6
#define N_SIZEOFT 7
#define N_SIZEOFE 8
#define N_CALL 9
#define N_INDEX 10
#define N_MEMBER 11
#define N_ARROW 12
#define N_ASSIGN 13
#define N_COND 14
#define N_LOGOR 15
#define N_LOGAND 16
#define N_BIN 17
#define N_BLOCK 20
#define N_DECL 21
#define N_IF 22
#define N_WHILE 23
#define N_FOR 24
#define N_RETURN 25
#define N_SWITCH 26
#define N_CASE 27
#define N_DEFAULT 28
#define N_BREAK 29
#define N_CONTINUE 30
#define N_EMPTY 31
#define N_EXPR 32
#define N_LABEL 33
#define N_STRUCTDEF 40
#define N_MEMBERDEF 41
#define N_PROTO 42
#define N_FUNC 43
#define N_PARAM 44
#define N_GVAR 45
#define N_INITLIST 50
#define N_INITSTR 51
#define N_INITADDR 52
#define N_INITNUM 53

/* ---- label kinds: y1cc.py's lbl() prefixes ---------------------------------------------------------------------- */
#define LK_F 1
#define LK_E 2
#define LK_T 3
#define LK_S 4
#define LK_ELSE 5
#define LK_END 6
#define LK_TOP 7
#define LK_NEXT 8
#define LK_SW 9
#define LK_C 10
#define LK_D 11
#define LK_A 12
#define LK_O 13
#define LK_Z 14
#define LK_ZG 15
#define LK_ZD 16
#define LK_STR 17

/* ---- runtime helpers (emitted in this order when used) ------------------------------------------------------ */
#define RT_SUB 0
#define RT_MUL 1
#define RT_DIVMOD 2
#define RT_SHL 3
#define RT_SHR 4
#define RT_PUTC 5
#define RT_GETC 6
#define RT_PUTS 7
#define RT_FSAVE 8
#define RT_FREST 9
#define RT_COUNT 10

/* ---- the machine ------------------------------------------------------------------------------------------------ */
#define ORG_DEFAULT 12288
#define STACK_TOP 3839
#define MONITOR_RESTART 61440
#define ARGBUF 3904
#define SYSARG 3846
#define SYSRES 3852
#define SYSTAB 3860
#define SYS_CONIN 17
#define SYS_CONOUT 19
#define SYSOLD 21               /* entries 0..21 at SYSTAB; 22..31 at SYSTAB2 = $4FC0 (2026-09-25) */
#define SYSTAB2 20416
#define SYSMAX 31
#define BIOS_CHAROUT 65476
#define BIOS_UARTIN 65512
#define LABEL_MAX 29
#define FRAME_INLINE 8
#define WORD_MAX 32             /* cc9's peephole: the first word of a line, compared with mnemonics only */
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

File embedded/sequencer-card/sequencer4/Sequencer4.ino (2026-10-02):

/*
 * Author: Ken Rother (original: Sequencer3 2021-08 + IO.ino 2024-07)
 * Changes: Claude (Anthropic), 2026 - see git history
 */

// Sequencer Memory card code - Sequencer4 (YACC1-D 2026-09-21, from Sequencer3 2021-08 + IO.ino 2024-07)
//   400 kHz I2C, block EEPROM reads (32 bytes/transaction), EEPROM page writes, no test-pattern fill on boot,
//   and the EEPROM-to-RAM copy is read back and compared before READY is raised (FAULT blinks 6 on a mismatch).
// Mode Determined by UCODESWITCH
//Mode 1 download uCode from serial line and store in EEPROM, press STARTSWITCH to begin (READY and LOADING LEDs ON)
//MODE 2 Write EEPROM into UCode RAM and set READY line high


#include <Wire.h> //I2C library
#include "Adafruit_MCP23017.h"
//#include "YACC_Common_headera.h"

/*
   Format ":AIXXXXXXXX....XXXXX"
   ":"  Start charachter
   "A" Checksum (not including instruction number) (Ignore for now)
   "I" Instruction Number (0-255)- 2 hex ascii chars
   "XXXXXXXX....XXXXX" Data Bytes -  2 hex ascii chars

  Pin 11 FAULT
  Pin 12 Bus-EN READY
  Pin 13 Loading
*/

//RAM Control Lines
#define MEMWR 8
#define MEMRD 9
#define MEMSEL 10

// LEDS
#define FAULT 11
#define READY 12
#define LOADING 13

//Swithces
#define UCODESWITCH A0
#define STARTSWITCH A2 // Default HIGH

//
#define READYLINE 7

//UCODESWITCH Modes
#define DOWNLOAD 0
#define WRITEMEM 1

int mode;
int verbose = 0;

#define LINES_PER_INSTRUCTION 64  // total number of rows of BYTES_PER_LINE
#define BYTES_PER_LINE 8         // total bytes/row (mem chips) should be 8
#define INSTRUCTION_SIZE  BYTES_PER_LINE*LINES_PER_INSTRUCTION

#define WORKING_INSTRUCTION_SET  256  // FIX shoud be 256
#define VERSION_BANNER "Sequencer4 2026-09-21 (400 kHz I2C, block EEPROM reads, verified copy)"
#define VERIFY_COPY   // read the RAM back and compare with the EEPROM before READY
#define ALL_INSTRUCTIONS 256

#define NUMBER_OF_CONTROLERS 5
#define ADDRESS_CHIP 0
#define DATA_CHIP_START 1
#define DATA_CHIPS 4

Adafruit_MCP23017 mcp[NUMBER_OF_CONTROLERS];
unsigned char insData[BYTES_PER_LINE * LINES_PER_INSTRUCTION] = {0,};

void writeCodeToROM(int, unsigned char *);

//opcode myArraySRAM;



void doError(String errorMsg, int code) { (void)errorMsg;   /* YACC1-D 2026-09-20: its print is commented out */
  ///Serial.print(F("Error: "));
  ///Serial.println(errorMsg);
  while (1) {
    for (int i = 0; i < code; i++)
      blinkLed(FAULT);
    delay(2000);
  }
}

void flashLed(int led) {
  digitalWrite(led, HIGH);
  delay(100);
  digitalWrite(led, LOW);
}

void blinkLed(int led) {
  digitalWrite(led, HIGH);
  delay(100);
  digitalWrite(led, LOW);
  delay(100);
}

/*
   Test Pattern, for each line of instruction - BYTE 0 instruction #, BYTE 1, LINE #, remaining 0s
*/
void fillTestPattern(int instruction) {
  int i, j;

  if (verbose > 0) {
    Serial.print(F("Filling Memory - "));
    Serial.println(instruction);
  }

  for (i = 0; i < LINES_PER_INSTRUCTION; i++) {
    insData[i * BYTES_PER_LINE] = instruction;
    insData[i * BYTES_PER_LINE + 1] = i;
    for (j = 2; j < BYTES_PER_LINE; j++) {
      insData[i * BYTES_PER_LINE + j] = 0;
    }
  }
  writeInstruction(instruction, insData);

}

/*
   Read instruction from RAM
*/
void dumpInstruction(int instruction) {
  int i, j;
  char tmp[20];

  Serial.print(F("Ins="));
  Serial.println(instruction);

  Serial.print(F("        "));
  for (i = 0; i < BYTES_PER_LINE; i++) {
    sprintf(tmp, "%02x ", i); Serial.print(tmp);
  }
  Serial.println();

  readInstruction(instruction, insData);
  for (j = 0; j < LINES_PER_INSTRUCTION; j++) {
    sprintf(tmp, "LINE:%02d ", j); Serial.print(tmp);
    for (i = 0; i < BYTES_PER_LINE; i++) {
      sprintf(tmp, "%02x ", insData[i + j * BYTES_PER_LINE]); Serial.print(tmp);
    }
    Serial.println();
  }
  Serial.println();

  readCodeFromROM(instruction, insData);
  for (j = 0; j < LINES_PER_INSTRUCTION; j++) {
    sprintf(tmp, "LINE:%02d ", j); Serial.print(tmp);
    for (i = 0; i < BYTES_PER_LINE; i++) {
      sprintf(tmp, "%02x ", insData[i + j * BYTES_PER_LINE]); Serial.print(tmp);
    }
    Serial.println();
  }
  Serial.println();
}

void setup() {
  int i;

  Serial.begin(115200);
  Wire.begin();

  pinMode(UCODESWITCH, INPUT);
  mode = digitalRead(UCODESWITCH);


  if (mode == WRITEMEM) {
    Serial.println(F("\n\n\n\nStartup"));
    Serial.println(F(VERSION_BANNER));
  }

  for (i = 0; i < NUMBER_OF_CONTROLERS; i++) {
    mcp[i].begin(i);
  }
  Wire.setClock(400000);   // AFTER the expanders' begin(): each Adafruit begin() calls Wire.begin(), which resets the clock to 100 kHz. EEPROM (24LC) and MCP23017s are 400 kHz parts


  pinMode(FAULT, OUTPUT);
  pinMode(READY, OUTPUT);
  pinMode(LOADING, OUTPUT);
  pinMode(READYLINE, OUTPUT);

  pinMode(MEMRD, OUTPUT);
  pinMode(MEMWR, OUTPUT);
  pinMode(MEMSEL, OUTPUT);

  digitalWrite(MEMRD, HIGH);
  digitalWrite(MEMWR, HIGH);
  digitalWrite(MEMSEL, HIGH);
  digitalWrite(READYLINE, LOW);

  pinMode(UCODESWITCH, INPUT);
  pinMode(STARTSWITCH, INPUT);

  flashLed(FAULT);
  flashLed(READY);
  flashLed(LOADING);

  if (mode == WRITEMEM)
    Serial.println(F("Startup done\n"));
}

void loop() {

  int address;
  int rawaddress;
  int line;
  int instruction;
  unsigned char data[BYTES_PER_LINE];
  unsigned int counter;
  char tmp[60];
  boolean statusLed = false;
  int i;   /* YACC1-D 2026-09-20: j unused */

  int previousLine;
  int previousInstruction;
  unsigned char previousData[8];
  unsigned char mask;
  int val;

  //bool printed=false;

  if (mode == WRITEMEM) { // LOADING on while copying, READY on when complete

    Serial.println(F("Write Memory"));
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

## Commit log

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2026-09-20 fix(disasm2): re-enable the signal-table include and declare printWave void so it builds
    Adds tools/patched_files.txt: the list of migrated sources deliberately edited in the tree,
    honoured by audit_tree.py, migrate_purge.py and migrate_run.py. Adds the yaccsignaldata2.h
    layout link.
    [main.c]
2026-09-20 test: arduino-cli compile check for every sketch (tools/verify_embedded.py)
    Vendors extEEPROM 3.4.1 for the deprecated sequencer2 sketch and moves sequencer1's
    download.ino tab beside its sketch (it was filed in a subfolder). 12 sketches compile
    against only the vendored libraries; the MCP23X17 work-in-progress is an expected failure.
    [dedup-dropped.tsv, dryrun-plan.tsv]
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2026-09-21 fix(emulator): locate the default images relative to the executable (Finder double-click works)
    [main.c]
2026-09-21 build: Makefiles for every C tool plus a top-level make/make check; all six run from a Finder double-click
    - microcode generator writes its images beside the executable; disassembler finds test.123 relative to
    itself and takes opcode arguments; uBASIC ends at end of input; assembler prints usage / a clean
    error instead of crashing (all listed in tools/patched_files.txt)
    - NetBeans-generated Makefiles kept byte-identical as Makefile.netbeans
    - migrate_purge.py never deletes a file whose bytes are no longer the migrated ones
    [dedup-dropped.tsv, dryrun-plan.tsv]
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2026-09-21 fix(embedded): zero compiler warnings in every current Arduino sketch
    All eight current sketches (bus-driver, bus-monitor, bus-test,
    led-switch-test, clocker, Sequencer3, dumpram, test-eeprom/mem) now
    compile with `arduino-cli --warnings all` and no sketch warnings;
    tools/verify_embedded.py still reports 12 sketches, 0 unexpected.
    - functions that never returned a value made void
    - return after doError() in opLookUp / waitInstructionBegin (was
    falling off the end of a non-void function)
    - (int) casts where the char-typed 'chip' field indexes the mcp[] array
    - unused locals and dead code removed; intentionally unused tables and
    parameters marked as such
    - each edited file carries a dated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
    [EEPROM.ino, IO.ino, Sequencer3.ino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]
2026-09-21 fix(embedded): command sender builds under Processing 4 with zero warnings
    The 2020 Processing sketch (command_sender_8) no longer built at all:
    - `import java.io.*` now also imports java.io.Serial (Java 14+), which
    made Processing's `Serial` ambiguous -> the wildcard import is gone
    (Processing auto-imports java.io.File)
    - the Processing 2 `frame` field was removed in Processing 3 -> the two
    JOptionPane dialogs use `null` as parent (same centred dialog)
    Warning cleanup on top of that (Eclipse compiler, cosmetic categories
    excluded): 14 unused imports removed, saveLabel's parameter renamed
    (it shadowed the global `index`), two empty `while` bodies made
    explicit, and a cancelled port di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
    [command_sender_8.pde]
2026-09-21 feat(hardware): KiCad 10 projects for every Eagle design, with netlist proofs
    tools/eagle_to_kicad_all.py converts all 37 Eagle designs under hardware/
    (active and deprecated revisions) into <item>/kicad/<rev>/ projects:
    schematic via tools/kicad/eagle_sch_to_kicad.py, board via KiCad's Eagle
    reader + tools/kicad/finish_board.py, project file from a template with
    the OSH Park rules, then netlist export, ERC, DRC, schematic PDF, top and
    bottom renders and a per-project README. hardware/KICAD.md indexes them.
    `make kicad` re-runs it. The flat memory-card pilot folder is replaced by
    the generated kicad/v1.3 (same tools, same 115/115 proof).
    Proof = schematic netlist vs the pad netlist embedded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
    [Memory V1.3.brd, Memory V1.3.sch, address-tmp-v1.0-sheet1.kicad_sch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]
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2026-09-21 feat(video): KiCad v1.1 is the design master; +5V folded into VCC
    hardware/cards/video/kicad/v1.1 is a hand-maintained KiCad 10 project
    (MASTER marker) started from the proven conversion of the built card;
    Fusion 360 is abandoned for this card (Ken, 2026-09-21).
    Design change: the built card's two 5 V nets are one. Every +5V symbol,
    label, pad and track is now VCC and a short F.Cu track beside C28 joins
    the two former copper islands. Netlist proof vs the board: MATCH
    116/116; DRC clean of clearance/short/dangling findings, 0 unconnected.
    tools/eagle_to_kicad_all.py refuses to write into a MASTER folder and
    lists masters in hardware/KICAD.md; the audit knows the folder.
    docs: video README,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
    [video-v1.1-sheet1.kicad_sch, video-v1.1-sheet2.kicad_sch, video-v1.1.kicad_pcb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]
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2026-09-21 docs(waveforms): keep the two timing diagrams as WaveJSON + SVG, drop the web archives
    GitHub secret scanning flagged a Google API key in
    docs/system/waveforms/REG-RD.webarchive. The key is Google's public
    analytics client key inside the saved wavedrom.com editor page, not a
    credential of this project. The two archives (600 KB of site JavaScript
    each) carried Ken's index-register load/read timing diagrams; those are
    now docs/system/waveforms/REG-LD/REG-RD .json (WaveJSON source) + .svg
    (rendered). The archives are skipped in the migration plan and removed.
    [dedup-dropped.tsv, dryrun-plan.tsv]
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2026-09-21 feat(sequencer): Sequencer4 - fast, verified microcode copy; sequencer3 deprecated
    embedded/sequencer-card/sequencer4 (flashed 2026-09-21, proven on the
    card): I2C at 400 kHz (set after the expanders' begin(), which resets
    it), EEPROM read in 32-byte blocks and written with page writes, the
    boot-time test-pattern fill removed, and the whole EEPROM-to-RAM copy
    read back and compared before READY (mismatch: report, FAULT x6, no
    READY). All serial literals in flash: with plain strings the ATmega
    had ~500 bytes free and crashed at boot. Measured: copy 16 s, verify
    29 s, READY at 54 s (Sequencer3: 156 s, unverified); RAM == EEPROM for
    all 256 instructions, dumps == test.hex.
    sequencer3 moved to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
    [dedup-dropped.tsv, dryrun-plan.tsv]
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2026-09-22 fix(monitor): G command calls the program (JSRUR R7) instead of the indirect BRVR R7; ROM rebuilt to burn
    The microcode's BRVR Rn is an indirect jump: branch() fetches the target word THROUGH the register the way
    BR fetches its operand through the PC (Rn += 2, then PC <- branch register); the direct form BRUR exists in
    the generator source but was never implemented. So the monitor's `G AAAA` (BRVR R7 after getaddress) jumped
    through whatever was stored at AAAA and pushed no return address. Now `JSRUR R7` + `BR cmdloop`: G calls
    the code at AAAA and the program returns with RET (help text says so).
    firmware/monitor/monitor.img + .lst and firmware/rom/shipped/rom are the rebuild (make install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
    [monitor.asm]
2026-09-22 feat(isa): BRUR Rn at $AD - direct branch to the address in a register (PC <- Rn)
    Two bytes, register number in the operand byte like JSRUR ($06). Microcode (branch.c): JSRUR's operand fetch,
    PC++ and register-to-branch-register steps (-REG-RD-HI + -HL-SWAP -> BRANCH-LD-HI, -REG-RD-LO -> BRANCH-LD-LO,
    selected through -2-BYTE-OPERAND-SEL) without the stack push, then the BR-family PC load: 20 steps. BRVR
    stays the indirect form. test.hex/test.hexz/test.123 regenerated: only record $AD differs from the image the
    sequencer EEPROM holds (cache untouched) - reload + bench check are on the backlog and in MACHINE.md.
    opcodes.h BRUR 0xAD (was OPCODE_AD), yacc1.def `BRUR Rn`, emulator PC <- Rn. tes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
    [main.c]
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2026-09-23 feat(os): Y1/OS v0.1 - file API (19 syscalls, 4 handles, write support), y1cc sys()/funcaddr(), UARTINNE ROM vector
    - os/y1os.c: SYSTAB at $0F14 (22 entries), SYSARG0..2 $0F06.., SYSRES $0F0C; OPEN/READ/GETC/CLOSE/CREATE(load,exec)/WRITE/
    PUTC/DELETE/MKDIR/RMDIR/OPENDIR/READDIR/RESOLVE/GETCWD/CHDIR/RENAME/ENTRY/CONIN/CONST; shell save/del/ren/mkdir/rmdir;
    ARGBUF 128 bytes; image 24 sectors
    - os/lib_fs.c wrappers; commands cat2, cp, ls, wc rewritten on the API; tests/os api + write sessions on both emulators
    with host-side p8xfs verification (6/6)
    - y1cc: sys(n, a, b, c), funcaddr(f); constant-fold crash on x*0 fixed; tests/compiler/syscall.c (16/16)
    - monitor: UARTINNE at $FFFC (uartin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
    [lib_abi.c, monitor.asm]
2026-09-23 feat(os): P8X commands ported, waves 0-2 (26 /BIN programs, 10 shared libraries, 50 man pages, /DOCS); vi test session; load-size fix
    - lib_glob/regex de-recursed, lib_stdin (files, globs, '-'), lib_walk (level stack, one directory handle), lib_more pager,
    lib_apath/globx/rdline/err/num; commands pwd help dep dump examine man cat wc head tail more sort uniq sed awk cmp diff
    md touch del mv tree find dir grep cp (sizes: make -C os sizes; 32K check)
    - shell runs /BIN/NAME before its built-ins (exit first); sessions api/basic/write regenerated, wave1/wave2/vi added
    (12/12 on both emulators, host-side p8xfs checks)
    - load_file checks the whole-sector length against TPATOP (was: up to 511 b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
    [lib_abi.c]
2026-09-23 feat(monitor): ':' Intel-hex loader + tools/monload.py; ROM banner carries the build date; ucemu UART status poll no longer blocks
    - monitor ':' command: records read without echo, stored in $1000-$DFFF only, read back, answered . ? !; end record
    prints LOADED / LOADED WITH ERRORS; ESC or NUL abandons anywhere (stack reset); lderr at $0F01; help line
    - banner 'YACC 2020: HELLO WORLD ROM 2026-09-23'; ROM rebuilt (not burned), FIRMWARE VERIFIED
    - tools/monload.py: paced sender (3 ms/char default, ~1,600 clocks per character measured), per-record ack, ESC on
    error, --go/--listen/--term, sequencer FTDI excluded from port choice
    - y1ucemu: LSR data-ready is a non-blocking poll (it blocked ev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
    [monitor.asm]
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2026-09-23 feat(hardware): CF card v1.0 KiCad schematic + routed board, generated from cf_netlist.py
    - gen_cf.py writes the schematic (functional groups, power symbols, no-connect flags, design notes) and the board
    (blank V3.2 outline and DIN connector, parts placed, GND pour both sides, 4 mm keepouts at the connector screws);
    build.sh routes with Freerouting, heals, fills, runs DRC/ERC, exports gerbers, placement PDF, render, BOM
    - netlist proof: the schematic's exported netlist and the board's pad nets both equal cf_netlist.py (46 nets, 171 pins)
    - DRC 0 errors, 0 unconnected (8 cosmetic silk warnings on the inherited connector footprint); ERC 0 errors
    - tools/kicad/kicad_route.py: DSN export / S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
    [yacc1-cf-card-bom.csv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]
2026-09-23 feat(os): redirection (< > >>) and pipes (|) in Y1/OS
    - y1cc --os: putchar/getchar go through the OS (CONOUT 19 / CONIN 17, R3/R4 preserved); default builds byte-identical
    - kernel: stdin/stdout redirect state; CONOUT to file or raw CHAROUT (never putchar: static-frame rule documented);
    KEYIN (20) = the real keyboard, never redirected; STDIO (21) = which of stdin/stdout is redirected (the table is full)
    - shell: up to 4 stages through /PIPE0.TMP, /PIPE1.TMP (deleted after); < > >> after the arguments; quotes protect | < >;
    prompt and shell errors always to the console (eputs); CREATE replaces a same-named file at close (sort F > F works)
    - >> appends in place when the file is the last wr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
    [lib_abi.c]
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2026-09-23 fix(kicad): readable converted schematics - overlaps 42,847 -> 3,147, nothing off the frame; CF sheet 0 overlaps
    - tools/kicad/sch_overlaps.py: calibrated readability check (text/text, text/body, text/line, off frame/title block)
    - eagle_sch_to_kicad.py: fields placed from Eagle's smashed attributes or the symbol's >NAME/>VALUE with Eagle's align,
    size and ratio, readable angles; fields Eagle never shows hidden (FABC96R shows only its pin name); pin numbers hidden
    where every Eagle pin hides them; Eagle-hidden layers dropped (the stray SpiceOrder text); labels on their own wires,
    converter labels only where KiCad needs them; rotate-then-mirror fixed for MR90/MR270 in pin_world/no-conne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
    [address-tmp-v1.0-sheet1.kicad_sch, address-tmp-v1.0-sheet2.kicad_sch, address-tmp-v1.0-sheet3.kicad_sch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]
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2026-09-24 feat(cf): move the CompactFlash ports from P8/P9 to P4/P5
    The CF interface is moving onto the I/O card (v2.0): the backplane has eight slots
    and the I/O card's own 74LS138 (IC5, strapped to P0-P7) has six unused outputs.
    Taking Y4/Y5 as the CF select and data ports drops the CF card's 74LS138: the
    interface becomes four chips. P2 was not used because it is the emulators'
    console and test-output port.
    - monitor.asm: CF driver (cfinit/cfread/cfwrite/cfwait, O boot) on P4/P5;
    banner "ROM 2026-09-23B"; monitor.img/.lst rebuilt
    - firmware/rom/shipped/rom + rom.bin rebuilt (MD5 a9fefd4a...), not yet burned;
    tools/verify_firmware.py: FIRMWARE VERIFIED
    - software/cfmodel.h: CF_PORT_SEL 4, CF_PO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
    [main.c, monitor.asm]
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2026-09-24 feat(io): I/O card v2.0 design - v1.1 plus the CF interface on P4/P5, three placement options
    The CompactFlash interface folds onto the I/O card (8-slot backplane). IC5's
    spare Y4/Y5 (-IO-SEL4/-IO-SEL5) replace the CF card's 74LS138, so the CF section
    is IC12 74LS32, IC13 74LS175, IC14 74LS08, IC15 74LS245, J2 40-pin IDE header,
    J3 adapter power, JP2 pin-20 jumper, pull-ups, ACT LED (LED1), decoupling C18-C22.
    Dropped: the CF card's 138, bus connector, DASP and PWR LEDs.
    - schematic: v1.1 sheets 1-6 unchanged except -IO-SEL4/5 made global labels and
    a strap note on sheet 5; sheet 7 = the CF section
    - netlist proof (check_netlist.py via build.sh): v2.0 = v1.1 + CF section pin for
    pin, 90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
    [io-v2.0-bom.csv, io-v2.0-option-a.kicad_pcb, io-v2.0-option-b.kicad_pcb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]
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2026-09-24 feat(io): route I/O card v2.0 (option B)
    Ken chose placement option B (2026-09-23). io-v2.0.kicad_pcb is the routed
    2-layer board made from options/io-v2.0-option-b.kicad_pcb by route_v2.py
    (ROUTE=1 build.sh).
    - Routing: 0 unrouted. v1.1's rules: 0.1524 mm tracks, 0.127 mm clearance,
    0.508/0.254 mm vias. New GND/VCC tracks are 0.3048 mm (Power net class).
    All 900 v1.1 track segments and vias that option B kept are intact and
    locked (route_check.py). Added: 2166 segments (B.Cu 1150, F.Cu 1016) and
    310 vias. The whole board has 2988 segments and 388 vias.
    - Flow: Freerouting stage A routes the 49 signal nets with a broken v1.1
    connection alone. Stage B routes the rest. A new grid ma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
    [io-v2.0-B_Cu.gbr, io-v2.0-B_Mask.gbr, io-v2.0-B_Silkscreen.gbr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]
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2026-09-24 revert(io): remove the I/O card v2.0 design (CF interface on the I/O card)
    Ken's new plan (2026-09-24): the CompactFlash interface goes onto the memory card,
    which has more room, instead of the I/O card. The whole v2.0 design folder
    (schematic, three placement options, routed option B, fab outputs, scripts) is
    removed; git history keeps it (919c0e9, 66169be). audit_tree and the KICAD.md
    masters list no longer name it. Docs follow in a separate commit.
    [io-v2.0-bom.csv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]
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2026-09-24 revert(cf): CompactFlash back on ports P8/P9 - the ROM in the machine is current again
    The P4/P5 move (24378cb) only made sense with the CF interface on the I/O card v2.0,
    whose decoder had spare outputs; that plan is dropped (6eeb259). The CF interface
    goes onto the memory card instead, kept I/O-mapped, with the CF card v1.0 decode
    (own 74LS138, enabled by IO-ADDR3 = the upper port half) unchanged.
    - monitor.asm/.img/.lst, shipped/rom + rom.bin, cfmodel.h, emulator/ucemu comments
    restored from before 24378cb: rom.bin MD5 d2d7b027... = the chip burned
    2026-09-23, so no reburn; verify_firmware: FIRMWARE VERIFIED
    - tests: os 20/20, ucemu 19/19, bench (offline), monload, cfcard all pass
    -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
    [main.c, monitor.asm]
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2026-09-24 feat(memory): rebuild memory card v2.0 on the built card - CF section does not fit, placement blocked
    hardware/cards/memory/kicad/v2.0 is now generated from ../v1.3-fusion-export-2026-09-24 (the built
    card) instead of the earlier save: v2.0 = built card + the CF section (CF card v1.0 circuit on P8/P9,
    IC30-IC34, J2/J3/JP2, RN9, R10-R14, LED1, C25-C30), IC15 included with its real wiring. Netlist proof
    MATCH pin for pin (74 parts, 186 nets; every option board = the schematic); ERC 99 = the built
    card's 104 + SRST - the six labels made global.
    The built card's copper is locked: gen_mem_v2.py no longer trims or drops copper, it refuses moves
    that would break a track, and "locked" proves all 13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
    [memory-v2.0-bom.csv, memory-v2.0-option-a.kicad_pcb, memory-v2.0-option-b.kicad_pcb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]
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2026-09-24 feat(memory): re-lay the whole memory card v2.0 with the CF section designed in - three options, all trial-routed
    Ken's decision (2026-09-24): keep the circuit (the v2.0 netlist: built v1.3 incl.
    IC15 + the CF section on P8/P9), discard the built card's placement and copper.
    Kept: outline, X1 (position, orientation, mounting holes), 4-layer stack-up with
    the In1 GND / In2 VCC planes. Signals on F.Cu/B.Cu, power pins on the planes
    through thermal reliefs; rules 0.25 mm tracks, 0.2 mm clearance, 0.8/0.4 mm vias
    (project net classes + .kicad_dru).
    - relayout_placements.py: options A (built topology re-flowed, J2 lower half),
    B (TMP registers at the bus connector, CF column, J2 centred, PWR L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
    [memory-v2.0-option-a.kicad_pcb, memory-v2.0-option-b.kicad_pcb, memory-v2.0-option-c.kicad_pcb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]
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2026-09-24 feat(memory): finish memory card v2.0 option B for fabrication - routed, silk tidied, fab files (not ordered)
    Ken picked re-layout option B (2026-09-24). memory-v2.0.kicad_pcb is the final
    board, made by finish_v2.py make from option B's committed trial route
    (FROM=trial build.sh remakes it). Eight fresh Freerouting runs of the same
    placement came out worse (61 vias, 11,887 mm, 1 unrouted), so the trial
    route is the base.
    - Routing: 0 unrouted, 43 vias, 1,794 segments / 11,779 mm of 0.25 mm
    track (F.Cu 6,858, B.Cu 4,921). The session import had marked every via
    "buried"; they are through vias now (gen_relayout.py ses fixes it on
    import too). Clean-up: no via could be removed (each run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
    [memory-v2.0-B_Cu.gbr, memory-v2.0-B_Mask.gbr, memory-v2.0-B_Silkscreen.gbr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]
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2026-09-24 feat(isa): LDZ/STZ Rn,d (page register R6), ADDIW Rn,#w and SHL16 Rn in the 32 opcodes that had no microcode
    LDZ Rn,d ($80-$87) / STZ Rn,d ($88-$8F), 2 bytes: the big-endian word at (R6.hi : d). The microcode builds the
    operand address in IR (R2) as LDR/STR do - IR.hi from R6's high byte (a register-to-register move on the high lane:
    R6 on card 1 read with -REG-RD-HI, IR on card 0 loaded with REG-LD-HI, the byte on DATA8..15, no swap), IR.lo from
    the offset byte - then runs LDR's/STR's own second halves (now shared functions; $E8-$F7 byte-identical).
    ADDIW Rn,#w ($C0-$C7), 3 bytes, w big-endian: w.hi fetched into TMP1 (microcode scratch), Rn.lo + w.lo like ADDI,
    Rn.hi + TMP1 + carry like ADD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
    [main.c]
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2026-09-24 feat(y1cc): --xisa - LDZ/STZ through a 256-byte variable page (R6), ADDIW, SHL16; default output unchanged
    Opt-in in y1cc.py, its C twin y1cc.c and the pass chain cc1..cc9 (the same output from all three). The hottest
    2-byte BSS variables (uninitialised globals, parameters, locals; a recursive function's whole frame as one unit)
    go into a page at the start of the BSS, aligned by `zpad: DS (256-(zpad).0)&255` before bss_start (so main's BSS
    clear skips the padding), and are loaded/stored with LDZ/STZ Rn,(label).0. Placement: weight = how often the
    variables are named in the live bodies (the AST's ids, resolved as vinfo), densest first while they fit. R6 is the
    page register: main and every fu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
    [pdefs.h]
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2026-09-25 feat(memory): v2.0 standoff options - HX-2118P CF adapter on M3 standoffs, J2 parallel to X1, 1:1 check prints
    Ken's decision (2026-09-24): the CF-to-IDE adapter (HX-2118P, measured: 60 x 44 mm, two M3 holes
    52.0 mm apart 15.3 mm from the header edge, no pin 20, power by pads) mounts flat on two M3
    standoffs on the memory card; J2 runs parallel to X1 about 1/3 in, beside the adapter's header
    edge, a short straight ribbon pin 1 to pin 1 (J2 at rotation 180: pin 1 at the adapter's pin-1
    end). The ROM IC13 stays removable: vertical at the free top edge, 10 mm clear past both short
    ends, 44.8 mm from the adapter.
    - standoff_placements.py / gen_standoff.py: options A (adapter centred) and B (ada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
    [memory-v2.0-B_Cu.gbr, memory-v2.0-B_Mask.gbr, memory-v2.0-B_Silkscreen.gbr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]
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2026-09-25 feat(os): SYSTAB2 - a 32-entry syscall table at $4FC0; entries 0..21 stay at SYSTAB
    SYSTAB ($0F14, 22 entries, ARGBUF right after it) cannot grow without breaking every compiled
    program. Both kernels now fill SYSTAB2 ($4FC0-$4FFF, 32 entries, 0 = unused) and copy its
    first 22 words to SYSTAB. y1cc.py, y1cc.c and the passes take sys() numbers 0..31: a constant
    0..21 still reads SYSTAB (output unchanged: diffcheck 138 identical), 22..31 read SYSTAB2.
    Tests: tests/compiler/syscall2.c (both tables), sysbig.c (the 0..31 error),
    tests/os/systab.session (both kernels, both emulators).
    [lib_abi.c, pdefs.h]
2026-09-25 feat(os): EXIT, EXEC and SEEK; /BIN/CC runs the nine compiler passes as one chained command
    Both kernels: EXIT(status) ends a program from any depth and any stack (the shell's SP is kept
    around the call: rp_call in asm, a 15-byte machine-code stub in y1os.c) and leaves STATUS
    ($0F0E) for the next program; EXEC(path, args) checks the program loads, ends the caller and
    runs path in the same shell command (> and pipes stay); SEEK(handle, hi, lo) positions a read
    handle (24 bits). All three in SYSTAB2 (22-24); lib_fs.c osexit/osexec/fseek.
    The compiler: target_io.c EXECs the next pass (io_next_pass in target/NAME.c) and EXITs on an
    error (message on the screen); target_inc.c gives the lexer a st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
    [lib_abi.c]
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2026-09-25 fix(y1cc): a comment that goes on from a directive's line is skipped, not lexed
    A preprocessor line ended at its newline, so a /* */ comment starting on a
    #define or #include line and going on over the next lines left those lines
    to be lexed as code (os/lib_abi.c: '$' was a "bad character"; the comment
    had been moved above the #defines). Now, in y1cc.py, y1cc.c and the lexer
    pass cc1 alike, a directive's /* */ comment is one space and may go on over
    newlines (the directive then ends at the newline after it), a // comment
    ends the directive, and neither counts inside quotes; the line numbers
    after it stay right (lx_blockcomment returns the newlines it passed).
    Tests: tests/compiler/dircommen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
    [lib_abi.c]
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2026-09-25 feat(video): ROM video unit - $D000 probe, screen driver, V command, console mirroring (off); emulator card model; /BIN/VIDEO
    ROM 2026-09-25 (firmware/rom/shipped, NOT BURNED; rom.bin MD5 3ebc67898f70d319853fe42abdfd2cb9):
    - reset probes $D000 ($55/$AA written and read back, the old byte restored) -> VIDPRES $0FF0,
    banner line VIDEO CARD FOUND; VIDAUTO EQU 0: reset never starts the card (1 = V I + mirroring)
    - screen driver (80 x 24 from $D000, EQUs VIDRAM/VIDSIZE/VCOLS/VROWS, CRTC VCRTCA/VCRTCD =
    $D800/$D802): CR, LF, BS, TAB, FF, wrap, 8-bytes-a-pass scroll, CRTC cursor R14/R15 (VIDCUR);
    2021 instruction set only, no R2
    - CHAROUT/UARTOUT mirror to the screen while VIDMIR ($0FF1) is s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
    [lib_abi.c, main.c, monitor.asm]
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
